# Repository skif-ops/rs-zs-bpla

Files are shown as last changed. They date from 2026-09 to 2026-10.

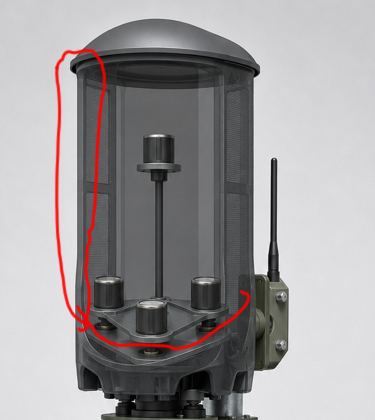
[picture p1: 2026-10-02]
releases/evt-pre-20/2026-10-02-rev-d5/Сборка_и_корпуса/03_Корпуса_для_3D_печати_ПРЕДВАРИТЕЛЬНО/Эталон_микрофонного_блока_Рисунок11.png

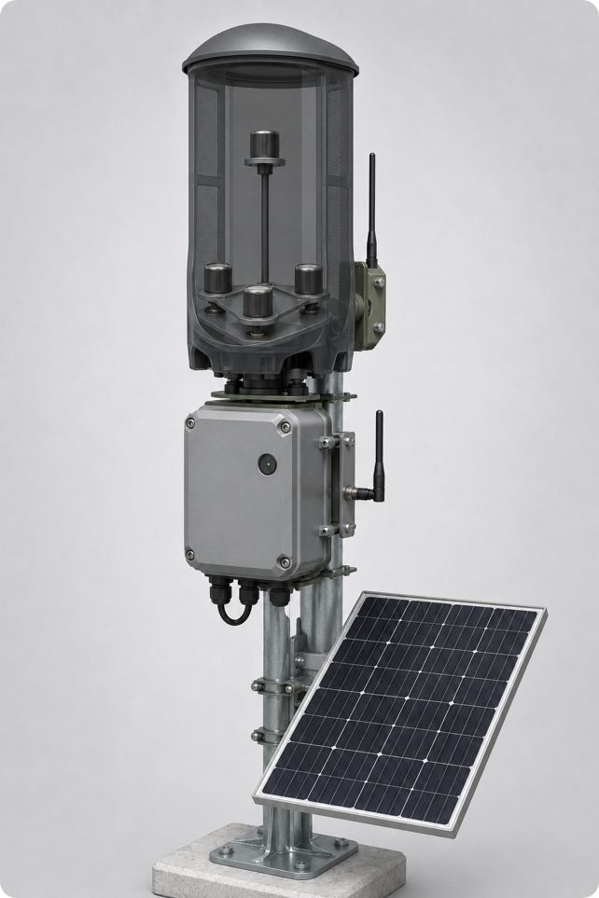
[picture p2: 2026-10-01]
releases/evt-pre-20/2026-10-02-rev-d5/Сборка_и_корпуса/03_Корпуса_для_3D_печати_ПРЕДВАРИТЕЛЬНО/Эталон_утвержденного_внешнего_вида.png

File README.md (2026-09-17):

# Дионея / РС ЗС-БПЛА

Репозиторий распределённой акустической системы обнаружения БПЛА. Серверное ПО
называется «Мухоед».

## Текущий интеграционный baseline

Версия: `DIONEA-INTEGRATION-v0.14`, дата среза 17.09.2026.

- рабочая архитектура: гибридная станция и сервер;
- акустическая геометрия: четыре одинаковых микрофона, схема 3+1, база 120 мм,
  верхний микрофон +150 мм;
- протокол: редакция 1.4 с совместимой wire schema 3 и расширением телеметрии питания;
- сервер «Мухоед»: развёртывание на Windows 11 или Ubuntu 24.04;
- EVT-MB v1.3: одна станция на WeAct STM32U585CIU6 и паяной плате 70 × 90 мм;
- EVT-PRE-20 Rev.A: 20 станций на собственных PCB с `STM32U585VIT6Q` и
  аккумулятором-кандидатом RB40 40 А·ч;
- LoRa пилота: только RU868; UWB оставлен для перспективного развития;
- PCB-PWR: 12-контактный межплатный интерфейс и полноценный INA226 по I²C;
- RF-вывод: внешняя SMA bulkhead и внутренний U.FL–SMA пигтейл Taoglas `CAB.0243`;
- корпус пилотной партии: вакуумное литьё как основной вариант, 3D-печать как резерв;
- аппаратные результаты остаются `OPEN / NOT RUN` до сборки и сохранения первичных измерений.

## Текущая готовность

| Область | Подтверждённый статус |
|---|---|
| EVT-MB v1.3 | Документы, host/структурные проверки и программная часть подготовлены; аппаратный стенд не испытан |
| EVT-PRE-20 | Контрольный source commit `7ed5b021b1e7`; конфигурация и воспроизводимые проверки актуальны |
| PCB-MAIN | Десятистраничная hierarchy принята только на уровне `ACCEPT_HIERARCHY_ONLY`; routing, Review B и выпуск в изготовление открыты |
| PCB-PWR | Активный F1 `0451008.MRL`; value-only ECO и commit-bound ERC/PDF evidence прошли, независимый post-ECO hierarchy review открыт; qualification 1/20; `DIM-003` — 0/18, stackup/copper — 0/24 и 0/2 фабрик |
| PCB-MIC | Copper-return subgate принят; общий Review B, CAM/DFM и manufacturing release открыты |
| «Мухоед» | Последний диагностический replay: 3/3 обнаружения и 15/15 положительных окон; operational type — UNKNOWN |
| Производственный BOM | 295 engineering-строк и 124 procurement-строки; QG-1 `PASS`, QG-2 `BLOCKED` |

## Ветки

| Ветка | Назначение |
|---|---|
| `main` | Проверенный стабильный интеграционный срез |
| `develop` | Интеграционная база, продвигаемая в `main` после CI без изменения дерева |
| `evt` | Материалы полноценного EVT без макетной специфики |
| `evt-mb` | Макетный EVT на паяной станции STM32U585CIU6 |
| `evt-pre-20` | Предсерийный EVT 20 станций на собственных PCB |

`evt-mb` и `evt-pre-20` остаются изолированными поставочными линиями. Их release/evidence
нельзя переносить друг в друга. В `main` и `develop` они представлены раздельными
каталогами и единым статусным реестром.

Подробные правила: [BRANCHING.md](BRANCHING.md). Текущий состав выпусков:
[releases/RELEASE_INDEX.md](releases/RELEASE_INDEX.md).

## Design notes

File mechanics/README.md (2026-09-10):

# EVT-PRE-20 - механический трек

Статус: `ARCHITECTURE DRAFT / CAD NOT RELEASED`

Механика разделена на общую акустическую геометрию и три независимых технологических комплекта:

1. `3d_print` - корпус и оснастка для печати на FlashForge Adventurer 5M Pro.
2. `vacuum_casting` - малосерийное литьё полиуретана в силиконовые формы.
3. `injection_molding` - отдельная конструкция под ТПА и промышленную пресс-форму.

Распределение пилотной партии зафиксировано: основной расчёт и изготовление 20 корпусов выполняются по технологии `vacuum_casting`. Если поставщик не сможет выполнить вакуумное литьё в требуемый срок или с требуемым качеством, после утверждения изменения вся партия переводится на `3d_print`. Для `injection_molding` готовится полный независимый комплект исходных данных и DFM, но пресс-форма и физические пилотные корпуса не заказываются без отдельного решения.

Все три технологических комплекта остаются обязательными поставочными результатами и не объединяются в одну CAD-модель. Для каждого выпускаются собственные part number, CAD, чертежи, BOM, материал и технологические допуски.

STL/STEP прежнего EVT-MB не являются корпусом предсерии: они рассчитаны на старую электронику и батарею 12 Ah. Разрешено повторно использовать только подтверждённую геометрию акустической головы 120 мм / +150 мм.

## Общая компоновка

- верхний акустический/электронный модуль: четыре mic leaf, PCB-MAIN, антенны, service cover;
- capture-allocation PCB-MAIN: 110 x 75 x 1,6 мм, четыре NPTH и 110 x 75 x 12 мм unmated PCBA envelope по `hardware/PCB_MAIN_MECHANICAL_PLACEMENT_AUTHORITY_REV_A.csv`; native STEP и полная сборочная проверка ещё не выполнены;
- отдельный нижний силовой модуль: батарея 40-60 Ah, BMS, MPPT и PCB-PWR;
- панель 60-80 W устанавливается отдельным кронштейном;
- кабель между модулями съёмный, поляризованный, защищённый предохранителем;
- электроника и батарея не делят негерметичный объём;
- наружные материалы UV-stable, негигроскопичные и не ухудшают RF без проверки.

## Общие требования

- IP65 minimum, IP67 target после испытаний;
- раздельные cellular, GNSS и LoRa антенны с контролем расстояния и кабельных потерь;
- акустические мембраны выбираются только после измерения АЧХ/фазы четырёх каналов;
- drainage и pressure-equalization vent не направляются на PCB/микрофон;
- все сервисные операции возможны без повреждения уплотнения и акустической базы;
- serial, HW revision, LoRa region и QR читаются после монтажа;
- long side изделия не более 500 мм, окончательная компоновка после component freeze.

## Release gate

Ни один корпус не выпускается в производство до заполнения `common/OPEN_DIMENSIONS.csv`, проверки полной сборки STEP, tolerance stack, thermal/RF review, пробной сборки, падения/вибрации и IP test. Каждый технологический вариант получает собственный part number, drawing, BOM и отчёт DFM.

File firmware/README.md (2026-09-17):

# ЗС-БПЛА firmware, EVT-PRE-20

Текущий каталог содержит переносимое C11-ядро: типы событий, compact CBOR, DSP, архивирование, state machines BG95/LoRa, GNSS parsing и host-тесты.

Целевой контроллер предсерии: `STM32U585VIT6Q`, LQFP100. Упоминания STM32U585ZI и платы WeAct относятся к предыдущим этапам и не являются target EVT-PRE-20.

## Что уже проверяется

```sh
cmake -S firmware -B firmware/build -DCMAKE_BUILD_TYPE=Release
cmake --build firmware/build --parallel
ctest --test-dir firmware/build --output-on-failure
```

Host PASS не означает готовую прошивку изделия.

## Что отсутствует до target build

- открытие, проверка и регенерация подготовленного STM32CubeMX `.ioc` версией 6.12.0;
- production linker с secure boot/A/B и HAL/LL bindings;
- драйвер PDM/MDF для четырёх T5838 на фактической плате;
- аппаратное и end-to-end подтверждение BG95 TLS/MQTT, защищённый downstream и provisioning;
- два валидированных региональных LoRa-профиля;
- secure boot, A/B OTA, rollback и подписанный release;
- измерение памяти, CPU, тока и времени на target.

До закрытия этих пунктов статус firmware: `TARGET_PORT_REQUIRED / OPEN / NOT RUN`. BIN/HEX из host-сборки запрещено маркировать как прошивку станции.

Host-контракт BG95 теперь покрывает автоматическое чтение SIM/оператора,
выбор APN через ответ сети или разрешённый PLMN-каталог, обязательное чтение
APN/IP/шлюза/DNS активного PDP и последовательность TLS/MQTT с fail-closed
обработкой ошибок. Полные IMSI/ICCID удерживаются только в оперативном состоянии
и включаются в отдельный heartbeat, разрешённый только через взаимный TLS;
общий server API маскирует их. Границы и отложенные до сборки станций
аппаратные доказательства зафиксированы в `BG95_MQTT_TLS_CONTRACT_REV_A.md`;
это не снимает общий `TARGET_PORT_REQUIRED` и не является сетевым EVT PASS.

Portable dual-SIM controller теперь отделяет проверяемую host-политику от
будущего target GPIO binding. Он принимает слот только после 20 ms DET debounce,
ограничивает профиль тремя попытками и 900-second hold, требует authenticated
manual assertion и audit intent/commit. При активном переключении новый слот не
может быть выбран до остановки трафика, сохранения очереди, штатного выключения
BG95, подтверждения mux High-Z и отключения modem rail. После включения
обязательны стабильный `PWR_GOOD` не менее 30 ms, 700 ms PWRKEY, полное совпадение
provisioned ICCID и attach/DNS/TLS до resume прежних event IDs. Любая ошибка,
brownout или debounced removal переводит controller в safe-off request. Это
host QG-1/QG-2, а не доказательство GPIO, реальных SIM, 100 циклов, операторов
или 24-часовой работы станции.

Safe-off request теперь сам является явной неразрывной последовательностью:
target сначала запрашивает graceful shutdown, а при его недоступности и
`CELL_STATUS=HIGH` выдаёт fallback PWRKEY 1000 ms
(внутри разрешённого аппаратного окна 650–1500 ms), подтвердить status LOW,
отключить mux, подтвердить High-Z и только затем снять modem rail. Ошибка любого
recovery action не переводит controller дальше и не допускает преждевременный
выбор слота.

Узкий portable bridge теперь связывает modem-dependent actions с BG95:
`AT+QPOWD` не считается завершённым без внешнего `CELL_STATUS=LOW`, после чего
volatile IMSI/ICCID очищаются; повторный power-on разрешён только из `OFF`.
Обратный путь требует штатного 700 ms PWRKEY, `CELL_STATUS=HIGH`, полного ICCID
из runtime автоматического network discovery и действительного online MQTT/TLS
с APN/IP/gateway/DNS read-back. Busy UART не позволяет перескочить shutdown.
Источник физического CELL_STATUS и прочие GPIO по-прежнему относятся к target.

Для EVT-PRE-20 добавлен host-compiled target GPIO contract: generated pin IDs
однозначно связывают PWRKEY/STATUS/mux/DET/PWR_GOOD/EN_MODEM с PD11, PD13, PE0,
PE2, PE3, PE5, PD0 и PD4. Адаптер проверяет полярности и запрещает rail-off до
`CELL_STATUS=LOW` и отключённого mux, а mux/PWRKEY — до непрерывных 30 ms
`PWR_GOOD`. При этом PD0 означает системный 3.3-V PG, не измерение 3V8_MODEM.
`U13_EN_N` не заведён на MCU, поэтому host различает logical command read-back
и physical fixture read-back; STM32 HAL, оснастка и измерение 3V8 остаются
target/EVT blockers.

BG95 link gate также теперь сверяет реально выбранный longest-prefix public-APN
catalog index с `pending_profile` dual-SIM controller. Поэтому даже online
MQTT/TLS с полным ICCID и валидным APN/IP/gateway/DNS не завершает switch через
другой индекс профиля. Содержимое production-каталога и durable audit backend
остаются provisioning/target blockers.

Portable store-and-forward теперь дополнен серверным application receipt:
сервер после durable processing публикует canonical CBOR с SHA-256 точного
detection payload, а fixed-memory firmware parser проверяет topic, QoS/retain и
полную identity события до маркировки outbox slot доставленным. Portable uplink
adapter сохраняет retry marker до выдачи exact `up` topic/payload и не считает
PUBACK разрешением на удаление. BG95 uplink binding использует fixed-length
`QMTPUB`: после `>` пишет ровно заявленное число binary CBOR bytes и оставляет
event pending даже после `+QMTPUB` success. Базовая BG95 state machine до
`QMTOPEN` включает direct `QMTRECV` с обязательной длиной; receipt binding после
connect проверяет этот флаг, подписывается на exact receipt topic с QoS 1 и
разбирает полный URC по byte count, сохраняя NUL/quote/CRLF/`0x1a`. Сам URC не
содержит retain-флаг, поэтому путь разрешается только явным внешним контрактом
station credential + server-only ACL + запрет retained receipt. Host QG не
заменяет target USART/DMA/ISR wiring, проверку broker policy/версии BG95 и аппаратный
recovery test.

Portable BG95 command binding использует тот же общий length-delimited parser:
после exact QoS-1 `down` subscription он передаёт только полный binary payload в
signature/journal/executor channel. Fixed-length `ack` `QMTPUB` начинается лишь
после durable `COMPLETED`; при reconnect повторная server command восстанавливает
ACK из journal без повторного side effect. Partial UART, timeout и mismatched
URC инвалидируют modem transport. Общая portable MQTT session принимает
произвольно фрагментированный raw UART, собирает line/prompt/length-delimited
URC в лимите 2304 bytes, сериализует command/receipt subscriptions, event
publish и command ACK единым TX owner. Один command frame буферизуется во время
занятого TX, следующие учитываются как требующие server retry; disconnect
очищает RAM queue и запускает ordered resubscribe. Retain в `QMTRECV` не виден и покрывается только явно подтверждённым
server-only/non-retained ACL contract. Target crypto, exact slot counts/OCTOSPI/endurance, USART/DMA/ISR,
broker policy и hardware evidence остаются открыты.

Command journal теперь имеет отдельный portable NOR adapter: каждый 88-byte
accepted/completed record занимает собственный physical erase block, callbacks
не могут выйти за логический slot, а torn commit повторно используется без
стирания соседнего record. Host QG проверяет restart roundtrip, commit-write
failure, alignment/range и erase isolation. Общий layout/bind ниже также
доказывает непересечение journal с archive и outbox. Production slot count,
OCTOSPI binding и endurance всё ещё не определены.

Portable NOR adapter выделяет каждому outbox slot отдельный erase block и
проверяет alignment/range partition, поэтому reclaim не стирает соседнее pending
event. Перед выдачей любого storage interface общий bind fail-closed проверяет
точный W25Q512JV JEDEC ID `EF 40 20`, SFDP/BFPT ёмкость 64 MiB, 4-byte geometry
и Status Register-2 QE; сброшенный QE восстанавливается с read-back. Portable
layout planner вычисляет непересекающиеся разделы: audio archive
занимает выровненный префикс NOR, за ним расположен erase-isolated command
journal, а outbox занимает хвост. Для контрольной геометрии 64 MiB / 4 KiB / 16
command slots / 256 event slots host QG проверяет 62.9375 MiB archive + 64 KiB
journal + 1 MiB outbox. Единый bind API создаёт все три adapter-а из одного
layout и ограничивает видимую archive storage точно началом journal, поэтому
независимая ошибочная инициализация диапазонов fail-closed. Точные числа слотов,
OCTOSPI HAL и endurance ещё должны быть утверждены в target memory map и
измерены на плате; host probe не заменяет проверку реального sample.

Первый target-инкремент уже фиксирует точный исходный контракт
`STM32U585VIT6Q/LQFP100`: 67 назначений из Rev.A pin map и AAD addendum,
запрет внешнего HSE, 32.768 kHz reference и пять ещё не измеренных runtime
profiles. Контракт генерируется воспроизводимо и проходит два независимых
контроля.

Второй target-инкремент закрепляет STM32CubeU5 v1.9.0 и его CMSIS-U5 commit,
добавляет официальный GCC startup/system и инженерный linker для 2 MiB flash,
768 KiB SRAM1-3 и 16 KiB SRAM4. Этот linker предназначен только для первичного
запуска без TrustZone; он не заменяет production-разметку secure boot/A/B и не
снимает общий `TARGET_PORT_REQUIRED`.

Третий target-инкремент формирует воспроизводимый pinout `.ioc` для
STM32CubeMX 6.12.0 / DB.6.0.120. В нём сохранены 67 назначений, включая
отдельные fail-closed `LORA_TXEN`/`LORA_RXEN`, и устранён
конфликт EXTI8: `LORA_DIO1` перенесён на `PC2/EXTI2`, а `MIC_WAKE` оставлен на
`PA8/EXTI8`. До открытия и регенерации в зафиксированной версии CubeMX файл не
считается подтверждённым target build.

Portable слой хранения installation position реализует атомарное чередование
двух слотов, CRC32, commit-marker, read-back, monotonic version и обязательные
physical-service/authenticated-role gates. Host QG не закрывает привязку этих
слотов к страницам STM32 Flash, ресурс перезаписи и power-loss fault injection
на фактической плате.

Portable слой commissioning принимает изменение installation position только
из локального BLE-origin после BLE Secure Connections, проверки peer identity
и физического сервисного окна не более 10 минут. Обычная installer-роль может
использовать только locked policy defaults; нестандартная trust policy требует
engineer-роли. Станция сама вычисляет канонический SHA-256, требует audit intent
до записи и audit committed после read-back. Это ещё не nRF52840/GATT binding:
UUID, pairing transport, сервисный таймер и durable audit backend проверяются на
целевой связке STM32+nRF и остаются release blocker.

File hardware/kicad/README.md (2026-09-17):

# ZS-BPLA EVT-PRE-20 KiCad package

Status: `NATIVE SOURCE CONTROLLED / NOT FOR MANUFACTURE`
Configuration: `EVT-PRE-20 Rev.A`
Authoritative branch: `evt-pre-20`

This directory is the authoritative electrical-CAD source package for the EVT-PRE-20 custom-PCB build. The three native projects and their required hierarchical child sheets are present. It remains blocked from manufacturing until each provisional board is completed and the required ERC/DRC, CAM, DFM and independent reviews are complete.

## Frozen baseline used for capture

- MCU: `STM32U585VIT6Q`, LQFP100 14x14 mm. The earlier `STM32U585CIU6`/48-pin and `STM32U585ZIT6Q` references are superseded for EVT-PRE-20.
- Microphones: 4 x TDK/InvenSense `T5838`, identical MPN; same lot preferred.
- Acoustic geometry: 3+1, equilateral base 120 mm, upper microphone +150 mm over center.
- Cellular: Quectel `BG95-M3` candidate, two physical nano-SIM slots through external 2:1 SIM mux, Dual-SIM Single-Standby only.
- GNSS/PPS: independent u-blox `MAX-M10S` class receiver.
- LoRa: Ebyte `E22-900M22S` / SX1262 class, RU868 pilot profile on every station in the selected 4, 10 or 20-unit EVT lot.
- BLE commissioning/diagnostics/OTA coprocessor: Raytac `MDBT50Q-P1MV2` based on Nordic `nRF52840`, integrated PCB antenna. `ESP32-C3-MINI-1-N4` is superseded and forbidden in active Rev.A BOM/capture.
- BLE requirements: BLE 2M/1M/Coded Long Range, authenticated commissioning, signed OTA, local diagnostics; Wi-Fi is not required.
- Local storage: W25Q512-class 64 MB NOR plus industrial microSD.
- Power source: 12.8 V LiFePO4 40-60 Ah, external 10 A LiFePO4 MPPT, 60-80 W solar panel.
- MPPT function is external. Do not reintroduce the older BQ24650/CN3791 charger topology into EVT-PRE-20 PCB-MAIN or PCB-PWR.

## PCB set

1. `PCB-MAIN`: MCU, BG95, dual SIM, MAX-M10S, LoRa module, nRF52840 BLE module, NOR, microSD, sensors, USB service, SWD and test points.
2. `PCB-MIC`: one T5838 microphone leaf; four identical boards per station.
3. `PCB-PWR`: protected battery interface and DC/DC rails for 3.8 V modem, 3.3 V digital/AON and 1.8 V microphone domains. External MPPT remains a separate assembly.

PCB-PWR `C1-C19`, `R1-R15`, `NT1-NT3` and `TP1-TP10` are bound from
`hardware/PCB_PWR_PASSIVE_AUTHORITY_REV_A.csv`. This is a capture/placement input,
not a manufacturing release; its electrical, package, fixture and environmental
blockers remain explicit in the authority.

PCB-PWR now uses a human-readable five-page native hierarchy: one system overview
plus four functional child sheets for input protection/current monitoring, 3V8,
3V3 and 1V8/harness interfaces. The controlled materializer gives every connected
pin an explicit wire stub and the independent audit proves exact pad/net
equivalence to the native PCB. Post-ECO KiCad 9 ERC/PDF evidence passes and is
commit/SHA-256 bound; independent human acceptance of the active drawing remains
open. The earlier acceptance for the superseded F1 value does not release it.

PCB-PWR currently contains a native, unrouted 60-footprint electrical placement
canvas. Its `90 x 60 mm`, four-layer and `1.6 mm` assumptions are provisional;
mounting holes, routing and copper zones are deliberately absent while `DIM-003`
remains open. `hardware/PCB_PWR_CAPTURE_STATUS_REV_A.json` is the machine-readable
release interlock for this state.

The bounded `DIM-003` request is now controlled by
`hardware/reviews/PCB_PWR_DIM_003_REQUEST_REV_A.json`; its 18-row response
register remains `0/18` accepted. It requests outline, mounting, J1/J2, DFT,
assembled-height, enclosure/thermal, harness-datum and frozen-STEP evidence but
does not release any of those values.

The bounded fitted-body clearance repack passes a strict independent subgate:
all 42 simultaneously fitted footprints have controlled courtyards, the required
minimum gap is `0.20 mm`, the observed minimum is `0.22 mm`, and conflicts are
zero. This result excludes DNP/PCB-feature service checks and does not approve
the provisional J2 edge overhang, connector mating/bend volumes, mounting, DFT
fixture access, assembled STEP, routing or Review B.

`hardware/PCB_PWR_ROUTING_AUTHORITY_REV_A.csv` classifies all 31 native nets as a
pre-route input, including high-current paths, three controlled net-tie returns,
switch/bootstrap loops, Kelvin sense, feedback and I2C. Its PASS does not permit
routing: numeric width, via-array and plane geometry remain open until `DIM-003`,
final current/fault envelopes, stackup/copper weights and thermal review close.

## Logical sheet plan

1. `01_POWER` - protected input and regulated rails; no integrated solar MPPT.
2. `02_MCU` - STM32U585VIT6Q, clocks, reset, SWD, decoupling, boot straps.
3. `03_AUDIO` - four PDM channels, common clock fanout/interface, microphone connectors.
4. `04_GNSS` - MAX-M10S, TIMEPULSE/PPS, RF connector/bias, backup supply.
5. `05_CELLULAR` - BG95-M3, 3.8 V transient decoupling, 1.8 V logic translation, dual nano-SIM mux and ESD.
6. `06_LORA` - E22-900M22S/SX1262 interface, RF connector/matching/ESD.
7. `07_BLE` - Raytac MDBT50Q-P1MV2 / nRF52840 service, commissioning and OTA coprocessor with SWD/UART recovery access and antenna keepout.
8. `08_STORAGE_SENSORS` - W25Q512, industrial microSD, LIS2DW12, temperature and current/voltage monitoring.
9. `09_CONNECTORS_TEST` - PCB-PWR, MIC1..MIC4, USB-C service, SWD, production test fixture and revision straps.

## Required CAD gates before Gerber release

- Pre-schematic PCB-MAIN authorities `MAIN-AUTH-001…011` are closed; the 110 x 75 mm outline, connector/module anchors, RF/keepout regions and 31 production pogo-pad coordinates are frozen by `hardware/PCB_MAIN_MECHANICAL_PLACEMENT_AUTHORITY_REV_A.csv`.
- Treat that frozen PCB-MAIN placement as a capture baseline, not a released
  placement: the accepted limited mechanical ECO clears the six conflicts that
  were inside MAIN-AUTH-011. The controlled 225-reference functional repack and
  explicit generic-passive courtyards now pass the independent strict 2D audit:
  227/227 fitted assembly footprints have courtyards and all component,
  mounting-exclusion and U.FL tool-zone conflict sets are empty. Routing,
  KiCad DRC, 3D/service review and Review B remain required.
- Use `hardware/PCB_MAIN_ROUTING_AUTHORITY_REV_A.csv` as the controlled pre-route
  input. It explicitly classifies all 186 native nets and preserves separate
  `GND_MODEM`, `GND_DIGITAL` and `GND_MIC` references. Its PASS is constraint
  coverage only: final stackup-dependent RF/USB geometry, routed copper, pours,
  DRC and manufacturing evidence remain open.
- Use `hardware/reviews/PCB_MAIN_STACKUP_IMPEDANCE_REQUEST_REV_A.json` and its
  blank response register only to obtain comparable construction data from
  `FAB-A` and `FAB-B`. The current `0/2` accepted response state does not select
  a stackup, authorize numeric 50-ohm/90-ohm rules or permit routing.
- Use `hardware/reviews/PCB_MAIN_ASSEMBLER_DFM_STENCIL_REQUEST_REV_A.json` and
  its blank 14-row register only for the bounded `U2/U25/U26/U9` process review.
  The current `0/14` accepted state does not select an assembler or process,
  create U9 paste apertures, close USB SI/whole-board DFM or permit manufacture.
- Use `hardware/PCB_PWR_ROUTING_AUTHORITY_REV_A.csv` as the 31-net PCB-PWR
  pre-route input. Freeze `DIM-003`, current/fault envelopes, stackup/copper
  weights and numeric thermal/current-density geometry before routing any copper.
- Use `hardware/reviews/PCB_PWR_STACKUP_COPPER_REQUEST_REV_A.json` and its blank
  24-row register only to collect comparable stackup/copper inputs from two
  fabricators. The current `0/24` and `0/2` state selects no construction and
  authorizes no numeric power geometry, routing or fabrication.
- Preserve the strict PCB-PWR fitted-body clearance PASS and its six-reference
  coordinate delta; repeat the audit after any placement or footprint change.
- Freeze CubeMX pin/peripheral assignment for STM32U585VIT6Q; no unresolved AF conflicts.
- Replace provisional MAIN/PWR placement candidates with mechanically frozen,
  reviewed and routed boards; keep all native `.kicad_sch/.kicad_pcb/.kicad_pro`
  sources under CI control.
- Datasheet/reference-design review for STM32U585, T5838, BG95, MAX-M10S, E22/SX1262, nRF52840/Raytac module and all power ICs.
- ERC: zero unexplained errors.
- DRC: zero blocker/critical violations.
- Review modem burst current, brownout and decoupling at 3.8 V.
- Review PDM 1.8 V level compatibility, clock fanout and channel-to-channel skew.
- Review dual-SIM powered-off isolation, signal integrity and low-capacitance ESD.
- RF review for cellular/GNSS/LoRa 50-ohm paths, BLE 2.4 GHz antenna keepout, grounding and coexistence.
- Validate BLE range/RSSI/OTA throughput in the final vacuum-cast housing and the full-lot 3D fallback housing.
- USB differential pair and ESD review.
- Power-current/thermal review for PCB-PWR including fault cases.
- DFT review: SWD, reset, rails, production UART and fixture-accessible test points.
- Generate and inspect Gerber, Excellon, IPC-356, pick-and-place, BOM/AVL, assembly drawings, fabrication notes and STEP.
- Independent Review A: schematic/net/pin/BOM check against source requirements.
- Independent Review B: PCB/CAM/assembly/DFM check against released source.

## Manufacturing prohibition

Do not manufacture or assemble EVT-PRE-20 PCB from the CSV sheets, component lists, current placeholder `.kicad_pro`, or any Gerber generated before both independent reviews pass. The release flag may change to `FOR_MANUFACTURE` only when the production gate and SHA-256 manifest are complete.

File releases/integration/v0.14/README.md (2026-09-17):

# DIONEA-INTEGRATION-v0.14

Дата: 17.09.2026.

Статус: `OPEN / INTEGRATION BASELINE / NOT FOR MANUFACTURE`.

Версия синхронизирует общий интеграционный baseline `develop` и `main` с
проверенным срезом `evt-pre-20`. Поставочные области `evt-mb` и `evt-pre-20`
не объединялись и не копировались друг в друга.

## Исходные контрольные точки

| Область | Ветка | SHA |
|---|---|---|
| Предыдущий интеграционный baseline v0.13 | `main` / `develop` | `bb7ff98d68075b3a606cfa3cfa1a5fde14d43e29` |
| Макетный EVT-MB v1.3, без изменений | `evt-mb` | `7d0f7f182e342cd3a3c6ba6f28bc6f138c71c4e1` |
| Предсерийный EVT-PRE-20 Rev.A | `evt-pre-20` | `7ed5b021b1e7eddfda616b54fbc79e1bf0221702` |

## Зафиксированная конфигурация

- партия: 20 станций, аккумулятор-кандидат RB40 40 А·ч;
- солнечная панель `SLP080S-12M`, MPPT `SCC075010060R`, датчик `SBS050150200`;
- антенны Taoglas `G30.B.108111`, `AA.166.A.301111`, `TI.89.B.2111W`;
- внешний разъём SMA bulkhead и внутренний U.FL–SMA пигтейл Taoglas `CAB.0243`;
- на данном этапе зафиксирована одна модель каждого системного компонента по
  балансу цены и качества; решение о продолжении или замене принимается по EVT.

## Контролируемый статус

- `PCB-MAIN`: commit `9aceca9531f0b9c18679bee1a8050ae7cd94308a` и hierarchy PDF
  SHA-256 `7e6ef20a989ec66c55b3e1a32de0a914b9e37a6e70cc5835d36f3260b65ff8d9`
  приняты решением `ACCEPT_HIERARCHY_ONLY`; routing, Review B, CAM/DFM и
  manufacture этим решением не разрешены;
- `PCB-PWR`: активный F1 — Littelfuse `0451008.MRL`; bounded value-only ECO
  применён без изменения footprint, placement, topology или nets. KiCad 9.0.9
  ERC имеет 0 нарушений на пяти листах, commit-bound PDF evidence прошло;
  независимый post-ECO hierarchy review остаётся открытым. Qualification — 1/20;
- `PCB-MIC`: copper-return subgate принят; общий Review B, CAM/DFM и
  manufacturing release остаются открыты;
- BOM: 295 engineering-строк, 124 procurement-строки, QG-1 `PASS`, QG-2 `BLOCKED`;
- supplier/physical evidence по системным компонентам, жгутам и корпусу не закрыты;
- аппаратный EVT: `NOT RUN`;
- purchase release и manufacturing release: `BLOCKED`.

## Контроль продвижения

1. Выполнить воспроизводимые BOM, firmware, server и native PCB проверки.
2. Зафиксировать интеграционный commit в `develop` и дождаться полного CI.
3. Продвинуть в `main` ровно тот же SHA без изменения дерева.
4. Не повышать post-ECO hierarchy acceptance до routing/Review B/manufacture без
   отдельного attributable review и первичных evidence.

Любое последующее изменение дерева после проверки создаёт новую интеграционную версию.

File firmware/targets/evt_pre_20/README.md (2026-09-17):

# STM32U585 target, EVT-PRE-20 Rev.A

This directory binds the firmware target to the exact `STM32U585VIT6Q` in
`LQFP100_14x14`. The generated C headers are derived from the locked Rev.A pin
map, the AAD configuration addendum and the locked no-HSE clock policy.

Regenerate and run both quality gates from the repository root:

```sh
python tools/generate_evt_pre_20_target_contract.py
python tools/validate_evt_pre_20_target_contract.py
python tools/audit_evt_pre_20_target_technical.py
python tools/validate_evt_pre_20_cubemx_ioc.py
python tools/audit_evt_pre_20_cubemx_ioc_technical.py
python tools/import_evt_pre_20_stm32_vendor.py --check
python tools/validate_evt_pre_20_stm32_scaffold.py
python tools/audit_evt_pre_20_stm32_scaffold_technical.py
python tools/validate_installation_store_contract.py
python tools/validate_installation_commissioning_contract.py
python tools/audit_installation_commissioning_technical.py
python tools/validate_event_outbox_contract.py
python tools/validate_event_receipt_contract.py
python tools/audit_event_receipt_technical.py
python tools/generate_event_receipt_vector.py --check
python tools/validate_dual_sim_failover_contract.py
python tools/audit_dual_sim_failover_technical.py
```

QG-1 checks completeness, ordering and SHA-256 traceability. QG-2 separately
checks package-pin uniqueness, critical peripheral mappings, voltage-domain
bindings and the clock-policy invariants. The second gate pair checks the pinned
STM32CubeU5/CMSIS provenance, the exact 142-entry STM32U585 vector table and the
engineering memory layout independently.

The generated `dioneya_evt_pre_20_rev_a.ioc` is a deterministic pinout import
candidate for STM32CubeMX 6.12.0 / DB.6.0.120. It contains all 67 locked
assignments, the DEC-022 EXTI split and the DEC-023 LoRa RF-switch controls:
LoRa DIO1 is on PC2/EXTI2, microphone wake is on PA8/EXTI8, TXEN is on PB15
and RXEN is on PD8. Both RF-switch enables initialize LOW. QG-1 verifies full source representation and provenance;
QG-2 independently rejects duplicate EXTI sources, HSE activation and critical
peripheral drift.

The same generated pinout now explicitly initializes the complete cellular
cold-state control set LOW: `CELL_PWRKEY_CMD`, `CELL_RESET_N_CMD`, `CELL_DTR`,
`EN_MODEM`, `SIM_MUX_SEL` (SIM1 default while isolated) and `SIM_MUX_EN`
(U13 High-Z). Both IOC gates verify these values independently; physical reset,
brownout and rail behavior remain target measurements.

`evt_pre_20_dual_sim_gpio` uses generated named pin identifiers instead of
string lookup and host-checks the exact Rev.A levels and interlocks. It will not
start the 1000 ms fallback PWRKEY while graceful shutdown is still available,
will not remove EN_MODEM before CELL_STATUS LOW plus mux-disable verification,
and requires continuous PWR_GOOD for 30 ms before mux/PWRKEY. The adapter keeps
logical SIM_MUX_EN read-back separate from optional fixture sampling of the
otherwise MCU-inaccessible U13_EN_N. STM32 HAL/LL wiring, physical U13 and
3V8_MODEM measurements, SIM cycling and operator EVT remain blocked.

The BG95 bridge additionally compares the automatic-network catalog index
selected from the full IMSI against the dual-SIM controller's pending profile.
An otherwise valid online link through a different approved entry fails closed;
production catalog values and durable audit persistence are still open.

The GCC startup and CMSIS system template are byte-for-byte imports from the
CMSIS commit pinned by STM32CubeU5 v1.9.0. The linker covers the full 2 MiB flash,
the contiguous 768 KiB SRAM1-3 and the separate 16 KiB SRAM4 retained section,
but is restricted to TrustZone-disabled engineering bring-up. SRAM4 placement
does not claim low-power retention until PWR configuration is measured.

The target remains non-releasable. The generated `.ioc` must still be opened,
reviewed and regenerated with STM32CubeMX 6.12.0. Clock-tree, internal MCU power
supply mode and peripheral runtime parameters are deliberately not released by
the pinout generator. HAL/LL integration, measured clocks, secure boot, A/B OTA,
production target build and hardware evidence remain blockers.

The portable installation-position store now provides a two-slot atomic record,
CRC, last-write commit marker, monotonic recommission version and read-back. Its
QG-1/QG-2 host result does not define STM32 Flash page addresses or close target
power-loss/endurance testing; that binding remains a target-port blocker.

The portable commissioning boundary now rejects MQTT/HTTPS coordinate writes,
requires an authenticated local BLE peer and a physical 10-minute service
window, computes the canonical record SHA-256 on the station, and brackets each
write with audit intent/commit callbacks. The nRF52840 GATT implementation,
durable audit backend and target service-window timer remain open target work.

The portable downstream-command boundary now has a canonical fixed-memory CBOR
codec, a bounded public-key rotation adapter, and a power-loss-safe
accepted/completed journal that cannot encode an ACK before completion is
durable. The journal now has a portable erase-isolated NOR adapter with one
physical erase block per record and host-tested torn-commit restart recovery;
the shared layout/binding also proves it is disjoint from archive and outbox.
Target slot count, OCTOSPI binding and endurance remain open.
A portable application channel enforces verify → accept → idempotent
execute → complete → ACK and safely replays accepted/completed duplicates. Host
QG includes a real server-generated Ed25519 vector. A portable binary MQTT
adapter now enforces the exact tenant/station `down` topic, QoS 1 and non-retained
delivery before command parsing, then exposes the exact `ack` topic and CBOR
payload length after durable completion. The target still needs reviewed Ed25519
library binding, provisioned public keys, production journal slot-count/OCTOSPI/endurance evidence
and hardware integration. Portable BG95 AT binding now confirms pre-connect
length mode, subscribes to exact `down` at QoS 1, parses binary `QMTRECV` by
declared length and publishes the durable ACK with fixed-length `QMTPUB`. A
server retry after UART failure returns the journaled ACK without re-execution.
A portable 2304-byte raw-UART session now serializes both subscriptions, event
publish and command ACK with one TX owner, preserves length-delimited binary
URCs across arbitrary input chunks, queues one command behind an active publish
and records further frames as server-retry required. Target USART1 DMA/ISR/cache
integration, retain-policy verification, reviewed crypto/Flash binding and
assembled-station evidence remain open.

The portable event outbox now atomically commits complete schema-4 detection
CBOR with metadata CRC32 and payload SHA-256, orders pending events by priority
then FIFO, persists up to 128 transmission attempts in a one-way bitmap, and
never reclaims a pending event. Only a verified server application ACK may mark
delivery; a torn marker intentionally causes safe at-least-once redelivery. Host
fault-injection is QG-1/QG-2 evidence only. The server now persists the exact
detection-payload SHA-256 and processing state before publishing a canonical
station-bound receipt; a fixed-memory firmware parser verifies the receipt and
marks only the matching pending item delivered. A portable MQTT uplink adapter
persists each attempt before exposing the exact outbox payload, publishes only
to the canonical station `up` topic, ignores PUBACK for reclamation and can apply
a queued receipt after restart by durable event lookup. Target NOR/Flash
binding now has a portable adapter that dedicates one physical erase block to
each outbox slot, preventing reclaim from erasing a neighbour. The shared bind
now first validates exact W25Q512JV JEDEC `EF 40 20`, SFDP/BFPT 64 MiB density,
4-byte geometry and Status Register-2 QE, restoring QE with read-back if needed;
all returned interfaces remain zero on failure. A portable layout
planner gives the audio archive the aligned NOR prefix, command journal the next
erase-isolated partition, and event outbox the tail, proving non-overlap for both
accepted caller-supplied slot counts. The host reference case verifies 62.9375
MiB archive + 64 KiB/16-slot journal + 1 MiB/256-slot outbox on 64 MiB NOR. A
single fail-closed bind API creates all three adapters from that layout and caps
the archive-visible storage at the journal boundary. Production slot counts,
target memory-map/OCTOSPI binding and wear/endurance remain release blockers.
Real sample identity/QE and power-loss behavior remain hardware gates.
The portable dual-SIM controller now enforces the audited, queue-preserving
single-standby sequence: 20 ms DET debounce, three attempts per profile,
900-second hold, authenticated manual changes, graceful modem-off and mux
/High-Z confirmation before slot select, 30 ms stable power-good, exact full
provisioned ICCID and attach/DNS/TLS before resume. The target still needs the
STM32 GPIO/modem-power/audit/profile binding and assembled-station fault and
100-cycle evidence; operator and 24-hour EVT remain deferred until assembly.
The portable BG95 bridge closes the host-only modem handshake inside that
sequence: it sends `AT+QPOWD`, requires caller-confirmed `CELL_STATUS=LOW`,
clears volatile SIM identity, admits PWRKEY only from `OFF`, and gates ICCID/link
actions on full identity plus valid online APN/IP/gateway/DNS state. Actual
PD13 sampling and the remaining STM32 GPIO/rail implementation stay blocked.
The portable BG95 uplink now emits fixed-length `QMTPUB`, waits for the data
prompt and writes exact binary CBOR bytes; partial UART writes, wrong result URCs,
offline transitions and timeout retain the pending event. Broker success still
does not reclaim it. Portable BG95 transport до `QMTOPEN` настраивает direct
receive с обязательным payload length; receipt binding после connect требует
успех этого шага, выполняет exact QoS-1 subscription и передаёт
length-delimited binary `+QMTRECV` в application-receipt validator. В URC нет
retain-флага, поэтому init требует явный server-only/non-retained broker ACL
contract; это не является target-доказательством. Portable session уже
маршрутизирует fragmented line/prompt/binary input и сериализует MQTT TX, но
target USART1 DMA/ISR/cache wiring, реальная
форма URC выбранной версии modem firmware, broker-policy verification и
assembled-station recovery остаются release blockers.

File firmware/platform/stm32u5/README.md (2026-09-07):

# STM32U5 target integration contract — EVT-MB 1.2

- MCU board: WeAct STM32U585CIU6, HSE 25 MHz, LSE 32.768 kHz.
- Audio: one lot of identical ICS-43434 HP or SPH0645LM4H-B I2S modules in two stereo pairs; mixing is forbidden.
- SAI1_A master RX and SAI1_B synchronous slave RX, DMA circular, 32 kHz,
  32-bit slots with 24-bit signed payload.
- GNSS: USART2 + 1PPS on PB3/TIM2_CH2.
- BG95: USART1, AT+IFC=0, dedicated 5 V pulse-capable rail.
- SX1262 and microSD: shared SPI1, independent CS.
- UART BLE service module; I2C2 power and temperature sensors.

The host CMake target verifies portable protocol/DSP scaffolding only. The target
project must be generated in STM32CubeIDE and then checked on hardware.

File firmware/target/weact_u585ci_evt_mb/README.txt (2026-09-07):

Дионея EVT-MB - аппаратная цель WeAct STM32U585CIU6

Захват звука: SAI1, 4 канала I2S от четырех одинаковых модулей
ICS-43434 high-performance или SPH0645LM4H-B; выбирается одна партия
одного типа и ревизии на все станции. PA8 - BCLK, PA9 - WS,
PA10 - SD_A, PB5 - SD_B.
SAI1_B синхронизируется с SAI1_A, оба блока работают через DMA.
Частота дискретизации: 32 кГц. Слот: 32 бита. Полезные данные: 24 бита.

GNSS: USART2 PA2/PA3, PPS на PB3 TIM2_CH2. BG95: USART1 PB6/PB7,
управление потоком отключено командой AT+IFC=0. BLE: USART3 PB10/PB11.
LoRa SX1262 и microSD используют SPI1 PA5/PA6/PA7 с отдельными CS.

Аппаратный target считается подтвержденным только после успешной сборки
STM32CubeIDE, четырехканальной записи WAV, захвата PPS и 8-часового прогона.

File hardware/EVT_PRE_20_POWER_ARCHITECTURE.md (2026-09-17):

# EVT-PRE-20 - архитектура питания Rev.A

Статус: `DRAFT / ONE EVT CANDIDATE PER FUNCTION SELECTED / NOT RUN / NOT A PRODUCTION RELEASE`

## 1. Зафиксированные входные данные

- выбранная для EVT-20 ёмкость: LiFePO4, 12.8 V, **40 Ah**; вариант 60 Ah
  оставлен только для решения после EVT;
- солнечная панель: выбранный EVT-кандидат 80 W в пределах класса 60-80 W;
- целевая автономность без солнца: 30 суток;
- внешний MPPT: не менее 10 A, профиль LiFePO4, дистанционный температурный датчик или запрет заряда при низкой температуре;
- собственная PCB-PWR: защита, измерение и DC/DC, без силового MPPT;
- T5838 Acoustic Activity Detect используется как основной низкопотребляющий акустический wake-path, поэтому `1V8_MIC` остаётся включённой в режиме AAD monitoring.

## 2. Проверка энергетического предела

| Батарея | Номинальная энергия | При 80% используемой энергии | Допустимая средняя мощность на 30 суток |
|---|---:|---:|---:|
| 12.8 V x 40 Ah | 512 Wh | 410 Wh | 0.57 W |
| 12.8 V x 60 Ah | 768 Wh | 614 Wh | 0.85 W |

Для выбранной конфигурации 20 x 40 Ah расчётный предел составляет только 0.57 W
средней мощности при 80% используемой энергии. 30 суток без солнца подтверждаются
только после измерения фактических режимов S0-S4. Расчёт по одной ёмкости батареи
недостаточен; переход на 60 Ah допускается только отдельным решением по результатам EVT.

## 2.1. Один точный набор EVT-кандидатов

| Функция | Производитель / точный MPN | Контролируемая характеристика | До выпуска остаётся |
|---|---|---|---|
| батарея | RELiON `RB40` | 12.8 V, 40 Ah, 512 Wh, M8, IP66 | cold-soak и системная работа при заданных `-40..+70 C`, транспортные документы, capacity/DCIR/BMS sample |
| панель | SLD Tech / Solarland `SLP080S-12M` | 80 W, Vmp 18.46 V, Voc 22.52 V, Isc 4.56 A | IV, cold-Voc, изоляция, кронштейн, кабель и транспортный sample |
| MPPT | Victron SmartSolar 75/10 `SCC075010060R` | 10 A, 75 V PV, 145 W при 12 V | конфигурация профиля RB40, reverse current, quiescent current, enclosure и cold-soak |
| температура батареи | Victron Smart Battery Sense `SBS050150200` | фактические температура и напряжение батареи по VE.Smart; провода 0,45 м, wireless range до 10 м, M10 eyelets, `-10..60 C` | retention stack на M8 терминалах RB40, pairing/network retention, компоновка на батарее и доказательство cut-off |

Это **выбранные EVT-кандидаты**, а не серийная AVL. На выбранной партии нельзя
смешивать альтернативные MPN. Серийная модель и возможная ёмкость 60 Ah принимаются
только после результатов EVT и управляемого изменения.

`RB40` допускает разряд только `-20..60 C`, а SmartSolar 75/10 имеет диапазон
`-30..60 C`; сами по себе они не закрывают заданный ambient `-40..+70 C`.
Следовательно, до QG-2 обязательны измеренная внутренняя температура, тепловое решение
корпуса либо формально принятые эксплуатационные ограничения. Заряд ниже `0 C`
запрещён проектом независимо от допуска ограниченного тока в паспорте RB40.

## 3. Шины PCB-PWR

| Шина | Нагрузка | Rev.A |
|---|---|---|
| `VBAT_PROTECTED` | вход DC/DC | 10-15 V рабочий диапазон; `LM74700QDBVRQ1` + внешний 60 V MOSFET `CSD18540Q5B`; TVS и fuse окончательно после fault/surge profile |
| `3V8_MODEM` | BG95 | `LMR604403SRAKR`, 4 A; dedicated rail; LTE/2G burst load-step обязателен |
| `3V3_DIGITAL` | STM32, GNSS, LoRa, nRF52840, SD | `LMR604403SRAKR`, 4 A; low-Iq; MAX-M10S VCC/V_IO common 3.3 V feed supports 100 mA startup inrush with no more than 0.2 Ohm series resistance; отдельный `3V3_AON` в Rev.A не ставится |
| `1V8_MIC` | 4 x T5838 + low-voltage wake/PDM logic | `TPS7A2018PDBVR`, 300 mA low-noise LDO; остаётся активной при AAD monitoring |

Точные `L1/L2` и current shunt уже выбраны и привязаны к контролируемым footprint.
Окончательные пассивы, TVS/fuse coordination, физическая разводка, нагрев и EMI
остаются блокерами производственного выпуска.

## 4. Режимы мощности Rev.A

### S0 - AAD monitoring / deepest field listen

- STM32U585 в согласованном Stop mode с PA8 как wake-capable `MIC_WAKE` input;
- четыре T5838 остаются на `1V8_MIC` в AAD mode;
- PDM clock выключен после входа T5838 в AAD;
- U7 `SN74AXC8T245PWR` остаётся включённым при фиксированном `OE=LOW`; `PDM_CLK` и `AAD_CFG` удерживаются в LOW, поэтому микрофонный clock и THSEL transitions отсутствуют; его гарантированный worst-case static current входит в измеряемый S0 budget;
- `MIC_WAKE1..4` объединяются на 1.8 V через `SN74LVC32APWR`, затем `SN74AXC1T45DRLR` переводит aggregate wake на PA8/3.3 V;
- BG95 `3V8_MODEM` выключена через `EN_MODEM=LOW`; U16 VCCA от BG95 `VDD_EXT` отсутствует, поэтому TI VCC isolation и Ioff отделяют постоянно доступную сторону `3V3_DIGITAL`;
- MAX-M10S uses no V_BCKP source or capacitor-only substitute; duty/continuous-time mode определяется timing requirement и измеренным holdover budget, а полная потеря питания приводит к детерминированному cold restart.

До выпуска измеряется полный ток S0 на реальной PCB, включая LDO Iq, T5838 AAD, wake logic, MCU Stop, GNSS timing strategy и leakage всех отключённых доменов.

### S1 - acoustic confirmation

AAD wake переводит STM32 в активное состояние, запускается PDM clock/MDF и короткий detector/feature pipeline. При неподтверждённом событии система возвращается в S0.

### S2 - classification/event build

Работают PDM capture, DSP/classifier, NOR/SD event buffer по необходимости.

### S3 - communications

Включается cellular или резервный LoRa/BLE service path; отдельно измеряются LTE/2G burst, attach, TLS и retransmission.

Для cellular применяется фиксированная последовательность `MAIN-AUTH-004`:

1. Q1 PWRKEY, Q2 RESET_N и Q3 SIM mux enable отключены; U13 удерживается в High-Z; `CELL_DTR=LOW`.
2. При U13 High-Z выбрать слот через `SIM_MUX_SEL`, включить `EN_MODEM`, дождаться стабильного `PWR_GOOD`, затем выдержать не менее 30 ms.
3. Установить `SIM_MUX_EN=HIGH`, проверить active-LOW `U13_EN_N`, затем подать на Q1 команду HIGH на 700 ms, что формирует активный LOW на U8 PWRKEY в допустимом окне 500-1000 ms.
4. Не использовать UART и RI до `CELL_STATUS=HIGH`.
5. Для штатного выключения остановить трафик, сохранить очередь, выполнить `AT+QPOWD`, дождаться `CELL_STATUS=LOW`, установить `SIM_MUX_EN=LOW`, проверить U13 High-Z и только затем снять `EN_MODEM`.
6. При отказе AT shutdown допускается PWRKEY pulse 650-1500 ms с тем же обязательным ожиданием `CELL_STATUS=LOW`.

Узел U8 получает два локальных ответвления от одной `3V8_MODEM` star point: `3V8_MODEM_BB` через FB1 `BLM31KN601SN1L` и `3V8_MODEM_RF` через R43 0 Ohm. Во время EGPRS burst напряжение на каждом из четырёх VBAT pads U8 не должно опускаться ниже 3.3 V. Полная топология зафиксирована в `hardware/PCB_MAIN_CELLULAR_AUTHORITY_REV_A.md`, а точные MPN, RefDes, population и физические цепи пассивов зафиксированы `MAIN-AUTH-010`. Частотная характеристика FB1 и запас по току остаются обязательной проверкой Review A.

### S4 - service/OTA/test

Максимальный одновременный сервисный режим, не используемый для расчёта типового field average без соответствующего duty cycle.

## 5. Component freeze

Авторитетная таблица: `hardware/POWER_COMPONENT_FREEZE_REV_A.csv`.

Выбранные для capture позиции:
- reverse/reverse-current controller `LM74700QDBVRQ1`;
- MOSFET `CSD18540Q5B`;
- `3V8_MODEM` и `3V3_DIGITAL`: `LMR604403SRAKR`;
- `1V8_MIC`: `TPS7A2018PDBVR`;
- current monitor: `INA226AIDGSR` with selected four-terminal shunt below;
- current shunt: Vishay Dale `WSK2512R0100FEA`, 10 mOhm, 1%, 1 W, four-terminal;
- buck inductors L1/L2: Coilcraft `XAL7030-472MEC`, 4.7 uH, Isat 10.1 A,
  Irms 6.9 A at 20 C rise;
- TVS `SMBJ18A` остаётся точным EVT-кандидатом до измеренного
  transient/fault profile. Ранее подписанная value `0451005.MRL` отклонена
  desk review для непрерывных 5 A. Активная native value и BOM/qualification
  target — `0451008.MRL` 8 A в том же Nano2 451 footprint; value-only ECO
  применён без изменения topology/placement/nets. Repeat ERC/PDF evidence прошёл;
  human review и физическая координация остаются обязательными до PCBA procurement.

## 6. Требования к MPPT/BMS до RFQ

1. Профиль 4S LiFePO4 и регулируемые charge/float параметры.
2. Входное напряжение выше холодного Voc выбранной панели с запасом не менее 20%.
3. Ток заряда не менее 10 A и настраиваемое ограничение по паспорту батареи.
4. Запрет заряда ниже 0 °C, если батарея не имеет подтверждённого heater/low-temperature cut-off.
5. Собственное потребление и ночной reverse current указаны и измерены.
6. Защита reverse polarity/current, short circuit и overtemperature.
7. Клеммы, провод и предохранитель рассчитаны на максимальный ток с derating.
8. Протокол телеметрии желателен, но для EVT не обязателен при независимом мониторинге PCB-PWR.

Для выбранной пары `SCC075010060R` + `SBS050150200` low-temperature cut-off
действует только при включённой VE.Smart network и поступлении фактической температуры
батареи. EVT-конфигурация: cut-off `0 C`; возобновление заряда должно быть измерено
выше порога с гистерезисом контроллера. Экспорт конфигурации и результат холодного
испытания являются release evidence. Точные absorption/float параметры не считаются
выпущенными до сопоставления с актуальной инструкцией RELiON.

## 7. Обязательные испытания

- холодный и горячий старт, восстановление после BMS cut-off;
- panel present/absent и LTE/2G transmit burst;
- reverse polarity, controlled-short, fuse coordination;
- температура DC/DC, MOSFET, разъёмов и проводов;
- токи S0-S4 на всех изделиях согласно EVT matrix;
- отдельное измерение S0 с четырьмя T5838 AAD + WAKE OR/translator;
- AAD false-wake / missed-wake / wake-latency при ветре, дороге, насекомых и целевых акустических записях;
- 72-часовой bench run и расчёт 30 суток по измеренному duty cycle;
- low-temperature charge inhibit.

Производственный release PCB-PWR запрещён до schematic/ERC, расчёта passives/thermal/fault, DRC/CAM и двух review gates.

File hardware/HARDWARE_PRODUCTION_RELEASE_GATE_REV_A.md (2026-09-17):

# EVT-PRE-20 hardware production release gate — Rev.A

Status: `ACTIVE / BLOCKING`

This gate is the release authority for the physical station hardware and its
procurement BOM. It intentionally excludes application firmware, server and
Android deliverables. Software becomes part of this gate only when an explicit
pinout, power sequence, hardware interface or production-test dependency requires
it.

## Two release decisions

`hardware design release` proves that the three PCBAs, system components,
mechanics and harness are technically complete and independently reviewed.
It requires production BOM QG-2, completed routing, DRC, CAM, DFM, Review B and
closed mechanical dimensions.

`purchase release` additionally requires exactly one selected lot quantity from
4, 10 or 20 stations and traceable supplier quotations. Comparable RFQs may be
collected for all three quantities before that selection; mixing their quantity
columns is prohibited.

The selected lot is `EVT-20` for 20 stations. This closes only the lot-selection
condition. It does not release purchasing while hardware design or supplier
evidence remains blocked.

The production interlock is implemented by:

```bash
python tools/audit_evt_pre_20_hardware_release.py --strict
```

Default mode records the same blockers without failing engineering CI. A PASS
must not be inferred from source completeness, BOM QG-1, unrouted placement
candidates or successful software tests.

PCB-MAIN has passed its bounded 2D placement-clearance subgate: the controlled
225-reference repack gives all 227 fitted assembly footprints an explicit
courtyard and the strict audit reports zero component, mounting-exclusion and
U.FL tool-zone conflicts. This is engineering progress only; the unrouted board
has no copper zones and still requires routed-board DRC, 3D/service evidence,
CAM, DFM and independent Review B.

PCB-MAIN also has an accepted human-readable hierarchy-only subgate. Source
commit `9aceca9531f0b9c18679bee1a8050ae7cd94308a` has commit-bound KiCad 9.0.9
ERC with zero violations, an ordered ten-page A2 PDF and exact electrical
equivalence to all 247 physical symbols and 1,077 physical pad occurrences.
Reviewer `Скиф` recorded `ACCEPT_HIERARCHY_ONLY` on `2026-09-16`. This does not
authorize routing, fabrication, assembly, Review B or manufacturing release.

PCB-MAIN also has explicit pre-route constraint coverage for all 186 native
nets. The independent audit enforces disjoint route classes, ground-domain
references, four USB differential-pair segments, seven 50-ohm RF nets and the
controlled modem-feed minimum widths. Numeric RF/USB geometry remains blocked
until the fabricator stackup is accepted, and the constraint PASS does not close
routing, copper, DRC, CAM, DFM or Review B.

PCB-PWR has explicit pre-route constraint coverage for all 31 native nets. The
independent audit binds the 5 A system basis, both 4 A buck channels, the 3.3 A
BG95 BB+RF peak basis, three separate harness returns/net ties, two switch nodes,
two bootstrap loops, two Kelvin lines, feedback and 100 kHz I2C. Numeric widths,
via arrays and plane geometry remain blocked on `DIM-003`, final current/fault
envelopes, selected stackup/copper weights and thermal/current-density review.
The board remains unrouted with zero copper zones; DRC, CAM, DFM and Review B are
open.

PCB-PWR is no longer a one-page label-only capture. Its native project now has a
system overview and four bounded functional child sheets for input protection and
current monitoring, 3V8 modem power, 3V3 digital power, and 1V8/harness interfaces.
The independent hierarchy audit finds 63 symbols, 185 explicit wire segments,
9 cross-sheet nets, 26 hierarchical labels, no cross-net wire collision and exact
pad/net equivalence to all 60 PCB footprints. This retains the signed pin/net
authority only. The KiCad 9 ERC/PDF evidence and independent hierarchy decision
accepted on `2026-09-16` for source commit
`2a973f6856aa115aa59323d619be985578780682` are historical evidence for the
superseded F1 value. For the active post-ECO source, KiCad 9.0.9 ERC reports zero
violations on all five sheets and the new five-page A3 PDF passes visual preflight;
the source, ERC, PDF and artifact hashes are bound to commit
`091a2eb223161cb4396fc6838921eeb79150c38d`. A new independent hierarchy decision
is still open. Routing and manufacturing release remain blocked by the separate
gates below.

The PCB-PWR input-protection desk review rejects the signed native F1 value
`0451005.MRL` for the 5 A continuous-current basis: Littelfuse's standard 25%
continuous derating reduces it to 3.75 A before temperature rerating. The
controlled BOM and qualification packet select exact candidate
`0451008.MRL` 8 A in the same Nano2 451 land pattern and retain
`SMBJ18A`. The bounded value-only ECO is applied to the active native schematic,
PCB and generators with footprint, placement, topology, nets and pad mapping
retained. This does not extend the prior hierarchy acceptance. The fresh KiCad 9
ERC and five-page PDF evidence pass, while independent human hierarchy review
remains mandatory. The input-protection matrix has `1/20` accepted rows
(`PWR-IPQ-003`); PCBA procurement and manufacturing release remain prohibited.

PCB-PWR has also passed its bounded fitted-body 2D placement-clearance subgate.
All 42 simultaneously fitted footprints have controlled courtyards, the required
minimum is 0.20 mm, the observed minimum is 0.22 mm and conflicts are zero. This
does not close `DIM-003`, mounting or connector/tool service volumes, DNP and DFT
fixture access, assembled STEP, routing, DRC, CAM, DFM or Review B.

The PCB-PWR `DIM-003` mechanical-freeze request is now internally complete and
machine-audited, but its response register has `0/18` accepted rows. The packet
requires final outline and mounting authority, J1/J2 mating and cable volumes,
DFT fixture/probe access, assembled height, enclosure/thermal keep-outs, harness
length datums and a hash-bound frozen STEP. It is an input request only; no
provisional dimension, routing or harness cut length is released.

The PCB-PWR stackup/copper request is internally complete and machine-audited,
but it has `0/24` accepted rows across `0/2` independent fabricator slots and no
selected construction. It requests the actual four-layer cross-section,
material, finished thickness, base/finished copper, hole-wall plating, via and
heavy-copper process limits, mask/finish, panel controls, net test and DFM
traceability. This establishes a controlled external input path only; it does
not authorize numeric current geometry, routing or fabrication.

The PCB-MAIN stackup/impedance request packet is internally ready, but it has
0/2 fabricator responses accepted and no selected construction. Its 22-row
register is a quotation/capability input only; it is not Gerber, a purchase
order, routing authority or fabrication release.

The bounded PCB-MAIN assembler request for `U2`, `U25`, `U26` and `U9` is also
internally ready, but it has 0/14 assembler DFM/stencil responses accepted and
no selected assembler legal entity, manufacturing site or controlled process.
The blank response register does not approve U9 paste, any land/mask/stencil
rule, PnP polarity, first-article assembly, Review B or manufacturing release.

The harness supplier capability packet is internally complete, but it has
`0/16` accepted responses and no selected legal entity, manufacturing site,
supplier assembly MPN, assembly-level temperature rating or accepted wire/crimp
process. It is a capability and quotation input only. Final cut lengths remain
blocked by `DIM-001`, `DIM-003` and `DIM-012`; the packet is not a build release.

## Current blocker classes

- sample-qualified and released BAT1, PV1, MPPT1, MPPT-TEMP, ANT-CELL,
  ANT-GNSS, ANT-LORA, RF-PIGTAIL, HARNESS and HSG-VC system identities; the
  exact EVT candidate MPNs do not by themselves satisfy this release gate;
- PCB-MAIN and PCB-PWR routing, DRC and CAM; PCB-PWR `DIM-003`, final stackup,
  numeric current-density/thermal geometry and physical power evidence; PCB-MIC independent Review B,
  CAM comparison, panelization and acoustic-stack review; all three boards'
  DFM and manufacturing release;
- PCB-PWR independent human hierarchy acceptance of the commit-bound ERC/PDF
  evidence after the applied F1 value-only ECO from rejected historical
  `0451005.MRL` to active target `0451008.MRL`, plus the remaining 19
  input-protection qualification rows including +70 C 5 A thermal,
  prospective-current, battery-side primary-fuse and SMBJ18A coordination;
- selected-assembler acceptance of the PCB-MAIN U2/U25/U26 project IPC
  candidates, U9 process-dependent stencil adaptation, PnP polarity,
  first-article controls and closure of blocker/critical DFM findings;
- acceptance of all 18 PCB-PWR `DIM-003` rows in
  `PCB_PWR_DIM_003_RESPONSE_REV_A.csv`, plus the remaining enclosure, antenna,
  harness, installation and environmental mechanical inputs;
- acceptance of both PCB-PWR stackup/copper fabricator sets in the 24-row
  `PCB_PWR_STACKUP_COPPER_RESPONSE_REV_A.csv`, selection of one construction,
  and separate current-density/DC-drop/fault/+70 °C thermal approval;
- acceptance of all 16 attributable harness supplier responses in
  `HARNESS_SUPPLIER_CAPABILITY_RESPONSE_REV_A.csv`, followed by final lengths,
  external endpoints, FAI and physical electrical/SI/thermal validation;
- supplier/fabricator/assembler quotation evidence for the selected 20-station
  purchase scenario.

Physical EVT and operator/SIM evidence remain later acceptance evidence after
stations are assembled; they are not replaced by this pre-production audit.

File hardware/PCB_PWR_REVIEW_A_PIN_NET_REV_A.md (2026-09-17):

# Дионея EVT-PRE-20 Rev.A - PCB-PWR Review A pin/net authority

Status: `REVIEW A PIN/NET PASS / NATIVE SCHEMATIC CAPTURE AUTHORIZED / NOT FOR MANUFACTURE`
Date: 2026-09-09
Board: `PCB-PWR`
Configuration: `EVT-PRE-20 Rev.A`

## 1. Scope

This Review A covers only component pin authority, named-net authority, inter-board pin contract, startup dependencies and controlled ground-return joins required before native KiCad schematic capture.

It does not approve the controlled passive candidates for manufacture or close their
derating, transient, thermal, assembly and load-step evidence. TVS/fuse coordination,
PCB layout, DFM, EMC/EMI, environmental qualification and manufacturing release also
remain Review B / EVT / release items.

## 2. Authoritative inputs reviewed

- `hardware/PCB_PWR_PIN_AUTHORITY_REV_A.csv`
- `hardware/PCB_PWR_CAPTURE_NETS_REV_A.csv`
- `hardware/HARNESS_LOGICAL_PINOUT_REV_A.csv`
- `hardware/PWR_MAIN_12PIN_I2C_FREEZE_REV_A.md`
- `hardware/CONNECTOR_FREEZE_REV_A.csv`
- `hardware/POWER_COMPONENT_FREEZE_REV_A.csv`
- `hardware/PCB_PWR_PASSIVE_AUTHORITY_REV_A.csv`
- `hardware/POWER_DESIGN_BASELINE_REV_A.json`
- `hardware/kicad/sheets/01_POWER.csv`
- TI primary datasheets for LM74700-Q1, CSD18540Q5B, LMR60440, TPS7A20 and INA226.

## 3. Review findings and dispositions

### RA-PWR-001 - critical startup deadlock

Original authority connected `U4 LMR604403` pin 9 EN to `EN_AUX`. This is invalid because PCB-MAIN is powered by the `3V3_DIGITAL` rail produced by U4. MAIN cannot assert EN_AUX before its own 3.3 V supply exists.

Disposition: `CLOSED`.

Rev.A authority is now:

- U4 VIN -> `VBAT_SYS`;
- U4 EN -> `VBAT_SYS` directly;
- `3V3_DIGITAL` is the always-on MAIN/AON bootstrap rail;
- `EN_AUX` must never gate U4;
- `EN_AUX` now controls U5 TPS7A2018 pin 3 EN and therefore gates only `1V8_MIC`;
- firmware keeps EN_AUX asserted whenever T5838 AAD monitoring must remain armed.

This preserves the existing 12-pin connector contract without adding another control signal.

### RA-PWR-002 - ambiguous ground-return join

Original authority allowed `GND_MODEM`, `GND_DIGITAL` and `GND_MIC` to join `GND_PWR` as `NET_TIE_OR_PLANE`, which is ambiguous for schematic capture and DRC.

Disposition: `CLOSED`.

Rev.A authority now requires explicit two-pin net-tie components:

- `GND_MODEM -> NT_GND_MODEM -> GND_PWR`;
- `GND_DIGITAL -> NT_GND_DIGITAL -> GND_PWR`;
- `GND_MIC -> NT_GND_MIC -> GND_PWR`.

The three harness returns remain distinct until their controlled low-impedance join region on PCB-PWR.

## 4. Locked power path

The approved schematic capture sequence is:

`J_PWR_IN -> F1/TVS candidate stage -> LM74700-Q1 + CSD18540Q5B -> RSH1 10 mOhm Kelvin -> VBAT_SYS -> U3 3V8 + U4 3V3 -> U5 1V8`

INA226 is connected across the Kelvin sense pair and measures the load-side protected battery bus. Both switching-regulator inputs are downstream of RSH1, so the monitor measures total station battery current rather than a single rail.

## 5. Locked key pin/net mappings

### LM74700-Q1 U1

- pin 1 VCAP -> `LM74700_VCAP`;
- pin 2 GND -> `GND_PWR`;
- pin 3 EN -> `VBAT_FUSED`;
- pin 4 CATHODE -> `VBAT_PROTECTED`;
- pin 5 GATE -> `REV_GATE`;
- pin 6 ANODE -> `VBAT_FUSED`.

EN is tied to ANODE/input for always-on reverse protection.

### CSD18540Q5B Q1

- pins 1,2,3 SOURCE -> `VBAT_FUSED`;
- pin 4 GATE -> `REV_GATE`;
- pins 5,6,7,8 DRAIN -> `VBAT_PROTECTED`.

### LMR604403 U3 - 3V8_MODEM

- pin 1 VIN -> `VBAT_SYS`;
- pin 2 PGND -> `GND_PWR`;
- pin 3 SW -> `SW_3V8`;
- pin 4 BOOT -> `BOOT_3V8`;
- pin 5 PG -> `PG_3V8` diagnostic only;
- pin 6 FB -> `FB_3V8`, 100 kOhm / 35.7 kOhm divider;
- pin 7 MODE/SYNC -> `MODE_3V8`, PFM default;
- pin 8 RT -> `RT_3V8`, 86.6 kOhm, 400 kHz baseline;
- pin 9 EN -> `EN_MODEM`, 100 kOhm pull-down, default OFF.

### LMR604403 U4 - 3V3_DIGITAL

- pin 1 VIN -> `VBAT_SYS`;
- pin 2 PGND -> `GND_PWR`;
- pin 3 SW -> `SW_3V3`;
- pin 4 BOOT -> `BOOT_3V3`;
- pin 5 PG -> `PWR_GOOD`;
- pin 6 FB -> `3V3_DIGITAL`, fixed 3.3 V mode;
- pin 7 MODE/SYNC -> `MODE_3V3`, PFM default;
- pin 8 RT -> `RT_3V3`, 86.6 kOhm, 400 kHz baseline;
- pin 9 EN -> `VBAT_SYS`, always-on startup policy.

`PWR_GOOD` intentionally reflects the critical 3V3 MAIN/AON rail only. It is not ANDed with `PG_3V8` because the modem rail may be intentionally disabled.

### TPS7A2018 U5 - 1V8_MIC

- pin 1 IN -> `3V3_DIGITAL`;
- pin 2 GND -> `GND_PWR`;
- pin 3 EN -> `EN_AUX`;
- pin 4 NC -> no connection;
- pin 5 OUT -> `1V8_MIC`.

### INA226 U2

- pin 1 A1 -> `GND_PWR`;
- pin 2 A0 -> `GND_PWR`;
- pin 3 ALERT -> `FAULT`;
- pin 4 SDA -> `I2C2_SDA`;
- pin 5 SCL -> `I2C2_SCL`;
- pin 6 VS -> `3V3_DIGITAL`;
- pin 7 GND -> `GND_PWR`;
- pin 8 VBUS -> `VBAT_SYS`;
- pin 9 IN- -> `SHUNT_LOAD_SENSE`;
- pin 10 IN+ -> `SHUNT_SOURCE_SENSE`.

A1=A0=GND fixes the Rev.A 7-bit address at `0x40`. PCB-PWR I2C pull-up footprints are DNP by default; the authoritative pull-ups are on PCB-MAIN. ALERT may assert FAULT but does not replace I2C telemetry.

## 6. Frozen MAIN/PWR connector contract

The Review A authority accepts only the 12-pin contract:

1. `3V8_MODEM`
2. `GND_MODEM`
3. `3V3_DIGITAL`
4. `GND_DIGITAL`
5. `1V8_MIC`
6. `GND_MIC`
7. `PWR_GOOD`
8. `FAULT`
9. `EN_MODEM`
10. `EN_AUX`
11. `I2C2_SCL`
12. `I2C2_SDA`

Any 10-pin MAIN/PWR interface is stale and must fail the capture audit.

## 7. Review A verdict

`PASS - PIN/NET AUTHORITY`

PCB-PWR is authorized to proceed to native KiCad schematic capture using only the reviewed authorities above.

The native schematic must fail Review A regression if it:

- gates U4 3V3 with EN_AUX;
- hard-ties U5 EN to 3V3 instead of EN_AUX;
- omits INA226 I2C pins 11/12;
- removes true Kelvin shunt sense nets;
- joins dedicated harness ground nets without explicit net-ties;
- changes the 12-pin MAIN/PWR order;
- treats FAULT as a replacement for INA226 I2C telemetry.

## 8. Human-readable hierarchy conversion

The native representation has been converted from the original one-page direct-label
capture into one system overview and four functional child sheets. The controlled
conversion contains 63 symbols, 185 explicit wire segments, 9 cross-sheet nets and
26 hierarchical labels. An independent audit compares every schematic pin with every
pad/net on all 60 physical PCB positions and records semantic SHA-256
`fb31a1880037c2d15873ef7a003b74967e0427ed767bc16de256a790b5320b5a`.

This exact equivalence retains the `PASS - PIN/NET AUTHORITY` decision above. Native
KiCad 9.0.9 ERC now passes with zero violations on all five sheets, and the exported
five-page A3 PDF plus JSON ERC report are commit-bound. This still does not accept the
active post-ECO drawing as complete review evidence: an independent human functional
review must be committed before routing starts.

## 9. Open items outside this Review A scope

- `U1`, `U2` and `U5` now use the exact TI DBV0006A, DGS0010A and DBV0005A
  land/mask/stencil examples; their placement, local routing and assembly validation
  remain Review-B controls;
- `Q1` copper and segmented stencil are now controlled by
  `DioneyaPWR:CSD18540Q5B_DNK` from TI SLPS488B sections 7.2/7.3; solder-mask
  expansion, drain thermal spreading/vias, placement, SOA and assembly validation
  remain Review-B controls;
- `U3/U4` copper, solder-mask opening and stencil are now controlled by
  `DioneyaPWR:LMR60440_RAK0009A` from TI SNAS877 package drawing
  4229353/J; optional thermal vias, power-loop placement, EMI/thermal evidence
  and assembly validation remain Review-B controls;
- `RSH1` is frozen as `WSK2512R0100FEA` with the manufacturer land pattern;
  Kelvin routing, current-density, thermal and reference-calibration evidence remain open;
- `J1` is frozen as vertical gold-contact `Molex 43045-0213` with both possible
  polarization-peg holes; orientation, service clearance and pull/thermal tests remain open;
- `J2` electrical footprint is shared with the manufacturer-controlled
  PCB-MAIN `Molex 43045-1202` pattern; its PCB-PWR placement, orientation and
  service clearance remain open with `DIM-003`;
- final TVS and fuse values and coordination;
- `L1/L2` are frozen as `XAL7030-472MEC` with the manufacturer land pattern;
  hot-loop placement, temperature rise, load-step and EMI evidence remain open;
- all `C1-C19`, `R1-R15`, `NT1-NT3` and `TP1-TP10` now have exact candidate identity,
  population, footprint and pin/net bindings in
  `PCB_PWR_PASSIVE_AUTHORITY_REV_A.csv`; capacitor DC-bias/cold-ESR/transient evidence,
  C13 manufacturer land-pattern comparison, assembly review and DFT accessibility
  remain open;
- selected battery/BMS voltage limits;
- MPPT/harness transient envelope;
- I2C final harness capacitance and pull-up validation;
- reverse MOSFET SOA and gate transient review;
- load-step, LTE-burst, cold-start, +70 C thermal and S0 standby tests;
- INA226 reference-meter calibration;
- EMC/EMI evidence;
- PCB layout, DRC, DFM and Review B.

Manufacturing status remains `NOT FOR MANUFACTURE`.

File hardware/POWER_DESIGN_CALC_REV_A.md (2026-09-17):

# Дионея EVT-PRE-20 Rev.A - расчётная база PCB-PWR

Status: `CAPTURE BASELINE - NOT FOR MANUFACTURE`
Configuration: `EVT-PRE-20 Rev.A`
Ambient requirement: `-40...+70 C`
Component temperature capability target: at least `-40...+85 C`, with junction margin verified at +70 C.

## 1. Входная шина

Источник: 4S LiFePO4, номинально 12.8 V.

EVT-кандидат аккумулятора зафиксирован как RELiON `RB40`, 12.8 V / 40 Ah /
512 Wh. Для расчёта DC/DC до завершения sample/EVT проверки сохраняется
консервативное рабочее окно 10.0...14.6 V. Паспортные и измеренные BMS
cutoff/recovery voltages RB40 должны заменить это provisional окно перед выпуском.

EVT-кандидат солнечного тракта: SLD Tech `SLP080S-12M` и Victron SmartSolar
75/10 `SCC075010060R` с датчиком Smart Battery Sense `SBS050150200` (`0.45 m`
провода, wireless range до `10 m`, M10 eyelets, рабочий диапазон `-10..60 C`).
Для M10 eyelets на M8 терминалах RB40 нужен утверждённый washer/retention stack.
Выбор точных MPN не заменяет измерение переходного процесса и конфигурационный audit.

Входной transient envelope пока НЕ заморожен. До выпуска платы требуется измерить/утвердить:

- MPPT disconnect/reconnect transient;
- подключение аккумулятора;
- длинный внешний жгут;
- reverse polarity event;
- fuse clearing energy;
- допустимый импульс TVS.

Поэтому `SMBJ18A` и PCB-fuse остаются кандидатами, а не release values.

### 1.1 Fuse desk review and bounded value ECO

Ранее подписанная native-схема содержала `0451005.MRL` 5 A. Этот кандидат отклонён
для непрерывной линии 5 A: Littelfuse требует стандартный derating 25% для
continuous operation дополнительно к температурной кривой. Поэтому 5 A nominal
даёт только `3.75 A` до температурного derating и не покрывает расчётный ток.

Для EVT-квалификации выбран точный кандидат Littelfuse `0451008.MRL` в том же
Nano2 451 land pattern:

- nominal rating `8 A`;
- nominal cold resistance `7.7 mOhm`;
- nominal melting I²t `20.23 A²s`;
- после только стандартного 25% derating остаётся `6.0 A`;
- при 5 A nominal cold loss составляет `0.1925 W`.

`7 A` не выбран: после стандартного derating он оставляет лишь `5.25 A` ещё
до обязательного +70 C temperature rerating. `8 A` также остаётся ниже
опубликованного Molex предела `8.5 A/contact` для J1 `43045-0213` и terminal
`43030-0038`, но разница `0.5 A` не считается release margin. Нужны
assembled thermal tests J1/harness/F1 при +70 C и подтверждённом 18 AWG проводе.

Это двухступенчатое изменение. BOM и qualification contract перешли на
`0451008.MRL`; bounded value-only ECO уже применён к native schematic/PCB и
генераторам без изменения footprint, placement, topology, nets или pad map.
Старые ERC/PDF/подпись относятся только к исторической value `0451005.MRL`.
Повторные KiCad 9 ERC/PDF evidence для активного ECO прошли и привязаны к commit
и SHA-256. До независимого hierarchy review и закрытия
`PCB_PWR_INPUT_PROTECTION_TEST_MATRIX_REV_A.csv` запрещены PCBA procurement и
manufacturing release. Топология и footprint не меняются.

`SMBJ18A` сохраняется как точный EVT-кандидат: 18 V standoff,
20.0...22.1 V breakdown, 29.2 V maximum clamp at 20.6 A и 600 W at
10/1000 us. Его 29.2 V tabulated clamp даёт только 6.8 V до 36 V absolute
maximum buck input, поэтому qualification требует измеренный максимум не более
`32.0 V` на protected node и немедленный reject при любом измерении
`>=36.0 V`. TVS не предназначен для длительного MPPT overvoltage.

INA226 scaling остаётся `200 uA/bit` для нормального operating envelope до
5 A. Его signed current register покрывает около `6.5534 A`; overload и
fault-energy испытания выше этого тока обязаны использовать внешний
калиброванный current probe и осциллограф. INA226 не является прибором
fuse-clearing qualification.

## 2. Reverse polarity / reverse current

Baseline:

- U: Texas Instruments `LM74700QDBVRQ1`;
- Q: Texas Instruments `CSD18540Q5B`, 60 V N-MOSFET;
- topology: ideal diode on protected battery input ahead of both buck converters.

LM74700-Q1 работает при 3.2...65 V, предназначен для внешнего N-MOSFET и обеспечивает reverse polarity / reverse current blocking. Это соответствует 12.8 V battery architecture с большим запасом по DC input voltage.

Release blockers:

1. окончательная TVS/fuse coordination;
2. MOSFET SOA при ошибочном подключении и переходных процессах;
3. gate resistor / gate transient review;
4. reverse test на реальном аккумуляторе/лабораторном эквиваленте.

## 3. 3.8 V modem rail

Converter: `LMR604403SRAKR`, 4 A synchronous buck.

Назначение: отдельная шина `V_CELL_3V8` для BG95-M3.

BG95-M3 nominal VBAT: 3.8 V, допустимый диапазон 3.3...4.3 V. В совместимом design guide Quectel указаны peak currents до 0.6 A по VBAT_BB и до 2.7 A по VBAT_RF; поэтому rail проектируется как 4 A rail с локальным low-ESR bulk storage около модема.

### 3.1 Switching frequency baseline

Для первого capture принимается `400 kHz`.

Причины:

- выше efficiency margin, чем у 1...2 MHz;
- меньшие switching losses важны для автономности;
- размеры L/C допустимы для EVT-PRE-20;
- окончательное решение проверяется EMI и load-step тестами.

TI reference values для 3.8 V / 4 A / 400 kHz:

- L = `4.7 uH`;
- effective COUT target = `54 uF`;
- CIN = `4.7 uF` minimum reference value;
- CBOOT = `100 nF`, >=10 V;
- RT = `86.6 kOhm`.

Release inductor requirement:

- shielded;
- 4.7 uH;
- Isat >= 6 A target;
- Irms >= 4.5 A target;
- low DCR;
- -40...+125 C preferred.

Selected for both rails: Coilcraft `XAL7030-472MEC`, 4.7 uH +/-20%,
AEC-Q200, DCR 26.1 mOhm typical / 30.0 mOhm maximum, Isat 10.1 A and
Irms 6.9 A for 20 C rise. The controlled footprint follows Coilcraft document
863-2: two `1.58 x 6.50 mm` lands separated by a `2.94 mm` inner gap. Pad 1 is
the marked start/short lead and must face the SW/high-dV/dt node.

At the provisional maximum input of 14.6 V and 400 kHz:

- 3.8 V rail ripple is about 1.50 A p-p, so the 4 A full-load peak is about
  4.75 A and calculated RMS is about 4.02 A;
- 3.3 V rail ripple is about 1.36 A p-p, so the 4 A full-load peak is about
  4.68 A and calculated RMS is about 4.02 A;
- maximum winding loss from the 30.0 mOhm DCR limit is 0.48 W at 4 A.

The exact MPN and land pattern are therefore frozen. In-application +70 C
temperature rise, load-step behaviour and EMI remain release gates.

### 3.2 Feedback divider for 3.8 V

LMR60440 typical VFB = 1.0 V. TI recommends 100 kOhm as a typical top feedback resistor.

Using:

`VOUT = VFB * (1 + RFBT/RFBB)`

for:

- RFBT = 100.0 kOhm, 0.1%;
- VOUT = 3.8 V;

we obtain:

`RFBB = 100k / (3.8 - 1.0) = 35.714 kOhm`.

Capture value: `35.7 kOhm, 0.1%, low-TCR`.

Nominal calculated VOUT with 100k / 35.7k is approximately 3.801 V before IC/reference tolerance.

### 3.3 Modem local bulk

Quectel requires approximately 100 uF low-ESR bypass near VBAT and reserves separate RF/baseband decoupling networks. Rev.A shall therefore reserve:

- converter effective COUT >=54 uF after DC-bias derating;
- local low-ESR 100 uF class bulk at BG95 VBAT_BB path;
- local low-ESR 100 uF class bulk at BG95 VBAT_RF path;
- Quectel-recommended HF MLCC arrays adjacent to the appropriate modem pins;
- star split from the common 3.8 V source into VBAT_BB and VBAT_RF.

Exact PCB-PWR capacitor candidates are controlled in
`PCB_PWR_PASSIVE_AUTHORITY_REV_A.csv` so schematic capture and the engineering BOM use
one identity. They are not released for manufacture until cold-temperature ESR,
DC-bias derating, transient/load-step and layout review are closed.

## 4. 3.3 V digital rail

Converter: second `LMR604403SRAKR`.

For Rev.A the 3.3 V rail uses the fixed-3.3 configuration of the selected device variant, provided the final captured part-number option is verified against TI ordering data before BOM release.

Initial switching baseline: `400 kHz`.

Initial TI reference values at 3.3 V / 4 A / 400 kHz:

- L = `4.7 uH`;
- effective COUT target = `54 uF`;
- CIN = `4.7 uF` minimum reference value;
- CBOOT = `100 nF`, >=10 V;
- RT = `86.6 kOhm`.

This rail supplies STM32, GNSS, LoRa, nRF52840 module and digital/peripheral loads subject to explicit load gating.

A separate 3V3_AON regulator is not added in Rev.A unless measured S0 current proves the merged rail cannot meet autonomy requirements.

## 5. 1.8 V microphone rail

LDO: `TPS7A2018PDBVR`.

Input: 3.3 V.
Output: fixed 1.8 V.
Rating: 300 mA.

Initial capture:

- CIN = 2.2 uF X7R, voltage rating >=6.3 V;
- COUT = 2.2 uF X7R, voltage rating >=6.3 V;
- both values must remain >=1 uF effective at bias and temperature;
- local 100 nF remains on each MIC leaf at T5838 VDD.

TPS7A20 has low-noise/high-PSRR characteristics and low Iq, suitable for the microphone/AAD rail. Final noise acceptance is by PDM/AAD measurement, not only by datasheet calculation.

## 6. Input current monitor

Monitor: `INA226AIDGSR`.

Capture shunt selection:

- RSHUNT = `10 mOhm`;
- 4-terminal/Kelvin construction required;
- >=1 W rating target;
- <=1% tolerance, 0.5% or 0.1% preferred;
- low TCR, <=50 ppm/C target.

Selected: Vishay Dale `WSK2512R0100FEA`, true four-terminal construction,
10 mOhm +/-1%, 1 W at 70 C and +/-35 ppm/C TCR. Its controlled footprint uses
the current Vishay document 30108 land-pattern values for the 0.005...0.2 Ohm
range: `a=2.29`, `b=3.30`, `c=0.76`, `d=0.51`, `e=1.70`, `l=3.68 mm`.
Pads 1/2 are source/load current lands; pads 3/4 are the corresponding
source/load Kelvin sense lands.

Reasoning:

At 5 A input current:

- VSHUNT = 50 mV;
- P = 0.25 W;

which remains inside INA226 shunt measurement range while providing useful resolution.
The 1 W rating is exactly four times the 0.25 W nominal dissipation at 5 A.
Final Kelvin routing, thermal evidence and reference-meter calibration remain blocking.

Firmware scaling baseline for max expected 5 A:

- minimum Current_LSB = 5 / 32768 = 152.6 uA;
- choose Current_LSB = `200 uA/bit`;
- CAL = 0.00512 / (0.0002 * 0.010) = `2560`;
- Power_LSB = 25 * Current_LSB = `5 mW/bit`.

These values remain the normal-operation telemetry baseline. They must be updated
if the released operating-current envelope, rather than only the protective fuse
rating, exceeds 5 A. Overload/fault qualification uses external instrumentation.

## 7. Required bench validation before release

### PWR-01 - 3.8 V load step

Test 0.05 A -> 2.0 A -> 3.3 A and representative pulsed BG95 profiles. Verify:

- no drop below BG95 minimum rail limit;
- converter does not enter unintended current limit;
- recovery without oscillation;
- local VBAT ripple/undershoot;
- hot/cold bulk capacitor behaviour.

### PWR-02 - 3.3 V load step

Exercise sleep/active transitions of MCU, LoRa, GNSS, BLE and storage.

### PWR-03 - thermal

At +70 C ambient run worst realistic concurrent load. Record regulator, inductor, MOSFET and PCB copper temperatures.

### PWR-04 - cold start

At -40 C verify startup, capacitor ESR effects, rail sequencing and modem attach bursts.

### PWR-05 - reverse polarity / input transient

Execute only with current-limited protected fixture. Verify LM74700-Q1, MOSFET, TVS and fuse coordination.

### PWR-06 - standby

Measure complete S0 current including both buck converters, TPS7A20, monitors and leakage paths. If merged 3V3 architecture misses the autonomy budget, raise an ECO rather than hiding the measured current.

## 8. Freeze state

Can proceed into native schematic capture now:

- LM74700-Q1 controller;
- CSD18540Q5B concept;
- LMR60440 x2;
- 3.8 V feedback 100k / 35.7k;
- 400 kHz baseline, RT 86.6k;
- Coilcraft XAL7030-472MEC 4.7 uH inductors with controlled land pattern;
- TPS7A2018;
- INA226 with Vishay WSK2512R0100FEA 10 mOhm four-terminal shunt and controlled land pattern.

Still open before `FOR_MANUFACTURE`:

- in-application inductor thermal/load-step/EMI evidence;
- release of the controlled MLCC/bulk capacitor candidates after DC-bias,
  cold-ESR, transient, load-step and package/assembly review;
- TVS;
- PCB fuse;
- shunt Kelvin layout, temperature rise and reference-meter calibration;
- measured RB40 BMS cutoff/recovery voltage limits and cold-system behavior;
- measured `SCC075010060R` disconnect/reconnect transient envelope and exported
  charge profile;
- proof that `SBS050150200` remains in the VE.Smart network and disables charge
  below the project `0 C` threshold;
- thermal and load-step test evidence;
- EMC/EMI evidence.

No item in this document overrides the two independent Review A / Review B release gates.

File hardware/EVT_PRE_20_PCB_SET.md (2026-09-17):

# EVT-PRE-20 - состав PCB и правила выпуска

Статус: `CONTROLLED DESIGN BASIS / MANUFACTURING RELEASE HOLD`

Единый authority числа медных слоёв: `hardware/PCB_LAYER_COUNT_AUTHORITY_REV_A.csv`.
Число слоёв зафиксировано для Rev.A; конкретные конструкции фабрик, толщины меди
и численные impedance-геометрии остаются открытыми до соответствующих DFM-гейтов.

## PCB-MAIN

- Количество на изделие: 1.
- Технология Rev.A: 6 медных слоёв, FR-4, 1.6 мм; окончательные материал,
  медь, покрытие и controlled-impedance конструкция принимаются по двум ответам фабрик.
- Целевая зона: ориентировочно до 100 x 80 мм, окончательно после компоновки корпуса.
- Разделение зон: RF cellular, RF GNSS, RF LoRa, quiet digital/audio, modem power, service/debug.
- Антенны внешние, отдельные разъёмы cellular/GNSS/LoRa. Межпортовая развязка проверяется на макете корпуса.
- Обязательные интерфейсы: SWD, USB-C service, два nano-SIM через 2:1 mux, microSD, battery/power, 4 x MIC, cellular antenna, GNSS antenna, LoRa antenna, tamper/service.
- Dual SIM работает только в режиме Single Standby. Оба слота и мультиплексор входят в STEP, schematic, BOM, DFT и EOL coverage.

## PCB-MIC x4

- Количество на изделие: 4 одинаковые платы.
- Технология Rev.A: 2 слоя, FR-4, 1.0 мм, ENIG.
- Габарит Rev.A: 24.0 x 22.0 мм.
- Один T5838 на плату, нижний акустический порт, локальная развязка питания.
- Акустический PCB-порт: NPTH 0.8 мм в X=12.0 мм, Y=16.65 мм.
- Монтаж: H1/H2, два NPTH 2.2 мм под M2, X=4.0 и 20.0 мм, Y=16.65 мм.
- Разъём Rev.A: Molex Pico-Lock 5040500691, 6 контактов: 1.8 V, GND, PDM_CLK, PDM_DATA, MIC_WAKE, AAD_CFG/THSEL.
- Не допускаются разные MPN микрофонов внутри одной станции.
- Платы и жгуты маркируются MIC1...MIC4, но PCB остаётся единой ревизии.
- Оснастка фиксирует треугольник 120 мм и MIC4 +150 мм над центром.
- Авторитетный mechanical freeze: `hardware/kicad/REV_A_CAPTURE_ADDENDUM_003_PCB_MIC_MECH.md`.

## PCB-PWR

- Количество на изделие: 1.
- Технология Rev.A: 4 медных слоя. Цель для запроса фабрике — внешние слои 2 oz,
  внутренние 1 oz; медь, диэлектрики и толщина не заморожены до DIM-003,
  токового/теплового расчёта и DFM.
- Вход только от защищённой батарейной шины после внешнего MPPT/BMS.
- Функции: предохранитель, reverse protection, TVS, current/voltage monitor, load disconnect, 3.8 V modem rail, 3.3 V digital rail, 1.8 V microphone rail.
- Силовые разъёмы должны исключать переполюсовку и иметь запас по току/температуре.

## Закупочное количество

| Объект | На изделие | 20 изделий | Запас | К заказу |
|---|---:|---:|---:|---:|
| PCB-MAIN bare | 1 | 20 | 5 | 25 |
| PCB-MAIN assembled | 1 | 20 | 2 | 22 |
| PCB-MIC bare | 4 | 80 | 20 | 100 |
| PCB-MIC assembled | 4 | 80 | 8 | 88 |
| PCB-PWR bare | 1 | 20 | 5 | 25 |
| PCB-PWR assembled | 1 | 20 | 2 | 22 |

Запасные голые платы не заменяют запас компонентов. Критические IC закупаются с отдельным запасом и из одной подтверждаемой партии, где это влияет на согласование каналов.

## Производственный release gate

Каждая плата должна иметь исходники KiCad, PDF схемы, Gerber, drill, IPC-356, pick-and-place, BOM/AVL, assembly drawing TOP/BOTTOM, fabrication notes, 3D STEP, ERC/DRC отчёты и письменный DFM review фабрики. Gerber сверяется отдельным CAM viewer со схемой и исходной PCB.

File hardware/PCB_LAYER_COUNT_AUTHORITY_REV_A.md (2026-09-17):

# Дионея EVT-PRE-20 Rev.A — authority числа медных слоёв

Статус: `CONTROLLED LAYER COUNT / FINAL STACKUPS OPEN / NOT FOR MANUFACTURE`

Дата: 2026-09-15

## Решение Rev.A

| Плата | Число слоёв | Толщина платы | Состояние |
|---|---:|---:|---|
| PCB-MAIN | 6 | 1,6 мм | число слоёв и толщина зафиксированы; конструкция фабрики открыта |
| PCB-PWR | 4 | 1,6 мм provisional | число слоёв зафиксировано; габарит, толщина, медь и конструкция открыты до DIM-003/DFM |
| PCB-MIC | 2 | 1,0 мм | число слоёв и толщина зафиксированы; DFM/Review B открыты |

Машинным источником является `hardware/PCB_LAYER_COUNT_AUTHORITY_REV_A.csv`.
Он заменяет прежние конфликтующие упоминания четырёх слоёв для PCB-MAIN и двух
слоёв для PCB-PWR.

## Граница решения

Число слоёв не означает утверждённый stackup и не разрешает трассировку или
производство. Для PCB-MAIN фабрика должна вернуть полный шестислойный разрез и
численные геометрии 50 Ом/90 Ом согласно контролируемому запросу. Для PCB-PWR
целевыми значениями являются 2 oz на внешних и 1 oz на внутренних слоях, но эти
значения не заморожены до расчёта токовой плотности, тепла и ответа фабрики.
Контролируемый запрос двум фабрикам находится в
`hardware/reviews/PCB_PWR_STACKUP_COPPER_REQUEST_REV_A.md`; его состояние
`0/24` строк и `0/2` комплектов ответов не выбирает конструкцию.

Четырёхслойная PCB-PWR выбрана для непрерывных возвратных плоскостей и отвода
тепла от двух LMR60440. Это соответствует рекомендации TI использовать несколько
медных слоёв и тепловые переходы к внутренним земляным слоям; окончательная
реализация проверяется расчётом и DFM выбранной фабрики:
`https://www.ti.com/lit/ds/symlink/lmr60440-q1.pdf`.

## Межблокировки выпуска

- PCB-MAIN: два ответа фабрик, выбранная конструкция, медь, материал, покрытие,
  impedance geometry, routing, DRC, STEP, CAM/DFM и Review B.
- PCB-PWR: DIM-003, силовая/Kelvin/thermal routing, расчёты тока и температуры,
  выбранная конструкция и медь, DRC, STEP, CAM/DFM и Review B.
- PCB-MIC: внешний DFM, panelization/depanel, assembly process и Review B.

Ни одна строка этого authority не является разрешением на Gerber или заказ плат.

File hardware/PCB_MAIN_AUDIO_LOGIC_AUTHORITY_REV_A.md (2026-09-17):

# PCB-MAIN audio and AAD logic authority - EVT-PRE-20 Rev.A

Status: `AUDIO_LOGIC_AUTHORITY_PASS / PCB REVIEW A NOT STARTED / NOT FOR MANUFACTURE`

This record closes only `MAIN-AUTH-003`. It freezes the exact U7, U17, and U18 physical-pin maps, voltage domains, directions, AAD OR topology, safe states, unused channels, and mandatory local networks. It does not release native PCB-MAIN capture, PCB Review A, PCB Review B, or the production BOM.

Machine authority: `hardware/PCB_MAIN_AUDIO_LOGIC_PIN_AUTHORITY_REV_A.csv`.

Authority CSV SHA-256: `ff84acbcc8ecc104cbc6691d5a2eaed652adfab082c510518bd0ab487da68267`.

## Primary evidence

- TI `SN74AXC8T245` datasheet SCES875C, Revision C, January 2024: `https://www.ti.com/lit/ds/symlink/sn74axc8t245.pdf`. Retrieved document SHA-256: `6cf4003c438c0546fb86f0932613896197dd19a75bdb307f385eb6e75535126e`.
- TI `SN74LVC32A` datasheet SCAS286U, Revision U, July 2024: `https://www.ti.com/lit/ds/symlink/sn74lvc32a.pdf`. Retrieved document SHA-256: `807f6fff7977736035c2a3144d530be7ad737a163b2f0fd11002a45953b47230`.
- TI `SN74AXC1T45` datasheet SCES882E, Revision E, December 2023: `https://www.ti.com/lit/ds/symlink/sn74axc1t45.pdf`. Retrieved document SHA-256: `41e03bd8f0740ae8bbdf92309e7c82bac1359a768556cbe68de41b0273e49f12`.
- TDK `T5838` datasheet DS-000383, Revision 1.2, release date 4 September 2025, obtained from the official TDK documentation API and CDN. Retrieved document SHA-256: `5befb710bfe7a415cdc1aba41ebc18b484d7f9fc320ce15a7481507531cf58a4`.
- Project MCU functional sources: `hardware/EVT_PRE_20_PIN_MAP_REV_A.csv`, `hardware/AAD_CFG_PIN_ADDENDUM_REV_A.csv`, and `hardware/PCB_MAIN_MCU_PIN_AUTHORITY_REV_A.csv`.
- Project harness source: `hardware/HARNESS_LOGICAL_PINOUT_REV_A.csv`.

## U7 SN74AXC8T245PWR contract

The project-local `TI_PW0024A_TSSOP24` footprint follows TI 4220208/A: 24
1.50 x 0.45 mm R0.05 lands at 0.65 mm pitch with 5.80 mm between row
centers, equal-size stencil apertures, and 0.05 mm NSMD expansion. This
replaces the incorrect 0.50 mm-pitch KiCad pattern previously assigned to U7.

The exact PW package has 24 pins and two independent direction groups. This is not a single-direction eight-channel translator. With `VCCA=1V8_MIC`, `VCCB=3V3_DIGITAL`, `DIR1=HIGH`, and `DIR2=LOW`, channels 1 through 4 translate from A to B while channels 5 through 8 translate from B to A at the same time.

| U7 group | Direction | 1.8 V port A | 3.3 V port B |
|---|---|---|---|
| 1 | A to B | A1..A4 = `PDM_DATA1_1V8`..`PDM_DATA4_1V8` | B1..B4 = `PDM_DATA1`..`PDM_DATA4` |
| 2 used | B to A | A5 = `PDM_CLK_1V8`; A6 = `AAD_CFG_1V8` | B5 = `PDM_CLK`; B6 = `AAD_CFG` |
| 2 unused | B to A | A7 and A8 externally NC | B7 and B8 tied directly to GND |

- U7 pin 2 `DIR1` is tied directly to `1V8_MIC`.
- U7 pin 11 `DIR2` is tied directly to GND.
- U7 pin 22 active-low `OE` is tied directly to GND, so `OE=LOW`. Rev.A therefore keeps U7 enabled whenever both rails are valid.
- This fixed-control choice consumes no additional STM32 GPIO and keeps all control inputs at valid VCCA-referenced levels during reset.
- TI specifies VCC isolation when either rail is below 100 mV, Ioff partial-power protection, and no required supply order. These features prevent a powered domain from back-feeding a fully unpowered domain.
- TI specifies 288 kOhm typical internal weak pull-downs on every U7 data I/O. They hold source-side inputs low during MCU or microphone tri-state conditions. No external pull-up or pull-down is allowed on any `PDM_DATAn_1V8` net because TDK explicitly prohibits it for the tri-stated PDM data waveform.
- `PDM_CLK` and `AAD_CFG` are held low outside active clocking or one-wire writes. Therefore U7 produces no microphone clock and no THSEL transition in S0, even though the translator itself remains enabled.
- U7 maximum combined static supply current is 55 uA at 125 C with valid static inputs. This current is an explicit S0 budget item and must be measured on the assembled system.
- Place 100 nF at VCCA pin 1 and 100 nF at each VCCB pin 23 and pin 24. Exact capacitor RefDes and MPN are assigned by `MAIN-AUTH-010`.
- `PDM_CLK_1V8` source termination and final `AAD_CFG_1V8` fanout damping, if required by measurement, are assigned by `MAIN-AUTH-010`. The four final harnesses remain subject to rise-time, overshoot, skew, and THSEL-write verification.

The harness-facing 1.8 V nets carry `_1V8` in native KiCad so they cannot be accidentally shorted across U7 to the same logical names on the 3.3 V MCU side. The logical MIC harness contract remains `PDM_CLK`, `PDM_DATAn`, and `AAD_CFG`; the CSV records the physical-domain mapping at U7.

## U17 SN74LVC32APWR contract

The project-local `TI_PW0014A_TSSOP14` footprint follows TI 4220202/B: 14
1.50 x 0.45 mm R0.05 lands at 0.65 mm pitch with 5.80 mm between row
centers, equal-size stencil apertures, and 0.05 mm NSMD expansion.

U17 operates from `1V8_MIC`. Its three used gates implement this exact active-high function:

`MIC_WAKE_OR_1V8 = (MIC_WAKE1 OR MIC_WAKE2) OR (MIC_WAKE3 OR MIC_WAKE4)`

- Gate 1 uses pins 1, 2, and 3 for `MIC_WAKE1`, `MIC_WAKE2`, and `MIC_WAKE12_OR_1V8`.
- Gate 2 uses pins 4, 5, and 6 for `MIC_WAKE3`, `MIC_WAKE4`, and `MIC_WAKE34_OR_1V8`.
- Gate 3 uses pins 9, 10, and 8 for the two first-stage outputs and `MIC_WAKE_OR_1V8`.
- Unused gate inputs pin 12 and pin 13 are tied directly to GND. Unused output pin 11 is externally NC.
- Each `MIC_WAKEn` input has a required 100 kOhm pull-down to GND, so an absent or open MIC harness is inactive rather than floating. Each input also has a Review A test point before aggregation. Passive RefDes and exact resistor MPNs are assigned by `MAIN-AUTH-010`.
- T5838 WAKE is a push-pull active-high output. TDK guarantees `VOH >= 0.7 x VDD` at 0.5 mA, while U17 requires `VIH >= 0.65 x VCC` from 1.65 V to 1.95 V. Because both use the same `1V8_MIC` rail, the guaranteed ratio has 0.05 x rail margin. A 100 kOhm pull-down draws only 18 uA at 1.8 V, far below the 0.5 mA TDK test load.
- U17 drives only the U18 A input and its internal 288 kOhm pull-down. At the TI 100 uA output test point, U17 guarantees `VOH >= VCC - 0.3 V` and `VOL <= 0.3 V` through 125 C, both valid for the U18 VCCA-referenced input thresholds.
- Place one 100 nF bypass capacitor at U17 pin 14 to GND pin 7. Exact capacitor RefDes and MPN are assigned by `MAIN-AUTH-010`.

## U18 SN74AXC1T45DRLR contract

The project-local `TI_DRL0006A_SOT6` footprint follows TI 4223266/F: six
0.67 x 0.30 mm R0.05 lands at 0.50 mm pitch with 1.48 mm between row
centers, equal-size stencil apertures, and 0.05 mm preferred NSMD expansion.
The exact official package drawing is
`https://www.ti.com/lit/pdf/MPDS159I`, SHA-256
`588597e633a3f02cd4546fd98f6872ef98a6578e1285db325eda3bbb16a516ee`.

- U18 DRL package pin 1 `VCCA` uses `1V8_MIC`; pin 6 `VCCB` uses `3V3_DIGITAL`; pin 2 is GND.
- Pin 5 `DIR` is tied directly to `1V8_MIC`, fixing A-to-B translation.
- Pin 3 A receives `MIC_WAKE_OR_1V8` from U17 pin 8. Pin 4 B drives STM32 `MIC_WAKE` at PA8, LQFP100 pin 67.
- `MIC_WAKE` has a required 100 kOhm pull-down to GND on the MCU side. PA8 therefore remains inactive if U18 is high impedance during a partial-power condition.
- TI specifies Ioff, VCC isolation below 100 mV on either rail, glitch suppression, and unrestricted supply order. U18 maximum combined static supply current is 16 uA at 125 C.
- Place one 100 nF bypass capacitor at each U18 supply pin. Exact capacitor RefDes and MPN are assigned by `MAIN-AUTH-010`.

## Deterministic states

| Condition | Required state |
|---|---|
| Reset or MCU GPIO high impedance with both rails valid | U7 data-input weak pull-downs keep `PDM_CLK_1V8` and `AAD_CFG_1V8` low; U17 external pulls keep all open harness inputs low |
| AAD A or AAD D2 S0 monitoring | `1V8_MIC` remains on; `PDM_CLK=LOW`; `AAD_CFG=LOW`; U17 and U18 remain active; PA8 is low until any T5838 asserts WAKE |
| Any one MIC connector absent | Its 100 kOhm input pull-down represents inactive LOW; the remaining three WAKE channels still aggregate normally |
| `1V8_MIC` fully off or `3V3_DIGITAL` fully off | AXC VCC isolation and Ioff prevent active drive into the unpowered domain; PA8 external pull-down keeps `MIC_WAKE` low when applicable |
| Normal PDM capture | U7 channels 1 through 4 translate four independent data lines to the MCU while channel 5 translates the common clock to all leaves |
| AAD one-wire configuration | U7 channel 6 broadcasts PA15 `AAD_CFG` to all four T5838 THSEL pins; PDM clock follows the TDK sequence required by the selected AAD mode |

## Review A measurements still required

Closing `MAIN-AUTH-003` freezes capture inputs but does not replace hardware verification. Review A and EVT must still include:

- oscilloscope validation of all four PDM data channels at the U7 A and B ports, including T5838 tri-state intervals;
- final-harness PDM clock rise/fall time, overshoot, ringing, duty cycle, inter-channel skew, and source-termination decision;
- `AAD_CFG_1V8` one-wire amplitude, rise time, fanout, register-write success, cold boot, brownout, and microphone-rail-cycle recovery;
- individual `MIC_WAKE1..4`, both U17 first-stage nodes, U17 aggregate output, U18 output, and PA8 Stop-mode wake latency;
- open-harness and short-to-ground fault behavior for every microphone connector;
- false-wake and missed-wake tests over the project acoustic and temperature matrix;
- measured U7/U17/U18 current and complete system S0 current at the defined environmental points.

Exact passive identities remain controlled by `MAIN-AUTH-010`. Native capture, ERC, BOM-from-schematic comparison, and independent PCB Review A remain mandatory.

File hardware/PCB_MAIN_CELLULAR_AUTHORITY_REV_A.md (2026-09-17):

# PCB-MAIN cellular modem authority - EVT-PRE-20 Rev.A

Status: `CELLULAR_AUTHORITY_PASS / PCB REVIEW A NOT STARTED / NOT FOR MANUFACTURE`

This record closes only `MAIN-AUTH-004`. It freezes the exact U8 BG95-M3 and U16 translator pads, the two open-collector control stages, deterministic reset states, modem power sequencing, and the required local burst network. The dual-SIM network is controlled separately by `PCB_MAIN_DUAL_SIM_PIN_AUTHORITY_REV_A.csv` under `MAIN-AUTH-005`. The cellular RF and recovery fixture endpoints are controlled by `PCB_MAIN_CONNECTOR_FIXTURE_PIN_AUTHORITY_REV_A.csv` under `MAIN-AUTH-009`. This record by itself did not close the exact passive set in `MAIN-AUTH-010` or layout authority in `MAIN-AUTH-011`; both are now separately frozen. Native capture, PCB Review A, PCB Review B, and the production BOM remain blocked.

Machine authority: `hardware/PCB_MAIN_CELLULAR_PIN_AUTHORITY_REV_A.csv`.

Authority CSV SHA-256: `3431c903eb9a1138e9976a0d95479c4269e2c0d25d72c98bbe5dc6e7785c6579`.

## Primary evidence

- Quectel `BG95 Series Hardware Design`, version 1.6, 14 August 2023. The retrieved original Quectel document has SHA-256 `6ff03aa31577971d02dc15eac11adee4d52b80077ae3fa3503978c1b12496e81`. Public document copy: `https://raw.githubusercontent.com/jamesmarrs/farseer/fd4425f955fb3ebf50f330afe9228b8911a85a86/datasheets/quectel_bg95_series_hardware_design_v1-6.pdf`. Canonical product page: `https://www.quectel.com/product/lpwa-bg95-cat-m1-cat-nb2-egprs-series/`.
- TI `SN74AXC8T245` datasheet SCES875C, Revision C, January 2024: `https://www.ti.com/lit/ds/symlink/sn74axc8t245.pdf`. Retrieved document SHA-256: `6cf4003c438c0546fb86f0932613896197dd19a75bdb307f385eb6e75535126e`.
- Nexperia `MMBT3904` product data sheet, version 5, 8 April 2026: `https://assets.nexperia.com/documents/data-sheet/MMBT3904.pdf`. Retrieved document SHA-256: `ade27b408c77a94ea4448c8473a9e80096dd60da3e1914e004c52344e9cd8d00`.
- Project sources: `hardware/EVT_PRE_20_PIN_MAP_REV_A.csv`, `hardware/PCB_MAIN_MCU_PIN_AUTHORITY_REV_A.csv`, `hardware/POWER_DESIGN_BASELINE_REV_A.json`, `hardware/POWER_DESIGN_CALC_REV_A.md`, and `hardware/PWR_MAIN_12PIN_I2C_FREEZE_REV_A.md`.

## U8 BG95-M3 pad contract

The selected module is the 102-pad `BG95-M3` in the 23.6 x 19.9 mm LGA form. Every physical pad is accounted for in the machine authority. The accounting includes 28 ground pads, four VBAT pads, one VDD_EXT output, seven locally closed functional signals, the resolved six-pad dual-SIM interface controlled by `MAIN-AUTH-005`, seven RF/recovery pads controlled by the closed `MAIN-AUTH-009`, and all unused, unsupported, and reserved pads.

The following locally closed signals are exact:

| U8 pad | BG95 signal | Rev.A net | Destination |
|---:|---|---|---|
| 15 | `PWRKEY` | `U8_PWRKEY_N` | Q1 open collector |
| 17 | `RESET_N` | `U8_RESET_N` | Q2 open collector |
| 20 | `STATUS` | `U8_STATUS_1V8` | U16 A2 |
| 29 | `VDD_EXT` | `U8_VDD_EXT_1V8` | U16 VCCA and local 1.8 V pull-ups |
| 30 | `MAIN_DTR` | `U8_MAIN_DTR_1V8` | U16 A6 |
| 34 | `MAIN_RXD` | `U8_MAIN_RXD_1V8` | U16 A5 |
| 35 | `MAIN_TXD` | `U8_MAIN_TXD_1V8` | U16 A1 |
| 39 | `MAIN_RI` | `U8_MAIN_RI_1V8` | U16 A3 |

- Pads 32 and 33 are both `VBAT_BB` and connect to `3V8_MODEM_BB`.
- Pads 52 and 53 are both `VBAT_RF` and connect to `3V8_MODEM_RF`.
- The BG95-M3 input range is 3.3 to 4.3 V with 3.8 V nominal. The rail must never fall below 3.3 V at any U8 VBAT pad.
- All 28 module GND pads connect to the low-impedance `GND_MODEM` plane with ground vias placed according to the Quectel land pattern.
- Pad 60 `ANT_MAIN` is fixed as the `CELL_RF` source and terminates only at J8 through the no-stub 50 Ohm matching/protection path controlled by `MAIN-AUTH-009`; exact parts are frozen by `MAIN-AUTH-010`, and the U8/J8 placement zone is frozen by `MAIN-AUTH-011`. Stackup-derived 50 Ohm geometry and RF acceptance remain Review-B/EVT work.
- Pad 42 `USIM_DET` is NC because independent J6/J7 card-detect switches terminate at the MCU. Pads 43 through 46 terminate at U13, and pad 47 connects directly to `GND_MODEM`; the exact dual-SIM endpoints are controlled by `PCB_MAIN_DUAL_SIM_PIN_AUTHORITY_REV_A.csv`.
- Pads 8 through 10 terminate only at `TP_CELL_USB`; pads 22, 23 and 75 terminate only at `TP_CELL_DBG`. Their exact fixture contacts and domain-isolation rules are controlled by the closed `MAIN-AUTH-009`.
- All reserved pads remain NC. Unsupported `ANT_WIFI` pad 56 and `GNSS_LNA_EN` pad 51 remain NC for BG95-M3. Unused BOOT_CONFIG pads have no pull-up.

## Burst-current supply network

The external source is the single `3V8_MODEM` rail from PCB-PWR. It splits at a star point close to U8:

| Branch | Required local network | Copper rule |
|---|---|---|
| `3V8_MODEM_BB` | 100 uF low-ESR bulk plus 220 nF, 47 nF, 150 pF, 100 pF, 68 pF, 33 pF, and 10 pF; ferrite bead immediately before U8 | at least 0.6 mm equivalent width and wider for longer routes |
| `3V8_MODEM_RF` | 100 uF low-ESR bulk plus 100 nF, 33 pF, and 10 pF; 0 Ohm link immediately before U8 | at least 2.7 mm equivalent width and no neck-down |

- FB1 is frozen by `MAIN-AUTH-010` as Murata `BLM31KN601SN1L`; Review A must verify the required current margin, low DC resistance and at least 800 Ohm impedance in the 700 to 960 MHz range.
- The two low-leakage TVS positions recommended by Quectel and all exact capacitor, ferrite, and 0 Ohm MPNs are frozen by `MAIN-AUTH-010`.
- The 4 A PCB-PWR source remains mandatory because BG95-M3 supports EGPRS and Quectel requires a supply capability above 2.7 A when LTE Cat M1, Cat NB2, and EGPRS are enabled.
- Review A must probe the rail at all four U8 VBAT pads. Load-step and representative 2G burst tests must prove `VBAT_BB >= 3.3 V` and `VBAT_RF >= 3.3 V` at the module.
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

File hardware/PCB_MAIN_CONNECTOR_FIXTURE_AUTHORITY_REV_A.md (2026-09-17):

# PCB-MAIN connector and fixture authority - EVT-PRE-20 Rev.A

Status: `CONNECTOR_FIXTURE_AUTHORITY_PASS / PCB REVIEW A NOT STARTED / NOT FOR MANUFACTURE`

This record closes only `MAIN-AUTH-009`. It freezes the exact electrical contacts and endpoint separation for the industrial microSD card and socket, STM32 USB-C service port, all three U.FL receptacles, enclosure tamper loop, STM32 SWD, production EOL access, and BG95 USB/debug recovery. It does not release exact support-component RefDes or MPNs, connector placement or orientation, native capture, Review A, Review B, physical test results, or the production BOM.

Machine authority: `hardware/PCB_MAIN_CONNECTOR_FIXTURE_PIN_AUTHORITY_REV_A.csv`.

Authority CSV SHA-256: `b94cd4723efeffbdea7f1c6ba82f977da9c83c556967316630461af6048eaf12`.
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

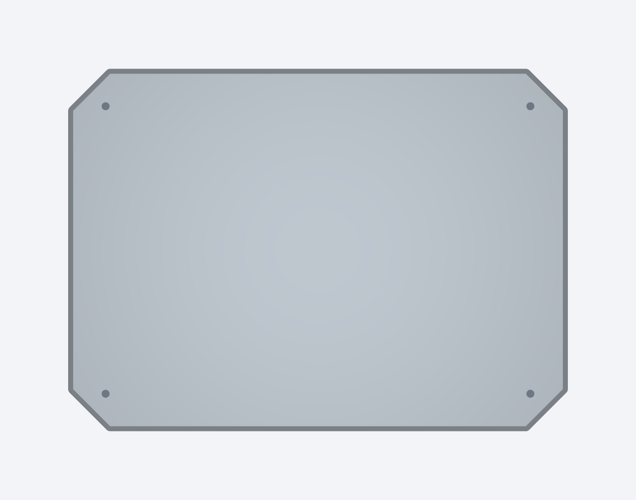
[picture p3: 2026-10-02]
releases/evt-pre-20/2026-10-02-rev-d5/Сборка_и_корпуса/03_Корпуса_для_3D_печати_ПРЕДВАРИТЕЛЬНО/Верхний_электронный_модуль/DIO-3DP-UP-001B_вид_крышки.png

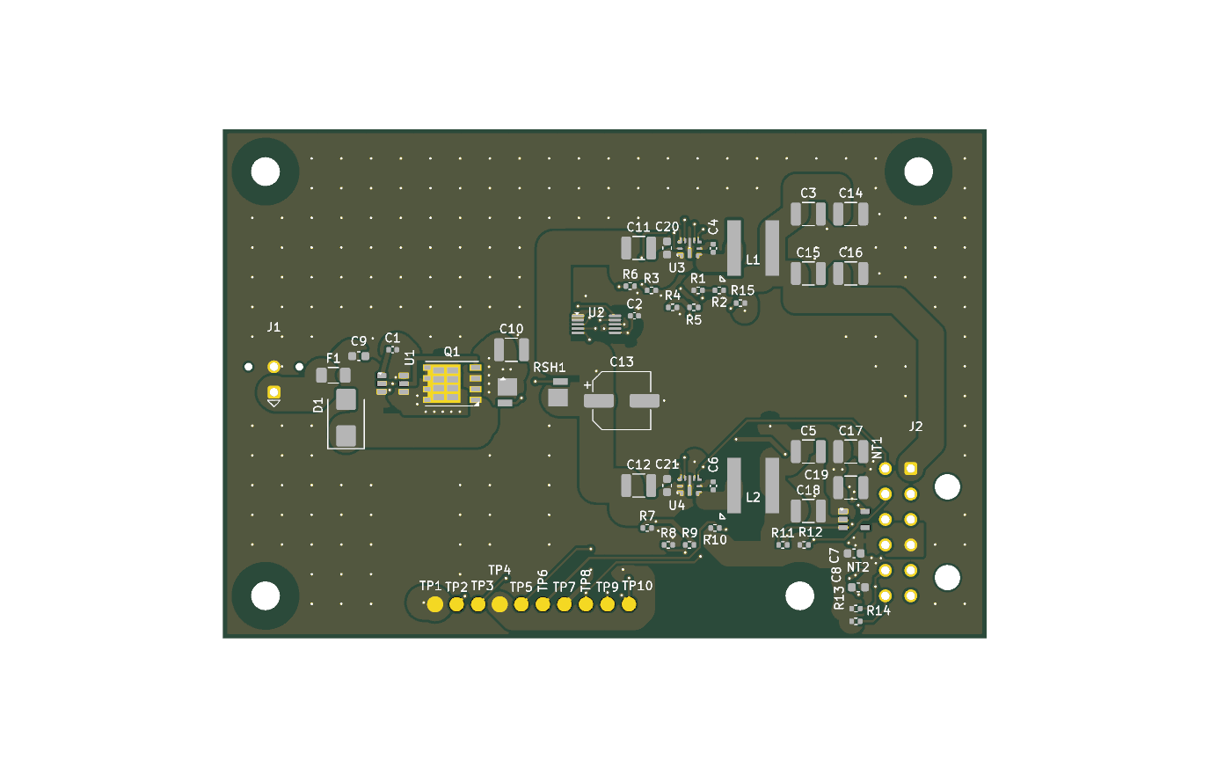
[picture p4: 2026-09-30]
releases/evt-pre-20/2026-10-02-rev-d5/Заказ_плат_и_монтаж/01_PCB_PWR_заводская_проверка_и_заказ/PCB-PWR_top.png

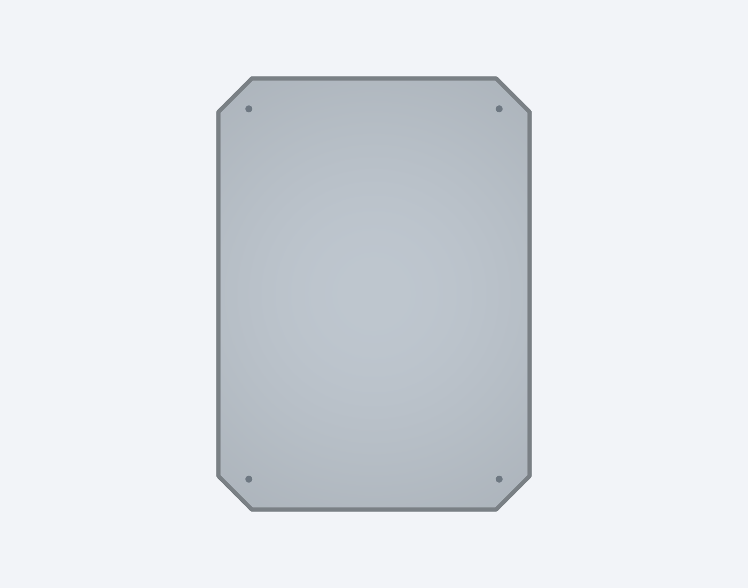
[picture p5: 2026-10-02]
releases/evt-pre-20/2026-10-02-rev-d5/Основной_пакет/03_Корпуса_для_3D_печати_ПРЕДВАРИТЕЛЬНО/Верхний_электронный_модуль/DIO-3DP-UP-001B_вид_крышки_вертикально.png

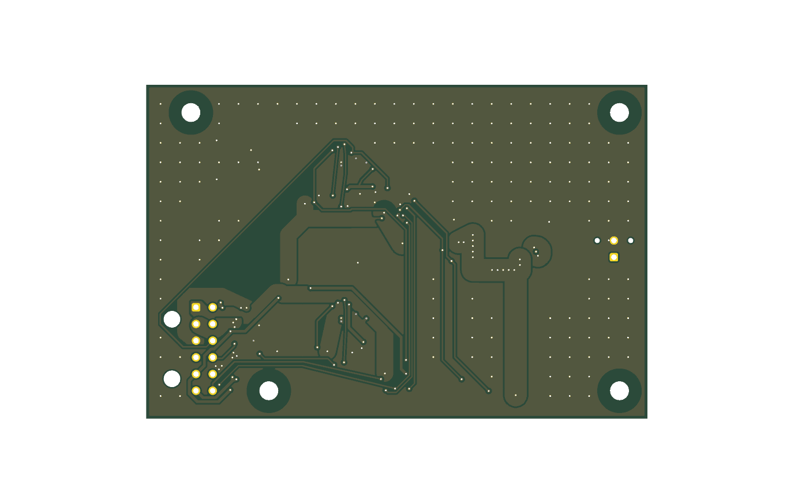
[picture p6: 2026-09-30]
releases/evt-pre-20/2026-10-02-rev-d5/Заказ_плат_и_монтаж/01_PCB_PWR_заводская_проверка_и_заказ/PCB-PWR_bottom.png

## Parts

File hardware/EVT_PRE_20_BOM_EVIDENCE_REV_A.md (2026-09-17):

# EVT-PRE-20 Rev.A BOM component evidence

Status: `CONTROLLED INPUT / NOT A PRODUCTION RELEASE`

This register records the source used to normalize exact orderable identity, package,
and temperature data in the Rev.A BOM. Electrical suitability, layout, sourcing, and
sample validation remain governed by the line blockers and QG-2.

| BOM item | Exact identity | Controlled fact | Primary evidence |
|---|---|---|---|
| U2 | `W25Q512JVFIQ` | SOIC-16, industrial `-40..85 C` suffix | [Winbond W25Q512JV product guide](https://www.winbond.com/hq/new-online-purchasing-guide/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) and W25Q512JV datasheet |
| U3 | `LIS2DW12TR` | LGA-12 2 x 2 mm, `-40..85 C` | [ST LIS2DW12 product page](https://www.st.com/en/mems-and-sensors/lis2dw12.html) and DS11811 |
| U4 | `STTS22HTR` | UDFN-6L 2 x 2 mm, `-40..125 C`; supersedes the erroneous WLCSP-4 description | [ST STTS22H product page](https://www.st.com/en/mems-and-sensors/stts22h.html) and [DS12606](https://www.st.com/resource/en/datasheet/stts22h.pdf) |
| U8 | `BG95-M3` | LGA-102 23.6 x 19.9 mm; `-35..75 C` operating and `-40..85 C` extended; all 102 pads controlled | [Quectel BG95 product page](https://www.quectel.com/product/lpwa-bg95-cat-m1-cat-nb2-egprs-series/) and BG95 Series Hardware Design v1.6; extended-range operation remains a project qualification item |
| U9 | `MAX-M10S-00B` | LCC-18 9.7 x 10.1 mm, `-40..85 C`; R08 type `MAX-M10S-00B-01` mass production | [u-blox MAX-M10S R08 data sheet](https://content.u-blox.com/sites/default/files/MAX-M10S_DataSheet_UBX-20035208.pdf), [R05 integration manual](https://content.u-blox.com/sites/default/files/MAX-M10S_IntegrationManual_UBX-20053088.pdf) and `PCB_MAIN_GNSS_PIN_AUTHORITY_REV_A.csv` |
| U16 | `SN74AXC8T245PWR` | TSSOP-24 PW; two independent direction groups; VCC isolation and Ioff | [TI SCES875C RevC](https://www.ti.com/lit/ds/symlink/sn74axc8t245.pdf) and `PCB_MAIN_CELLULAR_PIN_AUTHORITY_REV_A.csv` |
| Q1/Q2 | `MMBT3904,215` | SOT23 NPN open-collector PWRKEY and RESET_N drivers; `-65..150 C` ambient range | [Nexperia MMBT3904 product data sheet](https://assets.nexperia.com/documents/data-sheet/MMBT3904.pdf) and `PCB_MAIN_CELLULAR_PIN_AUTHORITY_REV_A.csv` |
| U13 | `TS3A27518EPWR` | TSSOP-24 PW; six bidirectional 1:2 channels; `-40..85 C`; active-HIGH High-Z EN | [TI SCDS260F RevF](https://www.ti.com/lit/ds/symlink/ts3a27518e.pdf) and `PCB_MAIN_DUAL_SIM_PIN_AUTHORITY_REV_A.csv` |
| U14/U15 | `ESDALC6V1-5P6` | SOT666; five protected lines each; `-40..125 C`; 15 pF maximum | [ST ESDALC6V1-5P6](https://www.st.com/resource/en/datasheet/esdalc6v1-5p6.pdf) and `PCB_MAIN_DUAL_SIM_PIN_AUTHORITY_REV_A.csv` |
| Q3 | `MMBT3904,215` | SOT23 NPN boot-safe active-HIGH SIM mux enable inverter | [Nexperia MMBT3904 product data sheet](https://assets.nexperia.com/documents/data-sheet/MMBT3904.pdf) and `PCB_MAIN_DUAL_SIM_PIN_AUTHORITY_REV_A.csv` |
| J6/J7 | `2336582-1` | TE 4FF push-push, seven loaded positions plus grounded shell, `-40..85 C`; procurement risk retained | [TE product page](https://www.te.com/en/product-2336582-1.html), controlled drawing C-2336582 A2 and `PCB_MAIN_DUAL_SIM_PIN_AUTHORITY_REV_A.csv` |
| U10 | `E22-900M22S` | SMD 20 x 14 mm, 22 pads at 1.27 mm, `-40..85 C`; current manual v1.2 lists 850 to 930 MHz, 22 dBm, 1.8 to 3.7 V and IPEX-1/castellated antenna options | [Ebyte E22-M v1.2 manual](https://www.ebyte.com/Uploadfiles/Files/2026-2-7/2026271136241143.pdf), [exact product page](https://www.ebyte.com/product/435.html) and `PCB_MAIN_LORA_PIN_AUTHORITY_REV_A.csv` |
| X1 | `SiT1552AI-JE-DCC-32.768D` | CSP-4 1.5 x 0.8 mm, `-40..85 C` | [SiTime exact-orderable product page](https://www.sitime.com/parts/sit1552ai-je-dcc-32768) and [SiT1552 datasheet](https://www.sitime.com/datasheet/SiT1552) |
| PWR-TVS-01 | `SMBJ18A` | SMB/DO-214AA, `-65..150 C` junction operating range | [Littelfuse SMBJ18A product page](https://www.littelfuse.com/products/overvoltage-protection/tvs-diodes/surface-mount/smbj/smbj18a) and [SMBJ series datasheet](https://www.littelfuse.com/assetdocs/tvs-diodes-smbj-series-datasheet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) |
| PWR-FUSE-01 | `0451008.MRL` | Selected EVT qualification candidate: Nano2 451 8 A, `-55..125 C`, 7.7 mOhm nominal cold resistance and 20.23 A²s nominal melting I²t. The datasheet requires standard 25% continuous derating plus its temperature curve. Historical native value `0451005.MRL` is rejected for 5 A continuous service; the bounded value-only ECO and commit-bound ERC/PDF evidence pass with topology retained, while human review and physical qualification remain open. | [Littelfuse 0451008 product page](https://www.littelfuse.com/products/fuses-overcurrent-protection/fuses/surface-mount-fuses/nano-2-fuses/451/0451008), [451/453 series datasheet](https://www.littelfuse.com/assetdocs/fuse-451-and-453-datasheet?assetguid=533cd5cc-956c-4243-867f-6ab5a62f6ba1), [Molex 43045-0213](https://www.molex.com/en-us/products/part-detail/430450213) and [Molex 43030-0038](https://www.molex.com/en-us/products/part-detail/430300038) |
| PWR-COUT-3V8/3V3 | `CGA6P3X7R1E226M250AB` | four physical 22 uF, 25 V, X7R, 1210 MLCCs per rail; refs `C3/C14-C16` and `C5/C17-C19` | [TDK exact product page](https://product.tdk.com/en/search/capacitor/ceramic/mlcc/info?part_no=CGA6P3X7R1E226M250AB) |
| PWR-C-CIN-HF | `CGA3E2X7R1H104K080AA` | `C9`, 100 nF, 50 V, X7R, 0603, `-55..125 C`; protected-input high-frequency bypass candidate | [TDK exact product page](https://product.tdk.com/en/search/capacitor/ceramic/mlcc/info?part_no=CGA3E2X7R1H104K080AA) |
| PWR-C-INPUT | `CGA6P3X7R1H475K250AB` | `C10-C12`, 4.7 uF, 50 V, X7R, 1210, `-55..125 C`; transient and DC-bias evidence remains blocking | [TDK exact product page](https://product.tdk.com/en/search/capacitor/ceramic/mlcc/info?part_no=CGA6P3X7R1H475K250AB) |
| PWR-C-BULK | `EEH-ZK1V101XP` | `C13`, 100 uF, 35 V hybrid, 6.3 x 7.7 mm, `-55..125 C`, 35 mOhm maximum ESR and 1.7 Arms at 100 kHz; manufacturer land-pattern comparison remains blocking | [Panasonic exact product page](https://na.industrial.panasonic.com/products/capacitors/aluminum-electrolytic-capacitors/series/89/model/185) |
| MK1 | `MMICT5838-00-012` | LGA-CAV-5 3.5 x 2.65 x 0.98 mm, `-40..85 C`; exact order code already present in native PCB-MIC | [TDK T5838 product page](https://www.invensense.tdk.com/en-us/products/microphone/t5838) and DS-000383 v1.2 |
| BAT1 | RELiON `RB40` | selected EVT candidate: 12.8 V, 40 Ah, 512 Wh, 197 x 166 x 173 mm, M8, IP66; discharge `-20..60 C`, charge `-20..45 C`; does not by itself close station `-40..+70 C` | [RELiON RB40 product page](https://www.relionbattery.com/products/lithium/rb40); capacity/DCIR/BMS/cold-soak/transport evidence remains blocking |
| PV1 | SLD Tech / Solarland `SLP080S-12M` | selected EVT candidate: 80 W, Vmp 18.46 V, Imp 4.33 A, Voc 22.52 V, Isc 4.56 A, 1475 x 342 x 40 mm, `-40..85 C` | [SLD Tech exact product page](https://sldtechinc.com/80w-12v-monocrystalline-solar-panel-s/); IV, cold-Voc, insulation and mechanical sample remain blocking |
| MPPT1 | Victron Energy `SCC075010060R` | selected SmartSolar MPPT 75/10 EVT candidate: 12/24 V, 10 A, 75 V maximum PV, 145 W nominal PV at 12 V, `-30..60 C`; IP43 electronics / IP22 terminal area | [Victron SmartSolar 75/10 technical specifications](https://www.victronenergy.com/media/pg/Manual_SmartSolar_MPPT_75-10_up_to_100-20/en/technical-specifications.html); configuration, cold enclosure, quiescent/reverse-current and transient samples remain blocking |
| MPPT-TEMP | Victron Energy `SBS050150200` | selected long-range Smart Battery Sense candidate; `10 m` is wireless range, while the leads are `0.45 m`; M10 eyelets require an approved retention stack on the RB40 M8 terminals; operating range `-10..60 C`; supplies actual battery voltage/temperature over VE.Smart; low-temperature cut-off is active only while the controller receives that temperature | [Victron temperature sensor matrix](https://www.victronenergy.com/live/temperature_sensors), [Smart Battery Sense technical specification](https://www.victronenergy.com/media/pg/Smart_Battery_Sense/en/technical-specifications.html), [product page](https://www.victronenergy.com/meters-and-sensors/smart-battery-sense) and [SmartSolar cut-off behavior](https://www.victronenergy.com/media/pg/Manual_SmartSolar_MPPT_75-10_up_to_100-20/en/configuration-and-settings.html); terminal-stack fit, pairing retention, cold-system behavior and `0 C` cut-off sample remain blocking |
| ANT-CELL | Taoglas `G30.B.108111` | selected EVT candidate: external IP67 permanent-mount cellular antenna, SMA(M), 1 m integral cable, manufacturer headline bands 698-960 and 1710-2700 MHz, `-40..85 C` | [Taoglas exact product page](https://www.taoglas.com/product/olympian-g30-2g3g4g-lte-antenna/); ordered cable construction, installed S11/VSWR/loss and BG95-M3 coexistence sample remain blocking |
| ANT-GNSS | Taoglas `AA.166.A.301111` | selected EVT candidate: active L1 multi-GNSS, 1559-1610 MHz, 3-5 V, IP67, 3 m RG-174, SMA(M), `-40..85 C`; project supervisor limit is 50 mA | [Taoglas exact product page](https://www.taoglas.com/product/aa-166-a-301111-ulysses-miniature-magnetic-mount-beidougpsglonassgalileo-antenna-with-3000mm-rg-174-smam/) and [datasheet](https://www.taoglas.com/datasheets/AA.166.301111.pdf); current at 3.3 V, receiver sensitivity, PPS and coexistence sample remain blocking |
| ANT-LORA | Taoglas `TI.89.B.2111W` | selected EVT candidate: IP67 SMA(M) terminal antenna, 860-930 MHz with specified 862-874 MHz 868-band measurement, 180 x 13 mm, `-40..85 C` | [Taoglas exact datasheet](https://www.taoglas.com/datasheets/TI.89.B.2111W.pdf); installed S11/VSWR, conducted sensitivity/power and RU868 radiated evidence remain blocking |
| RF-PIGTAIL | Taoglas `CAB.0243` | selected common candidate for J8/J9/J10: 150 mm 1.13 mm micro-coax, right-angle I-PEX MHF I (U.FL-compatible) end to normal-polarity waterproof SMA(F) bulkhead; published operating range `-60..200 C` and minimum bend radius 6.8 mm | [Taoglas exact product page](https://www.taoglas.com/product/cab-0243-i-pex-mhf-i-u-fl-to-150mm-1-13-cable-to-smafbk-st-waterproof/) and [SPE-24-8-147-A](https://www.taoglas.com/datasheets/CAB.0243.pdf); mating/retention with `U.FL-R-SMT-1(60)`, actual 150 mm route, lot temperature confirmation, numeric seal/IP evidence and installed VNA sample remain blocking |
| J-RF-CELL/GNSS/LORA | `U.FL-R-SMT-1(60)` | board receptacle `-40..90 C`; common cable candidate is separate BOM line `RF-PIGTAIL` and remains physically unqualified | [Hirose exact product page](https://www.hirose.com/en/product/p/CL0331-0472-2-60) and [U.FL series catalog](https://www.hirose.com/en/product/document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) |

For every candidate or pending line, current manufacturer documentation shall be
captured into the release data pack at the revision used by the design review. Links
above are evidence pointers, not permission to substitute a family member or suffix.

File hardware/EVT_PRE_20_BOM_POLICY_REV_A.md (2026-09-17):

# EVT-PRE-20 Rev.A production BOM policy

Status: `ACTIVE / PRODUCTION BOM BLOCKED`

`hardware/EVT_PRE_20_BOM_REV_A.csv` is the generated controlled engineering BOM.
`hardware/EVT_PRE_20_BOM_PROCUREMENT_REV_A.csv` is its MPN-level procurement roll-up.
Both contain explicit lot calculations for 4, 10 and 20 stations. They may be used for
sourcing work and design review, but they are not a factory release while QG-2 reports
`BLOCKED`.

`manufacturing/EVT_LOT_SELECTION_REV_A.csv` is the scenario-selection authority.
`EVT-20` is selected for the current customer. The 4- and 10-station columns remain
controlled comparison scenarios only; quantities and spare columns from different
scenarios must never be mixed. Selection alone does not authorize purchasing while
QG-2 or supplier release evidence remains open.

## Required line data

Every fitted electrical, harness and system line must contain:

- one unambiguous assembly and reference designation;
- manufacturer and exact orderable MPN;
- value where applicable, exact package or mechanical form;
- population state, quantity per station, lot quantities, spares and procurement totals
  for 4, 10 and 20 stations;
- operating temperature capability compatible with the Rev.A environment rule;
- selection status, source evidence and incoming-control method.

An exact hardware MPN may be `CONTROLLED_PENDING_VERIFICATION` when the remaining
evidence can only be collected on assembled stations. For `U8`, `BG95-M3` is the
controlled hardware identity; marking and firmware identity are incoming checks,
while operator/SIM attach and representative burst results remain post-assembly EVT.
Those later tests may not be marked PASS in the BOM and do not revert the exact MPN
to an unresolved engineering selection.

PCBA service and bare-PCB lines use the released fabrication/assembly specification and
approved supplier instead of an electronic-component MPN. Conditional housing options
must have zero quantity unless that variant is formally selected.

## Quantity authority

- one station has one PCB-MAIN, one PCB-PWR and four identical PCB-MIC assemblies;
- four MIC cables require eight `5040510601` housings and 48 `5040520098` terminals;
- the four MIC leaves and PCB-MAIN require eight `5040500691` board headers total;
- one MAIN-PWR cable requires two `43025-1200` housings and 24 terminals: 12 power
  terminals `43030-0038` and 12 control/I2C terminals `43030-0001`;
- `Qty_N = Qty_per_station x N` and `Procure_qty_N = Qty_N + Spares_N` for
  `N = 4, 10, 20` on every engineering and procurement row.
- `SCALE_CEIL_FROM_20_BASELINE` scales the controlled 20-station spare allowance with
  upward rounding. `FIXED_LOT_MIN` keeps the same handling minimum for every supported
  lot. `NONE` requires zero spares.
- DNP lines and non-procured PCB features carry zero spares. PCB-PWR inductors carry a
  fixed minimum of 10 lot spares. Fitted small PCB-PWR passives and the two PCB-MIC
  0402 lines carry a fixed minimum of 40 lot spares. MIC crimp terminals carry one
  complete station spare set, 48 terminals, for every supported lot.

Exact identity, package, and rating evidence normalized during BOM work is recorded in
`hardware/EVT_PRE_20_BOM_EVIDENCE_REV_A.md`.

PCB-PWR passive, net-tie and DFT physical references are sourced only from
`hardware/PCB_PWR_PASSIVE_AUTHORITY_REV_A.csv`. The generator groups its 17 procured
or fabricated BOM item IDs from that per-reference authority; DFT points have no BOM
item ID and must not leak into procurement quantities.

## Double control

QG-1 (`tools/validate_evt_pre_20_bom_qg1.py`) checks schema, 4/10/20 arithmetic,
spare-policy application, engineering-to-procurement reconciliation, native PCB-PWR
major RefDes mapping, connector MPNs and quantity invariants. Every controlled RFQ
also names its source BOM item or items; QG-1 independently sums their
`Procure_qty_4/10/20` values and requires an exact match to the RFQ quantities.
Dedicated RFQs are mandatory for the eight purchase-release system/mechanical items
`BAT1`, `PV1`, `MPPT1`, `ANT-CELL`, `ANT-GNSS`, `ANT-LORA`, `HARNESS` and `HSG-VC`.
The three PCBA service lines `ASM-MAIN`, `ASM-MIC` and `ASM-PWR` and the three bare-PCB
fabrication lines `PCB-MAIN`, `PCB-MIC` and `PCB-PWR` also require six separate RFQs.
The PCBA and bare-PCB quantities must not be merged because their spare policies and
procurement quantities differ. A PCB-PWR fabrication RFQ may collect a clearly marked
provisional budgetary response, but it is not build authorization while `DIM-003`, the
final stackup/copper weight, routing, CAM and Review B remain open.

QG-2 (`tools/audit_evt_pre_20_bom_qg2.py`) independently compares freeze tables,
checks exact fitted-line fields, independently reconstructs the 17 PCB-PWR passive
groups from the 47-row authority, repeats the 4/10/20 lot and roll-up reconciliation,
verifies schematic RefDes coverage and refuses a production release while native
schematic or system SKU evidence is incomplete.

`tools/audit_evt_pre_20_bom_workbook.py` reads the XLSX package independently with
the Python standard library. It compares every displayed value in the Engineering
BOM, Procurement and RFQ worksheets with their CSV authorities and verifies the
native Excel-table ranges, summary lot quantities and gate statuses.

The actual factory gate is:

```bash
python tools/generate_evt_pre_20_bom_rev_a.py --check
python tools/validate_evt_pre_20_bom_qg1.py
python tools/audit_evt_pre_20_bom_workbook.py
python tools/audit_evt_pre_20_bom_qg2.py --strict
python tools/audit_evt_pre_20_hardware_release.py --strict
```

No spreadsheet cleanup, RFQ response or supplier substitution may bypass the strict
gate or the independent PCB Review A and Review B requirements.

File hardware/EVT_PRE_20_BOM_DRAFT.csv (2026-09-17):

Item_ID | Assembly | RefDes | Category | Description | Manufacturer | MPN | Package | Qty_per_station | Qty_20 | Spares | Procure_qty | Variant | Status | China_source_policy | Incoming_control | Notes
ASM-MAIN | PCB-MAIN | - | PCBA | Assembled main controller PCB | Contract manufacturer | TBD | 6-layer PCBA | 1 | 20 | 2 | 22 | COMMON | RFQ_REQUIRED | Direct CM quotation | AOI plus X-ray where hidden joints plus functional test | Not released before native schematic layout DFM and Review A/B gates
PCB-MAIN | PCB-MAIN | - | Bare PCB | Main controller bare PCB | Qualified PCB fab | TBD | 6-layer FR-4 110x75x1.6 mm | 1 | 20 | 5 | 25 | COMMON | RFQ_REQUIRED | Two independent fab quotations | Coupon dimensions finish stackup impedance and netlist test | Outline and holes frozen by MAIN-AUTH-011; final stackup and controlled-impedance geometry pending fab review
U1 | PCB-MAIN | U1 | MCU | Ultra-low-power secure MCU | STMicroelectronics | STM32U585VIT6Q | LQFP100 14x14 mm | 1 | 20 | 5 | 25 | COMMON | SELECTED_PENDING_SAMPLE | Authorized distributor or traceable tier-1 China channel | Label lot date code package X-ray sample ID readout | Active official product
U2 | PCB-MAIN | U2 | Memory | 512 Mbit 64 MB QSPI NOR | Winbond | W25Q512JVFIQ | SOIC-16 300 mil | 1 | 20 | 5 | 25 | COMMON | SELECTED_PENDING_SAMPLE | Authorized or traceable LCSC-class channel | Marking electrical ID read/write/erase soak | Alternate MT25QL512 only after firmware and footprint review
U3 | PCB-MAIN | U3 | Motion | Low-power accelerometer | STMicroelectronics | LIS2DW12TR | LGA-12 | 1 | 20 | 5 | 25 | COMMON | SELECTED_PENDING_SAMPLE | Authorized distributor | Marking orientation WHO_AM_I and self-test | Exact mounting orientation in assembly drawing
U4 | PCB-MAIN | U4 | Temperature | Digital temperature sensor | STMicroelectronics | STTS22HTR | UDFN-6L 2x2 mm | 1 | 20 | 5 | 25 | COMMON | SELECTED_PENDING_ASSEMBLY_REVIEW | Authorized distributor | X-ray sample ID and temperature compare | Exposed-pad assembly and thermal response to be reviewed
U7 | PCB-MAIN | U7 | Level translator | Directional 1.8V to 3.3V translator | TBD | TBD | TBD | 1 | 20 | 5 | 25 | COMMON | OPEN_SCHEMATIC | Do not substitute auto-direction device without review | Logic levels direction leakage sleep test | Old TXB0104 not automatically approved
U8 | PCB-MAIN | U8 | Cellular | LPWA modem Cat M1 NB2 EGPRS | Quectel | BG95-M3 | LGA 23.6x19.9 mm | 1 | 20 | 5 | 25 | COMMON | SELECTED_PENDING_OPERATOR_AND_REGION | Quectel authorized channel or CM with traceability | IMEI label firmware RF conducted attach TLS | Exact regional variant must cover pilot operator bands
J-SIM1 | PCB-MAIN | J6 | SIM | Nano-SIM push-push connector slot 1 | TBD | TBD | SMD | 1 | 20 | 5 | 25 | COMMON | OPEN_MECHANICAL | Approved connector vendor | Mating cycles card detect coplanarity and ESD | Under service cover with independent SIM1_DET
J-SIM2 | PCB-MAIN | J7 | SIM | Nano-SIM push-push connector slot 2 | TBD | TBD | SMD | 1 | 20 | 5 | 25 | COMMON | OPEN_MECHANICAL | Approved connector vendor | Mating cycles card detect coplanarity and ESD | Under service cover with independent SIM2_DET
U13 | PCB-MAIN | U13 | SIM switch | 6-channel bidirectional 2 to 1 multiplexer | Texas Instruments | TS3A27518EPWR | TSSOP-24 | 1 | 20 | 5 | 25 | COMMON | CANDIDATE_PENDING_SCHEMATIC_SI_SAMPLE | Authorized distributor or traceable tier-1 channel | Marking supply leakage Ron capacitance and 100 switch cycles | Switch VDD RST CLK DATA; final MPN after BG95 signal integrity test
U14-U15 | PCB-MAIN | U14;U15 | ESD | Low-capacitance TVS array for each SIM connector | TBD | TBD | TBD | 2 | 40 | 10 | 50 | COMMON | OPEN_SCHEMATIC | Authorized distributor | Capacitance leakage ESD rating marking | Place at SIM connectors; exact topology after review
U9 | PCB-MAIN | U9 | GNSS | Independent GNSS with TIMEPULSE | u-blox | MAX-M10S-00B | LGA 9.7x10.1 mm | 1 | 20 | 5 | 25 | COMMON | SELECTED_PENDING_SAMPLE | Authorized distributor or traceable module channel | Marking firmware satellite fix PPS test | Required for concurrent timing while cellular active
U10 | PCB-MAIN | U10 | LoRa | 850-930 MHz 22 dBm SX1262 SPI module | Ebyte | E22-900M22S | SMD_20x14_22P_1.27mm | 1 | 20 | 6 | 26 | RU868_PILOT | SELECTED_PENDING_CASTELLATED_OPTION_RF_REGULATORY | Ebyte official store or authorized distributor | Marking antenna-interface option firmware conducted power sensitivity sleep current | Every selected-lot station uses RU868; procure castellated-ANT option with no module IPEX fitted; exact pad and safe-state map in PCB_MAIN_LORA_PIN_AUTHORITY_REV_A.csv
U11 | PCB-MAIN | U11 | BLE | BLE commissioning diagnostics and signed OTA coprocessor | Raytac | MDBT50Q-P1MV2 | nRF52840 SMD module with integrated PCB antenna 10.5x15.5 mm | 1 | 20 | 5 | 25 | COMMON | SELECTED_PENDING_SAMPLE_RF | Raytac authorized channel or traceable distributor | Module label firmware BLE 2M coded PHY pairing OTA current RF range and temperature test | ESP32-C3 superseded; integrated antenna requires PCB edge keepout and validation inside final housing; u.FL family variant only by RF fallback decision
U12 | PCB-MAIN | U12 | Storage | Industrial microSD 32 GB | Kingston | SDCIT2/32GB | microSD card | 1 | 20 | 5 | 25 | COMMON | SELECTED_PENDING_SAMPLE_ENDURANCE | Kingston authorized channel | CID capacity full write/read temperature and power-loss sample | pSLC-mode industrial card; exact contacts in PCB_MAIN_CONNECTOR_FIXTURE_PIN_AUTHORITY_REV_A.csv; consumer substitution requires authority review
J-SD1 | PCB-MAIN | J12 | Connector | microSD push-push connector with detect | GCT | MEM2052-00-195-00-A | microSD SMT 1.95 mm | 1 | 20 | 5 | 25 | COMMON | MECHANICAL_AUTHORITY_FROZEN_PENDING_PHYSICAL_TEST | Authorized GCT distributor | Mating detect coplanarity and cycle sample | Exact contacts and south insertion are frozen; retention and service-cover seal remain physical checks
J-TAMPER | PCB-MAIN | J13 | Connector | Two-position normally-closed tamper loop | Molex | 504050-0291 | Pico-Lock 1.50 mm right-angle SMT | 1 | 20 | 5 | 25 | COMMON | MECHANICAL_AUTHORITY_FROZEN_PENDING_PHYSICAL_TEST | Authorized Molex distributor | Mating pull continuity cable-break and cover-open fault coverage | Exact contacts and east-edge placement are frozen by the electrical and mechanical authorities
J-PWR-MAIN | PCB-MAIN | J_PWR | Connector | 12-position MAIN-PWR board header | Molex | 43045-1202 | Micro-Fit 3.0 right-angle THT | 1 | 20 | 5 | 25 | COMMON | MECHANICAL_AUTHORITY_FROZEN_PENDING_HARNESS_SI | Authorized Molex distributor | Marking dimensions latch mate continuity | Electrical pinout and west-edge placement are frozen; harness SI and physical pull remain open
J-RF-CELL | PCB-MAIN | J8 | RF connector | Cellular RF connector | Hirose | U.FL-R-SMT-1(60) | U.FL SMT receptacle | 1 | 20 | 8 | 28 | COMMON | LAYOUT_ZONE_FROZEN_PENDING_RF_VALIDATION | Authorized Hirose distributor | Visual mate gauge continuity VNA and VSWR | Exact J8 endpoint and cellular zone are frozen; stackup geometry and mating cable remain validation items
J-RF-GNSS | PCB-MAIN | J9 | RF connector | GNSS RF connector | Hirose | U.FL-R-SMT-1(60) | U.FL SMT receptacle | 1 | 20 | 8 | 28 | COMMON | LAYOUT_ZONE_FROZEN_PENDING_RF_VALIDATION | Authorized Hirose distributor | Visual mate gauge continuity receiver sensitivity and active-antenna current | Exact J9 endpoint and GNSS upper-view zone are frozen; active antenna and coax remain validation items
J-RF-LORA | PCB-MAIN | J10 | RF connector | LoRa RF connector | Hirose | U.FL-R-SMT-1(60) | U.FL SMT receptacle | 1 | 20 | 8 | 28 | RU868_PILOT | LAYOUT_ZONE_FROZEN_PENDING_RF_VALIDATION | Authorized Hirose distributor | Visual mate gauge continuity conducted power sensitivity and VSWR | Exact J10 endpoint and RU868 zone are frozen; no-stub conducted-test port and RF validation remain mandatory
X1 | PCB-MAIN | X1 | Clock | 32.768 kHz low drift oscillator | SiTime | SiT1552AI-JE-DCC-32.768D | QFN | 1 | 20 | 5 | 25 | COMMON | CANDIDATE | Authorized distributor | Frequency and current sample test | Exact suffix must be frozen
PWR-REV-CTL | PCB-PWR | U_REV | Protection | Reverse polarity and reverse current controller | Texas Instruments | LM74700QDBVRQ1 | SOT-23-6 | 1 | 20 | 5 | 25 | COMMON | SELECTED_PENDING_SCHEMATIC_SAMPLE | Authorized distributor | Marking reverse test and gate waveform | Final surge and fuse coordination still required
PWR-REV-FET | PCB-PWR | Q_REV | Protection | 60 V low-Rds(on) N-MOSFET | Texas Instruments | CSD18540Q5B | VSON-CLIP 5x6 mm | 1 | 20 | 5 | 25 | COMMON | SELECTED_TECHNICALLY_PROCUREMENT_CHECK | Authorized distributor | Marking Rds thermal and reverse fault test | SOA and gate transient review required
U-PWR1 | PCB-PWR | U1 | Power | 3.8 V modem synchronous buck | Texas Instruments | LMR604403SRAKR | RAK-9 | 1 | 20 | 5 | 25 | COMMON | SELECTED_PENDING_DESIGN_CALC_SAMPLE | Authorized distributor | Load step ripple efficiency thermal and EMI | 4 A rail; XAL7030-472MEC frozen; remaining capacitor and feedback verification pending
U-PWR2 | PCB-PWR | U2 | Power | 3.3 V digital synchronous buck | Texas Instruments | LMR604403SRAKR | RAK-9 | 1 | 20 | 5 | 25 | COMMON | SELECTED_PENDING_DESIGN_CALC_SAMPLE | Authorized distributor | Load step ripple efficiency sleep current thermal and EMI | 4 A rail; XAL7030-472MEC frozen; remaining capacitor verification pending
U-PWR3 | PCB-PWR | U3 | Power | 1.8 V low-noise microphone LDO | Texas Instruments | TPS7A2018PDBVR | SOT-23-5 | 1 | 20 | 5 | 25 | COMMON | SELECTED_PENDING_NOISE_SAMPLE | Authorized distributor | Noise PSRR dropout thermal and AAD sleep current | Remains powered during T5838 AAD monitoring
U-MON-01 | PCB-PWR | U4 | Monitor | Total battery current voltage and power monitor | Texas Instruments | INA226AIDGSR | VSSOP-10 | 1 | 20 | 5 | 25 | COMMON | SELECTED_REV_A_12PIN_I2C | Authorized distributor | Marking I2C ID calibration and reference-meter compare | Address 0x40 on I2C2 pins 11/12 of MAIN-PWR; ALERT may feed FAULT but does not replace I2C
R-SHUNT-01 | PCB-PWR | R_SHUNT | Shunt | 10 mOhm 4-terminal Kelvin current shunt | Vishay Dale | WSK2512R0100FEA | WSK2512 4-terminal | 1 | 20 | 10 | 30 | COMMON | SELECTED_PENDING_KELVIN_LAYOUT_SAMPLE | Authorized current-sense resistor vendor | Resistance TCR marking and four-wire reference measurement | 10 mOhm 1% 1 W +/-35 ppm/C; exact footprint controlled; Kelvin layout and calibration remain blocking
J-PWR-PWR | PCB-PWR | J_MAIN_PWR | Connector | 12-position MAIN-PWR board header | Molex | 43045-1202 | Micro-Fit 3.0 right-angle THT | 1 | 20 | 5 | 25 | COMMON | SELECTED_ELECTRICAL_PENDING_MECHANICS | Authorized Molex distributor | Marking dimensions latch mate continuity | Electrical pinout frozen; pins 11/12 carry I2C2 to INA226
PWR-TVS-01 | PCB-PWR | D_TVS | Protection | Protected-bus transient clamp candidate | Littelfuse | SMBJ18A | SMB | 1 | 20 | 5 | 25 | COMMON | CANDIDATE_PENDING_SURGE_PROFILE | Authorized distributor | Marking clamp pulse and thermal sample | Do not release value until measured transient envelope and fuse coordination
PWR-FUSE-01 | PCB-PWR | F1 | Protection | PCB input fuse candidate | Littelfuse | 0451008.MRL | Nano2 451 | 1 | 20 | 10 | 30 | COMMON | CANDIDATE_SELECTED_FOR_EVT_QUALIFICATION_NATIVE_VALUE_ECO_APPLIED_REPEAT_EVIDENCE_PENDING | Authorized distributor | Marking continuity and controlled fault clearing | 8 A candidate; native value-only ECO applied; repeat ERC PDF human hierarchy review and physical fuse TVS connector harness and battery-side primary-fuse coordination remain blocking
ASM-PWR | PCB-PWR | - | PCBA | Assembled protected power interface PCB | Contract manufacturer | TBD | 4-layer PCBA; outer 2 oz target; inner 1 oz target; final stackup pending DFM | 1 | 20 | 2 | 22 | COMMON | RFQ_REQUIRED | Direct CM quotation | AOI functional high-current thermal | No MPPT function on this board; layer count frozen but copper weights and construction remain open
PCB-PWR | PCB-PWR | - | Bare PCB | Power interface bare PCB | Qualified PCB fab | TBD | 4-layer FR-4; outer 2 oz target; inner 1 oz target; final stackup pending DFM | 1 | 20 | 5 | 25 | COMMON | RFQ_REQUIRED | Two independent fab quotations | Copper thickness netlist high-current and Kelvin review | Layer count frozen; final copper weights by current and thermal calculation plus fabricator DFM
ASM-MIC | PCB-MIC | - | PCBA | Assembled identical microphone leaf PCB | Contract manufacturer | TBD | 2-layer PCBA | 4 | 80 | 8 | 88 | COMMON | RFQ_REQUIRED | Direct CM quotation | AOI acoustic port inspection channel functional test | Same PCB revision all positions
PCB-MIC | PCB-MIC | - | Bare PCB | Microphone leaf bare PCB | Qualified PCB fab | TBD | 2-layer FR-4 | 4 | 80 | 20 | 100 | COMMON | RFQ_REQUIRED | Two independent fab quotations | Outline hole position finish netlist | Panelization to be approved
MK1 | PCB-MIC | MK1 | Microphone | Digital bottom-port PDM MEMS microphone | TDK InvenSense | MMICT5838-00-012 | LGA-CAV-5 3.5x2.65x0.98 mm | 4 | 80 | 16 | 96 | COMMON | SELECTED_PENDING_SAMPLE | TDK authorized channel and same lot requested | Marking lot acoustic sensitivity noise phase and port inspection | Exact orderable T5838 MPN; do not mix alternate MPN within station
C-MIC | PCB-MIC | C1;C2 | Passive | Local microphone decoupling capacitors | TBD | TBD | 0402 X7R | 8 | 160 | 40 | 200 | COMMON | OPEN_SCHEMATIC | Traceable passive vendor | Value package reel label capacitance sample | Final values per T5838 reference design
J-MIC | PCB-MIC | J1 | Connector | 6-position positive-lock microphone harness connector | Molex | 5040500691 | Pico-Lock 1.50 mm right-angle SMT | 4 | 80 | 12 | 92 | COMMON | SELECTED_PENDING_SI_MECHANICS_AAD | Authorized Molex distributor | Mating pull test contact resistance continuity and temperature | Pinout 1V8 GND CLK DATA WAKE AAD_CFG; 4/5-pin connectors superseded
BAT1 | SYSTEM | BT1 | Battery | 12.8 V 40 Ah LiFePO4 battery with BMS | RELiON | RB40 | 197x166x173 mm IP66 M8 pack | 1 | 20 | 1 | 21 | COMMON | SELECTED_EVT_CANDIDATE_PENDING_COLD_SYSTEM_SAMPLE | RELiON or authorized distributor with exact RB40 traceability and transport documents | Label serial lot polarity voltage dimensions mass capacity DCIR BMS thresholds and documents | EVT-20 baseline is 40 Ah and 512 Wh; 60 Ah is post-EVT only; discharge -20..60 C and charge -20..45 C do not close station -40..+70 C; charging remains inhibited below 0 C through MPPT-TEMP; cold enclosure and system qualification block release
PV1 | SYSTEM | PV1 | Solar panel | 80 W 12 V monocrystalline outdoor solar panel | SLD Tech / Solarland | SLP080S-12M | 1475x342x40 mm framed 36-cell panel | 1 | 20 | 1 | 21 | COMMON | SELECTED_EVT_CANDIDATE_PENDING_IV_MECHANICAL_SAMPLE | SLD Tech or authorized distributor with exact model traceability | Label dimensions Voc Isc Vmp Imp Pmax insulation wet leakage and visual inspection | 80 W baseline; Vmp 18.46 V Imp 4.33 A Voc 22.52 V Isc 4.56 A and -40..85 C; verify cold Voc bracket cable connector and transport sample before release
MPPT1 | SYSTEM | U-MPPT | Controller | External SmartSolar 10 A LiFePO4 MPPT controller | Victron Energy | SCC075010060R | 100x113x40 mm IP43 electronics IP22 terminals | 1 | 20 | 1 | 21 | COMMON | SELECTED_EVT_CANDIDATE_PENDING_CONFIG_COLD_SAMPLE | Victron authorized distributor with exact article traceability | Article label firmware configuration export charge profile reverse current quiescent thermal and cutoff test | SmartSolar MPPT 75/10; 12/24 V 10 A 75 V and 145 W nominal PV at 12 V; pair with MPPT-TEMP in one VE.Smart network and set low-temperature cutoff to 0 C; -30..60 C controller range and exposed terminals require enclosure and cold-system qualification
MPPT-TEMP | SYSTEM | TS-BAT1 | Sensor | Wireless battery voltage and temperature sensor for MPPT | Victron Energy | SBS050150200 | Smart Battery Sense long range up to 10 m radio with 0.45 m leads and M10 eyelets | 1 | 20 | 1 | 21 | COMMON | SELECTED_EVT_CANDIDATE_PENDING_NETWORK_COLD_SAMPLE | Victron authorized distributor with exact article traceability | Article label 0.45 m lead M10 eyelets voltage temperature accuracy VE.Smart pairing cutoff and reconnect test | Required for SmartSolar low-temperature inhibit; attach to RB40 body and M8 terminals through an approved retention stack; official operating range is -10..60 C and 10 m denotes wireless range not lead length; prove eyelet retention actual battery temperature reception cutoff at 0 C resume above 0.5 C network retention and cold-system behavior before release
ANT-CELL | SYSTEM | AE1 | Antenna | Outdoor wideband cellular antenna with SMA male cable | Taoglas | G30.B.108111 | IP67 screw-mount dome with 1 m cable and SMA(M) | 1 | 20 | 2 | 22 | COMMON | SELECTED_EVT_CANDIDATE_PENDING_INSTALLED_VSWR_COEX_SAMPLE | Taoglas or authorized distributor with exact MPN traceability | Label connector cable construction length S11 gain efficiency IP and temperature plus sample VNA | 698-960 and 1710-2700 MHz manufacturer headline coverage for BG95-M3; SMA(M) mates outside the housing to RF-PIGTAIL bulkhead; verify ordered cable construction installed VSWR loss coexistence and mounting seal
ANT-GNSS | SYSTEM | AE2 | Antenna | Outdoor active multi-GNSS L1 antenna with SMA male cable | Taoglas | AA.166.A.301111 | IP67 magnetic 37.8x40.4x10 mm with 3 m RG174 SMA(M) | 1 | 20 | 2 | 22 | COMMON | SELECTED_EVT_CANDIDATE_PENDING_BIAS_SENSITIVITY_COEX_SAMPLE | Taoglas or authorized distributor with exact MPN traceability | Label connector cable length bias current gain noise figure S11 IP and temperature plus receiver sample | 1559-1610 MHz and 3-5 V active antenna; SMA(M) mates outside the housing to RF-PIGTAIL bulkhead; verify current at 3.3 V is at most 50 mA plus mounting sensitivity PPS and LTE/RU868 coexistence
ANT-LORA | SYSTEM | AE3 | Antenna | Outdoor RU868 terminal antenna with SMA male | Taoglas | TI.89.B.2111W | IP67 terminal antenna 180x13 mm SMA(M) | 1 | 20 | 2 | 22 | RU868_PILOT | SELECTED_EVT_CANDIDATE_PENDING_INSTALLED_VSWR_CONDUCTED_RADIATED_SAMPLE | Taoglas or authorized distributor with exact MPN traceability | Label connector dimensions S11 gain IP temperature and sample VNA | 860-930 MHz with 862-874 MHz measured 868 MHz range; SMA(M) mounts on RF-PIGTAIL bulkhead; verify installed VSWR conducted power sensitivity coexistence and RU868 radiated compliance
RF-PIGTAIL | SYSTEM | J8/J9/J10 cable | RF cable | Internal 150 mm U.FL-compatible right-angle to SMA female bulkhead pigtail | Taoglas | CAB.0243 | 1.13 mm micro-coax 150 mm MHF I/U.FL-compatible R/A to waterproof SMA(F) bulkhead | 3 | 60 | 6 | 66 | COMMON | SELECTED_EVT_CANDIDATE_PENDING_MATE_ROUTE_SEAL_VSWR_SAMPLE | Taoglas or authorized distributor with exact MPN traceability | 100 percent identity continuity polarity length and connector inspection plus sample mate retention VNA bend seal and temperature test | One identical pigtail on J8 J9 and J10; Taoglas SPE-24-8-147-A states I-PEX MHF I (U.FL compatible) to normal-polarity SMA(F) bulkhead with 150 mm 1.13 mm coax minimum bend radius 6.8 mm and published -60..200 C operating range; product page calls the bulkhead waterproof but gives no numeric IP class; verify mate and retention with U.FL-R-SMT-1(60) routing seal torque lot temperature and installed RF loss
HARNESS | SYSTEM | - | Harness | Complete labeled harness set | TBD | TBD | Assembly | 1 | 20 | 2 | 22 | COMMON | OPEN_MECHANICAL_LENGTH_FREEZE | Qualified harness factory | 100 percent continuity polarity pull sample | MAIN-PWR uses two 43025-1200 housings; 18 AWG 43030-0038 for pins 1-6 and 20-24 AWG 43030-0001 for pins 7-12; separate drawing required
HSG-VC | SYSTEM | HSG1 | Housing | Vacuum-cast polyurethane housing set | TBD | TBD | Assembly | 1 | 20 | 0 | 20 | VACUUM_CASTING_PRIMARY | RFQ_REQUIRED | Qualified vacuum casting manufacturer | FAI dimensions material cure finish inserts leak fit acoustic and RF checks | Primary process for each selected EVT lot; controlled procurement calculations are generated for 4 10 and 20 stations
HSG-3D | SYSTEM | HSG1 | Housing | 3D-printed fallback housing set | TBD | TBD | Assembly | 0 | 0 | 0 | 0 | THREE_D_PRINT_FALLBACK | SOURCE_PACKAGE_REQUIRED | Qualified print supplier or controlled FlashForge 5M Pro process | Engineering sample dimensions material finish leak fit acoustic and RF checks | Conditional selected-lot demand is activated only by ECO; 4 10 and 20 station scenarios remain zero until activation
HSG-IM | SYSTEM | HSG1 | Housing | Injection-molding source package and DFM | TBD | TBD | Source_data | 0 | 0 | 0 | 0 | INJECTION_MOLDING_FUTURE | SOURCE_PACKAGE_REQUIRED | Qualified mold manufacturer for DFM quotation | Source audit wall draft ribs bosses parting ejector shrink material and tooling concept | No tooling or physical pilot housing without separate authorization

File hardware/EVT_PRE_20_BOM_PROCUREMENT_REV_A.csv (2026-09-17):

Procurement_ID | Assemblies | Item_IDs | RefDes | Category | Manufacturer | MPN | Package | Value | Variant | Population | Qty_4 | Spares_4 | Procure_qty_4 | Qty_10 | Spares_10 | Procure_qty_10 | Qty_20 | Spares_20 | Procure_qty_20 | Spare_policy | BOM_disposition | Status | China_source_policy | Incoming_control
PR-001 | PCB-MAIN | ASM-MAIN | - | PCBA | Contract manufacturer | TBD | 6-layer PCBA |  | COMMON | N/A | 4 | 1 | 5 | 10 | 1 | 11 | 20 | 2 | 22 | SCALE_CEIL_FROM_20_BASELINE | BLOCKED_SUPPLIER_RELEASE | RFQ_REQUIRED | Direct CM quotation | AOI plus X-ray where hidden joints plus functional test
PR-002 | PCB-MIC | ASM-MIC | - | PCBA | Contract manufacturer | TBD | 2-layer PCBA |  | COMMON | N/A | 16 | 2 | 18 | 40 | 4 | 44 | 80 | 8 | 88 | SCALE_CEIL_FROM_20_BASELINE | BLOCKED_SUPPLIER_RELEASE | RFQ_REQUIRED | Direct CM quotation | AOI acoustic port inspection channel functional test
PR-003 | PCB-PWR | ASM-PWR | - | PCBA | Contract manufacturer | TBD | 4-layer PCBA; outer 2 oz target; inner 1 oz target; final stackup pending DFM |  | COMMON | N/A | 4 | 1 | 5 | 10 | 1 | 11 | 20 | 2 | 22 | SCALE_CEIL_FROM_20_BASELINE | BLOCKED_SUPPLIER_RELEASE | RFQ_REQUIRED | Direct CM quotation | AOI functional high-current thermal
PR-004 | SYSTEM | HARNESS | - | Harness | TBD | TBD | Assembly |  | COMMON | FITTED | 4 | 1 | 5 | 10 | 1 | 11 | 20 | 2 | 22 | SCALE_CEIL_FROM_20_BASELINE | BLOCKED_SELECTION | OPEN_MECHANICAL_LENGTH_FREEZE | Qualified harness factory | 100 percent continuity polarity pull sample
PR-005 | SYSTEM | HSG-3D | HSG1 | Housing | TBD | TBD | Assembly |  | THREE_D_PRINT_FALLBACK | N/A | 0 | 0 | 0 | 0 | 0 | 0 | 0 | 0 | 0 | NONE | CONDITIONAL_NOT_RELEASED | SOURCE_PACKAGE_REQUIRED | Qualified print supplier or controlled FlashForge 5M Pro process | Engineering sample dimensions material finish leak fit acoustic and RF checks
PR-006 | SYSTEM | HSG-IM | HSG1 | Housing | TBD | TBD | Source_data |  | INJECTION_MOLDING_FUTURE | N/A | 0 | 0 | 0 | 0 | 0 | 0 | 0 | 0 | 0 | NONE | CONDITIONAL_NOT_RELEASED | SOURCE_PACKAGE_REQUIRED | Qualified mold manufacturer for DFM quotation | Source audit wall draft ribs bosses parting ejector shrink material and tooling concept
PR-007 | SYSTEM | HSG-VC | HSG1 | Housing | TBD | TBD | Assembly |  | VACUUM_CASTING_PRIMARY | N/A | 4 | 0 | 4 | 10 | 0 | 10 | 20 | 0 | 20 | NONE | CONDITIONAL_NOT_RELEASED | RFQ_REQUIRED | Qualified vacuum casting manufacturer | FAI dimensions material cure finish inserts leak fit acoustic and RF checks
PR-008 | PCB-MAIN | PCB-MAIN | - | Bare PCB | Qualified PCB fab | TBD | 6-layer FR-4 110x75x1.6 mm |  | COMMON | N/A | 4 | 1 | 5 | 10 | 3 | 13 | 20 | 5 | 25 | SCALE_CEIL_FROM_20_BASELINE | BLOCKED_SUPPLIER_RELEASE | RFQ_REQUIRED | Two independent fab quotations | Coupon dimensions finish stackup impedance and netlist test
PR-009 | PCB-MIC | PCB-MIC | - | Bare PCB | Qualified PCB fab | TBD | 2-layer FR-4 |  | COMMON | N/A | 16 | 4 | 20 | 40 | 10 | 50 | 80 | 20 | 100 | SCALE_CEIL_FROM_20_BASELINE | BLOCKED_SUPPLIER_RELEASE | RFQ_REQUIRED | Two independent fab quotations | Outline hole position finish netlist
PR-010 | PCB-PWR | PCB-PWR | - | Bare PCB | Qualified PCB fab | TBD | 4-layer FR-4; outer 2 oz target; inner 1 oz target; final stackup pending DFM |  | COMMON | N/A | 4 | 1 | 5 | 10 | 3 | 13 | 20 | 5 | 25 | SCALE_CEIL_FROM_20_BASELINE | BLOCKED_SUPPLIER_RELEASE | RFQ_REQUIRED | Two independent fab quotations | Copper thickness netlist high-current and Kelvin review
PR-011 | PCB-PWR | PWR-FUSE-01 | F1 | Protection | Littelfuse | 0451008.MRL | Nano2_451_6.1x2.69mm |  | COMMON | FITTED | 4 | 2 | 6 | 10 | 5 | 15 | 20 | 10 | 30 | SCALE_CEIL_FROM_20_BASELINE | BLOCKED_ENGINEERING_SELECTION | CANDIDATE_SELECTED_FOR_EVT_QUALIFICATION_NATIVE_VALUE_ECO_APPLIED_REPEAT_EVIDENCE_PENDING | Authorized distributor | Marking continuity and controlled fault clearing
PR-012 | PCB-MAIN | J-SIM1 | J-SIM2 | J6 | J7 | SIM | TE Connectivity | 2336582-1 | Nano-SIM 4FF connector with DET |  | COMMON | FITTED | 8 | 2 | 10 | 20 | 6 | 26 | 40 | 10 | 50 | SCALE_CEIL_FROM_20_BASELINE | CONTROLLED_PENDING_VERIFICATION | TECHNICALLY_SELECTED_PROCUREMENT_RISK | Approved connector vendor | Mating cycles card detect coplanarity and ESD
PR-013 | HARNESS-PWR-MAIN | H-PWR-MAIN | H_PWR_MAIN:A/B | Housing | Molex | 43025-1200 | Micro-Fit 3.0 12-circuit housing |  | COMMON | FITTED | 8 | 1 | 9 | 20 | 2 | 22 | 40 | 4 | 44 | SCALE_CEIL_FROM_20_BASELINE | CONTROLLED_PENDING_VERIFICATION | SELECTED_PENDING_MECHANICS_I2C_TEST | Authorized or traceable tier-1 channel | Marking MPN package orientation electrical functional sample
PR-014 | HARNESS-PWR-MAIN | T-PWR-MAIN-CTL | H_PWR_MAIN control contacts | Terminal | Molex | 43030-0001 | Micro-Fit female crimp terminal 20-24 AWG class |  | COMMON | FITTED | 48 | 3 | 51 | 120 | 6 | 126 | 240 | 12 | 252 | SCALE_CEIL_FROM_20_BASELINE | CONTROLLED_PENDING_VERIFICATION | SELECTED_PENDING_I2C_PULL_TEST | Authorized or traceable tier-1 channel | Marking MPN package orientation electrical functional sample
PR-015 | HARNESS-PWR-MAIN | T-PWR-MAIN-PWR | H_PWR_MAIN power contacts | Terminal | Molex | 43030-0038 | Micro-Fit female crimp terminal 18 AWG class |  | COMMON | FITTED | 48 | 3 | 51 | 120 | 6 | 126 | 240 | 12 | 252 | SCALE_CEIL_FROM_20_BASELINE | CONTROLLED_PENDING_VERIFICATION | SELECTED_PENDING_CURRENT_PULL_TEST | Authorized or traceable tier-1 channel | Marking MPN package orientation electrical functional sample
PR-016 | PCB-PWR | J-PWR-IN | J1 | Connector | Molex | 430450213 | 2 positions |  | COMMON | FITTED | 4 | 1 | 5 | 10 | 3 | 13 | 20 | 5 | 25 | SCALE_CEIL_FROM_20_BASELINE | CONTROLLED_PENDING_VERIFICATION | SELECTED_PENDING_MECHANICS | Authorized or traceable tier-1 channel | Marking MPN package orientation electrical functional sample
PR-017 | PCB-MAIN | PCB-PWR | J-PWR-MAIN | J-PWR-PWR | J2 | J_PWR | Connector | Molex | 430451202 | 12 positions |  | COMMON | FITTED | 8 | 2 | 10 | 20 | 6 | 26 | 40 | 10 | 50 | SCALE_CEIL_FROM_20_BASELINE | CONTROLLED_PENDING_VERIFICATION | MECHANICAL_AUTHORITY_FROZEN_PENDING_HARNESS_SI | SELECTED_ELECTRICAL_PENDING_MECHANICS | Authorized Molex distributor | Marking dimensions latch mate continuity
PR-018 | PCB-MAIN | J-TAMPER | J13 | Connector | Molex | 5040500291 | Pico-Lock 1.50 mm 2-circuit right-angle SMT |  | COMMON | FITTED | 4 | 1 | 5 | 10 | 3 | 13 | 20 | 5 | 25 | SCALE_CEIL_FROM_20_BASELINE | CONTROLLED_PENDING_VERIFICATION | MECHANICAL_AUTHORITY_FROZEN_PENDING_PHYSICAL_TEST | Authorized Molex distributor | Mating pull continuity cable-break and cover-open fault coverage
PR-019 | PCB-MAIN | PCB-MIC | J-MIC | J-MIC-MAIN | J_MIC1;J_MIC2;J_MIC3;J_MIC4 | PCB-MIC:J1 x4 | Connector | Molex | 5040500691 | Pico-Lock 1.50 mm 6-circuit right-angle SMT |  | COMMON | FITTED | 32 | 6 | 38 | 80 | 12 | 92 | 160 | 24 | 184 | SCALE_CEIL_FROM_20_BASELINE | CONTROLLED_PENDING_VERIFICATION | MECHANICAL_AUTHORITY_FROZEN_PENDING_SI_AAD | Authorized Molex distributor | Authorized or traceable tier-1 channel | Marking MPN package orientation electrical functional sample | Mating pull test contact resistance continuity and temperature
PR-020 | HARNESS-MIC | H-MIC | H_MIC1:A/B;H_MIC2:A/B;H_MIC3:A/B;H_MIC4:A/B | Housing | Molex | 5040510601 | Pico-Lock 1.50 mm 6-circuit housing |  | COMMON | FITTED | 32 | 4 | 36 | 80 | 8 | 88 | 160 | 16 | 176 | SCALE_CEIL_FROM_20_BASELINE | CONTROLLED_PENDING_VERIFICATION | SELECTED_PENDING_HARNESS_LENGTH_PULL_TEST | Authorized or traceable tier-1 channel | Marking MPN package orientation electrical functional sample
PR-021 | HARNESS-MIC | T-MIC | H_MIC1..H_MIC4 contacts | Terminal | Molex | 5040520098 | Pico-Lock crimp terminal 28-24 AWG |  | COMMON | FITTED | 192 | 48 | 240 | 480 | 48 | 528 | 960 | 48 | 1008 | FIXED_LOT_MIN | CONTROLLED_PENDING_VERIFICATION | SELECTED_PENDING_CRIMP_PULL_TEST | Authorized or traceable tier-1 channel | Marking MPN package orientation electrical functional sample
PR-022 | SYSTEM | ANT-GNSS | AE2 | Antenna | Taoglas | AA.166.A.301111 | IP67 magnetic 37.8x40.4x10 mm with 3 m RG174 SMA(M) |  | COMMON | FITTED | 4 | 1 | 5 | 10 | 1 | 11 | 20 | 2 | 22 | SCALE_CEIL_FROM_20_BASELINE | CONTROLLED_PENDING_VERIFICATION | SELECTED_EVT_CANDIDATE_PENDING_BIAS_SENSITIVITY_COEX_SAMPLE | Taoglas or authorized distributor with exact MPN traceability | Label connector cable length bias current gain noise figure S11 IP and temperature plus receiver sample
PR-023 | PCB-MAIN | MAIN-010-FL1 | FL1 | SAW_Filter | Abracon | ABSES5AF-L100KM | 1109-5 | 1582.4 MHz wideband GNSS SAW | COMMON | FITTED | 4 | 0 | 4 | 10 | 0 | 10 | 20 | 0 | 20 | NONE | CONTROLLED_PENDING_VERIFICATION | SELECTED_PENDING_REVIEW_A | Authorized or traceable tier-1 channel | Marking MPN package orientation electrical functional sample
PR-024 | PCB-MAIN | U8 | U8 | Cellular | Quectel | BG95-M3 | LGA-102_23.6x19.9mm |  | COMMON | FITTED | 4 | 1 | 5 | 10 | 3 | 13 | 20 | 5 | 25 | SCALE_CEIL_FROM_20_BASELINE | CONTROLLED_PENDING_VERIFICATION | SELECTED_PENDING_INCOMING_ID_AND_POST_ASSEMBLY_EVT | Quectel authorized channel or CM with traceability | IMEI label firmware RF conducted attach TLS
PR-025 | PCB-MAIN | MAIN-010-FB1 | FB1 | Ferrite_Bead | Murata | BLM31KN601SN1L | 1206 | 600 Ohm at 100 MHz | COMMON | FITTED | 4 | 0 | 4 | 10 | 0 | 10 | 20 | 0 | 20 | NONE | CONTROLLED_PENDING_VERIFICATION | SELECTED_PENDING_REVIEW_A | Authorized or traceable tier-1 channel | Marking MPN package orientation electrical functional sample
PR-026 | SYSTEM | RF-PIGTAIL | J8/J9/J10 cable | RF cable | Taoglas | CAB.0243 | 1.13 mm micro-coax 150 mm MHF I/U.FL-compatible R/A to waterproof SMA(F) bulkhead |  | COMMON | FITTED | 12 | 2 | 14 | 30 | 3 | 33 | 60 | 6 | 66 | SCALE_CEIL_FROM_20_BASELINE | CONTROLLED_PENDING_VERIFICATION | SELECTED_EVT_CANDIDATE_PENDING_MATE_ROUTE_SEAL_VSWR_SAMPLE | Taoglas or authorized distributor with exact MPN traceability | 100 percent identity continuity polarity length and connector inspection plus sample mate retention VNA bend seal and temperature test
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

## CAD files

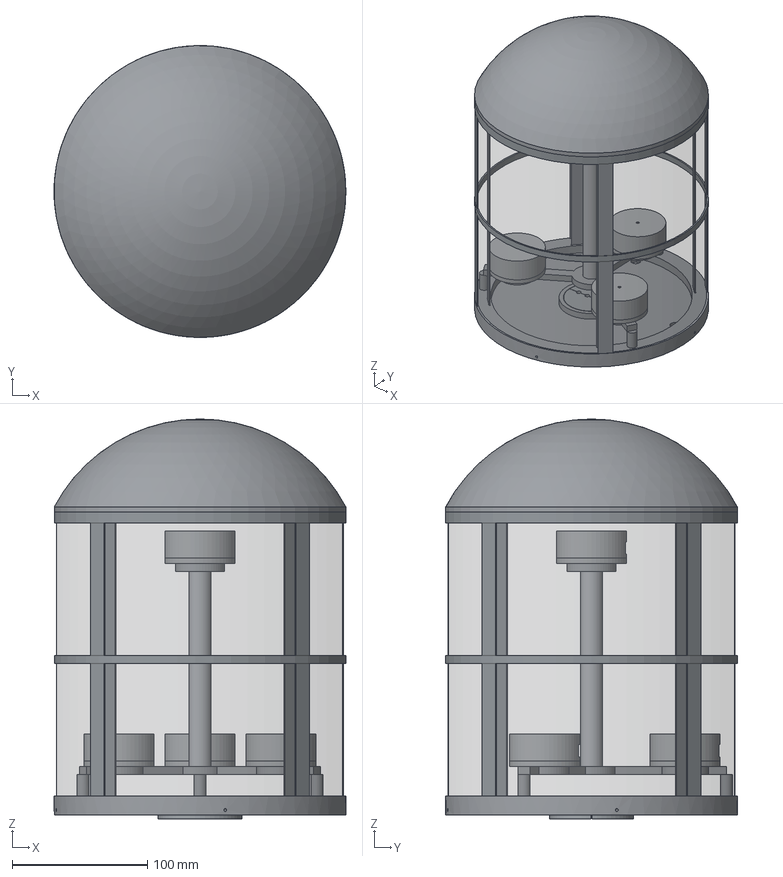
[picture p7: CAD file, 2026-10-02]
releases/evt-pre-20/2026-10-02-rev-d5/Основной_пакет/03_Корпуса_для_3D_печати_ПРЕДВАРИТЕЛЬНО/Акустическая_голова_3плюс1/DIO-3DP-AH-001C_full_fit_assembly.step
215.9 x 216.0 x 296.0 mm
SEALED_LOWER_FLOOR_AND_TRIANGLE
SPLIT_CABLE_HATCH_NORTH_SEAL_REQUIRED
SPLIT_CABLE_HATCH_SOUTH_SEAL_REQUIRED
CENTRAL_MAST
UPPER_CARRIER
ONE_PIECE_UPPER_RING_AND_EIGHT_PLATES
FOAM_ENVELOPE_ONLY
HIGHER_DOME
MIC1_BODY
MIC1_LID
MIC2_BODY
MIC2_LID
MIC3_BODY
MIC3_LID
MIC4_BODY
MIC4_LID

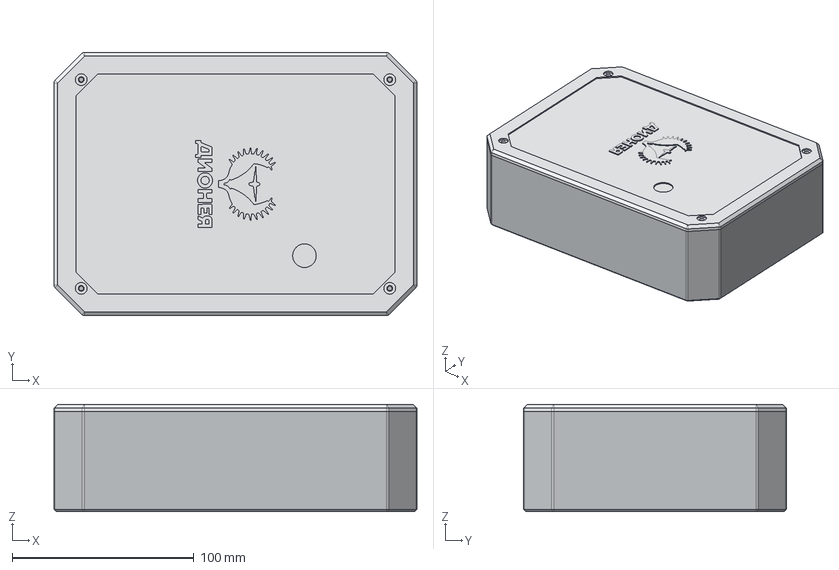
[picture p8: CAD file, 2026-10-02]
releases/evt-pre-20/2026-10-02-rev-d5/Основной_пакет/04_Литье_исходные_данные_ПРЕДВАРИТЕЛЬНО/Вакуумное_литье/Верхний_электронный_модуль/DIO-3DP-UP-001B_fit_assembly.step
200.0 x 145.0 x 59.0 mm
FACETED_HOUSING_BODY
BEVELLED_FRONT_LID
PCB_MAIN_ALLOCATION_NO_COMPONENT_HEIGHT

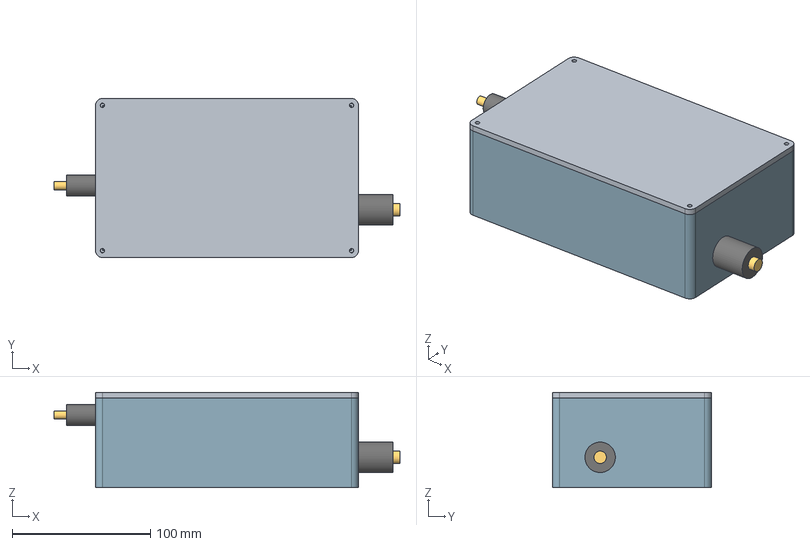
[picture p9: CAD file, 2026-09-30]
releases/evt-pre-20/2026-10-02-rev-d5/Основной_пакет/03_Корпуса_для_3D_печати_ПРЕДВАРИТЕЛЬНО/Кассета_питания_RevB/PCB_PWR_3D_PRINT_HARNESS_EXITS_REV_B_assembly.step
250.0 x 115.0 x 69.0 mm
CASE_BODY_PORTED
CASE_LID
DIM003_BOARD_WITH_HOLES
J1_PLUG_ENVELOPE_NOT_VENDOR_CAD
J2_PLUG_ENVELOPE_NOT_VENDOR_CAD
J1_CABLE_R20_PROXY
J2_CABLE_R45_PROXY
J1_GLAND_CAP_PROXY
J1_GLAND_THREAD_PROXY
J1_LOCKNUT_PROXY
J2_GLAND_CAP_PROXY
J2_GLAND_THREAD_PROXY
J2_LOCKNUT_PROXY

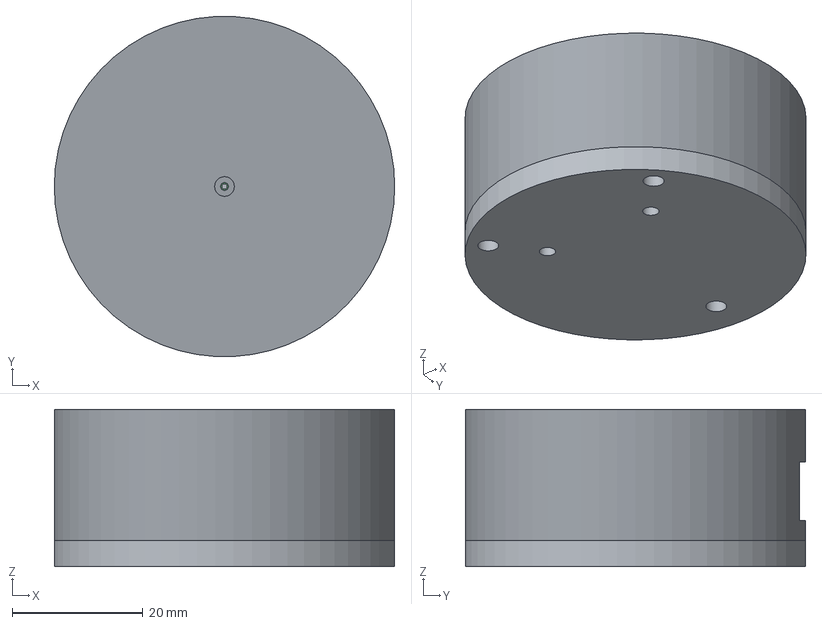
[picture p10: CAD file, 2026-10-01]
releases/evt-pre-20/2026-10-02-rev-d5/Основной_пакет/04_Литье_исходные_данные_ПРЕДВАРИТЕЛЬНО/Литье_под_давлением/Микрофонный_модуль/DIO-IM-MC-001B_fit_assembly.step
52.0 x 51.9 x 24.0 mm
CYLINDRICAL_BODY_ACOUSTIC_FACE_UP
LOWER_LID
PCB_MIC_REV_B_ALLOCATION_ONLY

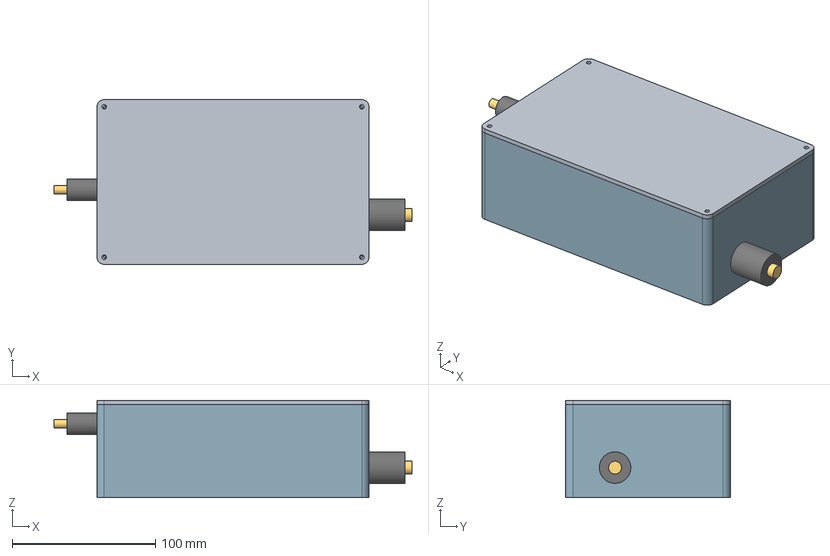
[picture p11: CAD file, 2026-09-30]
releases/evt-pre-20/2026-10-02-rev-d5/Сборка_и_корпуса/04_Литье_исходные_данные_ПРЕДВАРИТЕЛЬНО/Литье_под_давлением/Кассета_питания_RevB/PCB_PWR_INJECTION_MOLDING_HARNESS_EXITS_REV_B_assembly.step
250.0 x 115.0 x 68.0 mm
CASE_BODY_PORTED
CASE_LID
DIM003_BOARD_WITH_HOLES
J1_PLUG_ENVELOPE_NOT_VENDOR_CAD
J2_PLUG_ENVELOPE_NOT_VENDOR_CAD
J1_CABLE_R20_PROXY
J2_CABLE_R45_PROXY
J1_GLAND_CAP_PROXY
J1_GLAND_THREAD_PROXY
J1_LOCKNUT_PROXY
J2_GLAND_CAP_PROXY
J2_GLAND_THREAD_PROXY
J2_LOCKNUT_PROXY

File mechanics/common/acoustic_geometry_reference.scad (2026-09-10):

// Dioneya EVT-PRE-20 geometry reference only.
// Not a production part. Units are millimetres.

triangle_side = 120;
upper_offset = 150;
marker_diameter = 10;
marker_height = 4;
strut_diameter = 4;

circumradius = triangle_side / sqrt(3);

mic1 = [0, circumradius, 0];
mic2 = [-triangle_side / 2, -circumradius / 2, 0];
mic3 = [triangle_side / 2, -circumradius / 2, 0];
mic4 = [0, 0, upper_offset];

module marker(position, label_text) {
    translate(position) {
        cylinder(d = marker_diameter, h = marker_height, center = true, $fn = 48);
        translate([0, 0, marker_height]) linear_extrude(0.6)
            text(label_text, size = 4, halign = "center", valign = "center");
    }
}

module strut(a, b, diameter = strut_diameter) {
    hull() {
        translate(a) sphere(d = diameter, $fn = 24);
        translate(b) sphere(d = diameter, $fn = 24);
    }
}

strut(mic1, mic2);
strut(mic2, mic3);
strut(mic3, mic1);
strut([0, 0, 0], mic4);

marker(mic1, "MIC1");
marker(mic2, "MIC2");
marker(mic3, "MIC3");
marker(mic4, "MIC4");

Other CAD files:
releases/evt-pre-20/2026-10-02-rev-d5/Сборка_и_корпуса/04_Литье_исходные_данные_ПРЕДВАРИТЕЛЬНО/Вакуумное_литье/Кассета_питания_RevB/PCB_PWR_VACUUM_CASTING_HARNESS_EXITS_REV_B_assembly.step
releases/evt-pre-20/2026-10-02-rev-d5/Основной_пакет/04_Литье_исходные_данные_ПРЕДВАРИТЕЛЬНО/Вакуумное_литье/Кассета_питания_RevB/PCB_PWR_VACUUM_CASTING_HARNESS_EXITS_REV_B_assembly.step
releases/evt-pre-20/2026-10-02-rev-d5/Заказ_плат_и_монтаж/02_PCB_MIC_управляемый_заказ_и_монтаж/03_Исходники_и_контроль/PCB-MIC_board.step
releases/evt-pre-20/2026-10-02-rev-d5/Основной_пакет/03_Корпуса_для_3D_печати_ПРЕДВАРИТЕЛЬНО/Акустическая_голова_3плюс1/DIO-3DP-AH-001C_cable_hatch_north.step
releases/evt-pre-20/2026-10-02-rev-d5/Основной_пакет/03_Корпуса_для_3D_печати_ПРЕДВАРИТЕЛЬНО/Акустическая_голова_3плюс1/DIO-3DP-AH-001C_cable_hatch_north.stl
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

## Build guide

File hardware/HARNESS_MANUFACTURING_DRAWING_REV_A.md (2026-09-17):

# Дионея EVT-PRE-20 Rev.A — предварительный производственный чертёж жгутов

Статус: `CONTROLLED PRELIMINARY / LENGTHS AND EXTERNAL ENDS OPEN / NOT FOR BUILD`

Дата: 2026-09-15

## 1. Назначение и authority

Документ переводит замороженный логический pinout в проверяемую производственную
раскладку проводов. Машинный чертёж —
`hardware/HARNESS_MANUFACTURING_SCHEDULE_REV_A.csv`. Электрические имена и порядок
контактов задаёт `hardware/HARNESS_LOGICAL_PINOUT_REV_A.csv`, а разъёмы и mating
parts — `hardware/CONNECTOR_FREEZE_REV_A.csv`.

Этот пакет не разрешает изготовление жгутов: неизвестные длины, точные MPN проводов,
внешние окончания и параметры утверждённого обжимного процесса сохранены как
блокеры, а не заполнены предположениями.

## 2. Состав контролируемой раскладки

| Жгут | Количество на станцию | Цепей | Контролируемые окончания | Открыто |
|---|---:|---:|---|---|
| H-MIC1…H-MIC4 | по 1 | 6 каждый | два 5040510601; контакты 5040520098 | длина, SI/AAD, strain relief |
| H-MAIN-PWR | 1 | 12 | два 430251200; силовые 430300038, сигнальные 430300001 | длина, падение, нагрев, I²C |
| H-BAT-PWR | 1 | 2 | сторона PCB-PWR 430250200/430300038 | RELiON RB40 M8 interface selected; exact ring terminal, предохранитель и длина открыты |

Пять внутренних жгутов имеют прямую распайку cavity-to-same-cavity. Перестановки,
скрутки контактов в корпусе, общие splice и разветвления не допускаются. Цвет,
калибр, маркировка конца и правило укладки заданы для каждого проводника в CSV.

## 3. Требования к изготовлению

1. Провод многожильный, не ниже 105 °C; точная серия и MPN утверждаются через BOM/AVL.
2. Зачистка, crimp height, pull-force и оснастка — только по актуальной инструкции
   производителя контакта и квалифицированному crimp-процессу сборщика.
3. Контакты должны быть полностью посажены и удерживаться secondary lock/latch
   конструкцией корпуса; повреждение изоляции, жил или защёлки запрещено.
4. На обоих концах ставится стойкая маркировка из столбца `End_Label`; MIC1…MIC4
   нельзя взаимозаменять после маркировки.
5. Длины H-MIC1…H-MIC4 замораживаются после трассы в корпусе. Электрическая
   симметрия и допустимый skew подтверждаются измерением, а не только равной
   нарезкой проводов.
6. H-MAIN-PWR прокладывается вдали от switch nodes и RF. Пары питание/возврат
   сохраняются рядом; I2C2_SCL/SDA остаются короткими и проверяются по ёмкости и
   времени нарастания на реальном жгуте.

## 4. Контроль 100 %

- point-to-point continuity каждой цепи по `Harness_ID` и `Conductor_ID`;
- отсутствие cross-short между любыми контактами и с экраном/корпусом, если он
  появится после механического freeze;
- полярность H-BAT-PWR и отсутствие перестановки силовых возвратов;
- визуальный контроль посадки, защёлок, маркировки, повреждения изоляции и обжима;
- запись номера партии провода, контактов, оператора, оснастки и результата теста;
- выборочный pull-test и сечение обжима по утверждённому плану процесса сборщика.

## 5. Внешние ветви вне текущего freeze

До выбора SKU/механики не выпущены: panel-to-MPPT, MPPT/BMS-to-battery,
cellular/GNSS/LoRa coax, tamper switch и внешние вводы. Их MPN, длины, экраны,
гермовводы, радиусы изгиба и климатические исполнения остаются блокерами
`DIM-005…DIM-010`, BOM QG-2 и supplier RFQ.

## 6. Запрос изготовителю

Пакет `hardware/reviews/HARNESS_SUPPLIER_CAPABILITY_REQUEST_REV_A.md` и пустой
16-строчный реестр ответов переводят выбор площадки, supplier assembly MPN,
температурный рейтинг, wire AVL и crimp-процесс в атрибутируемый внешний запрос.
На исходном состоянии принято `0/16` строк. Пакет не разрешает поставщику
подставлять численные длины вместо `TBD_DIM-*` и не является build authorization.

## 7. Release gate

Для QG-2 требуются замороженные cut lengths и допуски, точные wire MPN,
квалифицированные crimp tooling/height/pull limits, закрытые внешние окончания,
проверки падения напряжения/нагрева, PDM/AAD/I²C signal integrity, strain relief и
100 % continuity records на выбранном EVT-лоте. До этого состояние — `HOLD`.

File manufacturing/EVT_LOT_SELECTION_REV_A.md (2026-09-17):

# EVT lot selection control — Rev.A

`EVT-PRE-20` reserves traceable serial capacity through `DIO-EVT-020`. The
customer-selected procurement scenario is `EVT-20`: 20 stations using serials
`DIO-EVT-001` through `DIO-EVT-020`. The 4- and 10-station columns remain
controlled comparison and contingency calculations only.

The selected scenario controls the corresponding `Qty_N`, `Spares_N` and
`Procure_qty_N` columns in `hardware/EVT_PRE_20_BOM_REV_A.csv` and the matching
`Required_qty_N` column in `hardware/CHINA_PROCUREMENT_RFQ.csv`. Mixing columns
from different scenarios is prohibited.

All 20 reserved serials are assigned to the selected EVT lot and remain in
`AWAITING_BUILD` state until the hardware purchase gate passes. Every assembled
station receives 100 percent EOL and every applicable all-unit EVT test.

Vacuum casting is the primary housing process for every selected-lot station.
The equal-quantity 3D-print fallback remains zero in procurement until its
separate approval. Injection molding remains source-data and DFM only, with no
pilot tooling or molded-part quantity.

Selection is `SELECTED: EVT-20`. Comparable RFQs may still be collected for 4,
10 and 20 stations, but only `Procure_qty_20` and `Required_qty_20` are eligible
for the selected-lot purchase package. Selection does not authorize purchasing:
strict BOM QG-2, released PCB/mechanical data and supplier evidence remain
blocking.

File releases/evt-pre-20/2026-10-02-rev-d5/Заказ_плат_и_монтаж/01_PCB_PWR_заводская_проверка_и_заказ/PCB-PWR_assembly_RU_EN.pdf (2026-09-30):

# PCB-PWR Rev E - сборочный чертёж / Assembly drawing

Плата Rev A · EVT-PRE-20 · 29.09.2026 / Board Rev A · customer-authorized fab order with DFM checkout

### Условные обозначения / Legend

Синий - позиционное обозначение; красное зачёркивание - DNP; зелёный NT1-NT3 - медная перемычка; оранжевое кольцо - pad 1. / Blue - reference; red strike - DNP; green NT1-NT3 - copper net tie; orange ring - pad 1.

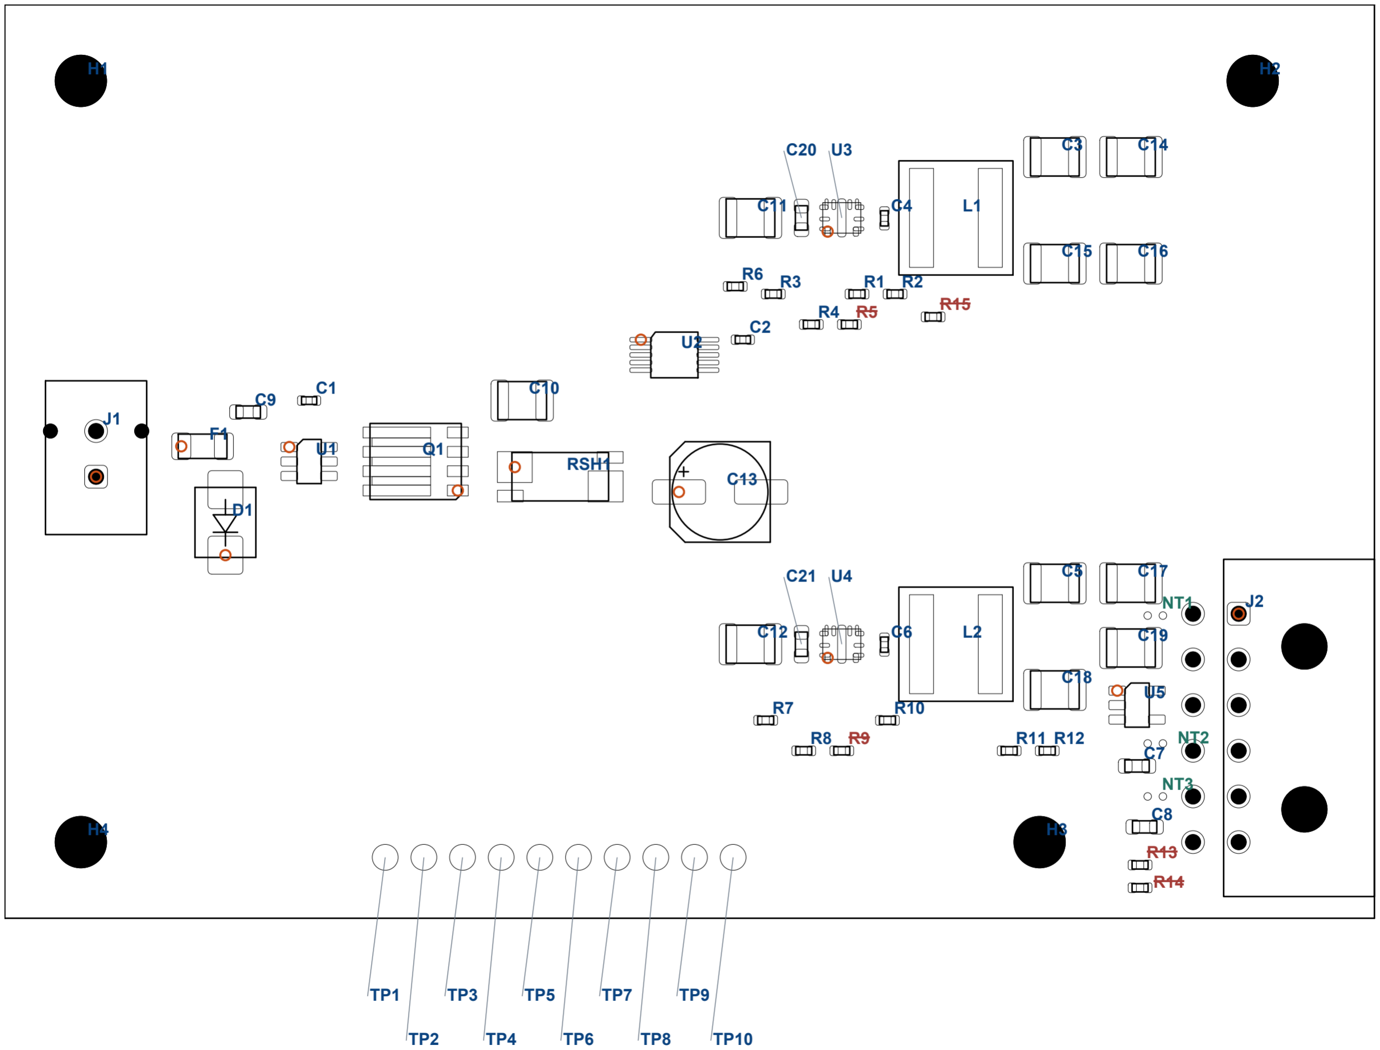
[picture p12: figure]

### Не устанавливать / Do not fit

R5, R9, R13, R14, R15. NT1-NT3 не являются отдельными компонентами. / NT1-NT3 are copper only, no separate parts.

### Полярность / Polarity

C13: плюс на pad 1 (VBAT_SYS). D1: катод на pad 1 (VBAT_FUSED). / C13 positive is pad 1; D1 cathode is pad 1.

### Разъёмы / Connectors

J1 сопряжение +Z; J2 сопряжение +X к восточному краю. / J1 mates +Z; J2 mates +X toward the east edge.

### Плата / Board

90 × 60 × 1,6 мм; четыре слоя, 4 × 35 мкм проектный номинал, ENIG. / 90 × 60 × 1.6 mm; four layers, 4 × 35 µm nominal design copper, ENIG.

### Заводская проверка / Fabricator review

ID стека, толщины, медь, сверловку и DFM подтвердить в заказе. / Confirm stack ID, dielectrics, copper, drilling and DFM in the order.

### Механика / Mechanics

DIM-003 Rev B и модели корпуса предварительные; проверить J1/J2 и примерку первого изделия. / DIM-003 Rev B and housing models are preliminary; verify J1/J2 and first-article fit.

### Решение заказчика / Customer decision

Заказ на фабрику разрешён с обработкой замечаний через ECO. Монтажная и функциональная приёмка остаются по первому образцу. / Fab order is authorized; process comments through ECO. Assembly and functional acceptance follow the first article.

Контрольная плата / Controlled board SHA-256: de2a723bbbc0d37b9f4fc5f55e24bfa287f892a081925daf4a24b8a7fa6c901d

Геометрия и обозначения взяты из исходного листа Rev E; текст статуса актуализирован для заказа. / Geometry and refs follow Rev E; order status is updated here.

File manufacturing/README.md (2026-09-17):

# EVT-PRE-20 - производство партии

Статус: `DRAFT / NOT RUN`

Каталог задаёт управляемый маршрут выпуска выбранного лота из 4, 10 или 20 предсерийных станций при резерве серийных номеров на 20. Он не подтверждает изготовление, программирование или испытания.

## Правило выпуска

Каждое изделие проходит четыре независимых уровня:

1. входной контроль компонентов, PCB, PCBA, батареи, MPPT, антенн и механики;
2. сборку по индивидуальному traveller с фиксацией исполнителя и evidence;
3. доверенное provisioning уникальных идентификаторов и ключей;
4. 100% EOL с привязкой результатов к серийному номеру.

После EOL партия переходит в EVT по `tests/EVT_MASTER_PLAN.md`. Наличие записи без первичного evidence не считается выполненной операцией.

## Серийные номера

Выбран сценарий `EVT-20`: диапазон `DIO-EVT-001` - `DIO-EVT-020` назначен партии полностью. Расчёты `EVT-4` и `EVT-10` остаются справочными и не могут использоваться для заказа без нового решения и пересборки release baseline. Печатные платы, корпусные детали, батарея, MPPT, SIM, антенны и firmware release связываются с назначенным серийным номером в `LOT_SERIAL_REGISTER.csv`. План технологии корпуса дублируется в `HOUSING_LOT_PLAN.csv` для отдельного контроля закупки.

Распределение LoRa зафиксировано заказчиком: каждое изделие выбранного лота использует профиль RU868 с окнами 864-865 и 868,7-869,2 МГц. Профиль EU868 остаётся отключённым шаблоном будущей совместимости и в пилот не прошивается.

Каждое изделие имеет два физических nano-SIM слота, но одновременно активна только одна SIM. В traveller и паспорте фиксируются обе ссылки ICCID, выбранный слот и APN mode. Замена или переключение карты без штатного выключения BG95 запрещены.

Для пилота разрешён только `PUBLIC` APN mode. Тариф не является критерием EVT. В паспорте фиксируются точный публичный APN и hash профиля каждой установленной SIM.

Все 20 серийных номеров резервируют возможность корпуса вакуумного литья, но закупается только выбранное количество 4, 10 или 20. Если вакуумное литьё невозможно по сроку или качеству, перевод выбранного лота на 3D-печать выполняется только через утверждённое изменение. ТПА входит в объём исходных данных и DFM, но не в физическое изготовление пилотной партии.

## Запрещено

- передавать контрактному производителю production root keys;
- хранить private keys, PIN/PUK, APN passwords и реальные provisioning bundles в Git;
- принимать замену MPN без ECN и повторной проверки;
- ставить статус PASS вручную без ссылки на измерение, лог, фото или отчёт;
- включать LoRa TX до утверждения регионального профиля и RF-проверки;
- отгружать батареи без транспортных документов, применимых к выбранному SKU и маршруту.

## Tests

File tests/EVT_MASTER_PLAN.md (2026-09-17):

# EVT master plan - партия 20 изделий

Статус: `DRAFT / NOT RUN`

## Цель

Подтвердить предсерийную конфигурацию `EVT-PRE-20` на фактически собранных изделиях. EVT не заменяет 100% EOL. Серверный replay, host build и тест макета EVT-MB не являются hardware evidence этой партии.

## Популяция

- все 20 изделий: идентификация, визуальный контроль, EOL, питание S0-S4, четыре аудиоканала, GNSS/PPS, BLE, LTE attach/TLS/store-and-forward и базовый LoRa test;
- все 20 изделий испытываются с заблокированным профилем RU868; EU868 в пилот не прошивается и остаётся будущим TX-disabled шаблоном;
- корпусные технологии имеют раздельные отчёты и не объединяются в один PASS;
- разрушительные и длительные тесты назначаются после freeze корпуса и customer usage profile;
- образец, использованный в разрушительном тесте, не возвращается в обычный полевой пул без disposition.

## Последовательность

1. Freeze requirements, schematic, PCB, BOM/AVL, firmware, protocols, mechanics and test limits.
2. QG-1 complete release bundle and independent hash verification.
3. Incoming inspection and build of golden/instrumented units.
4. Fixture MSA and pilot build review.
5. Build remaining units with 100% traveller and EOL.
6. Baseline functional EVT for every assembled station in the selected 4, 10 or 20-unit lot.
7. Environmental, ingress, RF, energy and field tests by approved allocation.
8. Repeat critical functional checks after every stress.
9. Close deviations, publish raw evidence manifest and review configuration consistency.

## Решения о результате

- `PASS`: все P0 requirements verified, no open blocker/critical deviation, primary evidence available and hashes match.
- `CONDITIONAL`: only customer-accepted non-safety deviations with owner and closure date.
- `FAIL`: any safety, power, sealing, secure update, identity, protocol integrity or required performance criterion fails.
- `NOT RUN`: no primary evidence or test not started.

## Открытые входы

Exact site, public APN and RAT values for the selected SIMs, station deployment spacing, acoustic target set and negative set, environmental ranges, mast/wind conditions, transport route and acceptance thresholds must be frozen before QG-2. Tariff is not an EVT input. The procurement/EVT lot is selected from 4, 10 or 20 before purchase release. Every selected-lot unit uses RU868 and a vacuum-cast housing; equal-quantity 3D printing is the controlled fallback and injection molding is source-data-only for the pilot.

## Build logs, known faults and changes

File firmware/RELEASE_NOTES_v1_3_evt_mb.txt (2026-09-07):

Дионея firmware core 1.2.0 EVT-MB

Принятая цель: WeAct STM32U585CIU6.
Аудио: 4 синхронных I2S-канала, SAI1_A master RX + SAI1_B synchronous slave RX,
32 кГц, 32-битные слоты, полезные 24 бита. PA8=BCLK, PA9=WS,
PA10=DATA_A (MIC1/2), PB5=DATA_B (MIC3/4).
Архив: microSD SPI, CS PA4. BG95: USART1 без RTS/CTS, AT+IFC=0.

Host core и encoder можно проверить CMake/CTest. Полная target-прошивка считается
собранной только после создания проекта STM32CubeIDE по инструкции ИНС-01 и привязки
HAL/DMA callback к API zs_audio_i2s. Готовый .bin в этот релиз не включён, потому что
физическая конфигурация CubeMX ещё не прошла аппаратный gate.

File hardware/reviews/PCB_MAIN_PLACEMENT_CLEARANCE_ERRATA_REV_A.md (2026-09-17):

# PCB-MAIN Rev.A placement-clearance errata

Status: `2D PLACEMENT CLEARANCE PASS / ROUTING AND 3D REVIEW PENDING / NOT FOR MANUFACTURE`

Discovery date: 2026-09-15
Inspected commit: `989ce217d44795ba2986453d1f37152af5a8e1fc`
PCB SHA-256: `aa35fe622b6a0761b9b25ae488e1a2c6e7160c285ab771b580f63513b83e4a22`
MAIN-AUTH-011 CSV SHA-256: `2ea8da3b8469f616c469eb342127afd2e75b3b0ad04f3ab75154560211f353c9`

This record preserves a defect discovered after the signed PCB-MAIN electrical
Review A and records its bounded 2D closure. It does not alter the signed
schematic conclusion. The limited mechanical ECO and full deterministic repack
were applied on 2026-09-15. The strict 2D clearance subgate now passes; routing,
3D/service review and Review B remain open.

## Independent method

`tools/audit_pcb_main_placement_clearance_rev_a.py` parses the committed native
board with `kiutils==1.4.8` and evaluates same-side assembly envelopes after the
footprint rotation and translation are applied.

- A controlled `F.CrtYd`/`B.CrtYd` rectangle is a confirmed assembly envelope.
- A footprint without a courtyard is screened with the union of its pad bounds
  expanded by 0.25 mm. These conservative findings are not represented as exact
  body/courtyard geometry.
- Positive overlap must exceed 0.02 mm on both axes to be reported.
- The MAIN-AUTH-011 10.0 mm component-exclusion diameter around H1-H4 is checked
  against the same envelopes.
- Each `TOOL_D8_Z15` U.FL rule is checked as a 4.0 mm-radius, 15.0 mm-high
  top-side service cylinder against every other fitted assembly envelope. The cylinder may open
  beyond a service edge, but it may not intersect a component courtyard/body.
- Bottom production pogo footprints are fixture contacts, not assembled bodies,
  and are excluded from component-collision counts.

The current board uses orthogonal footprint rotations and rectangular courtyard
boundaries, so each reported courtyard/courtyard overlap below is an exact
axis-aligned overlap after transformation. KiCad DRC and a final 3D/service-volume
inspection remain mandatory and are not replaced by this audit.

## Controlled pre-ECO result

| Item | Count | Disposition |
|---|---:|---|
| Fitted assembly footprints | 227 | Audited |
| Footprints with controlled courtyard | 58 | Exact rectangular-envelope check |
| Footprints using pad-envelope screening | 169 | Courtyard/body control still required |
| Confirmed component collisions | 17 | Placement blocker |
| Screening component collisions | 67 | Rework or exact courtyard required |
| Confirmed mounting-exclusion conflicts | 2 | Placement blocker |
| Screening mounting-exclusion conflicts | 1 | Rework or exact courtyard required |
| Confirmed U.FL tool-clearance conflicts | 2 | Locked service-volume blocker |
| Screening U.FL tool-clearance conflicts | 0 | None |

Confirmed courtyard/courtyard collisions:

| Pair | Overlap X, mm | Overlap Y, mm | Overlap area, mm² | Authority disposition |
|---|---:|---:|---:|---|
| C36 / J12 | 7.885 | 5.100 | 40.214 | Move unlocked placement |
| C36 / U24 | 1.900 | 3.000 | 5.700 | Move unlocked placement |
| C44 / J6 | 2.910 | 0.900 | 2.619 | Move unlocked placement |
| C44 / U14 | 3.100 | 2.200 | 6.820 | Move unlocked placement |
| D4 / U15 | 1.530 | 0.150 | 0.230 | Move unlocked placement |
| D4 / U21 | 1.330 | 0.750 | 0.998 | Move unlocked placement |
| D6 / U22 | 1.530 | 0.750 | 1.147 | Move unlocked placement |
| J12 / U23 | 1.900 | 3.000 | 5.700 | Move unlocked placement |
| J12 / U24 | 1.900 | 3.000 | 5.700 | Move unlocked placement |
| J8 / U8 | 4.100 | 2.050 | 8.405 | `MAIN-AUTH-011` conflict, limited ECO required |
| J_MIC1 / J_PWR | 7.620 | 9.560 | 72.847 | `MAIN-AUTH-011` conflict, limited ECO required |
| J_PWR / Q2 | 0.920 | 3.300 | 3.036 | Move unlocked placement |
| Q2 / Q3 | 0.200 | 3.300 | 0.660 | Move unlocked placement |
| U1 / U6 | 4.200 | 3.380 | 14.196 | Move unlocked placement |
| U1 / U7 | 3.500 | 4.750 | 16.625 | Move unlocked placement |
| U16 / U8 | 5.850 | 8.300 | 48.555 | Move unlocked placement |
| U18 / U7 | 2.660 | 0.200 | 0.532 | Move unlocked placement |

Confirmed mounting-hole conflicts:

| Hole / component | Required radius, mm | Nearest courtyard distance, mm | Deficit, mm | Authority disposition |
|---|---:|---:|---:|---|
| H1 / J_PWR | 5.000 | 3.920 | 1.080 | `MAIN-AUTH-011` conflict, limited ECO required |
| H2 / J13 | 5.000 | 3.909 | 1.091 | `MAIN-AUTH-011` conflict, limited ECO required |

The pad-envelope screening also finds H1/C1 with a 0.112 mm apparent deficit.
That finding is controlled as placement rework or courtyard completion, not as a
new authority conflict.

Confirmed U.FL D8 tool-cylinder conflicts:

| Tool / component | Required radius, mm | Nearest courtyard distance, mm | Deficit, mm | Authority disposition |
|---|---:|---:|---:|---|
| J8 / U8 | 4.000 | 0.200 | 3.800 | `MAIN-AUTH-011` conflict, limited ECO required |
| J10 / U10 | 4.000 | 2.750 | 1.250 | `MAIN-AUTH-011` conflict, limited ECO required |

## ECO application and post-ECO inventory

Reviewer `Скиф` accepted proposal `PCB-MAIN-MECH-ECO-001` on 2026-09-15 with
decision `ACCEPT_LIMITED_MECHANICAL_ECO`, bound to commit
`61cbe796de2f87560342a44b063ff6283a8ce1e8` and candidate SHA-256
`5ef7d0390da97796febbef6a69f0206a06efe00782e238bf7c8f32bf29d08fc1`.
The candidate remains immutable and its separate approval record is
`PCB_MAIN_MECHANICAL_ECO_APPROVAL_REV_A.json`.

The nine accepted MAIN-AUTH-011 record changes and six corresponding native-PCB
anchor translations were applied first. Their immutable application hashes are:

- PCB SHA-256: `8de8ac2eedc00775853a26641931ded8873cf5c1d9f61e7358d0546fea9dc379`
- MAIN-AUTH-011 CSV SHA-256: `6a28821413fb631d299574e0a86fd87be4fa2b20606b60947700fc6e37ab3e44`

The machine-readable application record is
`PCB_MAIN_MECHANICAL_ECO_APPLICATION_REV_A.json`.

GitHub App transport reproduced the reviewed local commit tree exactly as
remote commit `e265d1f1a0a74f94b9c887e12794a9b59fc2bfa0`. Both commits have tree
SHA `f1fd423bbcfedefa830677ce2d8b3c54b2294caa` and candidate blob SHA
`b3dede3b466676bbab4e3bd737160cacfc57ad28`. The machine-audited mapping is
`PCB_MAIN_MECHANICAL_ECO_REVIEW_COMMIT_MAPPING_REV_A.json`.

The immediate post-ECO audit reported no locked component, mounting or U.FL
tool-cylinder conflicts, but still recorded 15 confirmed component collisions,
67 pad-envelope screening collisions and one pad-envelope mounting-screening
finding in the unlocked placement scope. That inventory is retained in
`PCB_MAIN_MECHANICAL_ECO_APPLICATION_REV_A.json` as historical application
evidence.

## Controlled post-repack result

`hardware/PCB_MAIN_PLACEMENT_REPACK_REV_A.csv` fixes all 225 movable top-side
references on a 0.25 mm grid by functional group while leaving the 17
MAIN-AUTH-011 connector/module anchors unchanged. Non-owner movable footprints
are excluded from the locked CELL, GNSS, LoRa, BLE-body and audio allocations,
and every movable footprint stays outside the BLE all-layer antenna keepout.
The five generic passive packages receive the controlled rule in
`hardware/PCB_MAIN_PASSIVE_COURTYARD_RULE_REV_A.md`: 184 explicit courtyards,
including 169 fitted and 15 DNP footprints.

| Item | Count | Disposition |
|---|---:|---|
| Fitted assembly footprints | 227 | Audited |
| Footprints with controlled courtyard | 227 | Strict 2D check |
| Footprints using pad-envelope screening | 0 | Closed |
| Confirmed component collisions | 0 | PASS |
| Screening component collisions | 0 | PASS |
| Confirmed/screening mounting conflicts | 0 / 0 | PASS |
| Confirmed/screening U.FL tool conflicts | 0 / 0 | PASS |

Controlled hashes:

- native PCB SHA-256: `855fb727cdddddedeec4fcb630fbe30321900e2108648710be696070742c111d`
- placement manifest SHA-256: `0fe702d03af4457a3d44aae93ea6ddc539040f38546d4b09f200612627890e35`
- MAIN-AUTH-011 CSV SHA-256: `6a28821413fb631d299574e0a86fd87be4fa2b20606b60947700fc6e37ab3e44`

The two independent controls now pass on the same source state:

1. `python tools/audit_pcb_main_layout_candidate_rev_a.py`
2. `python tools/audit_pcb_main_placement_clearance_rev_a.py --strict`

## Remaining release boundary

The 2D placement-clearance subgate is closed. The board still has no routing or
copper zones, and the 2D envelope method cannot approve component height,
connector mates, cards, coax access or harness sweeps. The following remain
mandatory:

1. electrically and RF-constrained routing, return planes, stitching and stackup;
2. KiCad 9 DRC with zero blocker/critical violations and zero unrouted items;
3. native STEP plus enclosure, connector-mate, card, coax-tool and harness review;
4. CAM comparison, factory/assembler DFM and independent PCB-MAIN Review B.

The overall disposition remains `HOLD`; Gerber, placement release, production
BOM release and any `FOR_MANUFACTURE` claim remain prohibited.

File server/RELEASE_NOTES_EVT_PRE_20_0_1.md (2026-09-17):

# Мухоед EVT-PRE-20 source baseline 0.1

Статус: `CI PASS / NOT DEPLOYED`

- Сохранена фактическая база Мухоед 1.2.0, interface release 1.4.
- Runtime-идентификатор ветки: `1.2.0-evt-pre-20.1`; маркировка EVT-MB исключена.
- В CI добавлены полный pytest и compileall.
- Устранён collection blocker: `router.py` и `online_type_service.py` импортировали отсутствующие `FeatureUpdateMessage` и `OnlineTypeStatusMessage`.
- Добавлены Pydantic schemas для 43-feature update и fail-safe online type status.
- Добавлены regression tests точной длины features и безопасных значений UNKNOWN/false.
- Иерархическое решение переведено на bounded consensus последних 4-8 уникальных
  окон; повтор одного `boot_id/seq_no` не увеличивает evidence.
- В portable firmware добавлен тот же rolling-consensus 4-8 окон с порогом 5/8
  и явным отображением flat-классов в семейства; конкретный тип не назначается.
- Добавлены отдельные ветви неизвестного типа внутри известных семейств:
  `UNKNOWN_PROP_PISTON_UAV`, `UNKNOWN_TURBINE_JET_UAV`,
  `UNKNOWN_ROTOR_ELECTRIC_UAV`; конкретный тип по-прежнему не фиксируется без
  dataset-readiness gate.
- Temporal type model пересобрана для горизонтов 4/6/8 с и fail-closed отклоняет
  модель с несовместимым набором горизонтов.
- В `TargetEstimate` восстановлены поля `localization_mode` и `geometry_quality`, которые уже формировал solver.
- Full CI восстанавливает `dataset/features.csv` из версионированного `features.csv.gz` штатным скриптом до pytest.
- MQTT bridge переведён в fail-closed TLS mode: без CA, client certificate и key запуск отклоняется.
- Plaintext MQTT оставлен только для изолированного стенда с явным `--insecure-bench`; добавлены отрицательные тесты конфигурации.
- Станционный HTTP transport переведён в fail-closed mode: ingestion,
  command polling/ACK и audio upload включаются только точным стендовым
  `ZS_STATION_HTTP_INSECURE_BENCH=1`; полные IMSI/ICCID по HTTP по-прежнему
  запрещены.
- Добавлены universal Python 3.12 lockfiles с SHA-256 каждого допустимого
  distribution artifact; Docker и CI используют `pip --require-hashes`.
- Добавлен воспроизводимый CycloneDX 1.6 server SBOM, byte-exact привязанный к
  runtime lock, а также независимые QG-1/QG-2 проверки состава и хешей.
- Реализована серверная половина MQTT command downstream/ACK: canonical CBOR,
  Ed25519, 15-минутный TTL, QoS 1 retry до application ACK, station ownership и
  идемпотентная обработка повторов.
- Production bridge не публикует unsigned-команды и требует owner-only signing
  key; Docker build context исключает TLS private keys. Broker ACL разделён для
  20 station credentials и разрешает каждой станции только собственные topics.
- В portable firmware реализованы fixed-memory canonical CBOR parser команд и
  encoder ACK: station/time/TTL binding, точное восстановление подписанных байтов,
  обязательные callback проверки Ed25519 и durable dedup. Межъязыковой
  server-generated Ed25519 vector проверяется Python и C тестами.
- Portable atomic journal записывает `ACCEPTED` до идемпотентного действия и
  `COMPLETED` до разрешения ACK; fault-injection проверяет потерю питания между
  body/commit marker, повтор и заполнение ограниченного журнала.
- Bounded trust adapter проверяет SHA-256-derived key ID, дубликаты, disabled
  rotation entries и неизвестные ключи до вызова обязательного crypto backend;
  production public keys в portable source отсутствуют.
- Portable application channel связывает decode/trust/dedup, atomic journal и
  idempotent executor; ACK появляется только после read-back `COMPLETED`, а
  transient execution/storage failure оставляет команду для безопасного retry.
- Portable binary MQTT boundary принимает topic и CBOR только с точными длинами,
  проверяет canonical tenant/station topic, QoS 1 и `retain=false`, затем выдаёт
  ACK topic/payload только после durable completion.
- Portable BG95 command binding подписывается на exact `down` с QoS 1,
  разбирает length-delimited binary `QMTRECV` и публикует journal-backed ACK
  через fixed-length `QMTPUB`. При UART failure server retry восстанавливает ACK
  без повторного выполнения; внешний server-only/non-retained ACL contract
  остаётся обязательным.
- Portable bounded raw-UART session собирает fragmented line/prompt/QMTRECV,
  последовательно выполняет обе subscription и даёт единственного TX owner для
  event publish или command ACK. Один command ожидает занятого TX в RAM, а
  дальнейшие доставки требуют штатного server application-ACK retry.
- Portable command-journal NOR adapter выделяет отдельный erase block каждому
  accepted/completed record и проходит restart, torn commit, range и neighbour
  isolation host tests. Shared layout/bind также доказывает непересечение с
  archive и outbox. Production slot count/OCTOSPI/endurance не объявлены готовыми.
- Portable event outbox атомарно сохраняет полный schema-4 CBOR с metadata CRC32
  и SHA-256, выбирает priority/FIFO, не вытесняет pending events и при torn ACK
  обеспечивает безопасную at-least-once повторную доставку.
- Server/portable-firmware application receipt использует canonical CBOR,
  station/boot/sequence/event binding и SHA-256 точных detection bytes. Сервер
  сохраняет processing state до receipt, exact retry не повторяет fusion, а
  firmware освобождает outbox slot только после строгой проверки receipt.
- Portable event MQTT adapter выдаёт только exact binary `up` publication после
  durable retry accounting, оставляет PUBACK без влияния на outbox и применяет
  queued receipt после рестарта через поиск durable event identity.
- Portable BG95 uplink формирует fixed-length QoS-1/non-retained `QMTPUB`, после
  prompt передаёт exact binary CBOR и fail-closed обрабатывает partial UART,
  timeout/offline и mismatched result; `+QMTPUB` success не освобождает outbox.
- Portable BG95 transport до `QMTOPEN` включает payload length в direct
  `QMTRECV`; receipt path после connect требует успех этого шага, подписывается
  на exact station receipt topic с QoS 1 и разбирает binary frame
  по byte count. Отсутствующий в URC retain-флаг компенсируется только явным
  внешним station ACL/server-only/non-retained contract; его target-проверка
  остаётся blocker.
- Portable W25Q-class outbox adapter использует один полный erase block на slot,
  проверяет alignment/capacity и сохраняет соседний pending slot при reclaim;
  общий bind сначала проверяет exact W25Q512JV JEDEC `EF 40 20`, SFDP/BFPT
  64 MiB density, 4-byte geometry и QE с restore/read-back, иначе не выдаёт ни
  один storage interface;
  portable planner размещает audio archive в выровненном префиксе NOR, command
  journal следующим разделом, outbox в хвосте и QG-проверяет непересечение всех
  трёх; shared bind API создаёт три adapter-а из одного layout и обрезает archive
  storage на границе journal. Production command/outbox slot counts, target
  memory-map/OCTOSPI/sample/endurance остаются blockers.
- Открыты target USART/DMA/ISR/cache integration, modem/broker-policy evidence и reviewed Ed25519 backend,
  provisioning public key, command-journal/outbox slot-count и OCTOSPI/endurance binding, command ACK
  target integration и аппаратный end-to-end;
  они не объявлены PASS до сборки станций.

Изменение не закрывает security/deployment blockers из `EVT_PRE_20_RELEASE_AUDIT.md` и не является разрешением на internet-facing deployment.

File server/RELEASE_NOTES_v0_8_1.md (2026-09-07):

# Мухоед server v0.8.1

Дата приемки: 2026-09-04

## Основание

Версия выпущена после повторного анализа четырех новых полевых видеозаписей: `IMG_8704`, `IMG_8705`, `IMG_8707`, `IMG_8721`.

## Изменения

1. Добавлена узкополосная фильтрация стационарных гармоник сети 50 и 60 Гц до поиска гребенки двигателя. Это закрывает сценарий, в котором сеть 50/100/200 Гц могла быть принята за гармоники БПЛА через субгармоники 12.5, 16.7 или 25 Гц.
2. Добавлен адаптивный порог RMS для окон признаков. Он сохраняет тихие полезные окна, если одиночный короткий импульс завышает пиковую нормализацию записи.
3. Доверие к акустическому семейству теперь учитывает не только относительный отрыв победителя, но и абсолютное соответствие модели.
4. Результат семейства помечается как условный относительно независимого AIR gate. Без подтверждения воздушной цели эти четыре записи дают `UNKNOWN`.
5. Экспертные подсказки FP-1 и GR2 больше не могут автоматически стать рабочим типом. Они доступны только как исследовательская метаинформация.
6. В зависимости добавлен `httpx2`, а фикстуры БД сделаны повторяемыми для полного API-прогона.

## Приемка

- все четыре записи обнаружены в первом окне 0-2 с;
- положительны 94 из 96 двухсекундных окон;
- итоговый тип для всех записей: `UNKNOWN`;
- условное семейство для всех записей: `PROP_PISTON`, статус `provisional_family`;
- без AIR gate семейство для всех записей: `UNKNOWN`;
- полный регрессионный набор: 68 PASS, 0 FAIL;
- прежние шесть целевых записей не потеряли детекцию после сетевой фильтрации;
- природные фоновые записи остались отрицательными.

## Ограничения

- `PROP_PISTON` является исследовательской условной оценкой, а не подтвержденным типом;
- глобальный F0 на записях `IMG_8704` и `IMG_8705` неоднозначен из-за выбора порядка гармоники, поэтому его нельзя напрямую переводить в обороты;
- оценки числа роторов, лопастей и типа силовой установки остаются исследовательскими и не должны использоваться как рабочее решение;
- `TURBINE_JET` все еще не обеспечен достаточным обучающим материалом;
- новые записи нельзя включать в обучение до подтверждения типа, условий пролета и независимого источника метки.

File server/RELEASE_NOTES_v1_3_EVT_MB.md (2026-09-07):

# Мухоед 1.2.0 EVT-MB

- Protocol 1.4 decoder and `/api/v1/health` protocol report are synchronized.
- Windows 11 Docker Desktop and Ubuntu 24.04 Docker Engine compose paths are included.
- Four-station simulation, compact-CBOR compatibility, localization modes and
  time-quality rules remain part of the test suite.
- This source release does not claim a container/runtime PASS until images are
  built and the supplied health and station simulation checks pass on the target host.

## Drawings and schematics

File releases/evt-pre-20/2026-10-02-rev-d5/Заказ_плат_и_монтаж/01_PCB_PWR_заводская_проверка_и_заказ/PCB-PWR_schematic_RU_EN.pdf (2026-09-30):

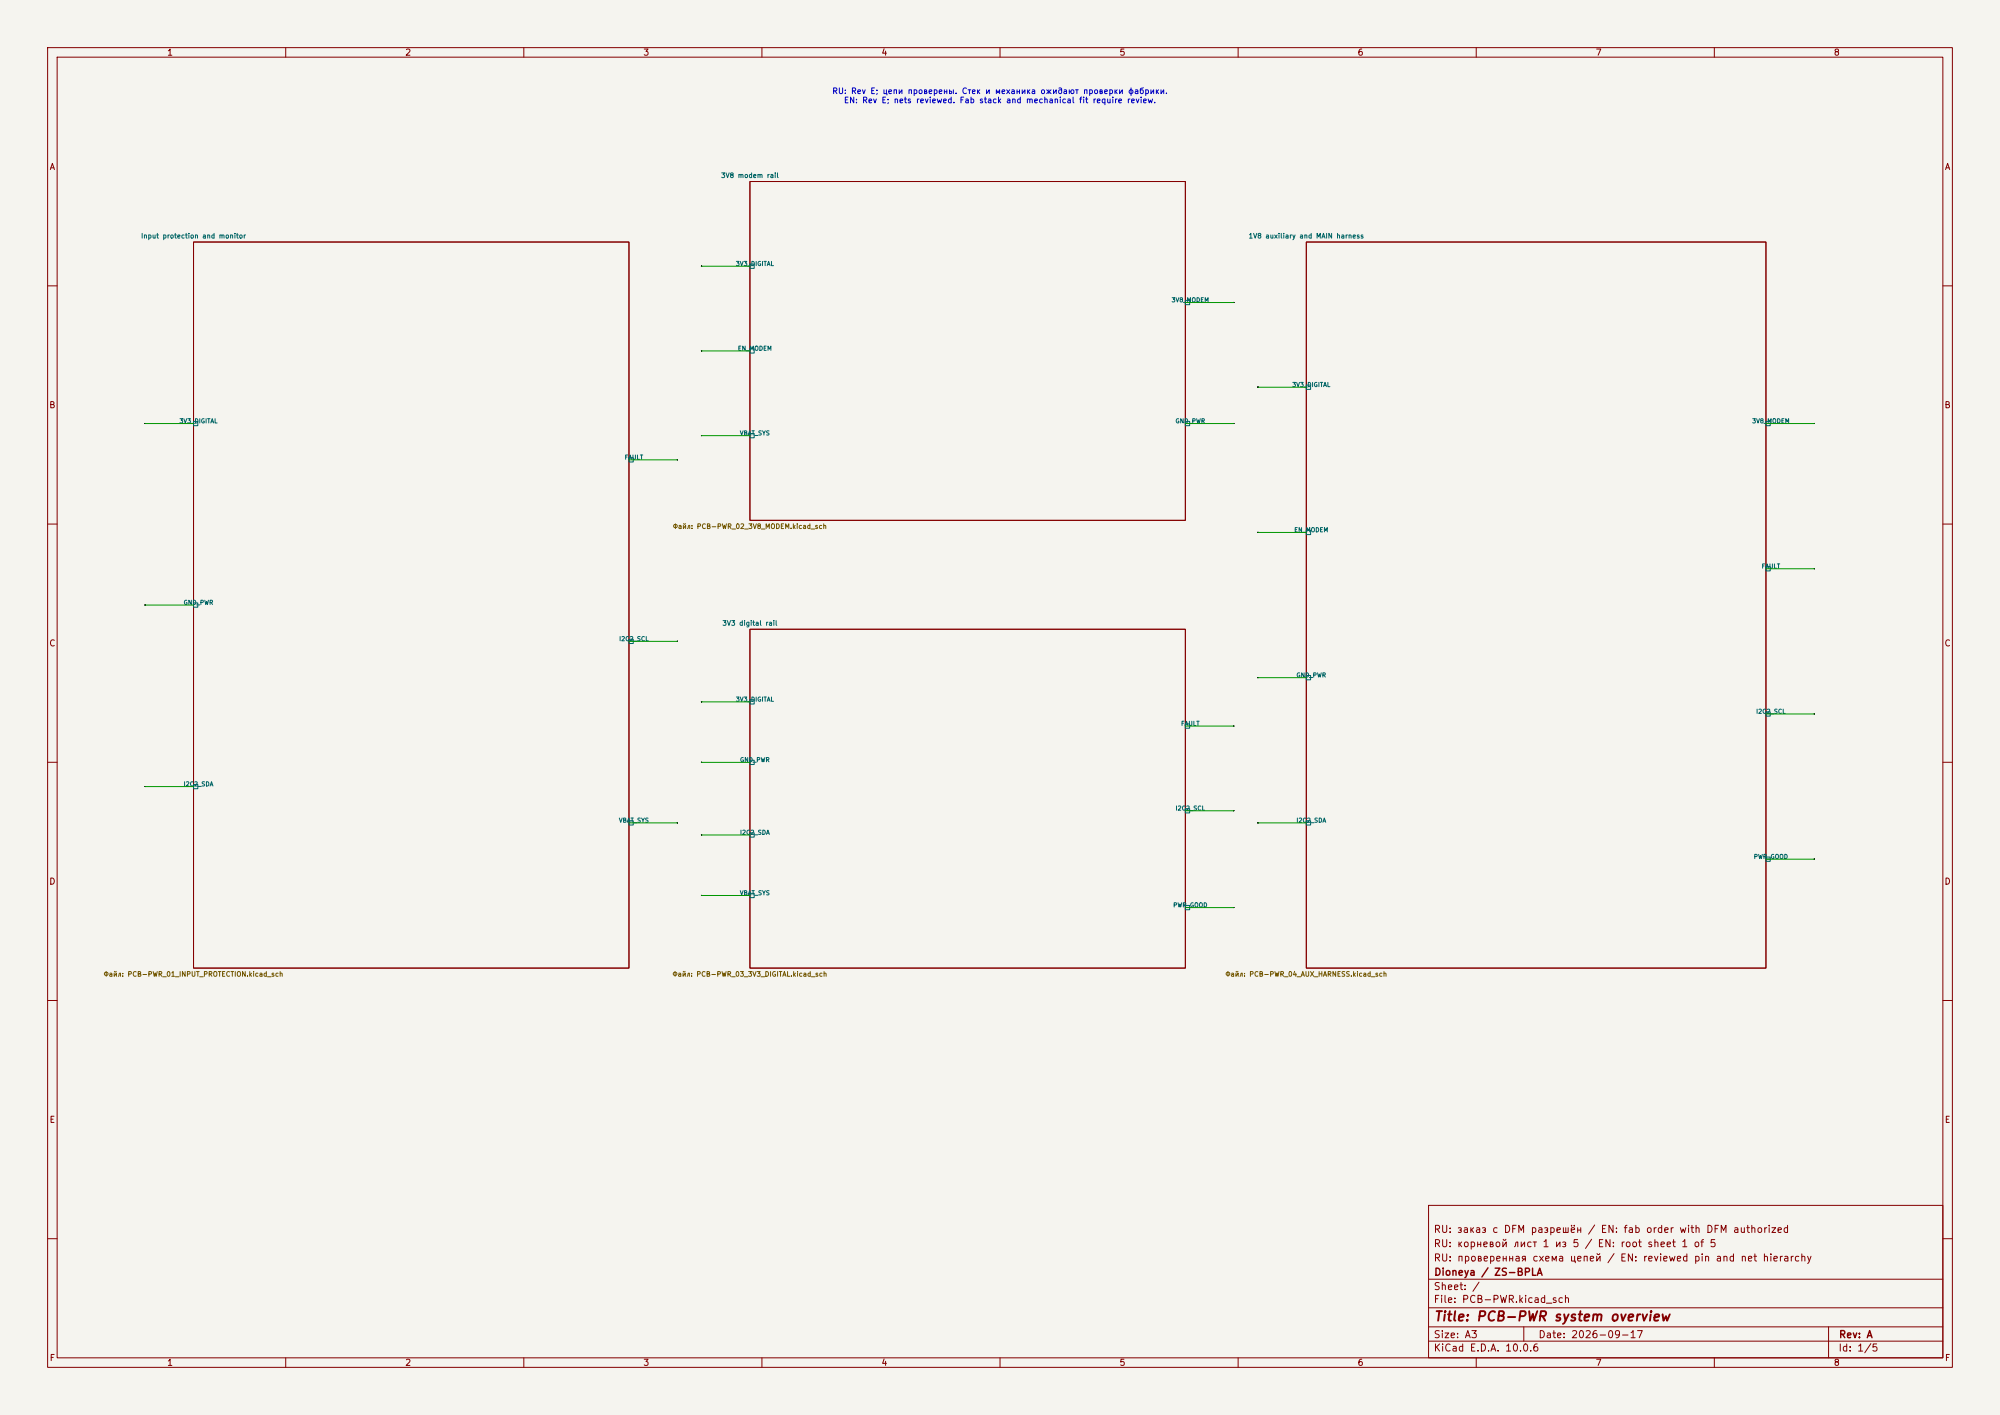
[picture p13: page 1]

RU: Rev E; цепи проверены. Стек и механика ожидают проверки фабрики. EN: Rev E; nets reviewed. Fab stack and mechanical fit require review.

GND_PWR 3V8 modem rail Файл: PCB-PWR_02_3V8_MODEM.kicad_sch

Input protection and monitor

1V8 auxiliary and MAIN harness

I2C2_SCL PWR_GOOD 3V3 digital rail Файл: PCB-PWR_03_3V3_DIGITAL.kicad_sch
I2C2_SCL VBAT_SYS

RU: заказ с DFM разрешён / EN: fab order with DFM authorized
RU: корневой лист 1 из 5 / EN: root sheet 1 of 5
RU: проверенная схема цепей / EN: reviewed pin and net hierarchy
Dioneya / ZS-BPLA
Sheet: /
File: PCB-PWR.kicad_sch
Title: PCB-PWR system overview

Size: A3 | Rev: A | F Date: 2026-09-17
KiCad E.D.A. 10.0.6 | Id: 1/5

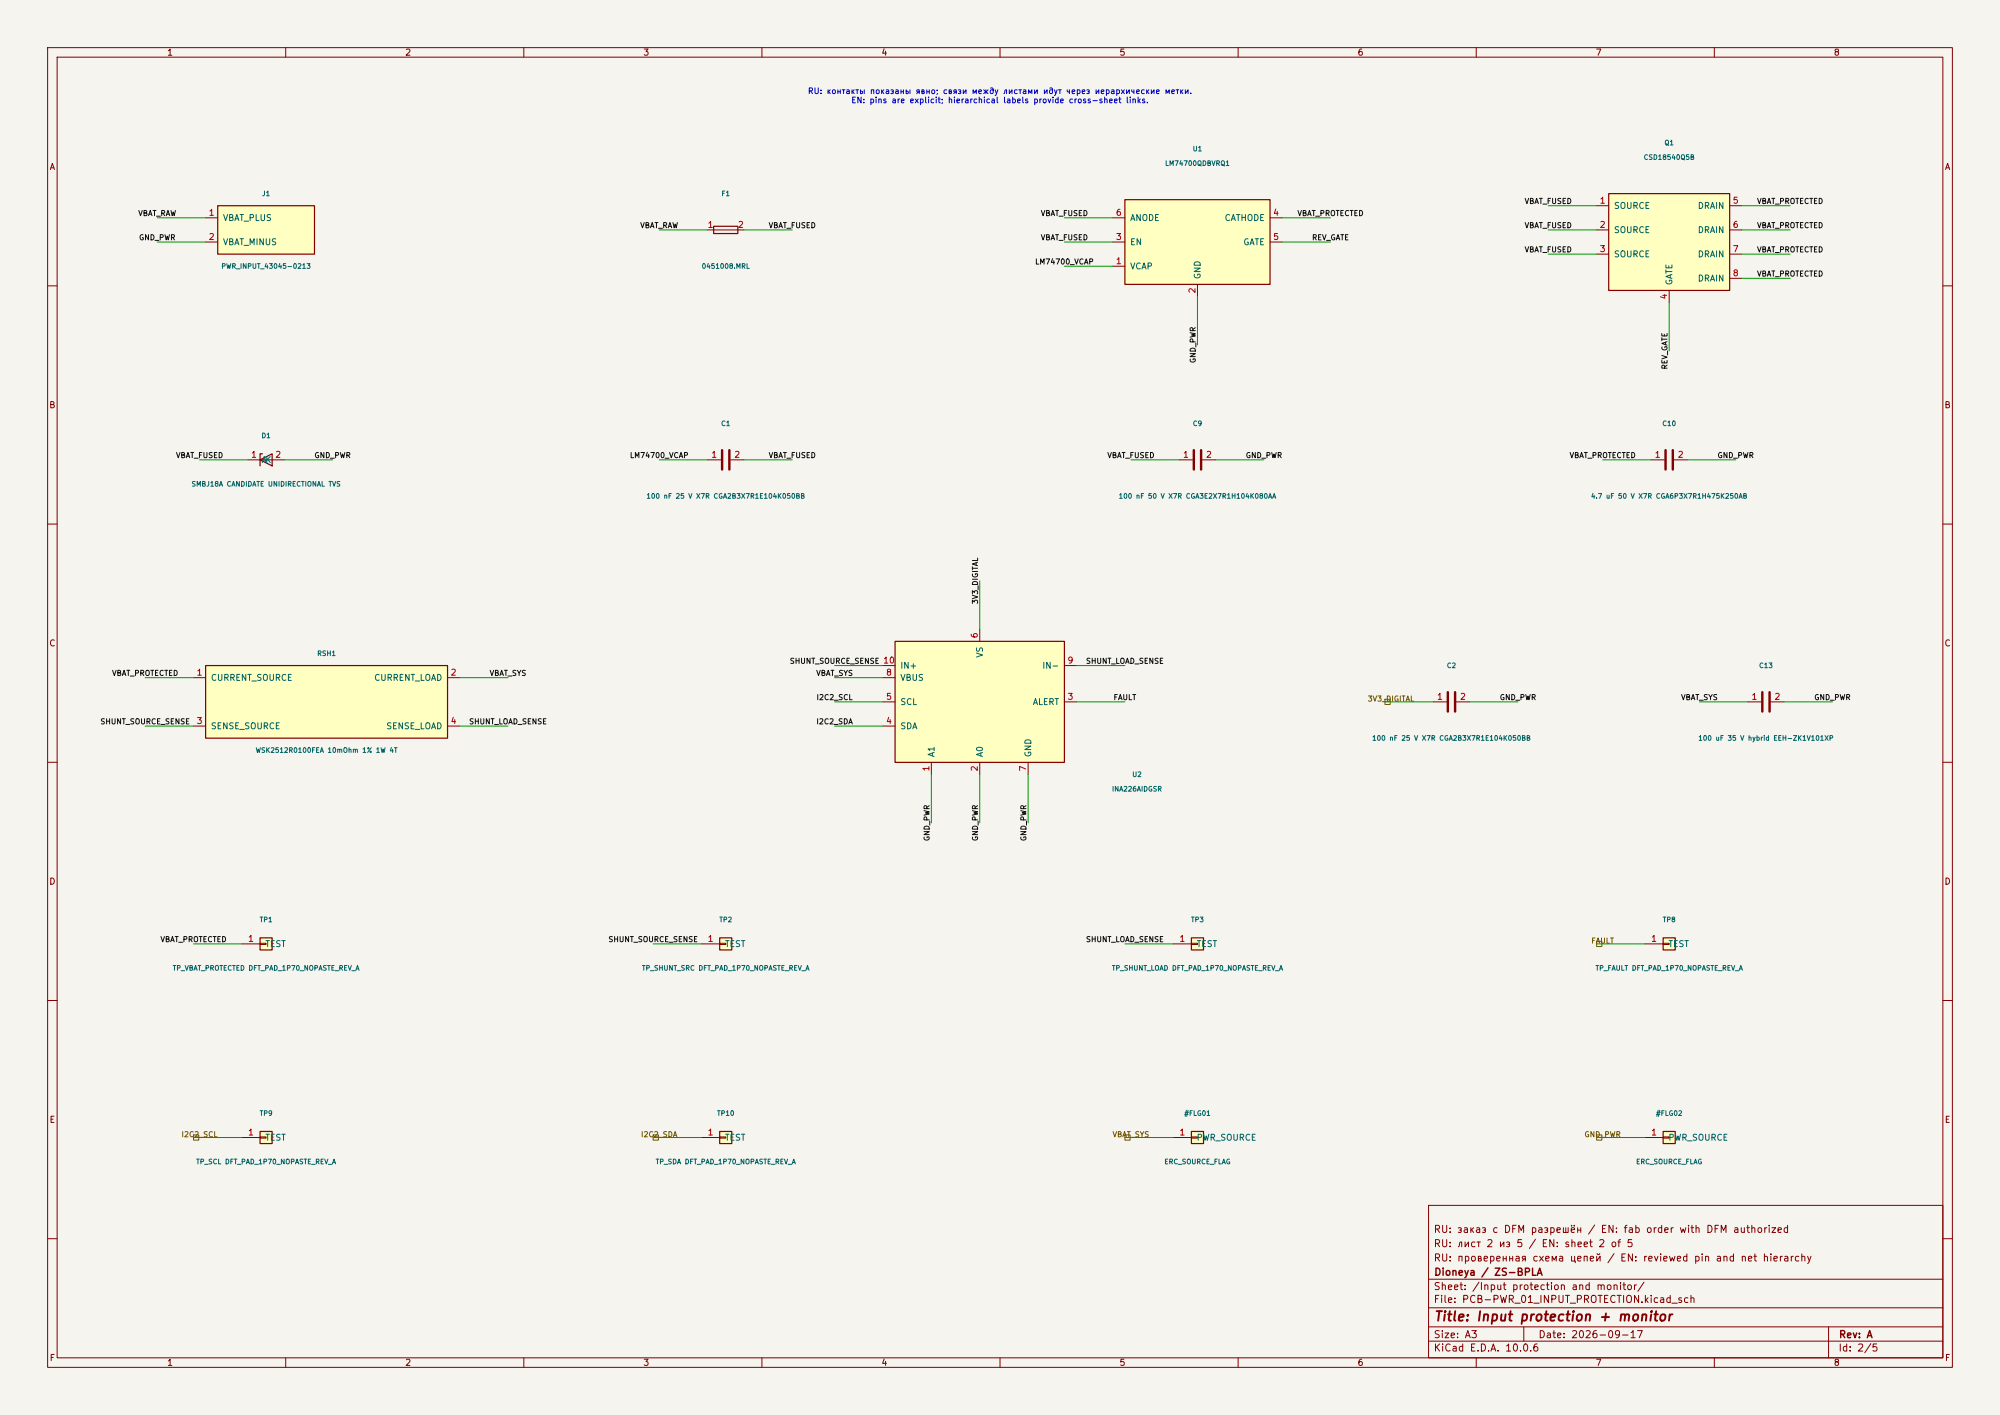
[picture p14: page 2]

RSH1 WSK2512R0100FEA 10mOhm 1% 1W 4T K
SMBJ18A CANDIDATE UNIDIRECTIONAL TVS TEST 1

RU: заказ с DFM разрешён / EN: fab order with DFM authorized
RU: лист 2 из 5 / EN: sheet 2 of 5
RU: проверенная схема цепей / EN: reviewed pin and net hierarchy
Dioneya / ZS-BPLA
Sheet: /Input protection and monitor/
File: PCB-PWR_01_INPUT_PROTECTION.kicad_sch
Title: Input protection + monitor

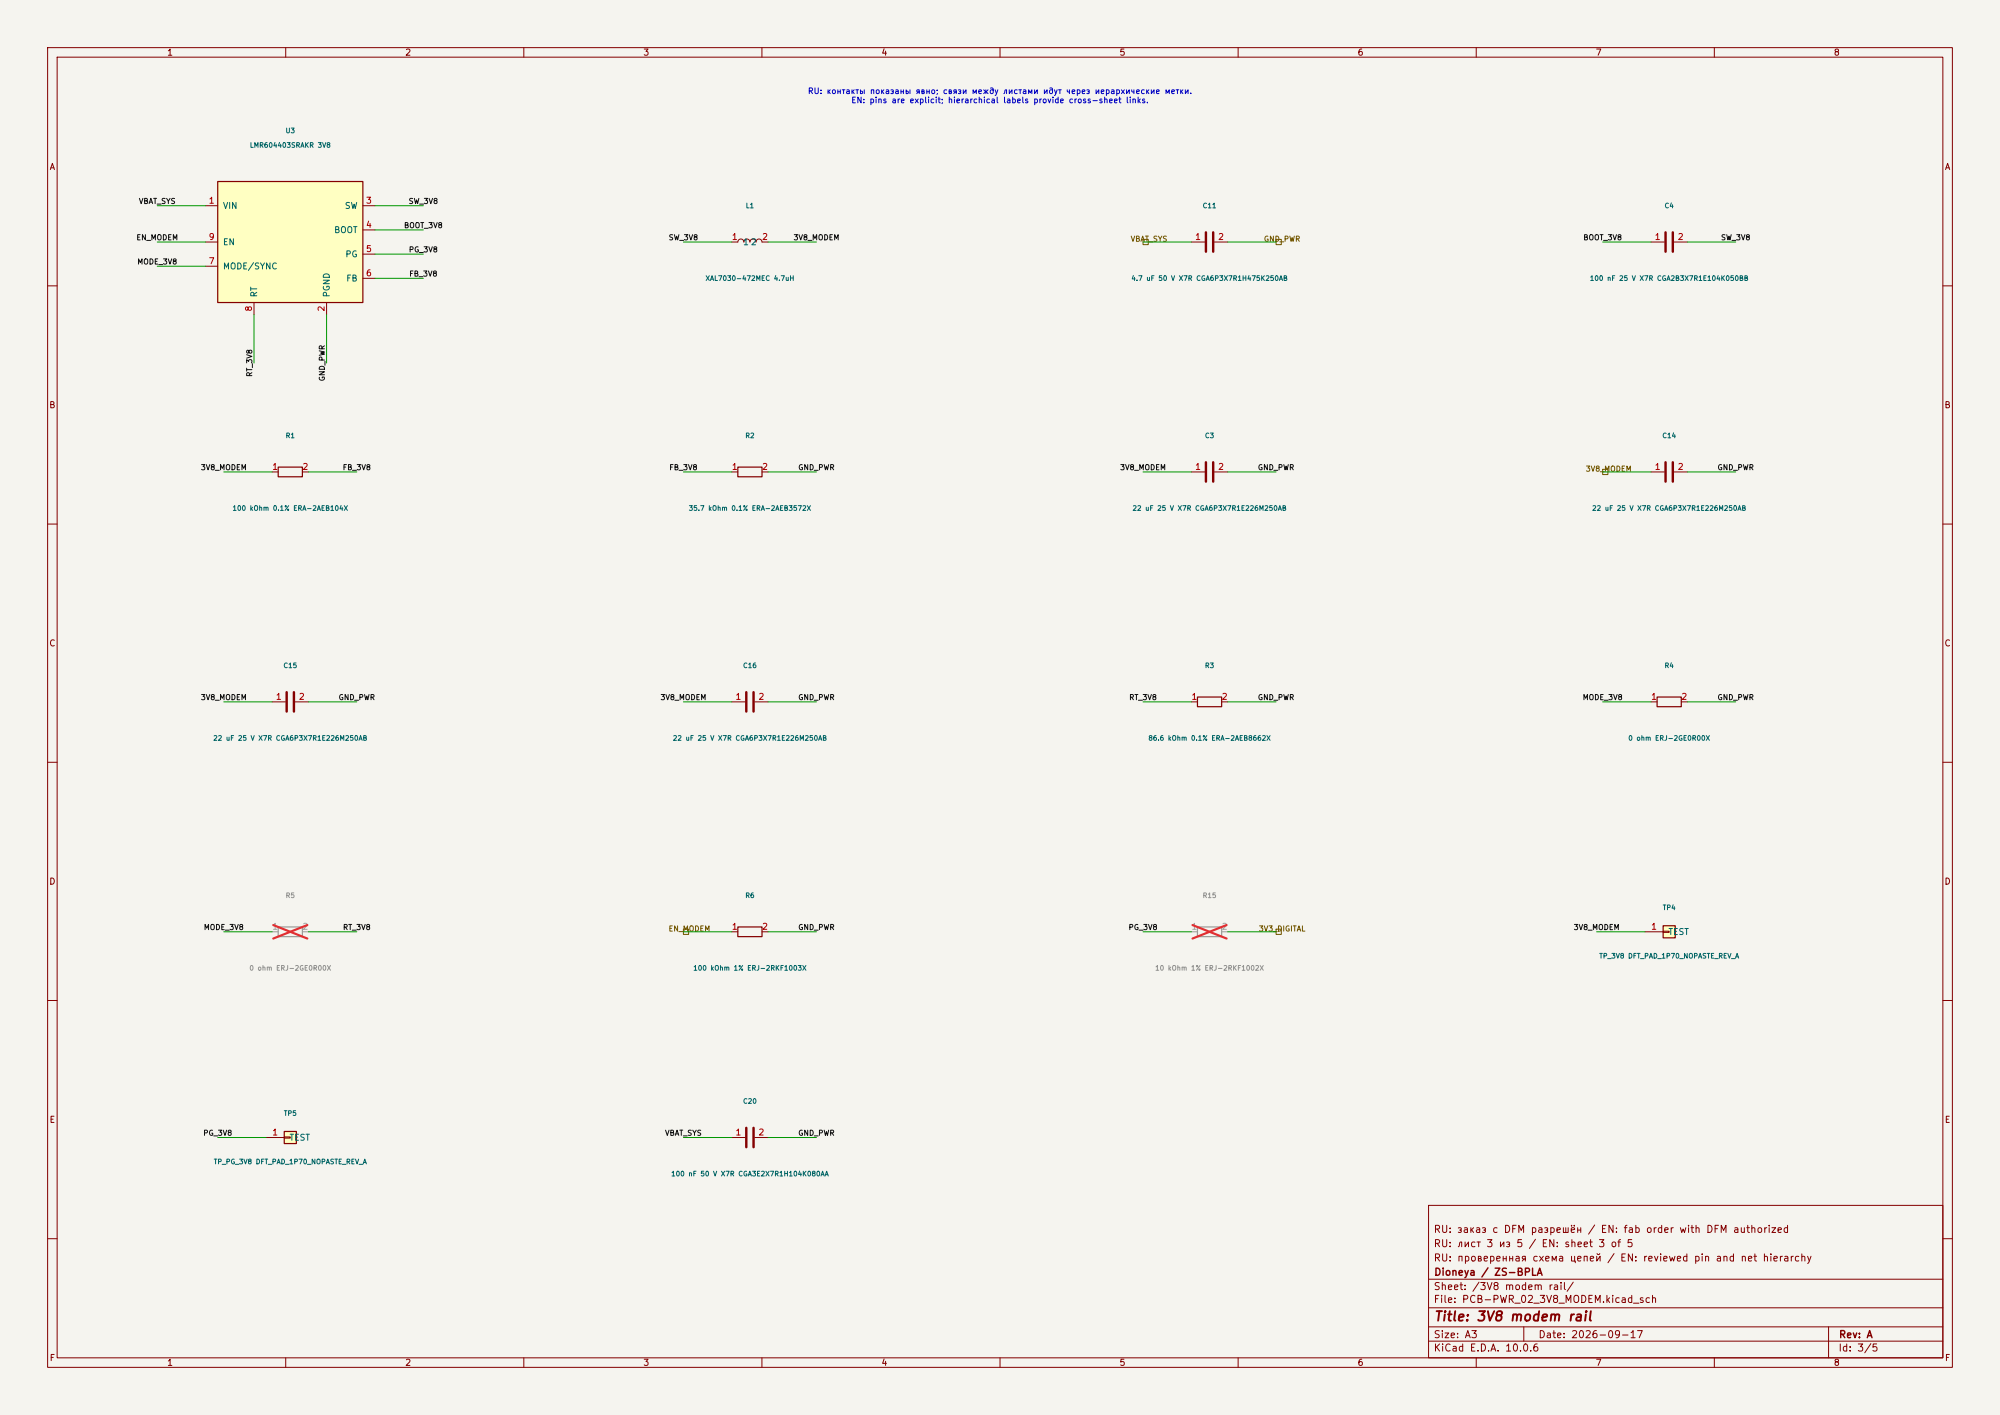
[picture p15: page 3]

RU: заказ с DFM разрешён / EN: fab order with DFM authorized
RU: лист 3 из 5 / EN: sheet 3 of 5
RU: проверенная схема цепей / EN: reviewed pin and net hierarchy
Dioneya / ZS-BPLA
Sheet: /3V8 modem rail/
File: PCB-PWR_02_3V8_MODEM.kicad_sch
Title: 3V8 modem rail

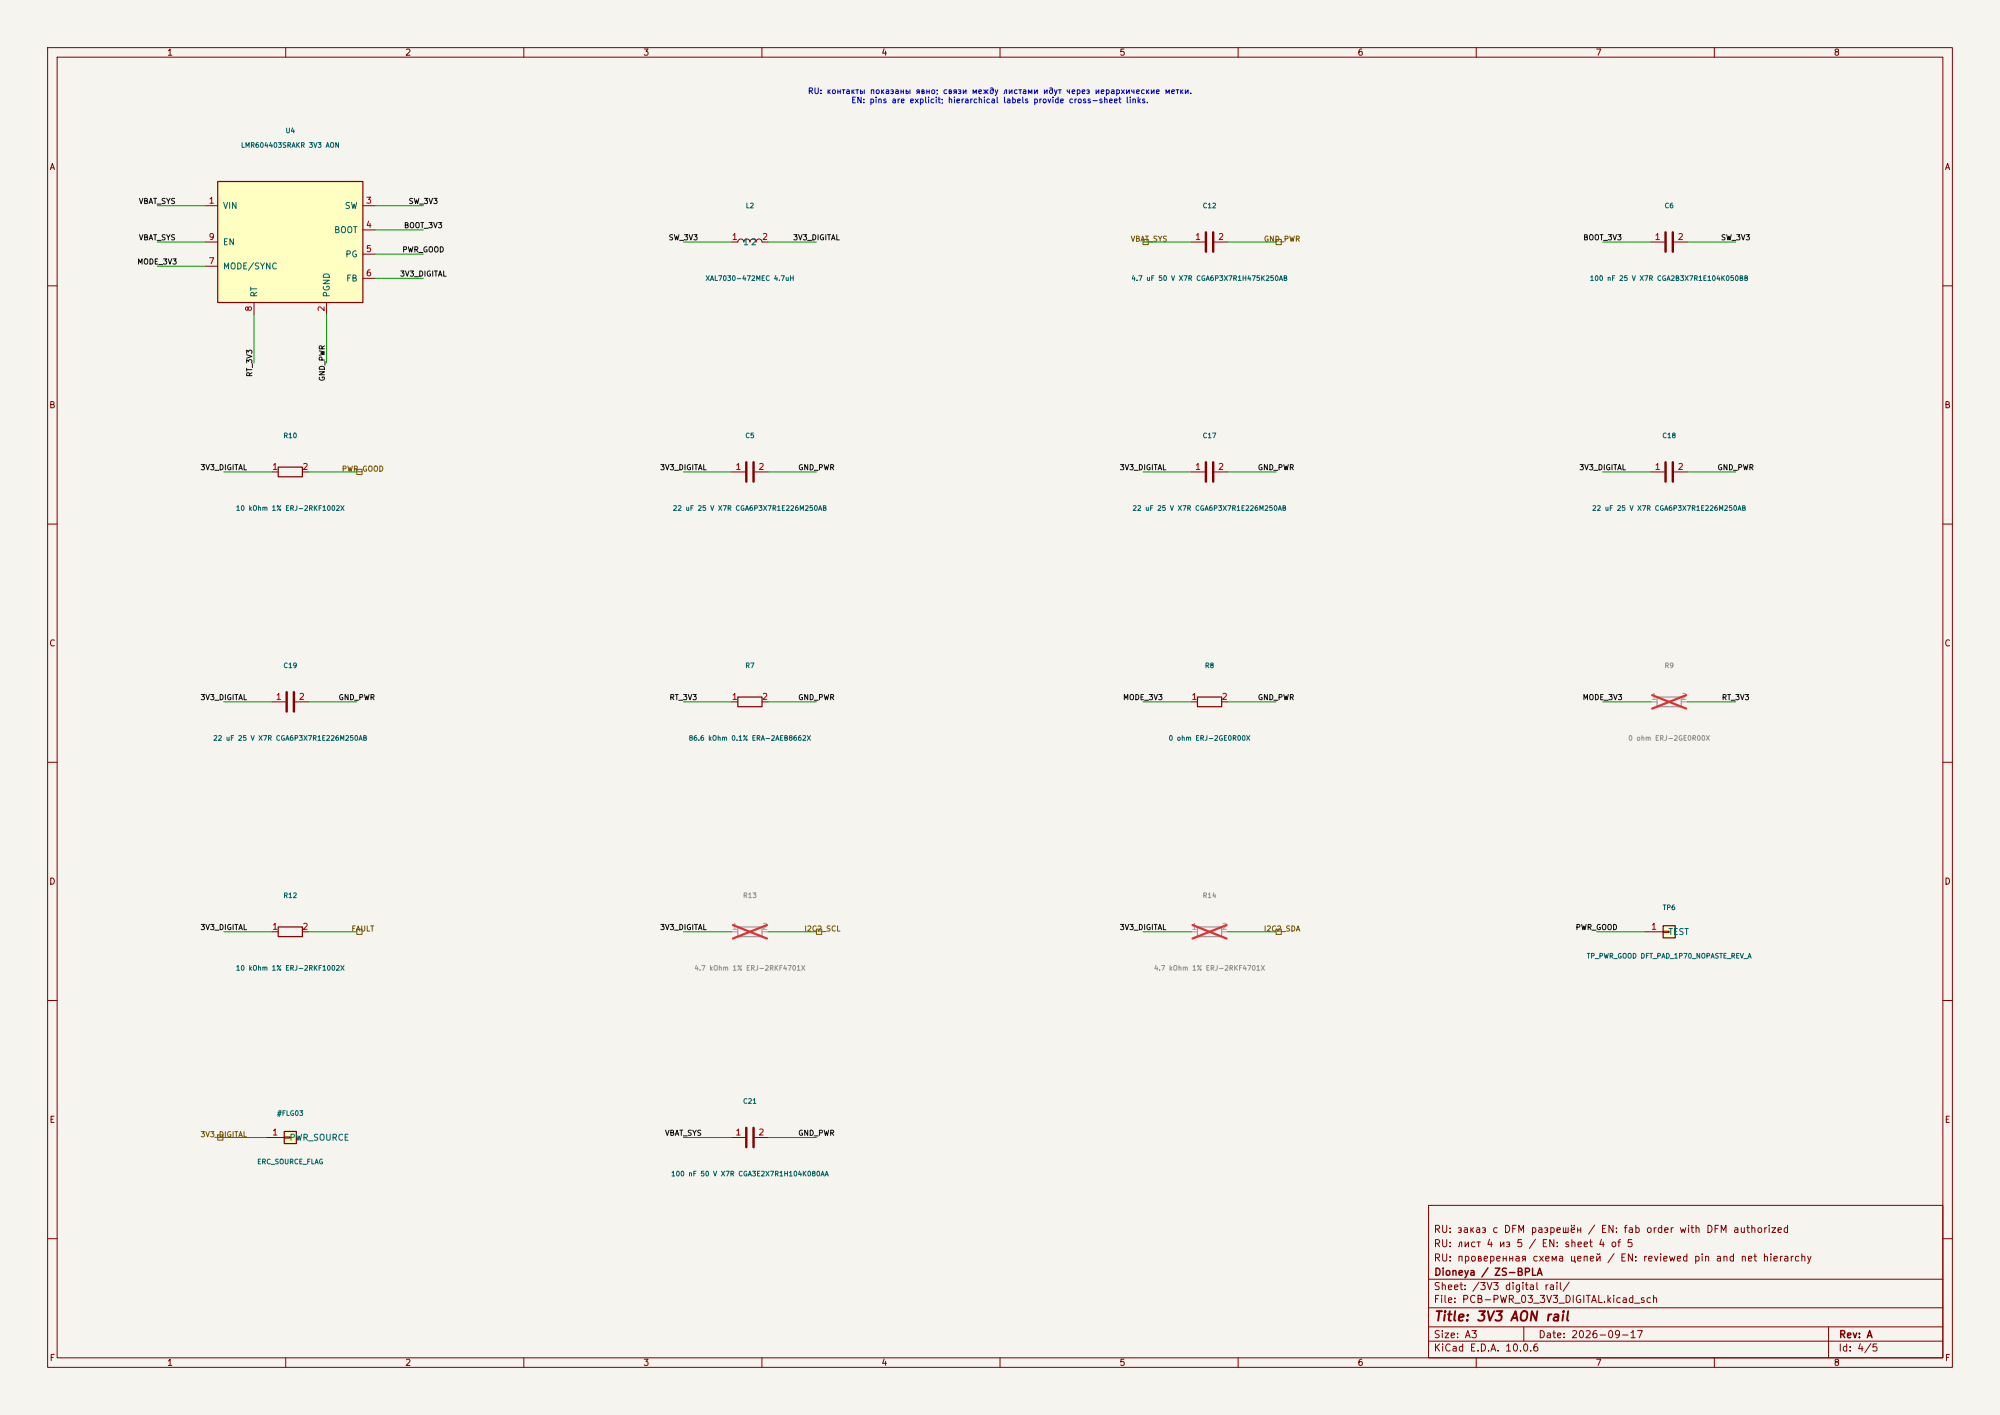
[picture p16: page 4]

RU: заказ с DFM разрешён / EN: fab order with DFM authorized
RU: лист 4 из 5 / EN: sheet 4 of 5
RU: проверенная схема цепей / EN: reviewed pin and net hierarchy
Dioneya / ZS-BPLA
Sheet: /3V3 digital rail/
File: PCB-PWR_03_3V3_DIGITAL.kicad_sch
Title: 3V3 AON rail

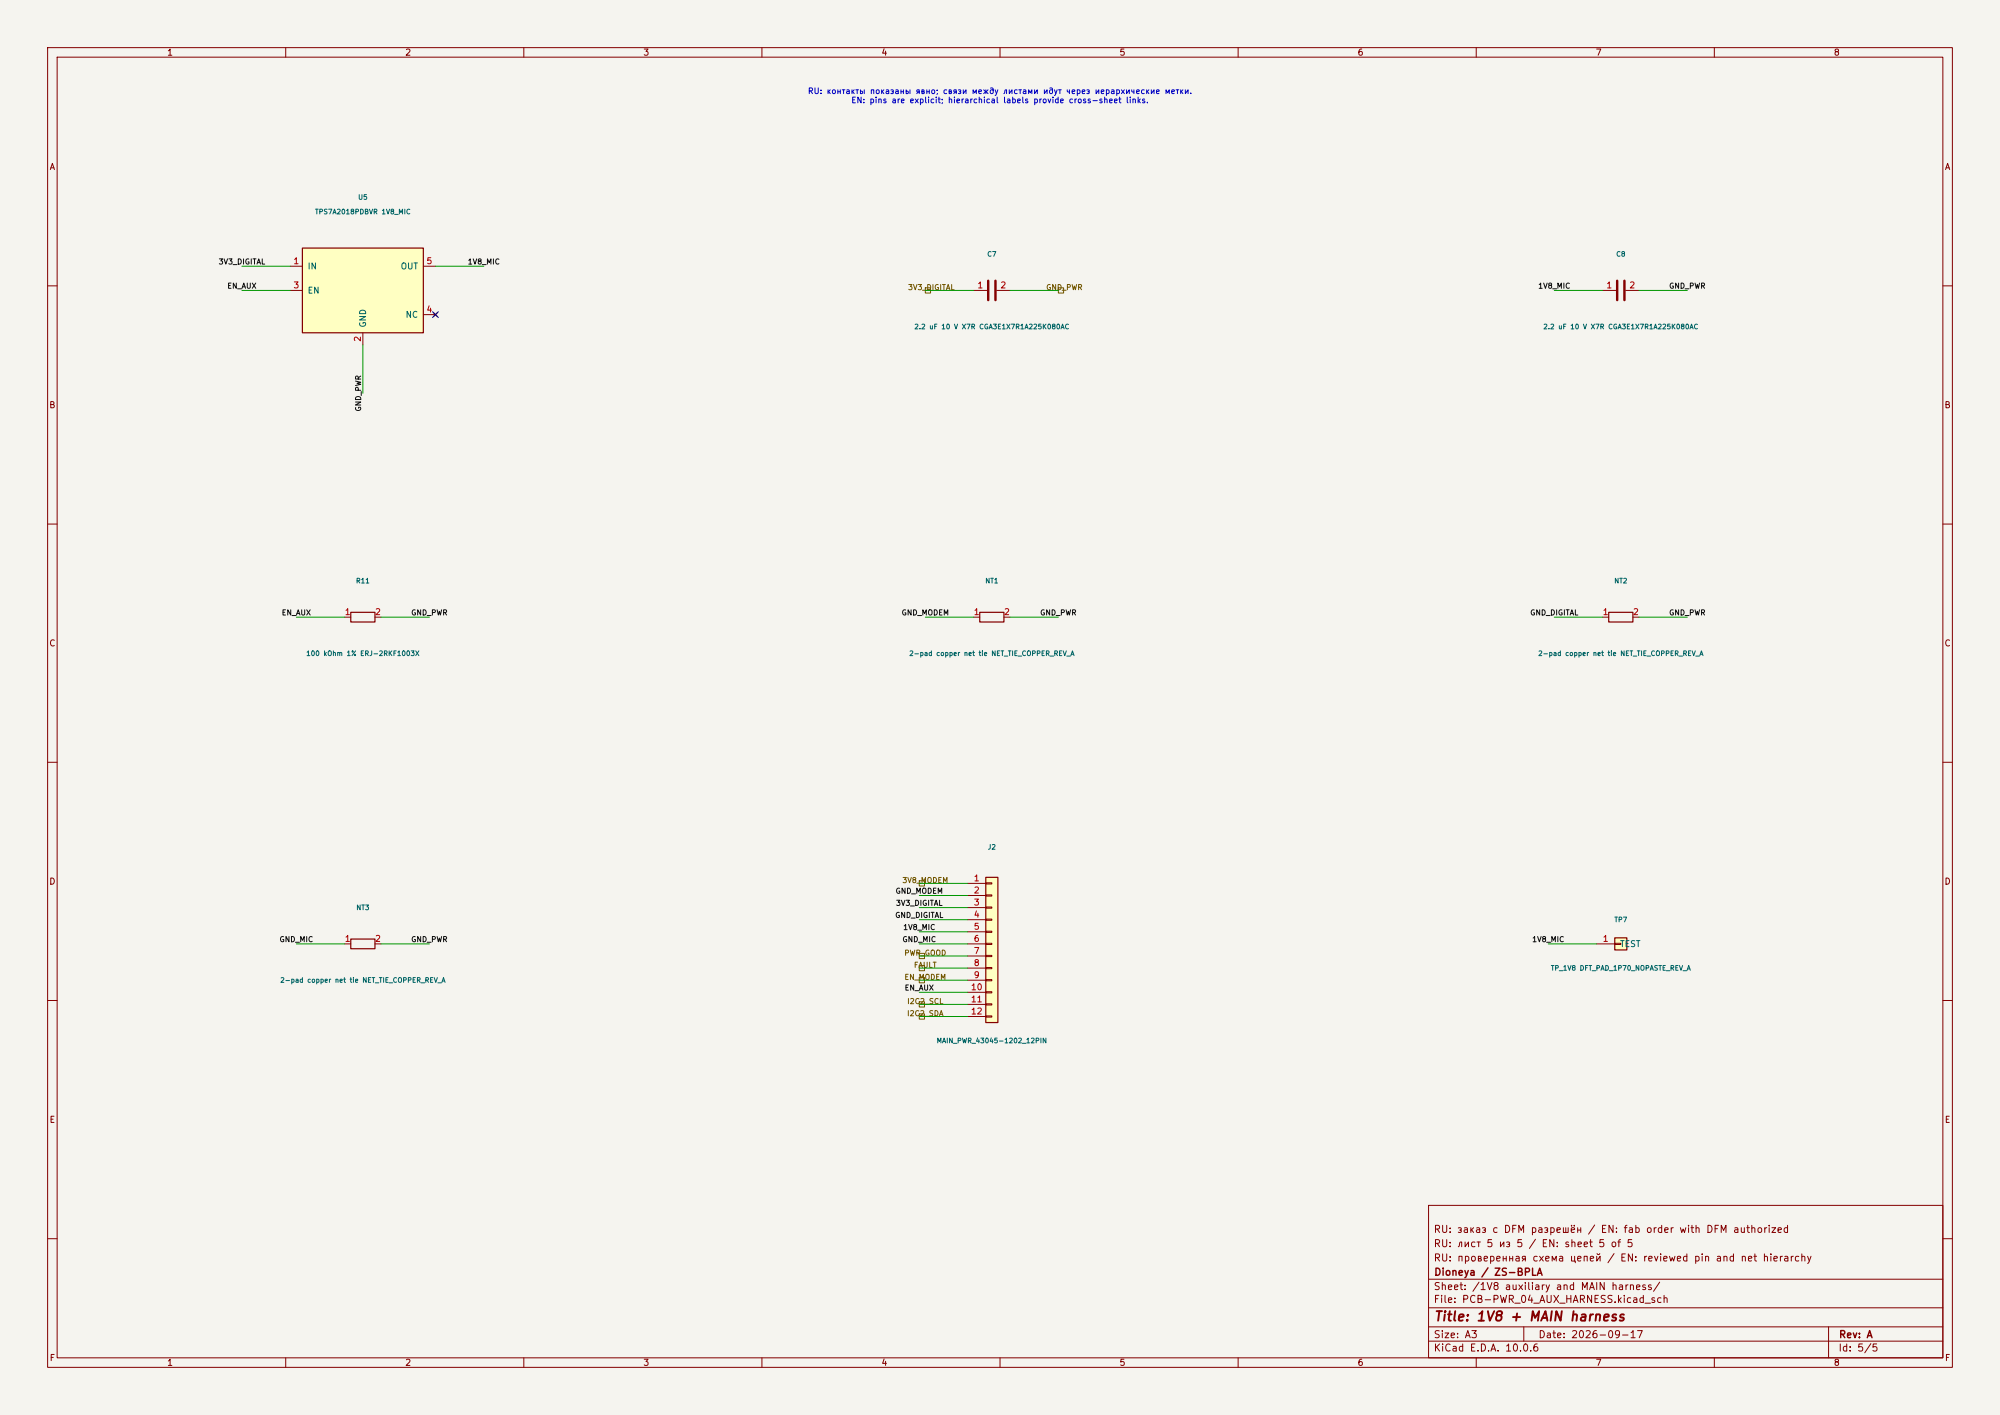
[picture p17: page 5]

GND_PWR RU: контакты показаны явно; связи между листами идут через иерархические метки. EN: pins are explicit; hierarchical labels provide cross-sheet links.
3V3_DIGITAL

RU: заказ с DFM разрешён / EN: fab order with DFM authorized
RU: лист 5 из 5 / EN: sheet 5 of 5
RU: проверенная схема цепей / EN: reviewed pin and net hierarchy
Dioneya / ZS-BPLA
Sheet: /1V8 auxiliary and MAIN harness/
File: PCB-PWR_04_AUX_HARNESS.kicad_sch
Title: 1V8 + MAIN harness

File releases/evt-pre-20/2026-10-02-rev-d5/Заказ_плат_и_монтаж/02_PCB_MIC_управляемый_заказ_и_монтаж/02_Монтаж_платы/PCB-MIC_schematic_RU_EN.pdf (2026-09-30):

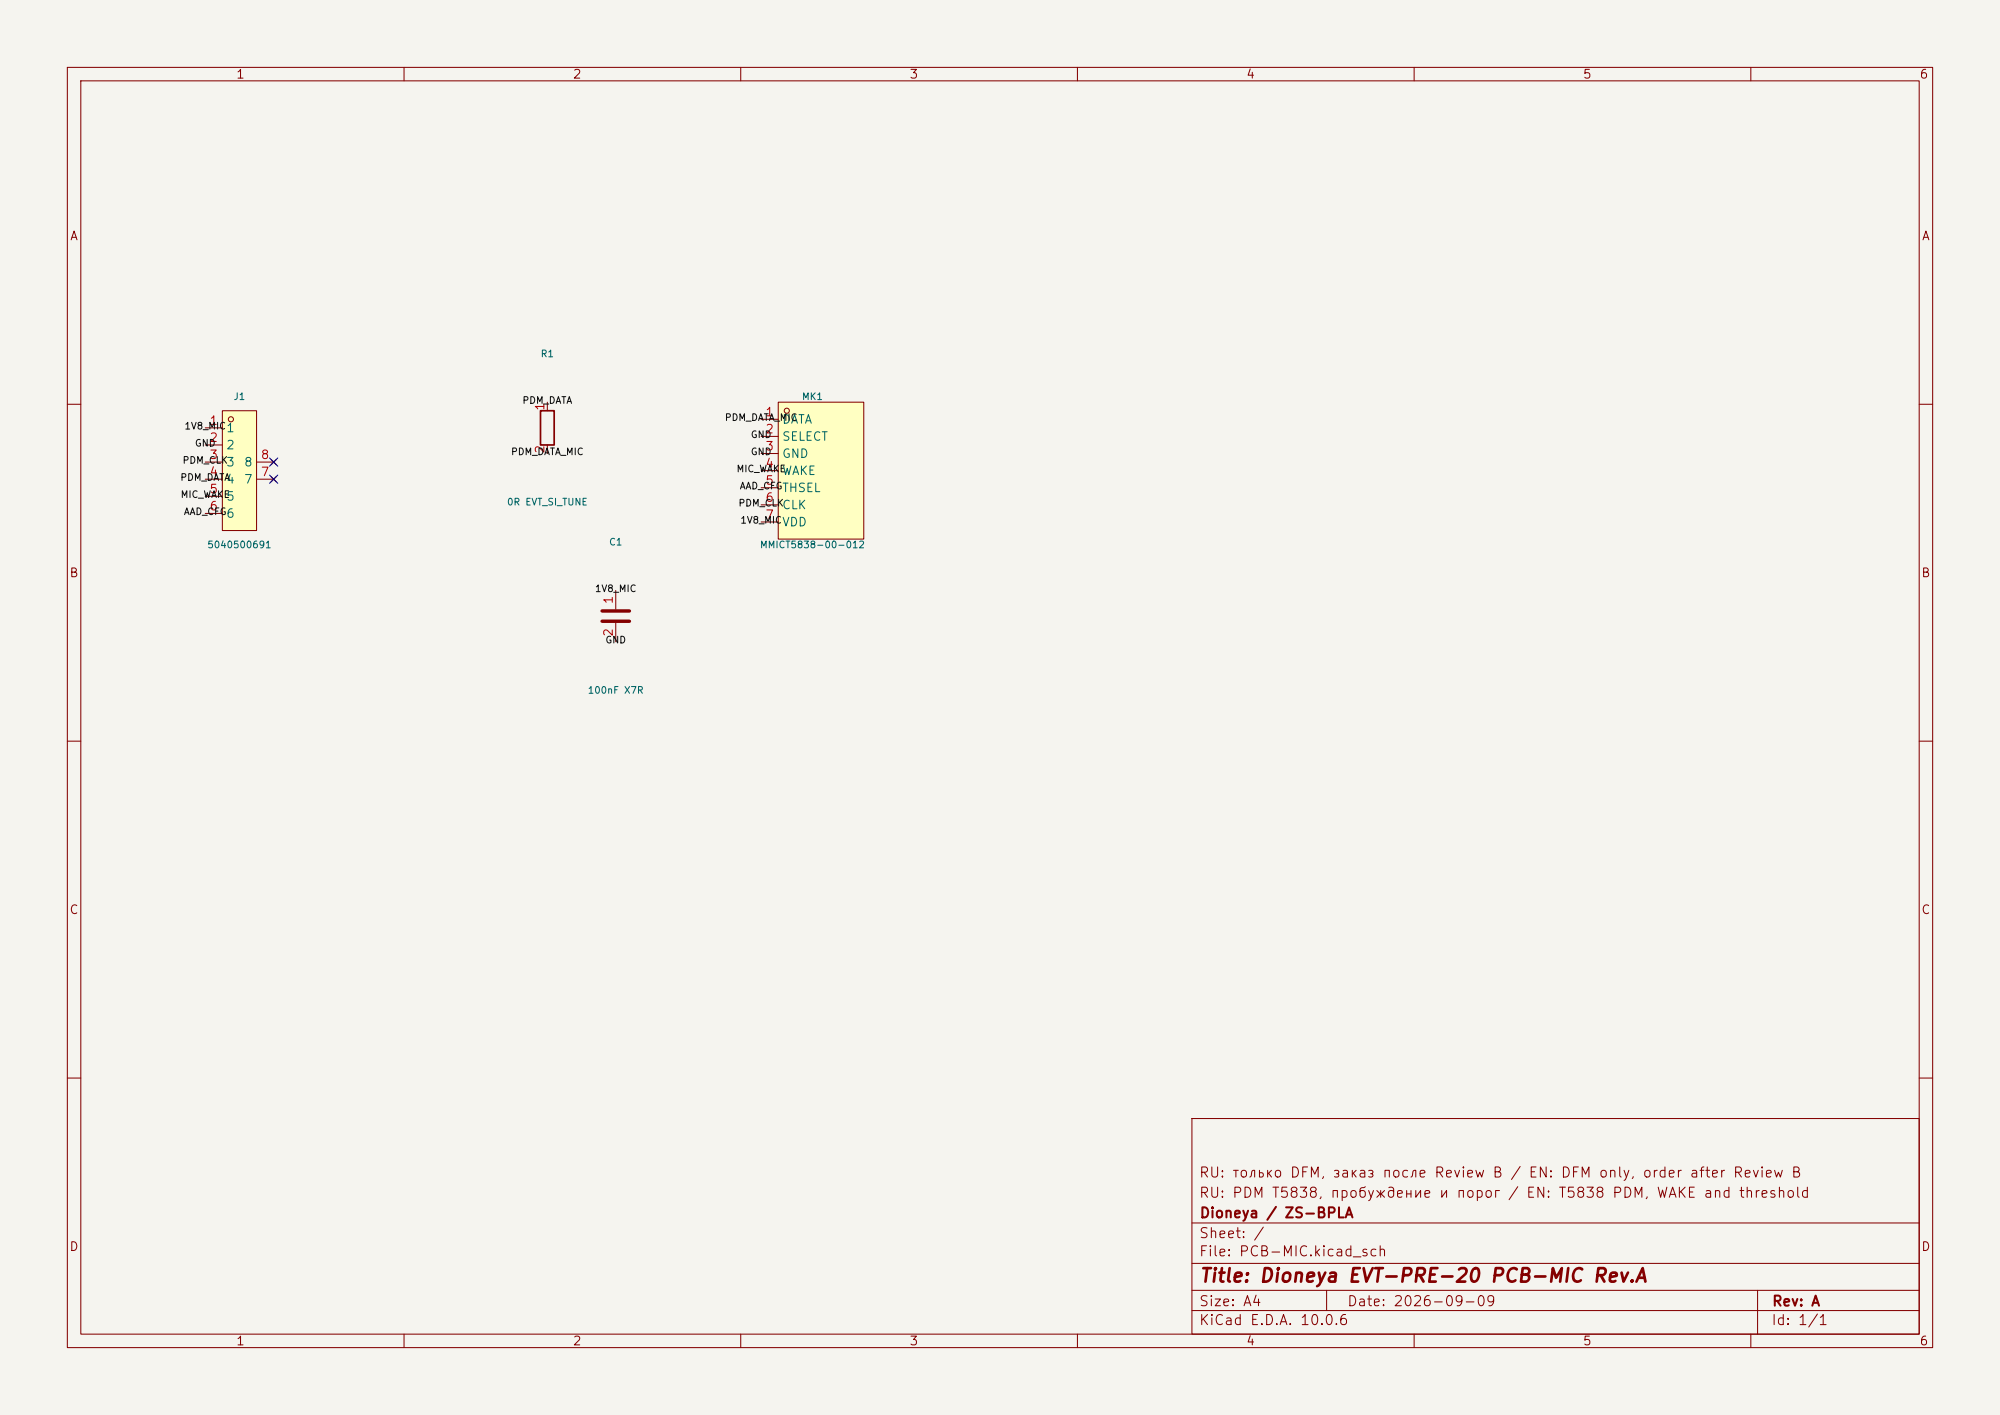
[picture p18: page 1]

RU: только DFM, заказ после Review B / EN: DFM only, order after Review B
RU: PDM T5838, пробуждение и порог / EN: T5838 PDM, WAKE and threshold
Dioneya / ZS-BPLA
Sheet: /
File: PCB-MIC.kicad_sch
Title: Dioneya EVT-PRE-20 PCB-MIC Rev.A

Size: A4 | Rev: A
KiCad E.D.A. 10.0.6 | Id: 1/1

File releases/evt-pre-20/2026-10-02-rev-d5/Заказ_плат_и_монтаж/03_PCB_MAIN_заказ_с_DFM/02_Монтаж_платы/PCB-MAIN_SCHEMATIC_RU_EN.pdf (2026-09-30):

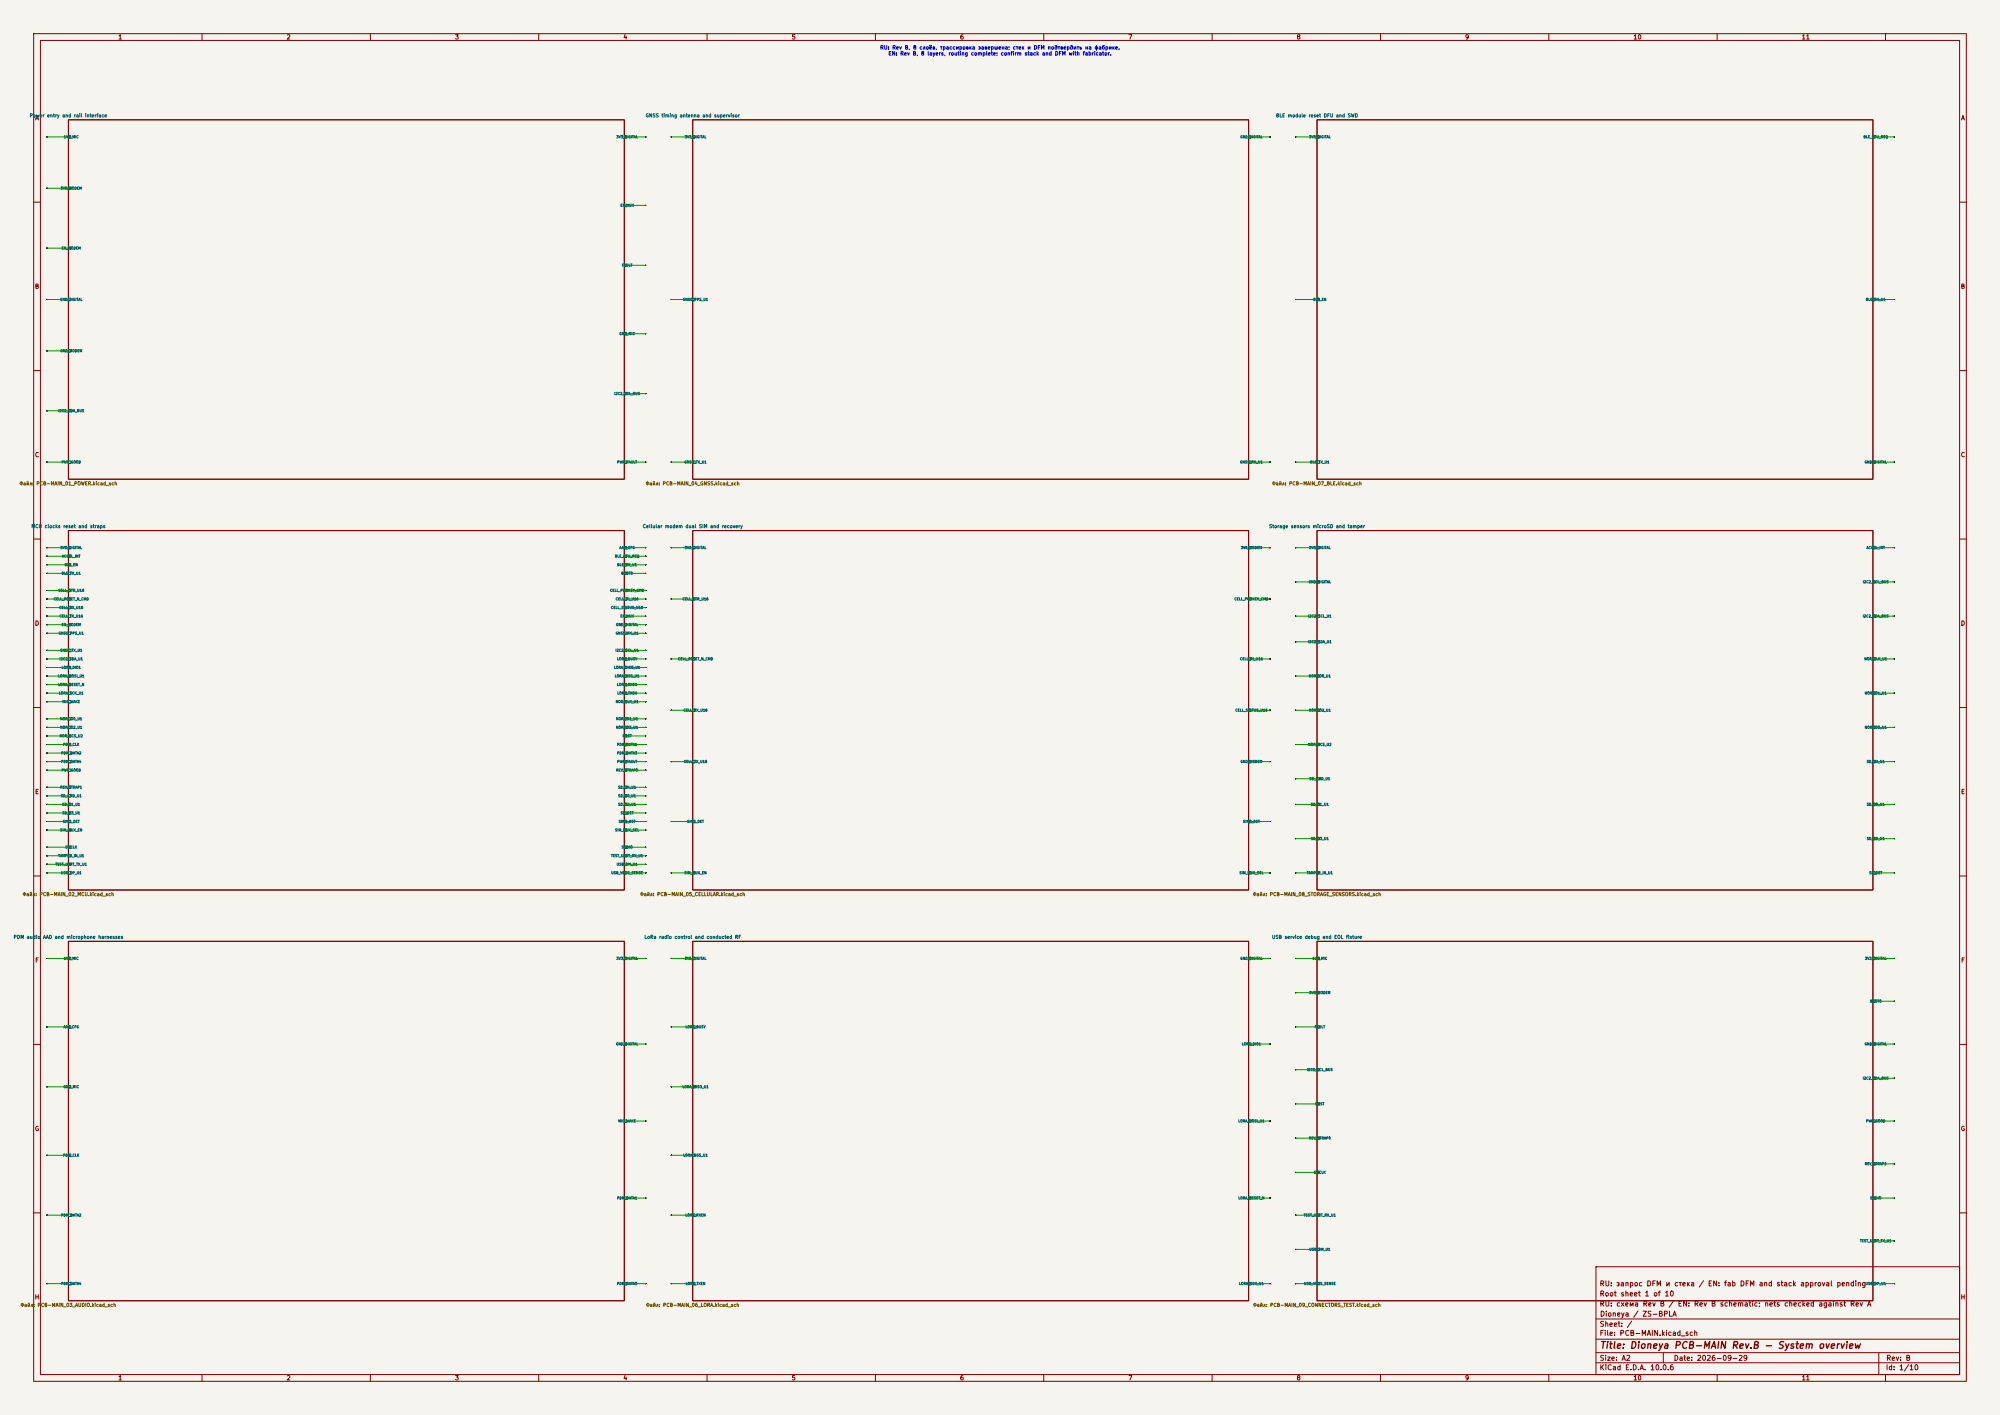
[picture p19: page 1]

RU: Rev B, 8 слоёв, трассировка завершена; стек и DFM подтвердить на фабрике. EN: Rev B, 8 layers, routing complete; confirm stack and DFM with fabricator.

Power entry and rail interface

GNSS timing antenna and supervisor
3V3_DIGITAL EN_AUX

BLE module reset DFU and SWD
3V3_DIGITAL BLE_EN

MCU clocks reset and straps

Cellular modem dual SIM and recovery

Storage sensors microSD and tamper

PDM audio AAD and microphone harnesses

LoRa radio control and conducted RF
3V3_DIGITAL GND_DIGITAL MIC_WAKE PDM_DATA1 PDM_DATA3

USB service debug and EOL fixture

RU: запрос DFM и стека / EN: fab DFM and stack approval pending
Root sheet 1 of 10
RU: схема Rev B / EN: Rev B schematic; nets checked against Rev A
Dioneya / ZS-BPLA
Sheet: /
File: PCB-MAIN.kicad_sch
Title: Dioneya PCB-MAIN Rev.B - System overview

Size: A2 | Rev: B
KiCad E.D.A. 10.0.6 | Id: 1/10

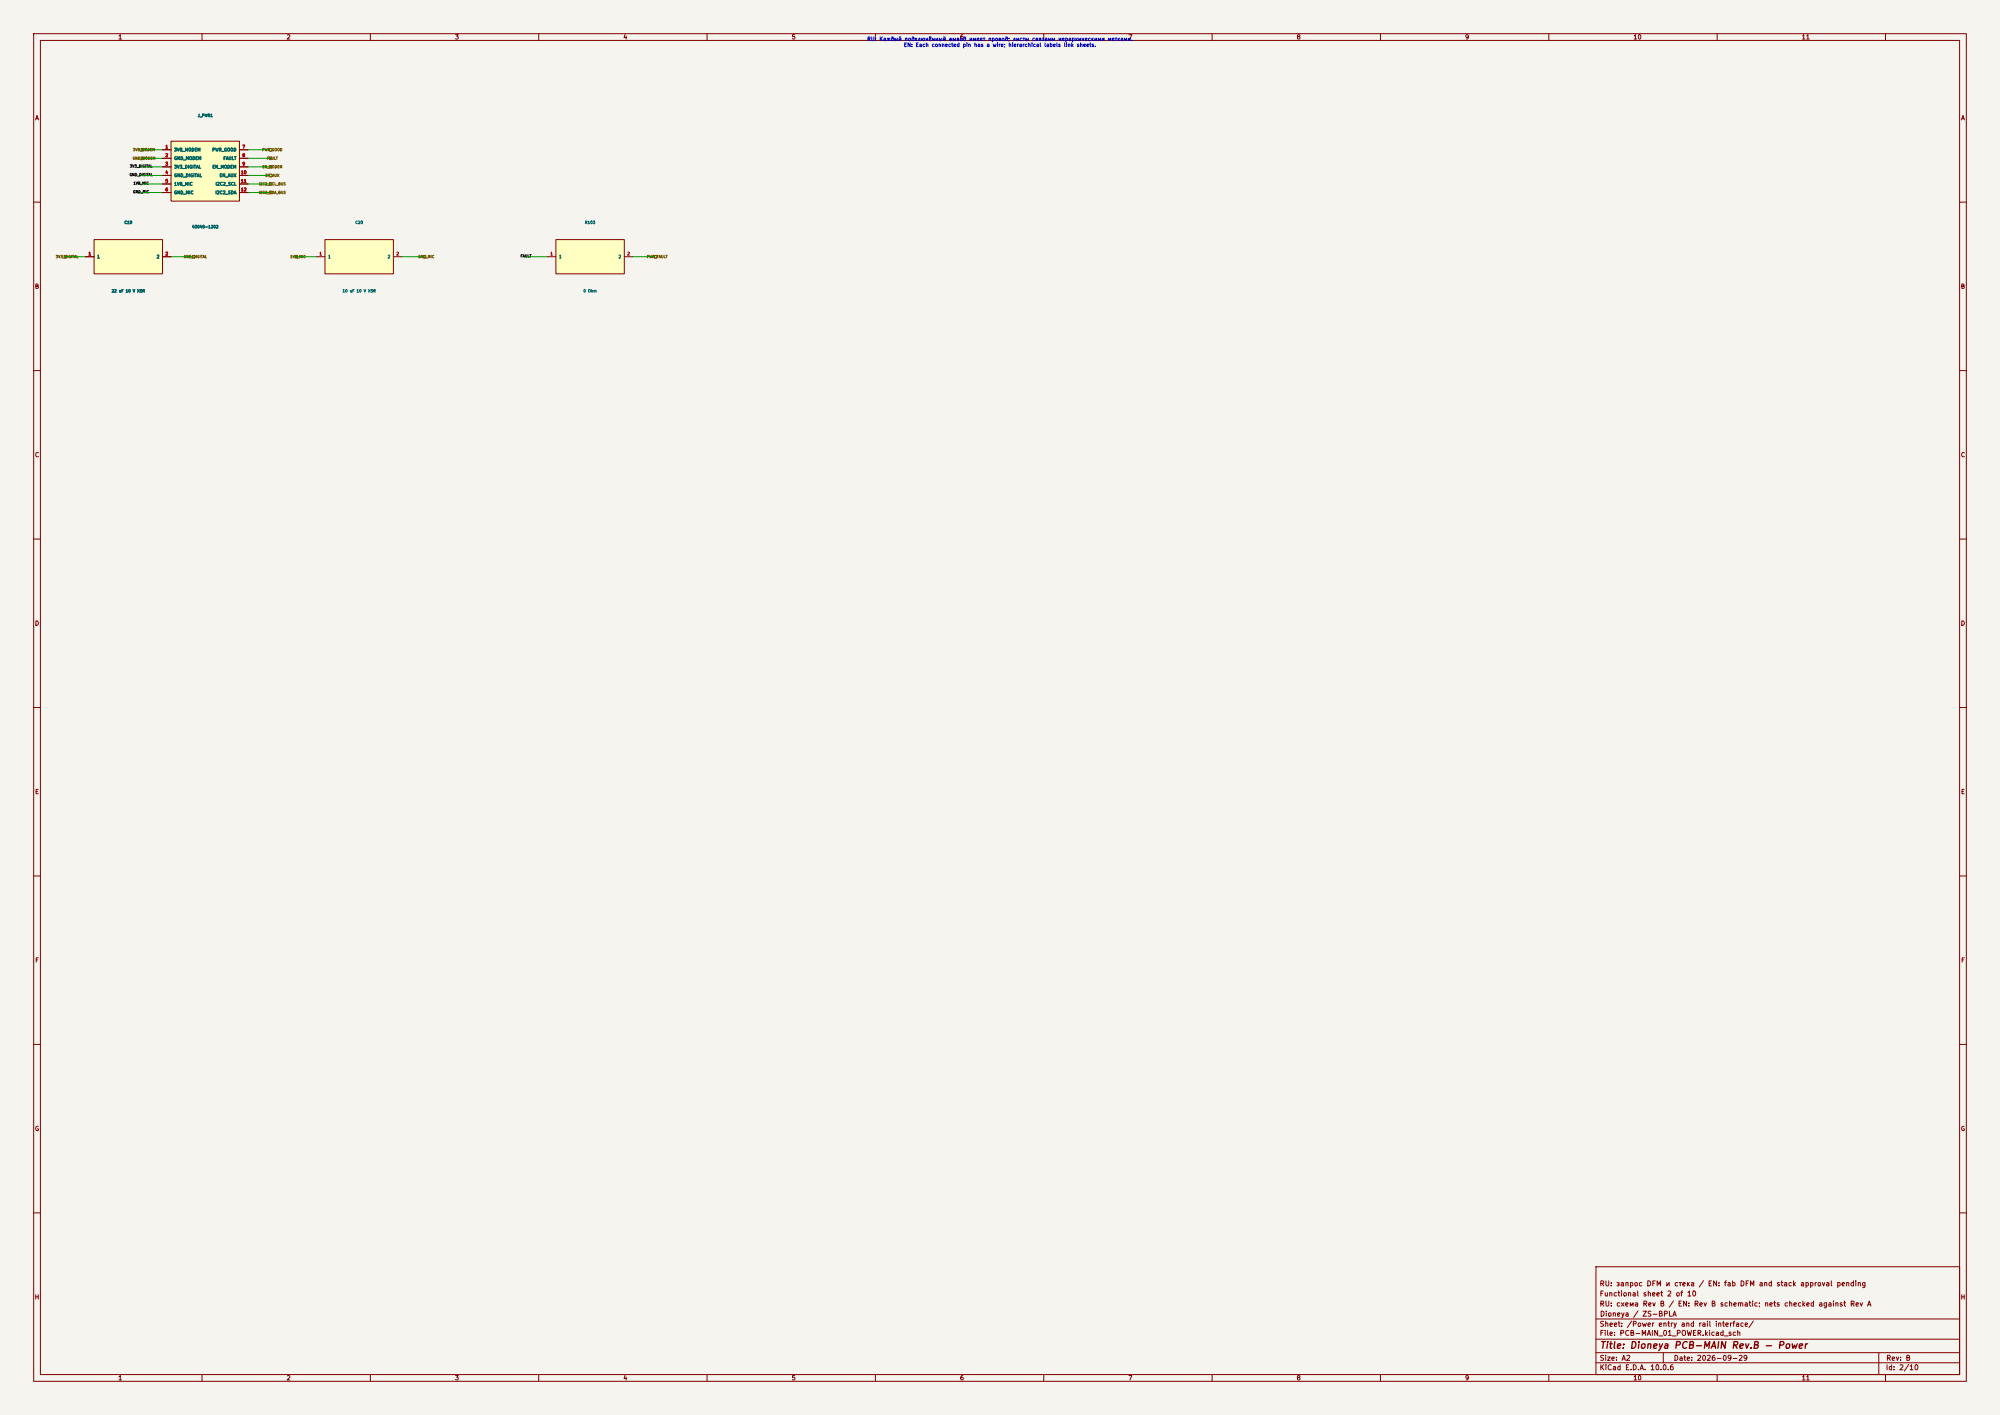
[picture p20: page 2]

RU: запрос DFM и стека / EN: fab DFM and stack approval pending
Functional sheet 2 of 10

Sheet: /Power entry and rail interface/
File: PCB-MAIN_01_POWER.kicad_sch
Title: Dioneya PCB-MAIN Rev.B - Power

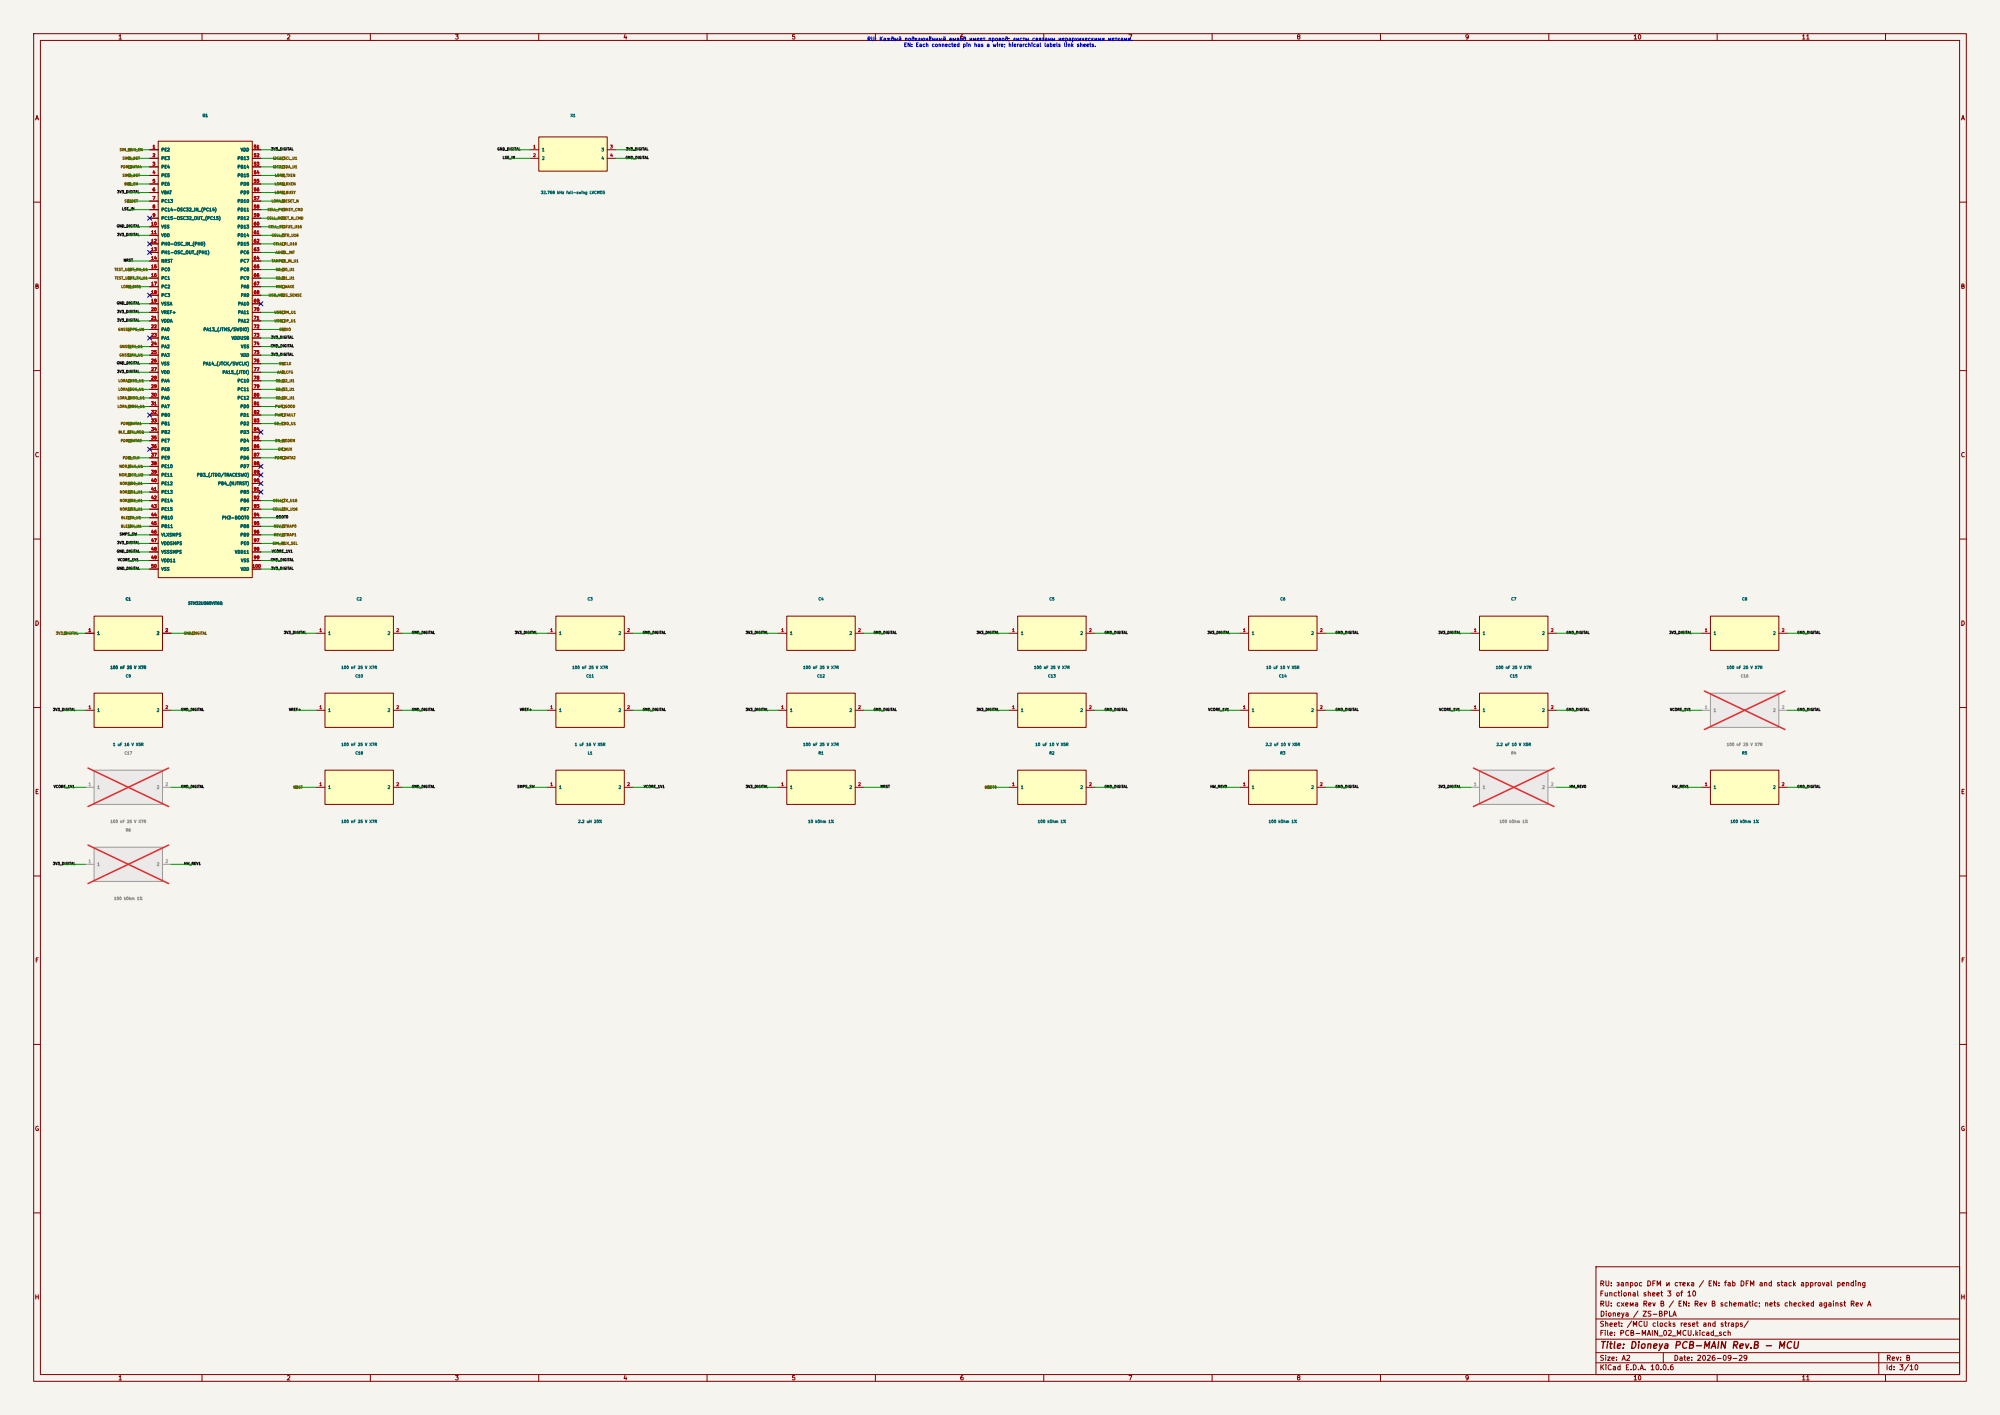
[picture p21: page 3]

RU: Каждый подключённый вывод имеет провод; листы связаны иерархическими метками. EN: Each connected pin has a wire; hierarchical labels link sheets.

32.768 kHz full-swing LVCMOS

RU: запрос DFM и стека / EN: fab DFM and stack approval pending

Sheet: /MCU clocks reset and straps/
File: PCB-MAIN_02_MCU.kicad_sch
Title: Dioneya PCB-MAIN Rev.B - MCU

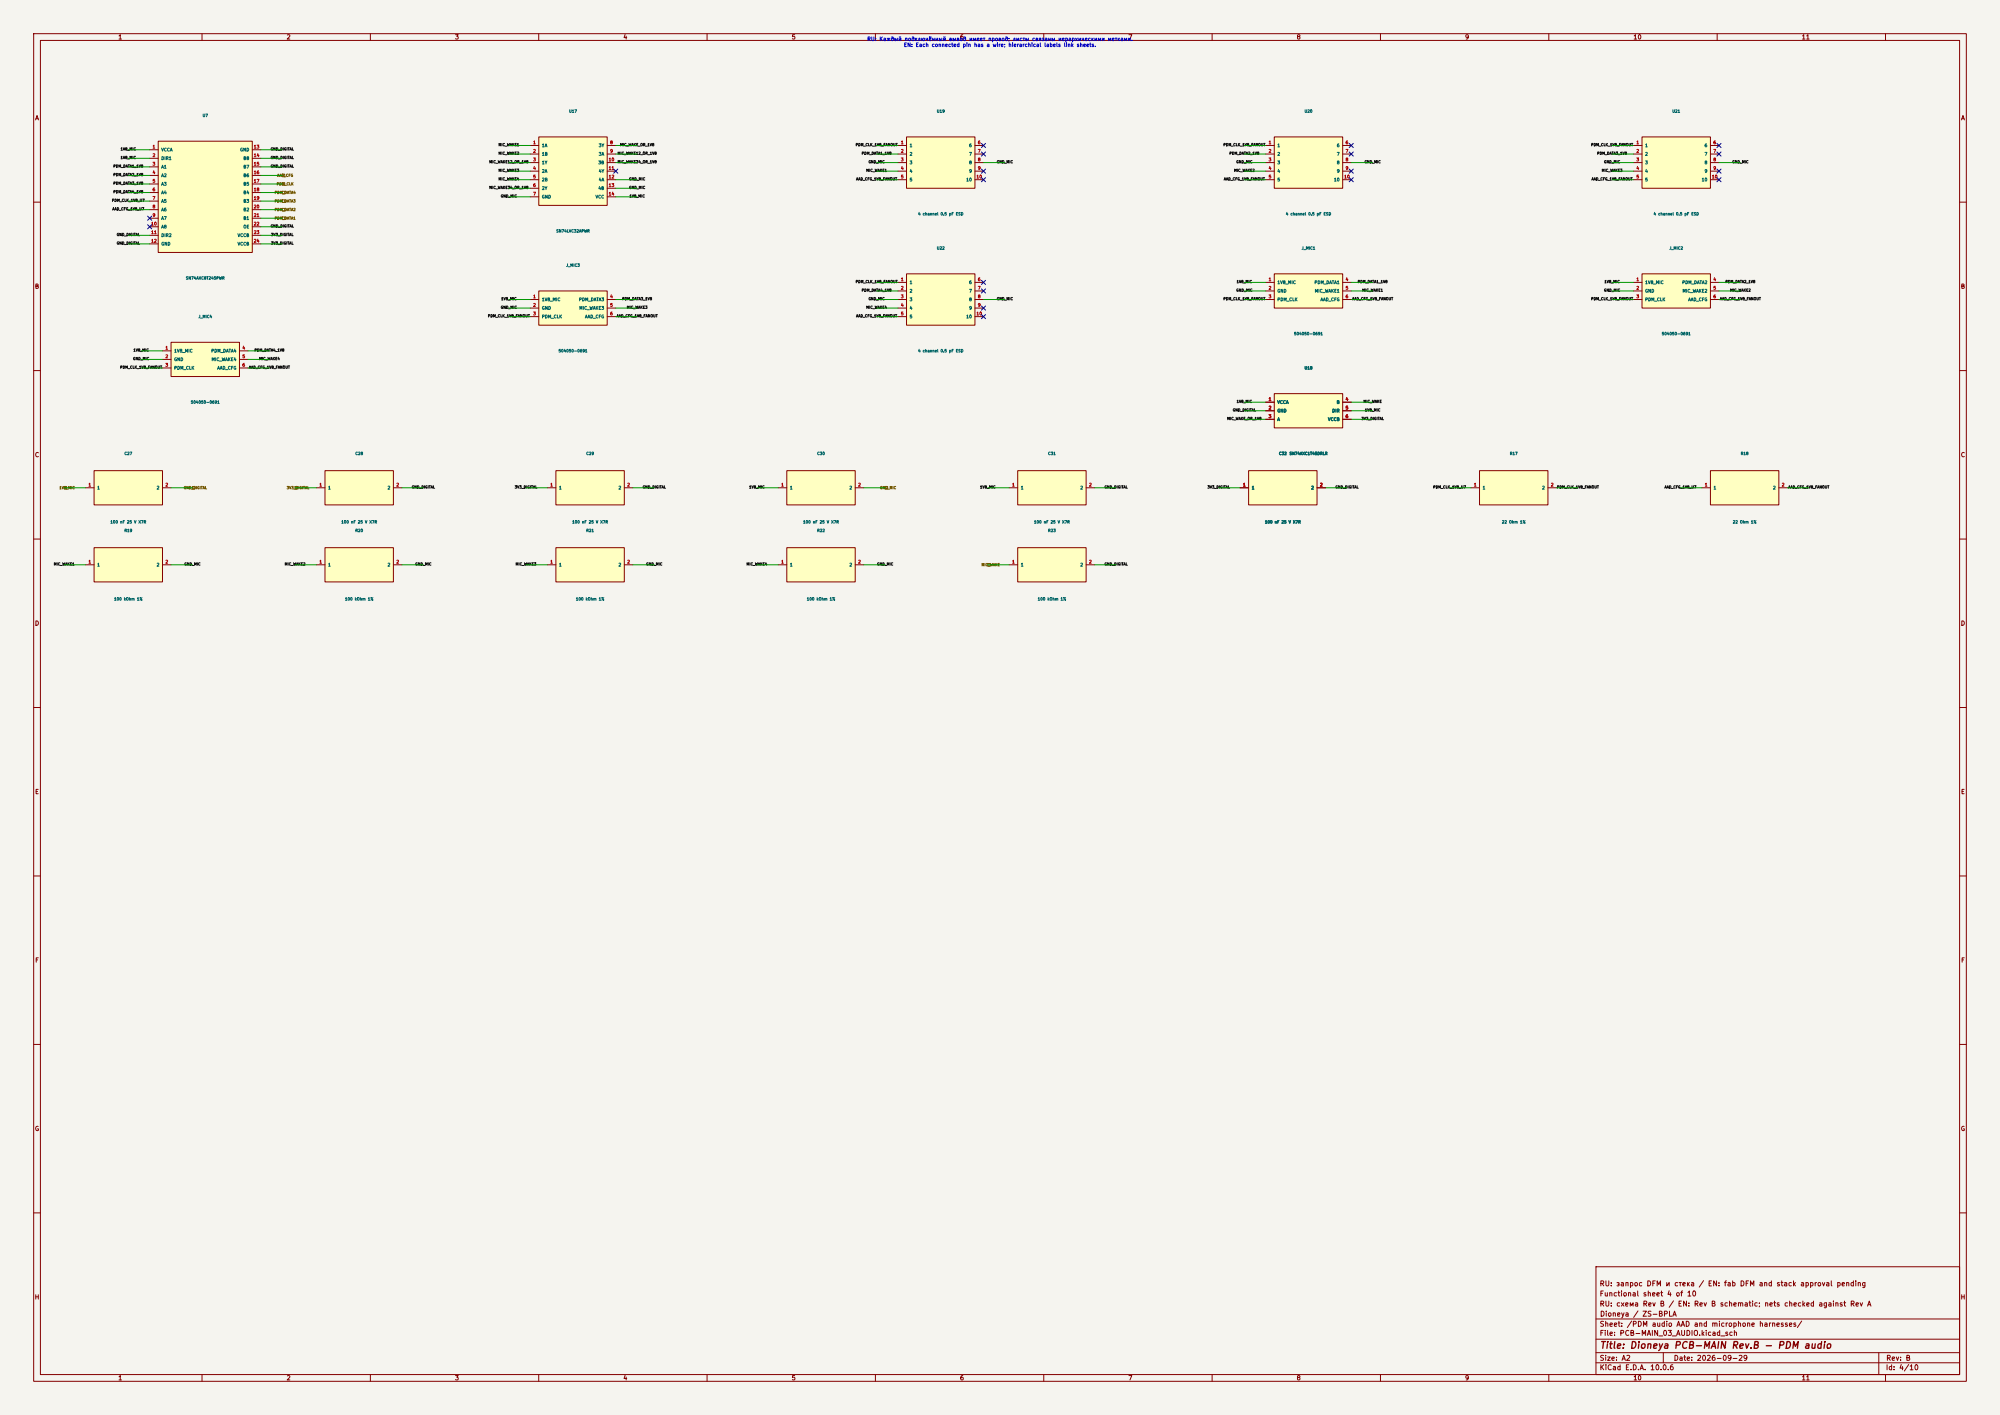
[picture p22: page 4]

PDM_CLK_1V8_FANOUT PDM_DATA3_1V8 GND_MIC MIC_WAKE3 RU: Каждый подключённый вывод имеет провод; листы связаны иерархическими метками. EN: Each connected pin has a wire; hierarchical labels link sheets.

RU: запрос DFM и стека / EN: fab DFM and stack approval pending

Sheet: /PDM audio AAD and microphone harnesses/
File: PCB-MAIN_03_AUDIO.kicad_sch
Title: Dioneya PCB-MAIN Rev.B - PDM audio

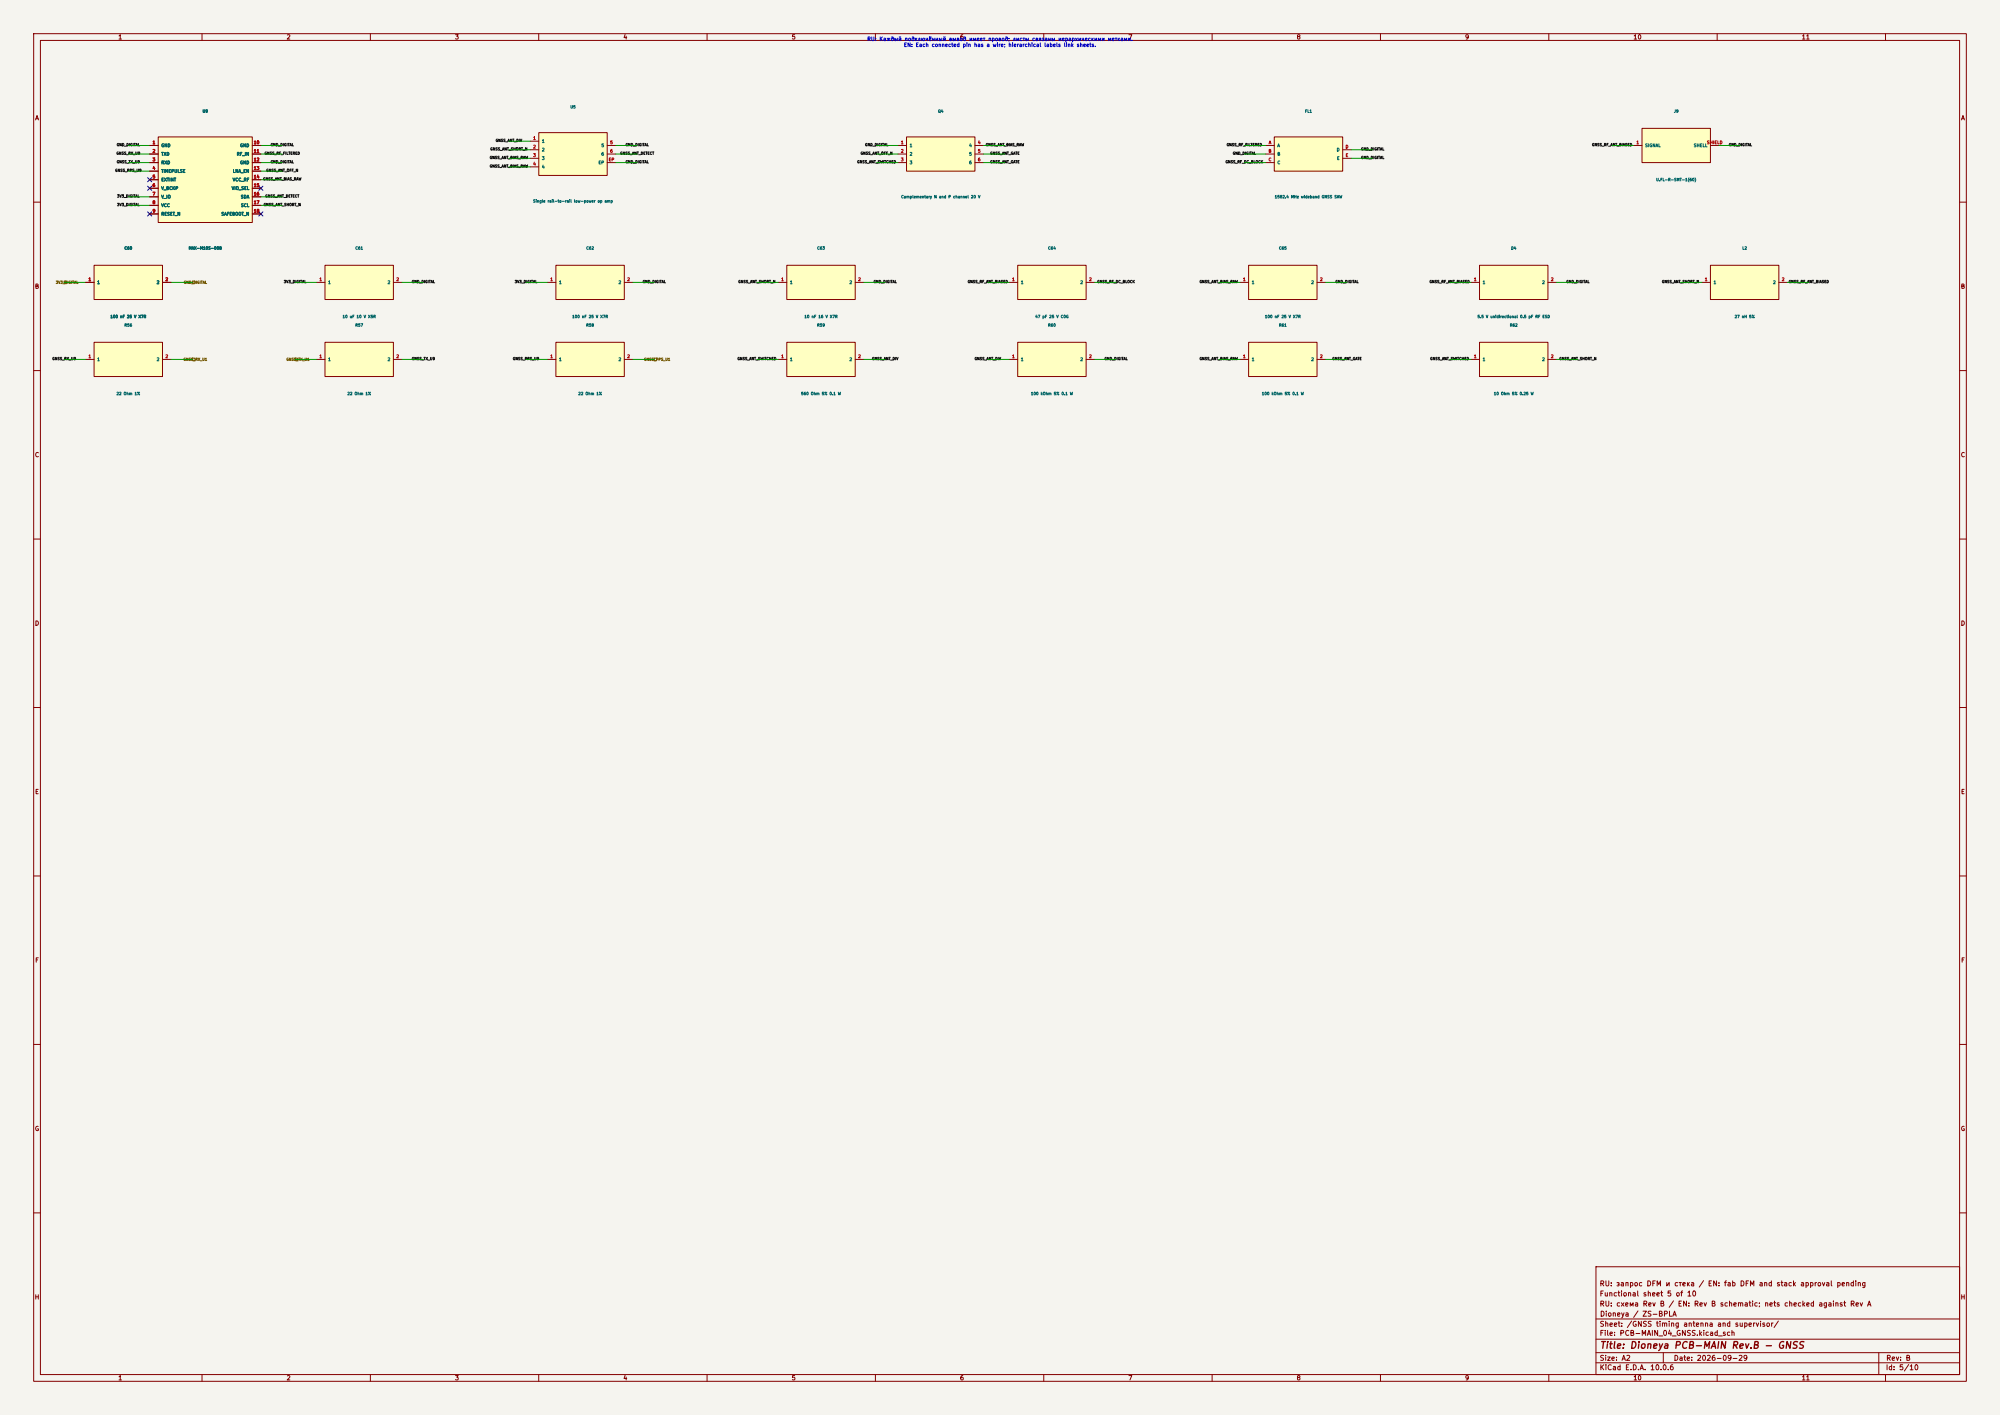
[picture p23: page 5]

1582.4 MHz wideband GNSS SAW

5.5 V unidirectional 0.5 pF RF ESD 1

RU: запрос DFM и стека / EN: fab DFM and stack approval pending

Sheet: /GNSS timing antenna and supervisor/
File: PCB-MAIN_04_GNSS.kicad_sch
Title: Dioneya PCB-MAIN Rev.B - GNSS

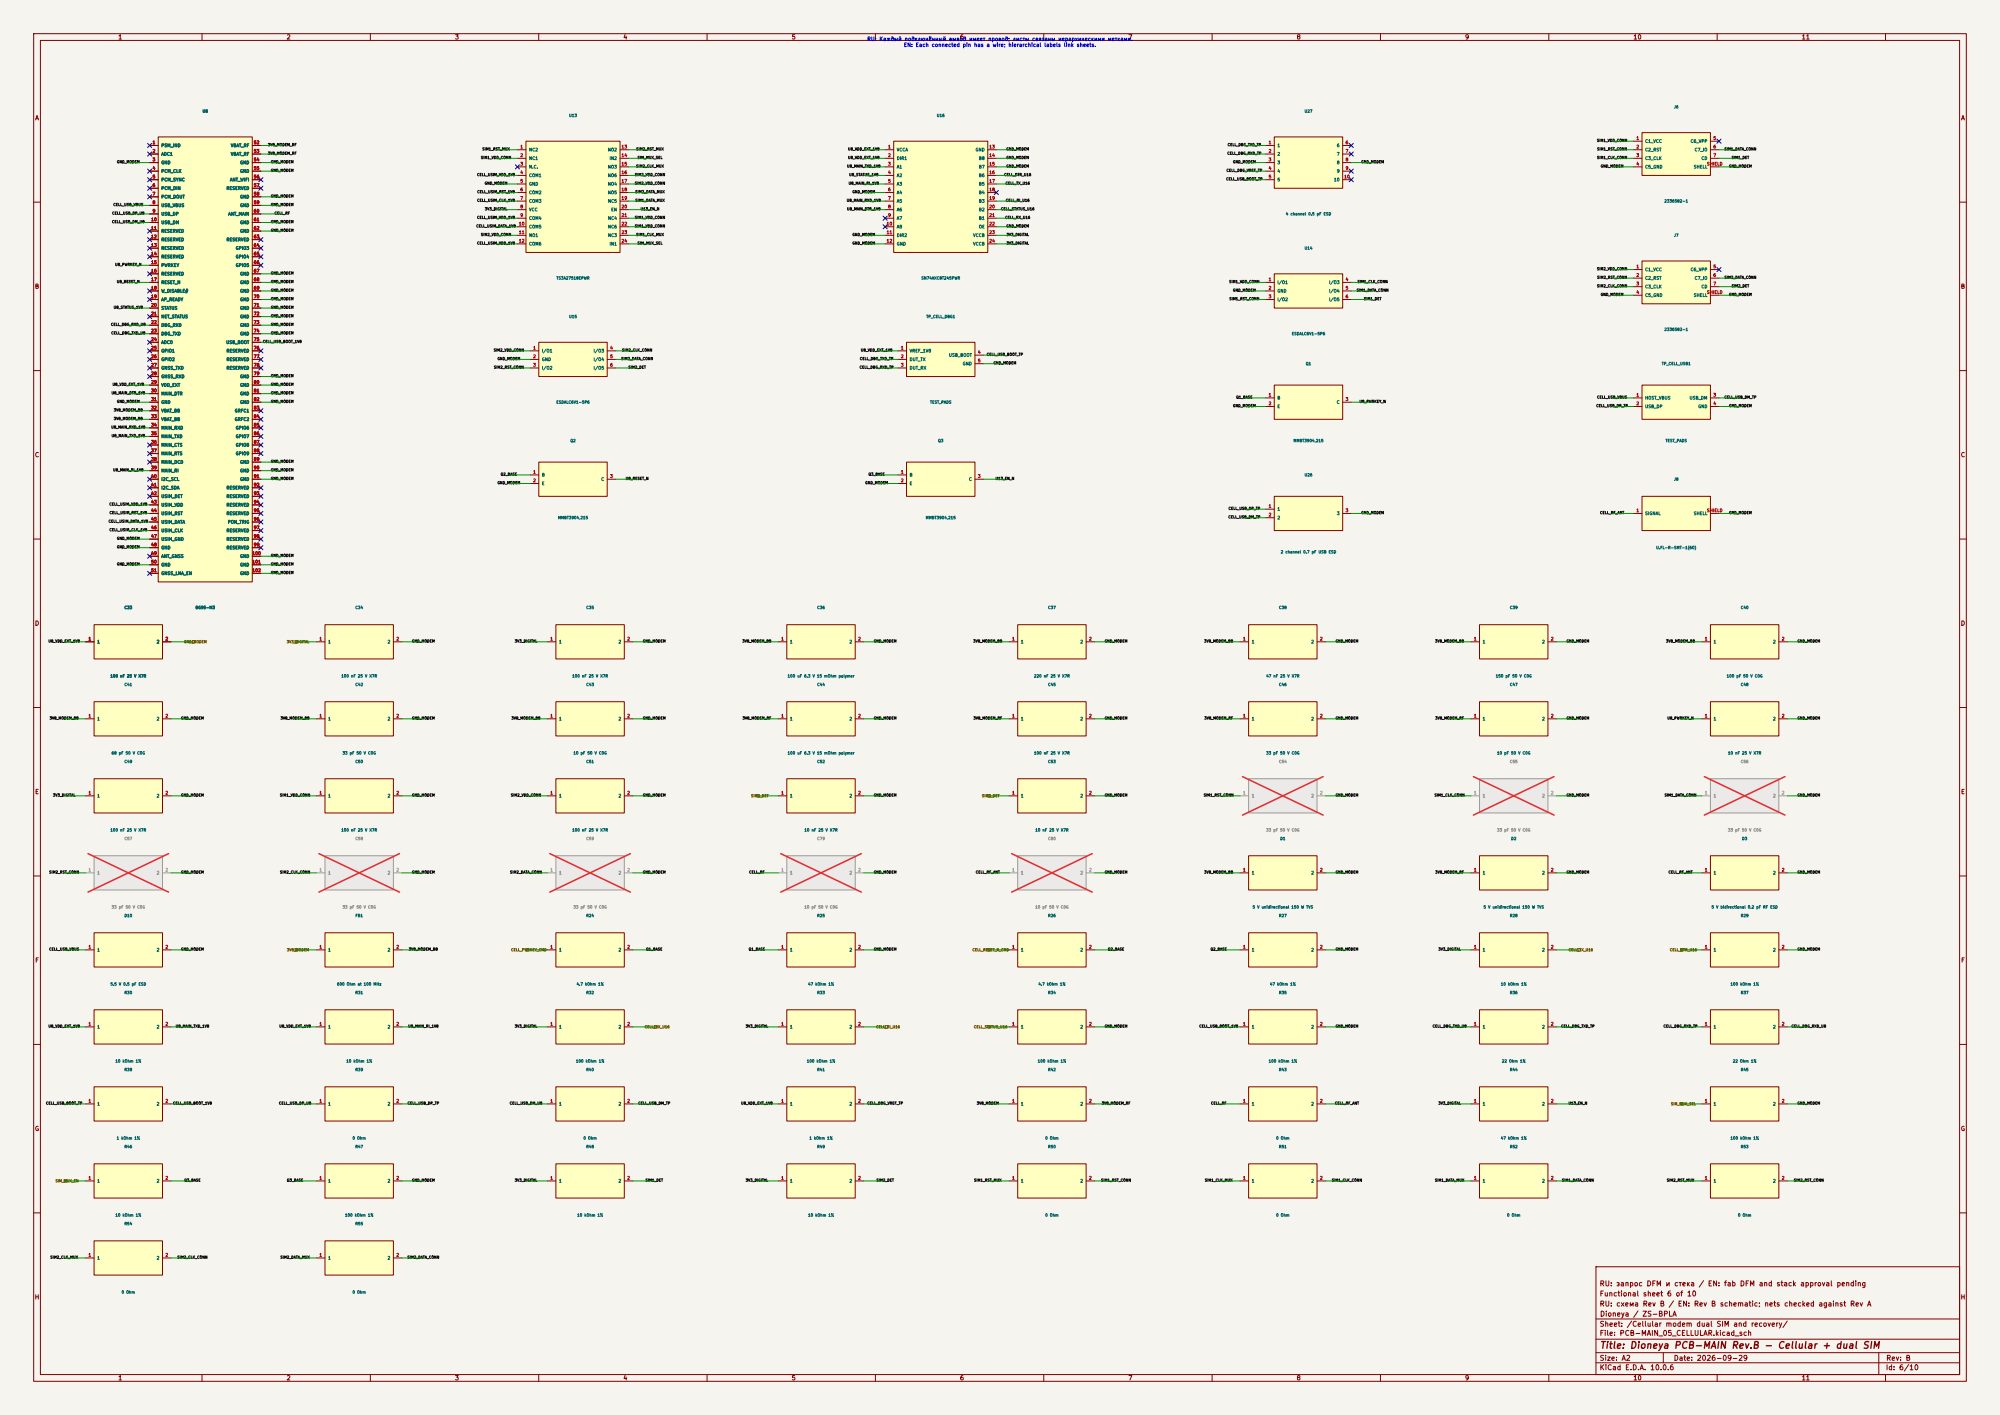
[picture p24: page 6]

RU: Каждый подключённый вывод имеет провод; листы связаны иерархическими метками. EN: Each connected pin has a wire; hierarchical labels link sheets. U8

2 channel 0.7 pF USB ESD

5 V bidirectional 0.2 pF RF ESD 1

RU: запрос DFM и стека / EN: fab DFM and stack approval pending

Sheet: /Cellular modem dual SIM and recovery/
File: PCB-MAIN_05_CELLULAR.kicad_sch
Title: Dioneya PCB-MAIN Rev.B - Cellular + dual SIM


RU: Каждый подключённый вывод имеет провод; листы связаны иерархическими метками. EN: Each connected pin has a wire; hierarchical labels link sheets. U10

5 V bidirectional 0.2 pF RF ESD 1

RU: запрос DFM и стека / EN: fab DFM and stack approval pending

Sheet: /LoRa radio control and conducted RF/
File: PCB-MAIN_06_LORA.kicad_sch
Title: Dioneya PCB-MAIN Rev.B - LoRa


Single non-inverting open-drain buffer 1

RU: запрос DFM и стека / EN: fab DFM and stack approval pending

Sheet: /BLE module reset DFU and SWD/
File: PCB-MAIN_07_BLE.kicad_sch
Title: Dioneya PCB-MAIN Rev.B - BLE


RU: запрос DFM и стека / EN: fab DFM and stack approval pending

Sheet: /Storage sensors microSD and tamper/
File: PCB-MAIN_08_STORAGE_SENSORS.kicad_sch
Title: Dioneya PCB-MAIN Rev.B - Storage + sensors


2 channel 0.7 pF USB ESD 1

RU: запрос DFM и стека / EN: fab DFM and stack approval pending

Sheet: /USB service debug and EOL fixture/
File: PCB-MAIN_09_CONNECTORS_TEST.kicad_sch
Title: Dioneya PCB-MAIN Rev.B - USB + debug





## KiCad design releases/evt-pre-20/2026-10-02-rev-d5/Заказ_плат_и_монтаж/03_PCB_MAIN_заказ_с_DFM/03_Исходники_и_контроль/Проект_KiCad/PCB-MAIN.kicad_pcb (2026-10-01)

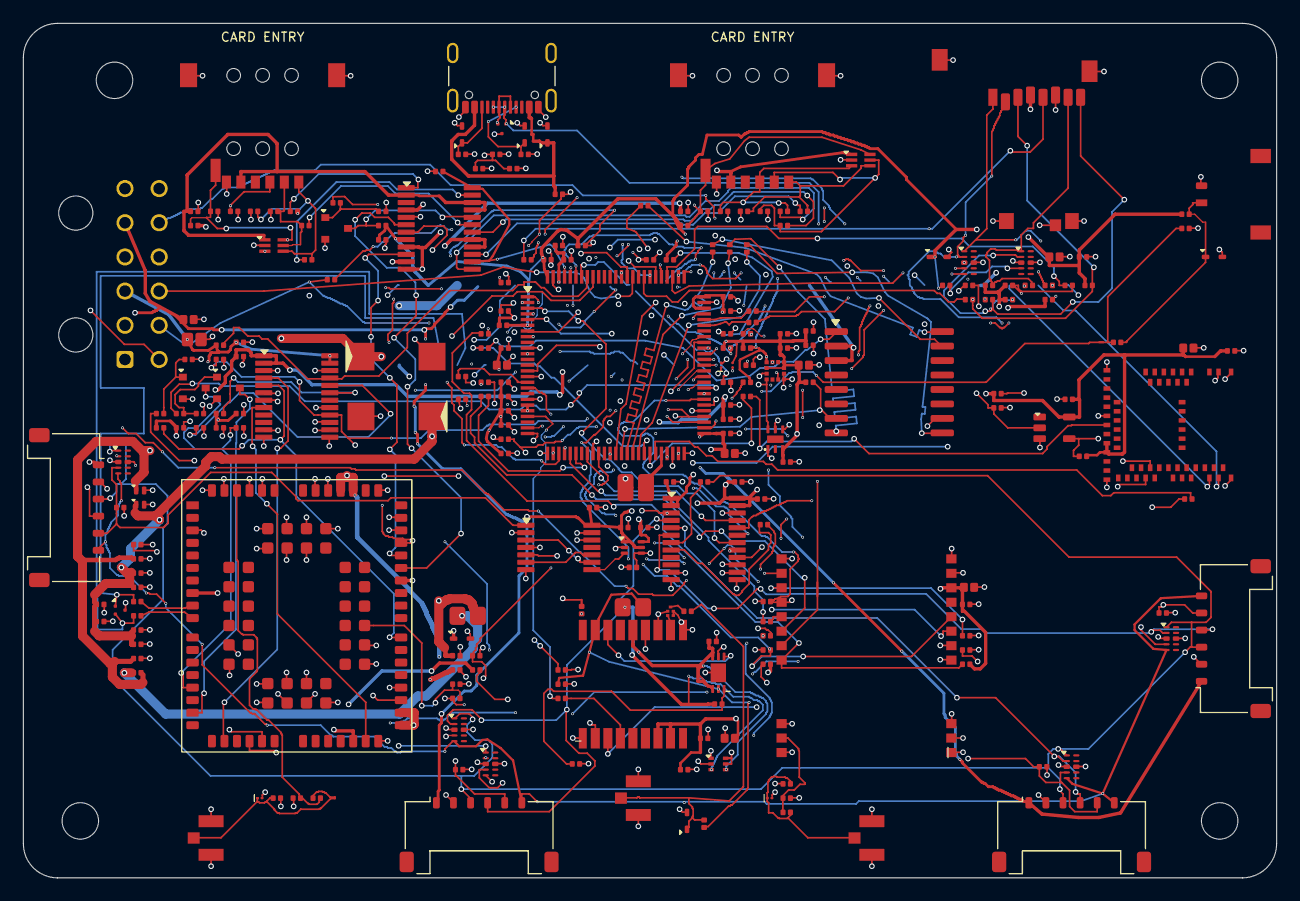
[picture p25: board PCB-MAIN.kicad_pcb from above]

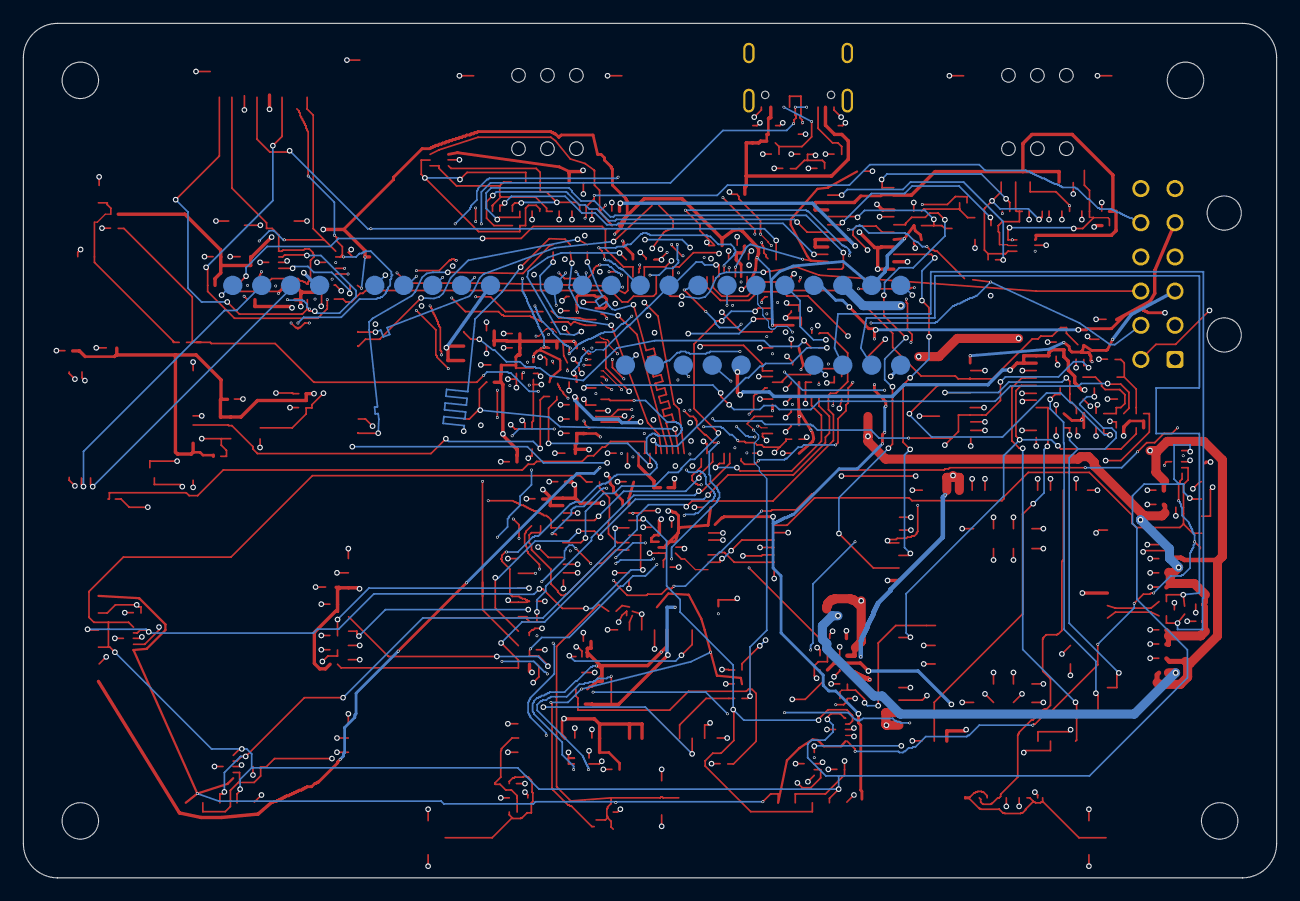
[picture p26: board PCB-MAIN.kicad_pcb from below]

Board: 8 copper layers, 110.0 x 75.0 mm, 251 parts (5 on the bottom side), 185 nets.

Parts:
C1, C2, C3, C4, C5, C7, C8, C10, C12, C16, C17, C18, C21, C23, C25, C26, C27, C28, C29, C30, C31, C32, C33, C34, C35, C45, C49, C50, C51, C60, C62, C65, C66, C68, C71, C73, C74: GRM155R71E104KE14D
C6, C13, C20, C24, C61, C67, C72, C75: GRM188R61A106KE69D
C9, C11, C22: GRM155R61C105KA12D
C14, C15: GRM155R61A225KE15D
C19: GRM21BR61A226ME44L
C36, C44: T520D107M006ATE015; KEMET_T52X_D_7343-31_DensityB
C37: GRM155R71E224KE14D
C38: GRM155R71E473KA01D
C39: GRM1555C1H151JA01D
C40: GRM1555C1H101JA01D
C41: GRM1555C1H680JA01D
C42, C46, C54, C55, C56, C57, C58, C59: GRM1555C1H330JA01D
C43, C47, C69, C70, C79, C80: GRM1555C1H100JA01D
C48, C52, C53, C76, C78: GRM155R71E103KA01D
C63: GRM155R71C103KA01D
C64: GRM1555C1E470JA01D
C77: GRM155R72A472KA01D
D1, D2: PESD5V0S1UL; Nexperia_PESD5V0S1UL_SOD882
D3, D5: PESD5V0C1BSF; PESD5V0C1BSF_SOD962-2
D4, D6, D7, D8, D9, D10, D11: TPD1E05U06DYAR; TI_DYA0002A_SOD523
FB1: BLM31KN601SN1L
FL1: ABSES5AF-L100KM; Abracon_ABSES5AF_1109-5
H1, H2, H3, H4: M3_NPTH
J6, J7: 2336582-1; TE_2336582-1_NanoSIM
J8, J9, J10: U.FL-R-SMT-1(60); Hirose_U.FL-R-SMT-1
J11: USB4105-GF-A-120; USB_C_Receptacle_GCT_USB4105-xx-A_16P_TopMnt_Horizontal
J12: MEM2052-00-195-00-A; GCT_MEM2052-00-195-00-A
J13: 504050-0291; Molex_504050-0291_PicoLock-2
J_MIC1, J_MIC2, J_MIC3, J_MIC4: 504050-0691; Molex_Pico-Lock_504050-0691_1x06-1MP_P1.50mm_Horizontal
J_PWR1: 43045-1202; Molex_43045-1202_MicroFit-12_RA
L1: LQH32PN2R2NN0L
L2: LQW15AN27NJ00D
Q1, Q2, Q3: MMBT3904,215; Nexperia_MMBT3904_SOT23
Q4: Si1016X-T1-GE3; Vishay_Si1016X_SC-89
R1, R7, R28, R30, R31, R46, R48, R49, R67, R68, R76, R78, R85, R86, R87, R88, R89, R90, R99: ERJ-2RKF1002X
R2, R3, R4, R5, R6, R19, R20, R21, R22, R23, R29, R32, R33, R34, R35, R45, R47, R63, R64, R65, R66, R77, R96: ERJ-2RKF1003X
R8, R9, R10, R11, R12, R15, R16, R17, R18, R36, R37, R56, R57, R58, R69, R70, R71, R72, R74, R75, R79, R80, R81, R82, R83, R84, R91, R92, R101: ERJ-2RKF22R0X
R13, R14: ERJ-2RKF2201X
R24, R26: ERJ-2RKF4701X
R25, R27, R44: ERJ-2RKF4702X
R38, R41, R95, R100, R102: ERJ-2RKF1001X
R39, R40, R42, R43, R50, R51, R52, R53, R54, R55, R73, R98, R103: ERJ-2GE0R00X
R59: ERJ-2GEJ561X
R60, R61: ERJ-2GEJ104X
R62: ERJ-8GEYJ100V
R93, R94: ERJ-2RKF5101X
R97: ERJ-2RKF1004X
TP_BLE_SWD1: TEST_PADS
TP_CELL_DBG1: TEST_PADS
TP_CELL_USB1: TEST_PADS
TP_EOL1: TEST_PADS
TP_MCU_SWD1: TEST_PADS
U1: STM32U585VIT6Q; ST_STM32U585_LQFP100_1L
U2: W25Q512JVFIQ; Winbond_W25Q512JV_PackageF_IPC_Candidate
U3: LIS2DW12TR; ST_LIS2DW12_LGA-12L
U4: STTS22HTR; STTS22H_UDFN-6L
U5: LT6000IDCB#TRMPBF; LT6000_DCB-7
U6: SN74LVC1G07DBVR; TI_DBV0005A_SOT23-5
U7, U16: SN74AXC8T245PWR; TI_PW0024A_TSSOP24
U8: BG95-M3; Quectel_BG95-M3_LGA-102
U9: MAX-M10S-00B; u-blox_MAX-M10S_LCC-18
U10: E22-900M22S; Ebyte_E22-M22S_Castellated-22
U11: MDBT50Q-P1MV2; Raytac_MDBT50Q-P1MV2
U13: TS3A27518EPWR; TI_PW0024A_TSSOP24
U14, U15: ESDALC6V1-5P6; ST_ESDALC6V1-5P6_SOT666
U17: SN74LVC32APWR; TI_PW0014A_TSSOP14
U18: SN74AXC1T45DRLR; TI_DRL0006A_SOT6
U19, U20, U21, U22, U23, U24, U27: TPD4E05U06DQAR; TI_DQA0010A_USON10
U25, U26: TPD2EUSB30DRTR; TI_DRT0003A_IPC_Candidate
X1: SiT1552AI-JE-DCC-32.768D; SiT1552_JE_CSP-4

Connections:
1V8_MIC: C20.1, C27.1, C30.1, C31.1, J_MIC1.1, J_MIC2.1, J_MIC3.1, J_MIC4.1, J_PWR1.5, TP_EOL1.4, U7.1, U7.2, U17.14, U18.1, U18.5
3V3_DIGITAL: C1.1, C2.1, C3.1, C4.1, C5.1, C6.1, C7.1, C8.1, C9.1, C10.1, C11.1, C12.1, C13.1, C19.1, C21.1, C22.1, C23.1, C24.1, C25.1, C26.1, C28.1, C29.1, C32.1, C34.1, C35.1, C49.1, C60.1, C61.1, C62.1, C66.1, C67.1, C71.1, C72.1, C73.1, C74.1, C75.1, D11.1, J12.4, J_PWR1.3, R1.1, R4.1, R6.1, R7.1, R13.1, R14.1, R28.1, R32.1, R33.1, R44.1, R48.1, R49.1, R67.1, R68.1, R76.1, R78.1, R85.1, R86.1, R87.1, R88.1, R89.1, R90.1, R99.1, TP_BLE_SWD1.1, TP_EOL1.2, TP_MCU_SWD1.1, U1.6, U1.11, U1.20, U1.21, U1.27, U1.47, U1.51, U1.73, U1.75, U1.100, U2.2, U2.3, U3.2, U3.9, U3.10, U4.3, U6.5, U7.23, U7.24, U9.7, U9.8, U10.9, U11.28, U11.30, U13.8, U16.23, U16.24, U18.6, X1.3
3V8_MODEM: FB1.1, J_PWR1.1, R42.1, TP_EOL1.3
3V8_MODEM_BB: C36.1, C37.1, C38.1, C39.1, C40.1, C41.1, C42.1, C43.1, D1.1, FB1.2, U8.32, U8.33
3V8_MODEM_RF: C44.1, C45.1, C46.1, C47.1, D2.1, R42.2, U8.52, U8.53
AAD_CFG: U1.77, U7.16
AAD_CFG_1V8_FANOUT: J_MIC1.6, J_MIC2.6, J_MIC3.6, J_MIC4.6, R18.2, U19.5, U20.5, U21.5, U22.5
AAD_CFG_1V8_U7: R18.1, U7.8
ACCEL_INT: U1.63, U3.12
BLE_DFU_REQ: R76.2, U1.34, U11.39
BLE_EN: R77.1, U1.5, U6.2
BLE_RX_U1: R74.2, U1.45
BLE_RX_U11: R74.1, U11.22
BLE_TX_U1: R75.1, U1.44
BLE_TX_U11: R75.2, U11.24
BOOT0: R2.1, TP_EOL1.9, U1.94
CELL_DBG_RXD_TP: R37.1, TP_CELL_DBG1.3, U27.2
CELL_DBG_RXD_U8: R37.2, U8.22
CELL_DBG_TXD_TP: R36.2, TP_CELL_DBG1.2, U27.1
CELL_DBG_TXD_U8: R36.1, U8.23
CELL_DBG_VREF_TP: R41.2, U27.4
CELL_DTR_U16: R29.1, U1.61, U16.16
CELL_PWRKEY_CMD: R24.1, U1.58
CELL_RESET_N_CMD: R26.1, U1.59
CELL_RF: C79.1, R43.1, U8.60
CELL_RF_ANT: C80.1, D3.1, J8.1, R43.2
CELL_RI_U16: R33.2, U1.62, U16.19
CELL_RX_U16: R32.2, U1.93, U16.21
CELL_STATUS_U16: R34.1, U1.60, U16.20
CELL_TX_U16: R28.2, U1.92, U16.17
CELL_USB_BOOT_1V8: R35.1, R38.2, U8.75
CELL_USB_BOOT_TP: R38.1, TP_CELL_DBG1.4, U27.5
CELL_USB_DM_TP: R40.2, TP_CELL_USB1.3, U26.2
CELL_USB_DM_U8: R40.1, U8.10
CELL_USB_DP_TP: R39.2, TP_CELL_USB1.2, U26.1
CELL_USB_DP_U8: R39.1, U8.9
CELL_USB_VBUS: D10.1, TP_CELL_USB1.1, U8.8
CELL_USIM_CLK_1V8: U8.46, U13.7
CELL_USIM_DATA_1V8: U8.45, U13.10
CELL_USIM_RST_1V8: U8.44, U13.6
CELL_USIM_VDD_1V8: U8.43, U13.4, U13.9, U13.12
EN_AUX: J_PWR1.10, U1.86
EN_MODEM: J_PWR1.9, U1.85
FAULT: J_PWR1.8, R103.1, TP_EOL1.8
GND_DIGITAL: C1.2, C2.2, C3.2, C4.2, C5.2, C6.2, C7.2, C8.2, C9.2, C10.2, C11.2, C12.2, C13.2, C14.2, C15.2, C16.2, C17.2, C18.2, C19.2, C21.2, C22.2, C23.2, C24.2, C25.2, C26.2, C27.2, C28.2, C29.2, C31.2, C32.2, C60.2, C61.2, C62.2, C63.2, C65.2, C66.2, C67.2, C68.2, C69.2, C70.2, C71.2, C72.2, C73.2, C74.2, C75.2, C76.2, C77.2, C78.2, D4.2, D5.2, D6.2, D7.2, D8.2, D9.2, D11.2, FL1.B, FL1.D, FL1.E, J9.SHIELD, J10.SHIELD, J11.A1, J11.A12, J11.B1, J11.B12, J12.6, J12.SHIELD, J13.2, J_PWR1.4, Q4.1, R2.2, R3.2, R5.2, R23.2, R60.2, R63.2, R64.2, R65.2, R66.2, R77.2, R93.2, R94.2, R96.2, R97.2, R98.2, TP_BLE_SWD1.4, TP_EOL1.1, TP_MCU_SWD1.5, U1.10, U1.19, U1.26, U1.48, U1.50, U1.74, U1.99, U2.10, U3.3, U3.6, U3.7, U3.8, U4.4, U4.5, U5.5, U5.EP, U6.3, U7.11, U7.12, U7.13, U7.14, U7.15, U7.22, U9.1, U9.10, U9.12, U10.1, U10.2, U10.3, U10.4, U10.5, U10.10, U10.11, U10.12, U10.20, U10.22, U11.1, U11.2, U11.15, U11.33, U11.55, U18.2, U23.3, U23.8, U24.3, U24.8, U25.3, X1.1, X1.4
GND_MIC: C20.2, C30.2, J_MIC1.2, J_MIC2.2, J_MIC3.2, J_MIC4.2, J_PWR1.6, R19.2, R20.2, R21.2, R22.2, U17.7, U17.12, U17.13, U19.3, U19.8, U20.3, U20.8, U21.3, U21.8, U22.3, U22.8
GND_MODEM: C33.2, C34.2, C35.2, C36.2, C37.2, C38.2, C39.2, C40.2, C41.2, C42.2, C43.2, C44.2, C45.2, C46.2, C47.2, C48.2, C49.2, C50.2, C51.2, C52.2, C53.2, C54.2, C55.2, C56.2, C57.2, C58.2, C59.2, C79.2, C80.2, D1.2, D2.2, D3.2, D10.2, J6.4, J6.SHIELD, J7.4, J7.SHIELD, J8.SHIELD, J_PWR1.2, Q1.2, Q2.2, Q3.2, R25.2, R27.2, R29.2, R34.2, R35.2, R45.2, R47.2, TP_CELL_DBG1.5, TP_CELL_USB1.4, U8.3, U8.31, U8.47, U8.48, U8.50, U8.54, U8.55, U8.58, U8.59, U8.61, U8.62, U8.67, U8.68, U8.69, U8.70, U8.71, U8.72, U8.73, U8.74, U8.79, U8.80, U8.81, U8.82, U8.89, U8.90, U8.91, U8.100, U8.101, U8.102, U13.5, U14.2, U15.2, U16.6, U16.11, U16.12, U16.13, U16.14, U16.15, U16.22, U26.3, U27.3, U27.8
GNSS_ANT_BIAS_RAW: C65.1, Q4.4, R61.1, U5.3, U5.4, U9.14
GNSS_ANT_DETECT: U5.6, U9.16
GNSS_ANT_DIV: R59.2, R60.1, U5.1
GNSS_ANT_GATE: Q4.5, Q4.6, R61.2
GNSS_ANT_OFF_N: Q4.2, U9.13
GNSS_ANT_SHORT_N: C63.1, L2.1, R62.2, U5.2, U9.17
GNSS_ANT_SWITCHED: Q4.3, R59.1, R62.1
GNSS_PPS_U1: R58.2, U1.22
GNSS_PPS_U9: R58.1, U9.4
GNSS_RF_ANT_BIASED: C64.1, D4.1, J9.1, L2.2
GNSS_RF_DC_BLOCK: C64.2, FL1.C
GNSS_RF_FILTERED: FL1.A, U9.11
GNSS_RX_U1: R56.2, U1.25
GNSS_RX_U9: R56.1, U9.2
GNSS_TX_U1: R57.1, U1.24
GNSS_TX_U9: R57.2, U9.3
HW_REV0: R3.1, R4.2
HW_REV1: R5.1, R6.2
I2C2_SCL_BUS: J_PWR1.11, R13.2, R15.2, TP_EOL1.12, U3.1, U4.1
I2C2_SCL_U1: R15.1, U1.52
I2C2_SDA_BUS: J_PWR1.12, R14.2, R16.2, TP_EOL1.13, U3.4, U4.6
I2C2_SDA_U1: R16.1, U1.53
LORA_BUSY: R66.1, U1.56, U10.14
LORA_DIO1: R65.1, U1.17, U10.13
LORA_MISO_U1: R72.2, U1.30
LORA_MISO_U10: R72.1, U10.16
LORA_MOSI_U1: R71.1, U1.31
LORA_MOSI_U10: R71.2, U10.17
LORA_NSS_U1: R69.1, U1.28
LORA_NSS_U10: R68.2, R69.2, U10.19
LORA_RESET_N: C68.1, R67.2, U1.57, U10.15
LORA_RF_ANT: C70.1, D5.1, J10.1, R73.2
LORA_RF_MODULE: C69.1, R73.1, U10.21
LORA_RXEN: R64.1, U1.55, U10.6
LORA_SCK_U1: R70.1, U1.29
LORA_SCK_U10: R70.2, U10.18
LORA_TXEN: R63.1, U1.54, U10.7
LSE_IN: U1.8, X1.2
MIC_WAKE: R23.1, U1.67, U18.4
MIC_WAKE1: J_MIC1.5, R19.1, U17.1, U19.4
MIC_WAKE2: J_MIC2.5, R20.1, U17.2, U20.4
MIC_WAKE3: J_MIC3.5, R21.1, U17.4, U21.4
MIC_WAKE4: J_MIC4.5, R22.1, U17.5, U22.4
MIC_WAKE12_OR_1V8: U17.3, U17.9
MIC_WAKE34_OR_1V8: U17.6, U17.10
MIC_WAKE_OR_1V8: U17.8, U18.3
NOR_CLK_U1: R8.1, U1.38
NOR_CLK_U2: R8.2, U2.16
NOR_IO0_U1: R9.1, U1.40
NOR_IO0_U2: R9.2, U2.15
NOR_IO1_U1: R10.1, U1.41
NOR_IO1_U2: R10.2, U2.8
NOR_IO2_U1: R11.1, U1.42
NOR_IO2_U2: R11.2, U2.9
NOR_IO3_U1: R12.1, U1.43
NOR_IO3_U2: R12.2, U2.1
NOR_NCS_U2: R7.2, U1.39, U2.7
NRF_RESET_N: R78.2, U6.4, U11.40
NRF_SWCLK: TP_BLE_SWD1.3, U11.53
NRF_SWDIO: TP_BLE_SWD1.2, U11.51
NRST: C18.1, R1.2, TP_MCU_SWD1.4, U1.14
PDM_CLK: U1.37, U7.17
PDM_CLK_1V8_FANOUT: J_MIC1.3, J_MIC2.3, J_MIC3.3, J_MIC4.3, R17.2, U19.1, U20.1, U21.1, U22.1
PDM_CLK_1V8_U7: R17.1, U7.7
PDM_DATA1: U1.33, U7.21
PDM_DATA1_1V8: J_MIC1.4, U7.3, U19.2
PDM_DATA2: U1.87, U7.20
PDM_DATA2_1V8: J_MIC2.4, U7.4, U20.2
PDM_DATA3: U1.35, U7.19
PDM_DATA3_1V8: J_MIC3.4, U7.5, U21.2
PDM_DATA4: U1.3, U7.18
PDM_DATA4_1V8: J_MIC4.4, U7.6, U22.2
PWR_FAULT: R103.2, U1.82
PWR_GOOD: J_PWR1.7, TP_EOL1.7, U1.81
Q1_BASE: Q1.1, R24.2, R25.1
Q2_BASE: Q2.1, R26.2, R27.1
Q3_BASE: Q3.1, R46.2, R47.1
REV_STRAP0: TP_EOL1.10, U1.95
REV_STRAP1: TP_EOL1.11, U1.96
SD_CK_CARD: J12.5, R79.2, U23.5
SD_CK_U1: R79.1, U1.80
SD_CMD_CARD: J12.3, R80.2, R85.2, U23.4
SD_CMD_U1: R80.1, U1.83
SD_D0_CARD: J12.7, R81.2, R86.2, U24.1
SD_D0_U1: R81.1, U1.65
SD_D1_CARD: J12.8, R82.2, R87.2, U24.2
SD_D1_U1: R82.1, U1.66
SD_D2_CARD: J12.1, R83.2, R88.2, U23.1
SD_D2_U1: R83.1, U1.78
SD_D3_CARD: J12.2, R84.2, R89.2, U23.2
SD_D3_U1: R84.1, U1.79
SD_DET: C76.1, J12.CD, R90.2, U1.7, U24.4
SIM1_CLK_CONN: C55.1, J6.3, R51.2, U14.4
SIM1_CLK_MUX: R51.1, U13.23
SIM1_DATA_CONN: C56.1, J6.6, R52.2, U14.5
SIM1_DATA_MUX: R52.1, U13.19
SIM1_DET: C52.1, J6.7, R48.2, U1.2, U14.6
SIM1_RST_CONN: C54.1, J6.2, R50.2, U14.3
SIM1_RST_MUX: R50.1, U13.1
SIM1_VDD_CONN: C50.1, J6.1, U13.2, U13.21, U13.22, U14.1
SIM2_CLK_CONN: C58.1, J7.3, R54.2, U15.4
SIM2_CLK_MUX: R54.1, U13.15
SIM2_DATA_CONN: C59.1, J7.6, R55.2, U15.5
SIM2_DATA_MUX: R55.1, U13.18
SIM2_DET: C53.1, J7.7, R49.2, U1.4, U15.6
SIM2_RST_CONN: C57.1, J7.2, R53.2, U15.3
SIM2_RST_MUX: R53.1, U13.13
SIM2_VDD_CONN: C51.1, J7.1, U13.11, U13.16, U13.17, U15.1
SIM_MUX_EN: R46.1, U1.1
SIM_MUX_SEL: R45.1, U1.97, U13.14, U13.24
SMPS_SW: L1.1, U1.46
SWCLK: TP_MCU_SWD1.3, U1.76
SWDIO: TP_MCU_SWD1.2, U1.72
TAMPER_IN_CONN: D9.1, J13.1, R99.2, R100.1
TAMPER_IN_U1: C78.1, R100.2, U1.64
TEST_UART_RX_TP: R102.1, TP_EOL1.6
TEST_UART_RX_U1: R102.2, U1.15
TEST_UART_TX_TP: R101.2, TP_EOL1.5
TEST_UART_TX_U1: R101.1, U1.16
U8_MAIN_DTR_1V8: U8.30, U16.8
U8_MAIN_RI_1V8: R31.2, U8.39, U16.5
U8_MAIN_RXD_1V8: U8.34, U16.7
U8_MAIN_TXD_1V8: R30.2, U8.35, U16.3
U8_PWRKEY_N: C48.1, Q1.3, U8.15
U8_RESET_N: Q2.3, U8.17
U8_STATUS_1V8: U8.20, U16.4
U8_VDD_EXT_1V8: C33.1, R30.1, R31.1, R41.1, TP_CELL_DBG1.1, U8.29, U16.1, U16.2
U13_EN_N: Q3.3, R44.2, U13.20
USB_CC1: D7.1, J11.A5, R93.1
USB_CC2: D8.1, J11.B5, R94.1
USB_DM_CONN: J11.A7, J11.B7, R92.2, U25.2
USB_DM_U1: R92.1, U1.70
USB_DP_CONN: J11.A6, J11.B6, R91.2, U25.1
USB_DP_U1: R91.1, U1.71
USB_SHIELD: C77.1, J11.SHIELD, R97.1, R98.1
USB_VBUS_CONN: D6.1, J11.A4, J11.A9, J11.B4, J11.B9, R95.1
USB_VBUS_SENSE: R95.2, R96.1, U1.68
VCORE_1V1: C14.1, C15.1, C16.1, C17.1, L1.2, U1.49, U1.98

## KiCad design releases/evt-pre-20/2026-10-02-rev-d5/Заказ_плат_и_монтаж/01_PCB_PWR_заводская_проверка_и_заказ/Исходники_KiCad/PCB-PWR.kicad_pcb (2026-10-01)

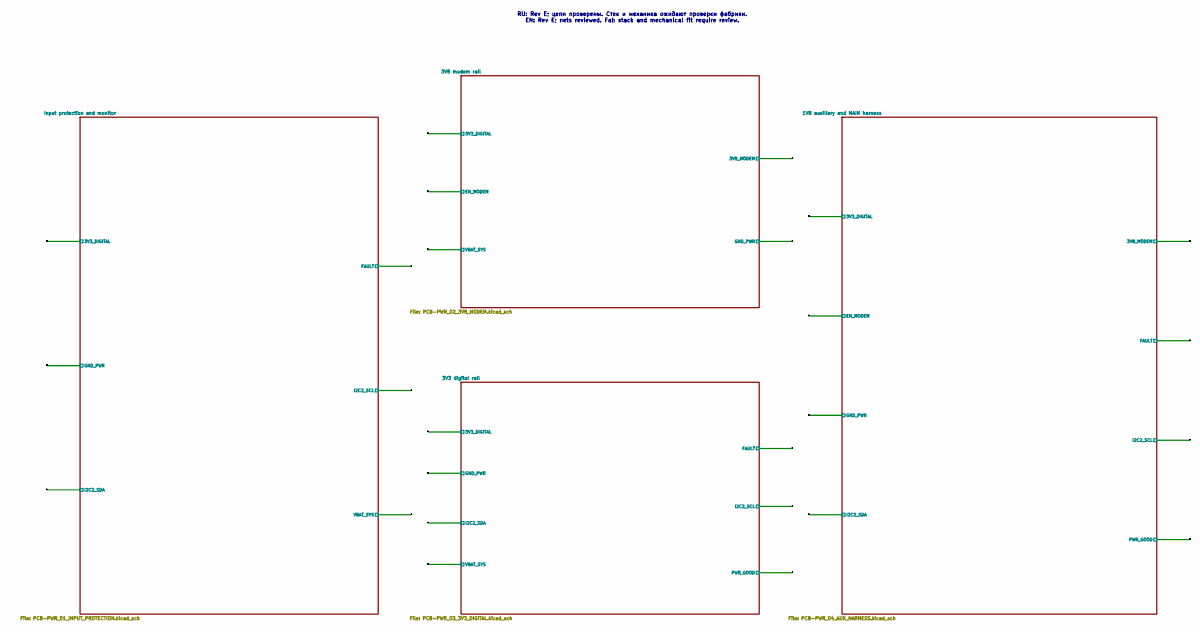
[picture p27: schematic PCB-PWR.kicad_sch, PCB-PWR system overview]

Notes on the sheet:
RU: Rev E; цепи проверены. Стек и механика ожидают проверки фабрики. EN: Rev E; nets reviewed. Fab stack and mechanical fit require review.

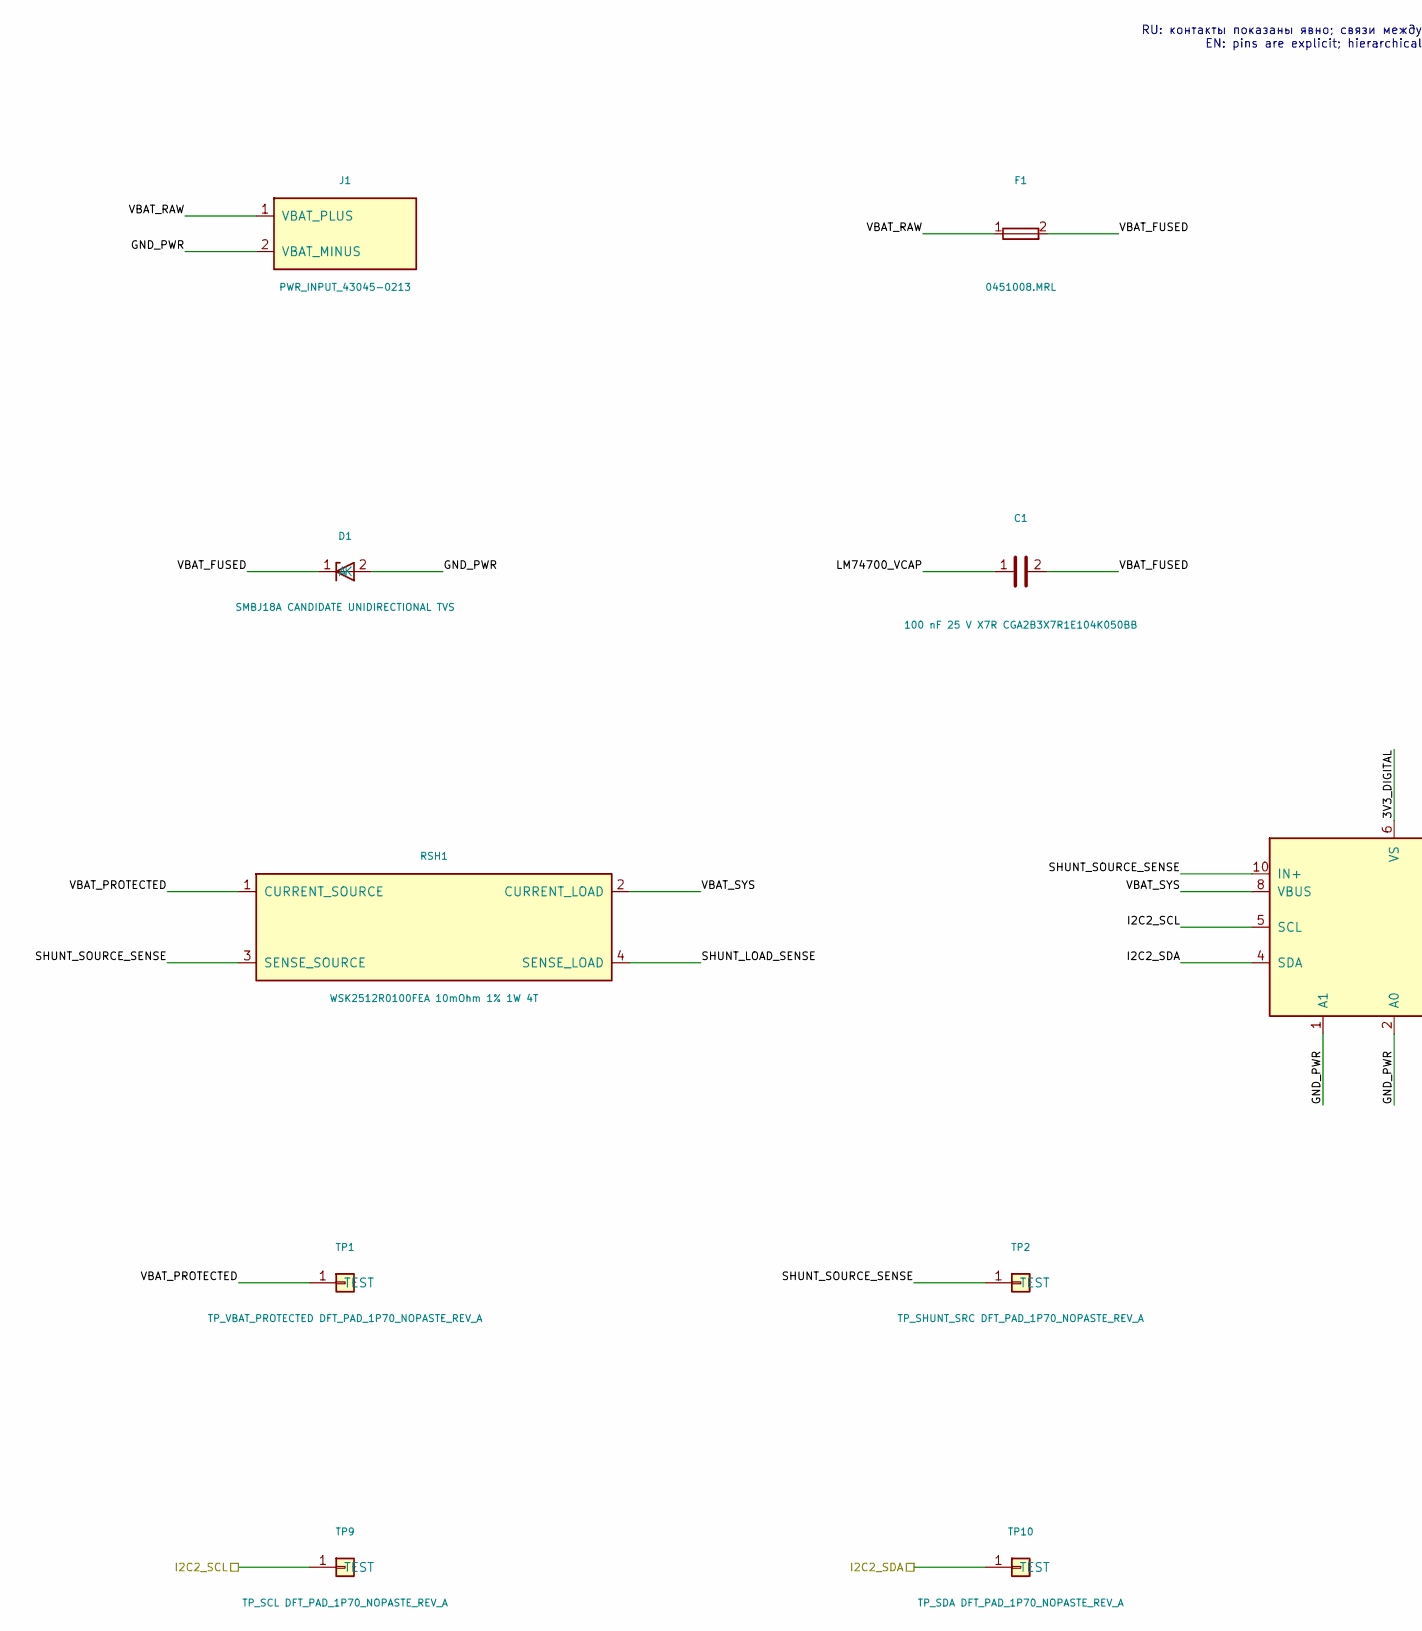
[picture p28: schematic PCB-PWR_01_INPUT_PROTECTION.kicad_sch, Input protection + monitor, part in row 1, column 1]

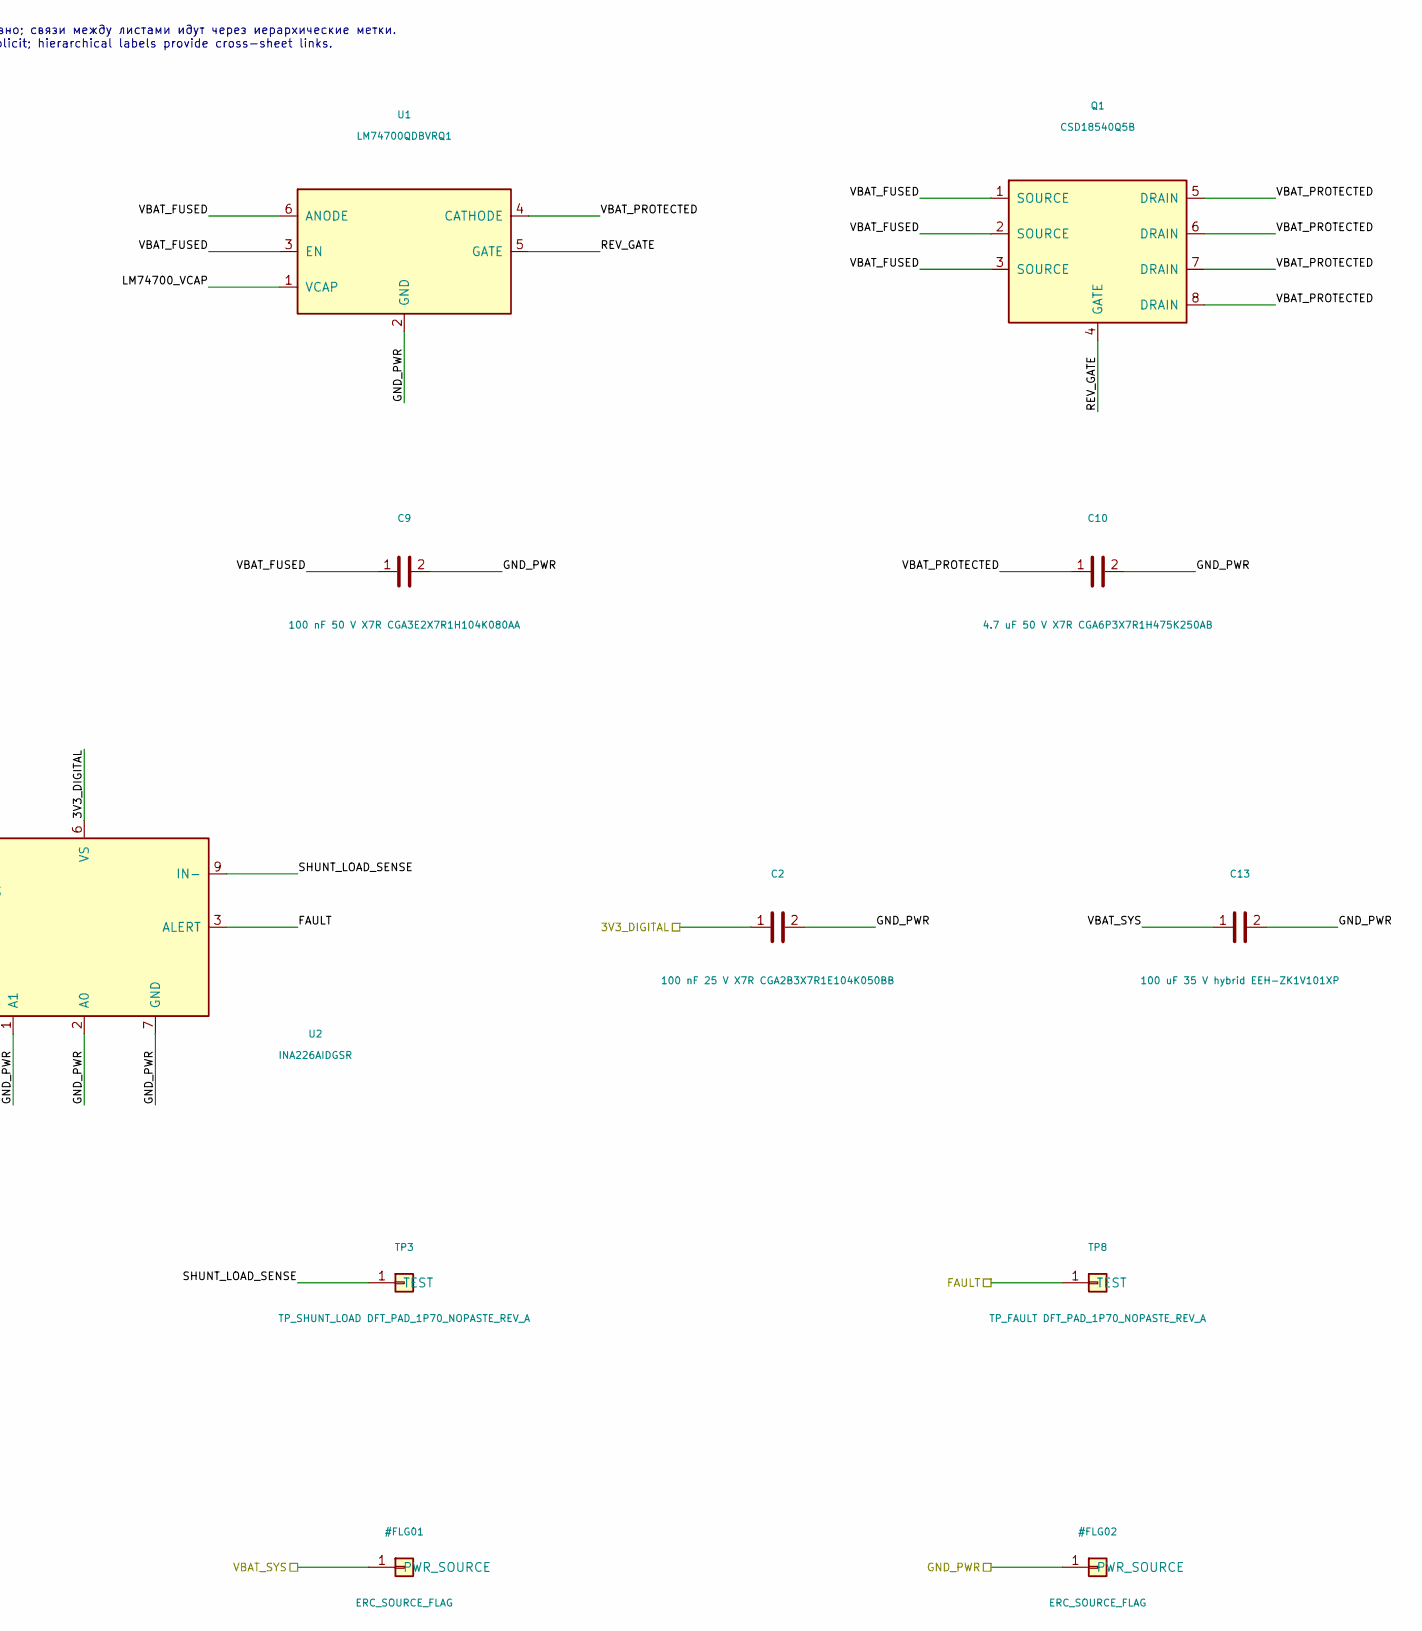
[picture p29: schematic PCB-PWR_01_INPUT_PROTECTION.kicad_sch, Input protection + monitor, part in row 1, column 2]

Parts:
C1, C2: 100 nF 25 V X7R CGA2B3X7R1E104K050BB; C_0402_1005Metric
C9: 100 nF 50 V X7R CGA3E2X7R1H104K080AA; C_0603_1608Metric
C10: 4.7 uF 50 V X7R CGA6P3X7R1H475K250AB; C_1210_3225Metric
C13: 100 uF 35 V hybrid EEH-ZK1V101XP; CP_Elec_6.3x7.7
D1: SMBJ18A CANDIDATE UNIDIRECTIONAL TVS; D_SMB
F1: 0451008.MRL; Fuse_1206_3216Metric
J1: PWR_INPUT_43045-0213; Molex_43045-0213_MicroFit-2_Vertical
Q1: CSD18540Q5B; CSD18540Q5B_DNK
RSH1: WSK2512R0100FEA 10mOhm 1% 1W 4T; Vishay_WSK2512_4T_T1.19mm
TP1: TP_VBAT_PROTECTED DFT_PAD_1P70_NOPASTE_REV_A; TestPoint_DFT_1.7mm_NoPaste
TP2: TP_SHUNT_SRC DFT_PAD_1P70_NOPASTE_REV_A; TestPoint_DFT_1.7mm_NoPaste
TP3: TP_SHUNT_LOAD DFT_PAD_1P70_NOPASTE_REV_A; TestPoint_DFT_1.7mm_NoPaste
TP8: TP_FAULT DFT_PAD_1P70_NOPASTE_REV_A; TestPoint_DFT_1.7mm_NoPaste
TP9: TP_SCL DFT_PAD_1P70_NOPASTE_REV_A; TestPoint_DFT_1.7mm_NoPaste
TP10: TP_SDA DFT_PAD_1P70_NOPASTE_REV_A; TestPoint_DFT_1.7mm_NoPaste
U1: LM74700QDBVRQ1; TI_DBV0006A_SOT23-6
U2: INA226AIDGSR; TI_DGS0010A_VSSOP10

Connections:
3V3_DIGITAL: C2.1, U2.6 (VS); also elsewhere on the board
FAULT: TP8.1, U2.3 (ALERT); also elsewhere on the board
GND_PWR: C2.2, C9.2, C10.2, C13.2, D1.2 (A), J1.2 (VBAT_MINUS), U1.2 (GND), U2.1 (A1), U2.2 (A0), U2.7 (GND); also elsewhere on the board
I2C2_SCL: TP9.1, U2.5 (SCL); also elsewhere on the board
I2C2_SDA: TP10.1, U2.4 (SDA); also elsewhere on the board
LM74700_VCAP: C1.1, U1.1 (VCAP)
REV_GATE: Q1.4 (GATE), U1.5 (GATE)
SHUNT_LOAD_SENSE: RSH1.4 (SENSE_LOAD), TP3.1, U2.9 (IN-)
SHUNT_SOURCE_SENSE: RSH1.3 (SENSE_SOURCE), TP2.1, U2.10 (IN+)
VBAT_FUSED: C1.2, C9.1, D1.1 (K), F1.2, Q1.1 (SOURCE), Q1.2 (SOURCE), Q1.3 (SOURCE), U1.3 (EN), U1.6 (ANODE)
VBAT_PROTECTED: C10.1, Q1.5 (DRAIN), Q1.6 (DRAIN), Q1.7 (DRAIN), Q1.8 (DRAIN), RSH1.1 (CURRENT_SOURCE), TP1.1, U1.4 (CATHODE)
VBAT_RAW: F1.1, J1.1 (VBAT_PLUS)
VBAT_SYS: C13.1, RSH1.2 (CURRENT_LOAD), U2.8 (VBUS); also elsewhere on the board

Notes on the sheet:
RU: контакты показаны явно; связи между листами идут через иерархические метки. EN: pins are explicit; hierarchical labels provide cross-sheet links.

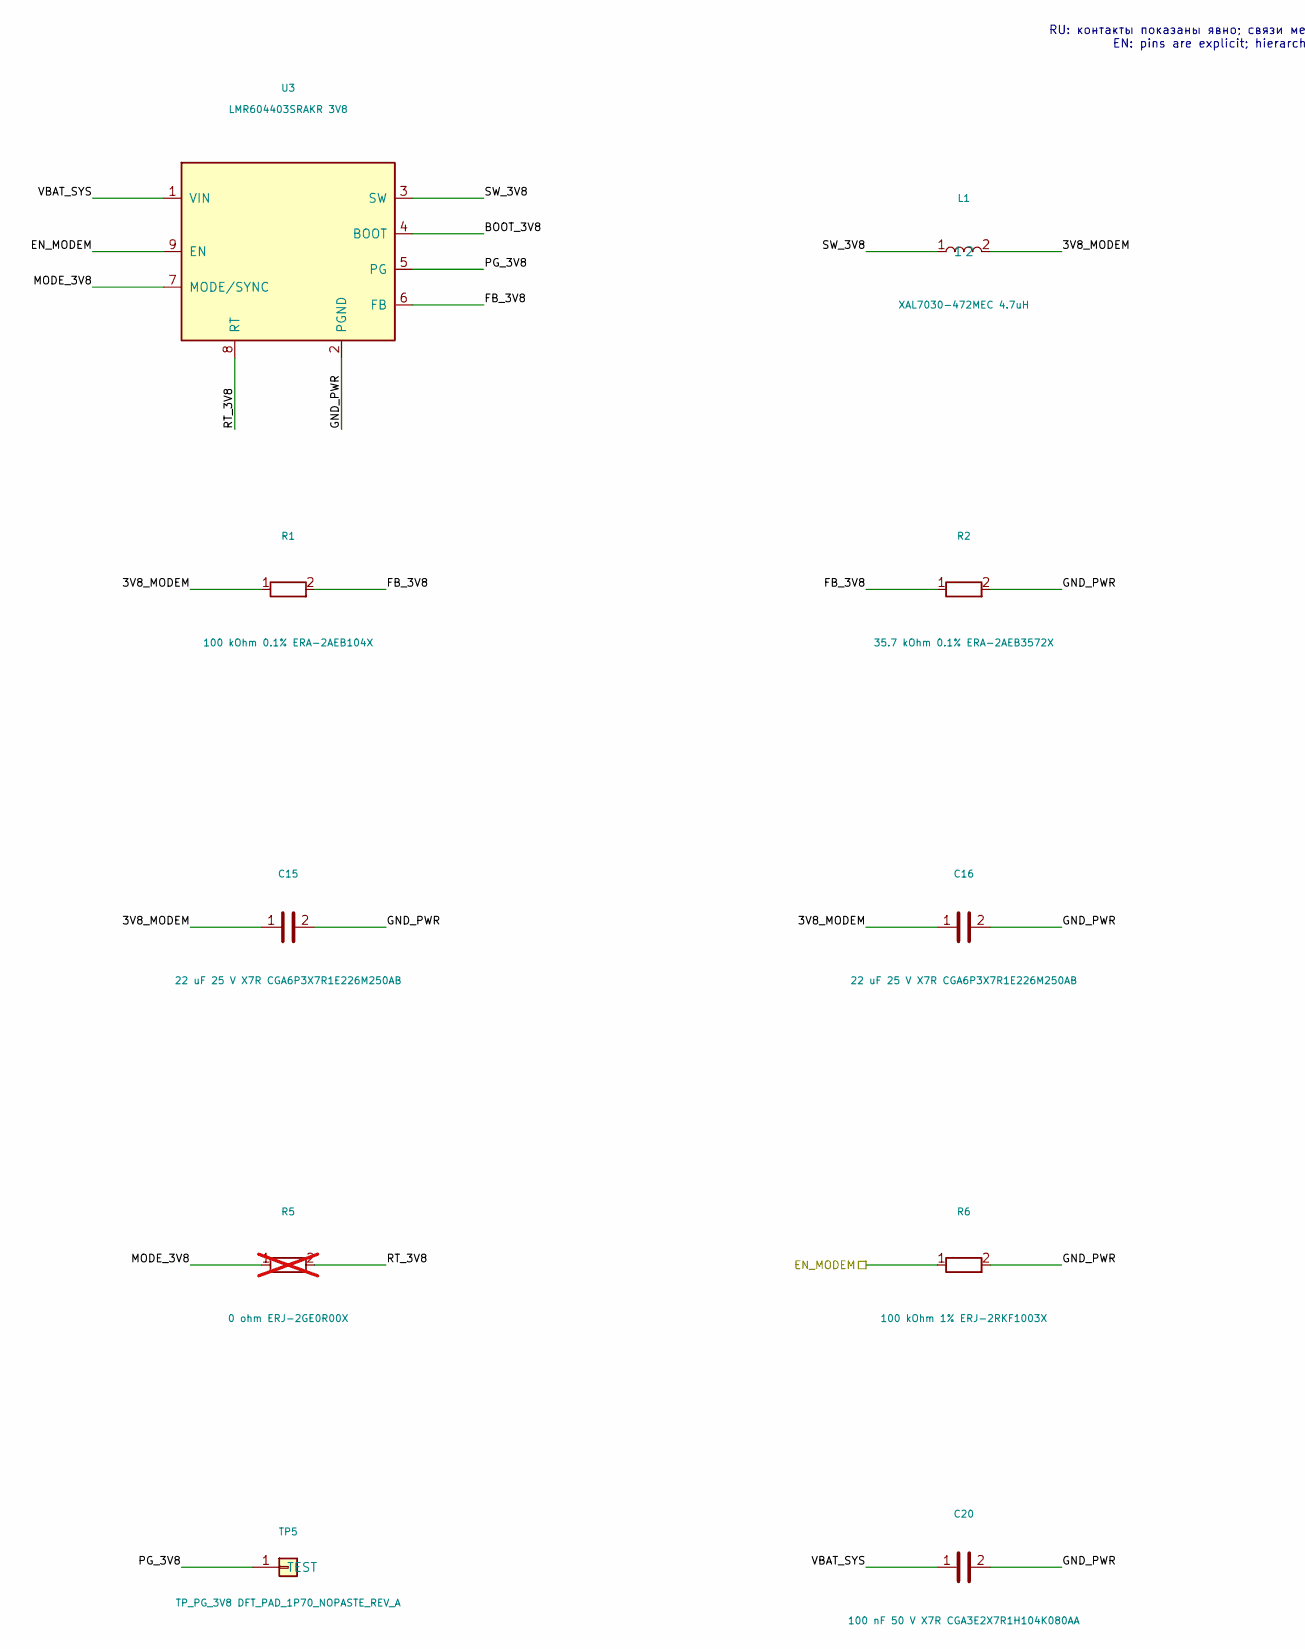
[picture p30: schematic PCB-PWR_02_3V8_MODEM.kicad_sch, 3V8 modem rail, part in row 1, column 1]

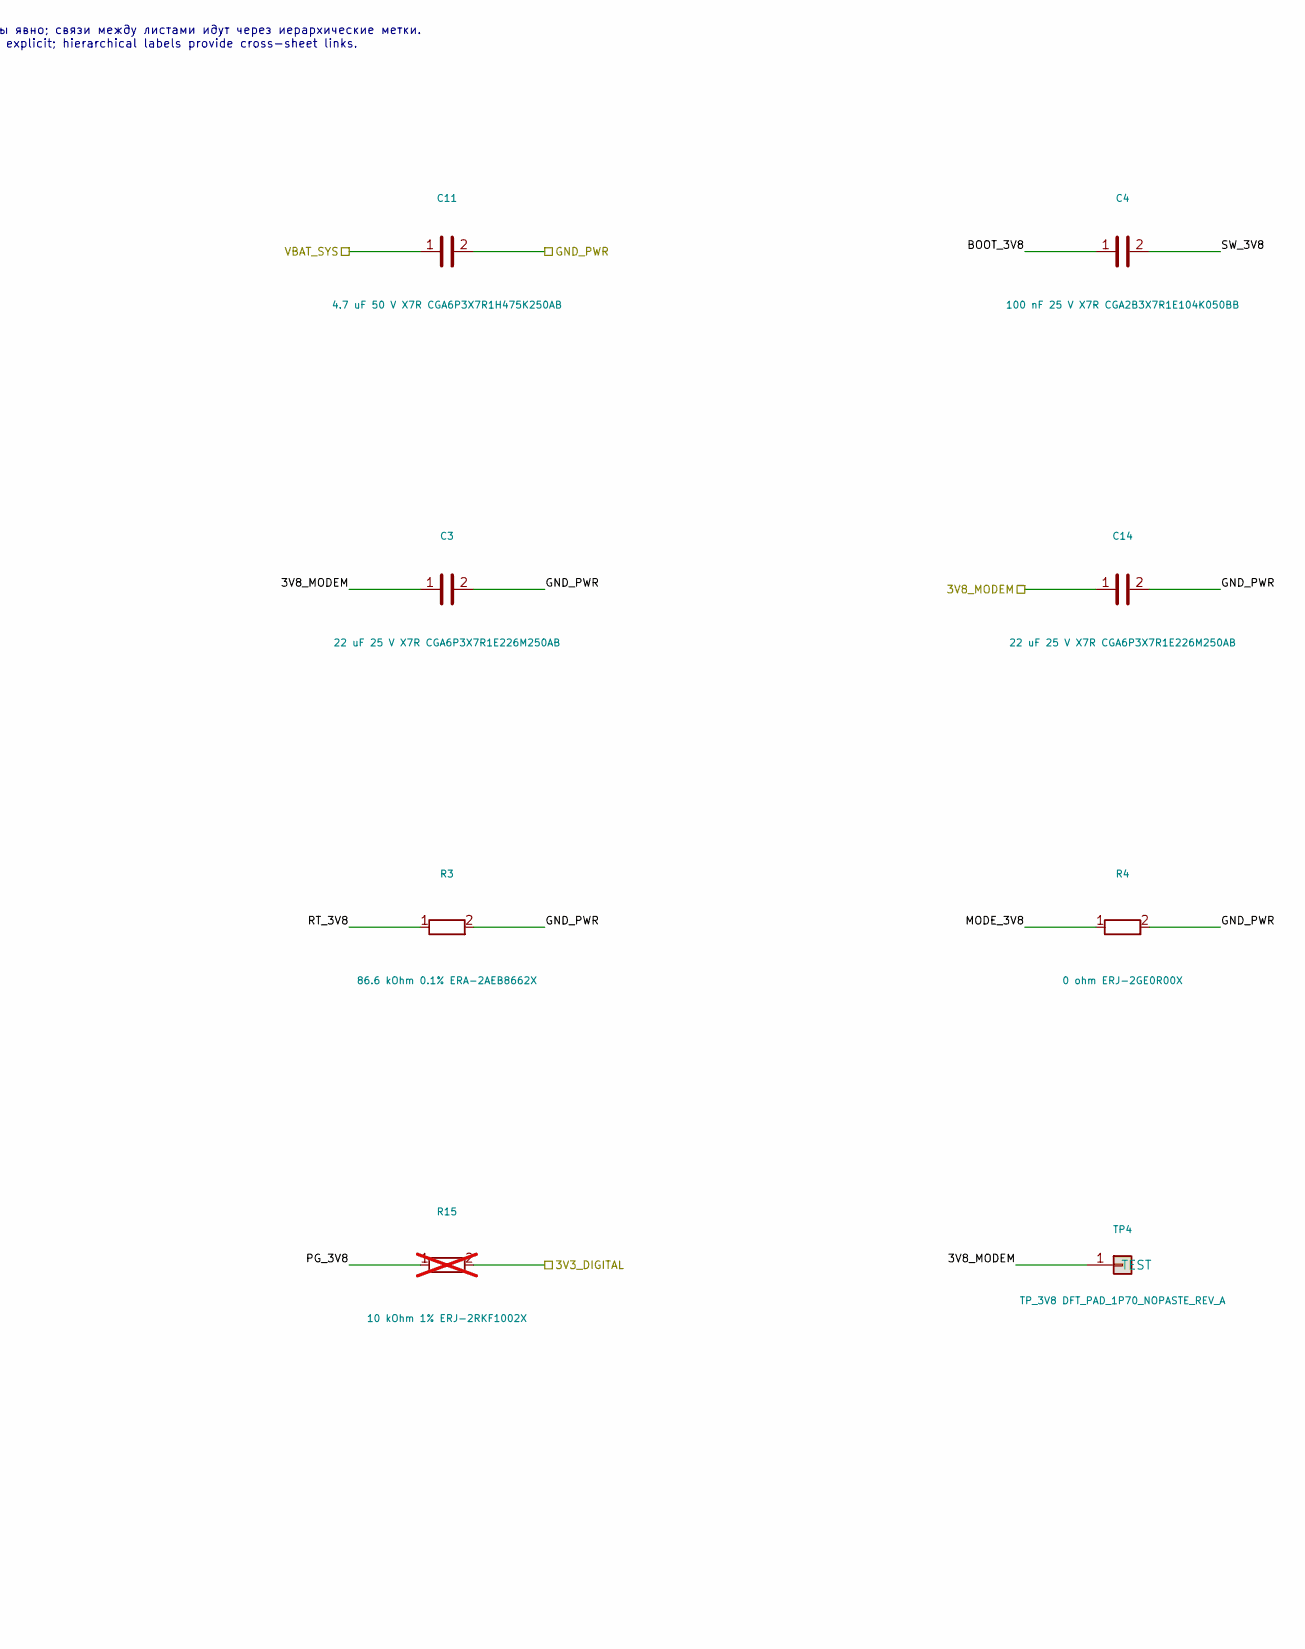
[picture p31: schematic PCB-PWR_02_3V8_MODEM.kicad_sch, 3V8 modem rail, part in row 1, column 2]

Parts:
C3, C14, C15, C16: 22 uF 25 V X7R CGA6P3X7R1E226M250AB; C_1210_3225Metric
C4: 100 nF 25 V X7R CGA2B3X7R1E104K050BB; C_0402_1005Metric
C11: 4.7 uF 50 V X7R CGA6P3X7R1H475K250AB; C_1210_3225Metric
C20: 100 nF 50 V X7R CGA3E2X7R1H104K080AA; C_0603_1608Metric
L1: XAL7030-472MEC 4.7uH; Coilcraft_XAL7030_472
R1: 100 kOhm 0.1% ERA-2AEB104X; R_0402_1005Metric
R2: 35.7 kOhm 0.1% ERA-2AEB3572X; R_0402_1005Metric
R3: 86.6 kOhm 0.1% ERA-2AEB8662X; R_0402_1005Metric
R4: 0 ohm ERJ-2GE0R00X; R_0402_1005Metric
R5: 0 ohm ERJ-2GE0R00X; R_0402_1005Metric; not fitted
R6: 100 kOhm 1% ERJ-2RKF1003X; R_0402_1005Metric
R15: 10 kOhm 1% ERJ-2RKF1002X; R_0402_1005Metric; not fitted
TP4: TP_3V8 DFT_PAD_1P70_NOPASTE_REV_A; TestPoint_DFT_1.7mm_NoPaste
TP5: TP_PG_3V8 DFT_PAD_1P70_NOPASTE_REV_A; TestPoint_DFT_1.7mm_NoPaste
U3: LMR604403SRAKR 3V8; LMR60440_RAK0009A

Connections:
3V3_DIGITAL: R15.2; also elsewhere on the board
3V8_MODEM: C3.1, C14.1, C15.1, C16.1, L1.2, R1.1, TP4.1; also elsewhere on the board
BOOT_3V8: C4.1, U3.4 (BOOT)
EN_MODEM: R6.1, U3.9 (EN); also elsewhere on the board
FB_3V8: R1.2, R2.1, U3.6 (FB)
GND_PWR: C3.2, C11.2, C14.2, C15.2, C16.2, C20.2, R2.2, R3.2, R4.2, R6.2, U3.2 (PGND); also elsewhere on the board
MODE_3V8: R4.1, R5.1, U3.7 (MODE/SYNC)
PG_3V8: R15.1, TP5.1, U3.5 (PG)
RT_3V8: R3.1, R5.2, U3.8 (RT)
SW_3V8: C4.2, L1.1, U3.3 (SW)
VBAT_SYS: C11.1, C20.1, U3.1 (VIN); also elsewhere on the board

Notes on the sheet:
RU: контакты показаны явно; связи между листами идут через иерархические метки. EN: pins are explicit; hierarchical labels provide cross-sheet links.

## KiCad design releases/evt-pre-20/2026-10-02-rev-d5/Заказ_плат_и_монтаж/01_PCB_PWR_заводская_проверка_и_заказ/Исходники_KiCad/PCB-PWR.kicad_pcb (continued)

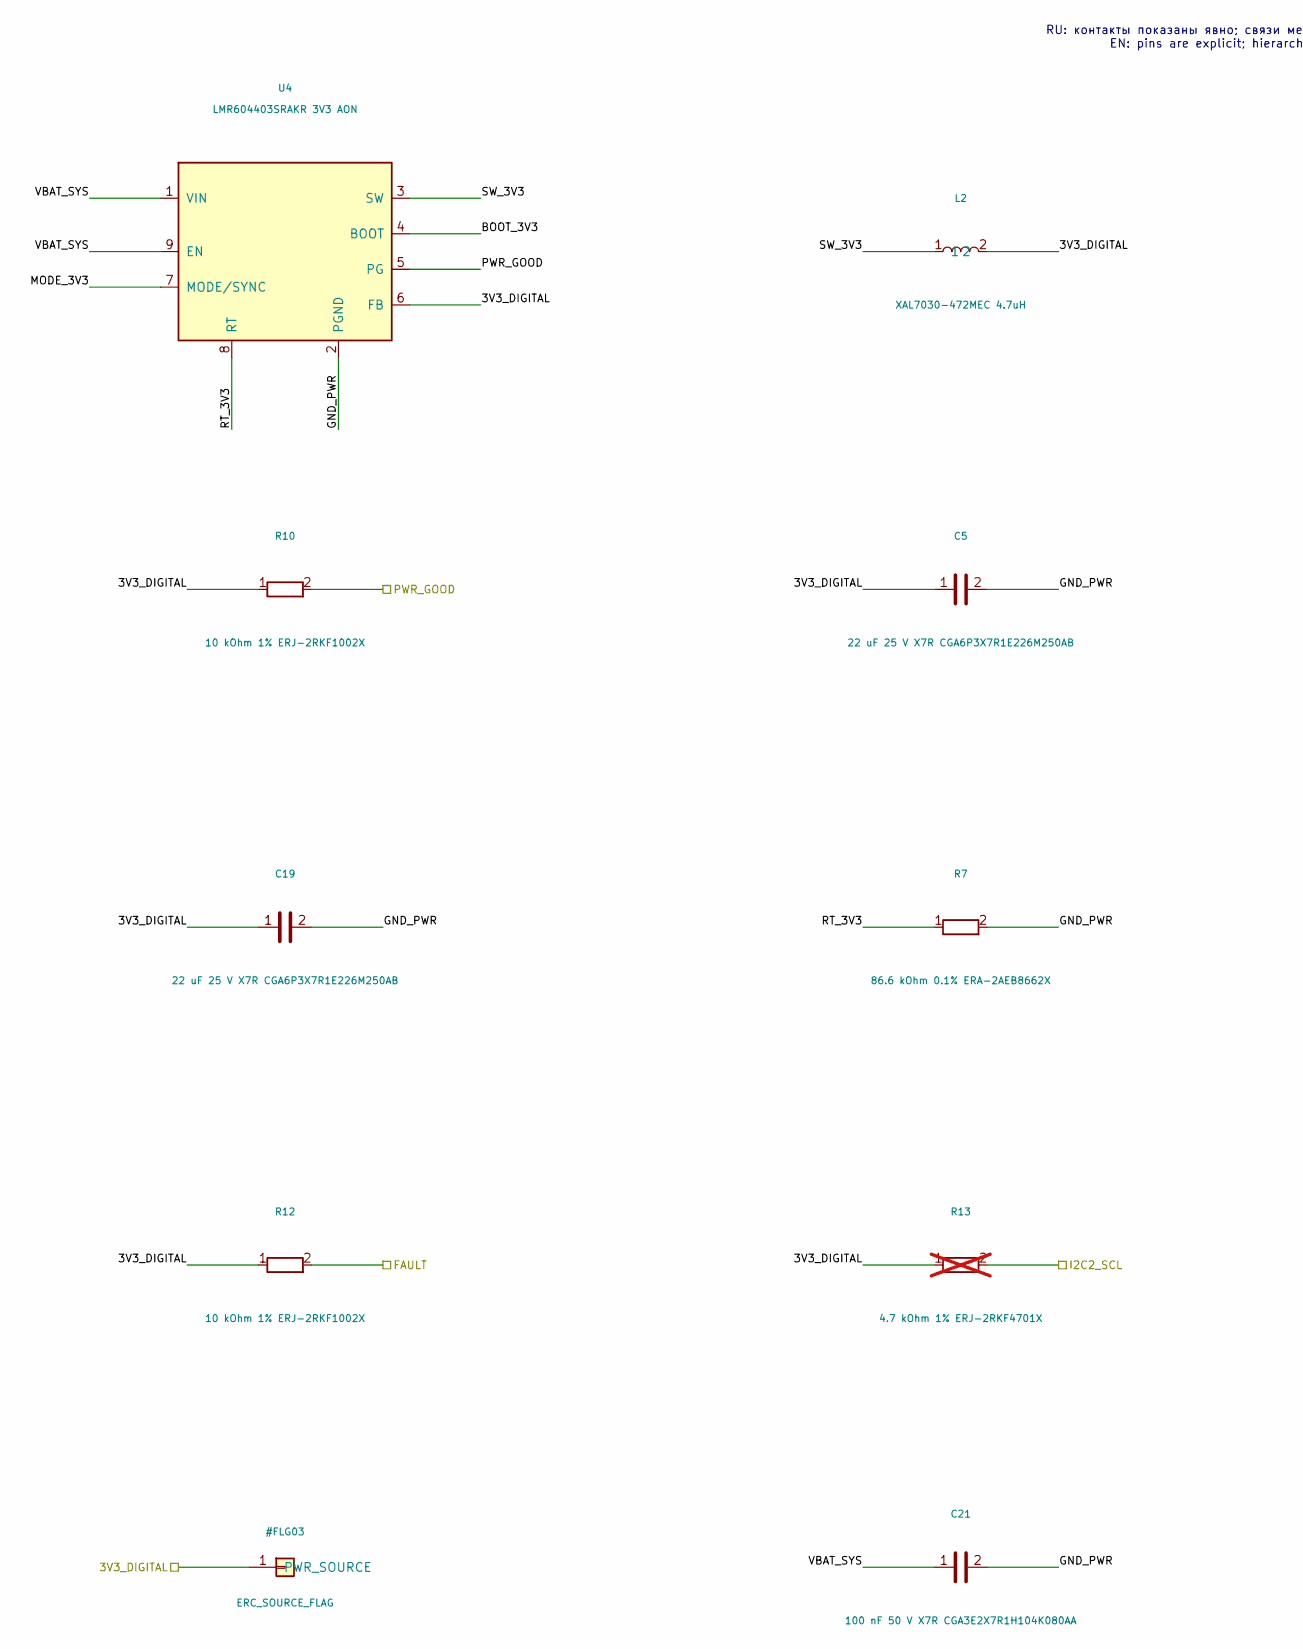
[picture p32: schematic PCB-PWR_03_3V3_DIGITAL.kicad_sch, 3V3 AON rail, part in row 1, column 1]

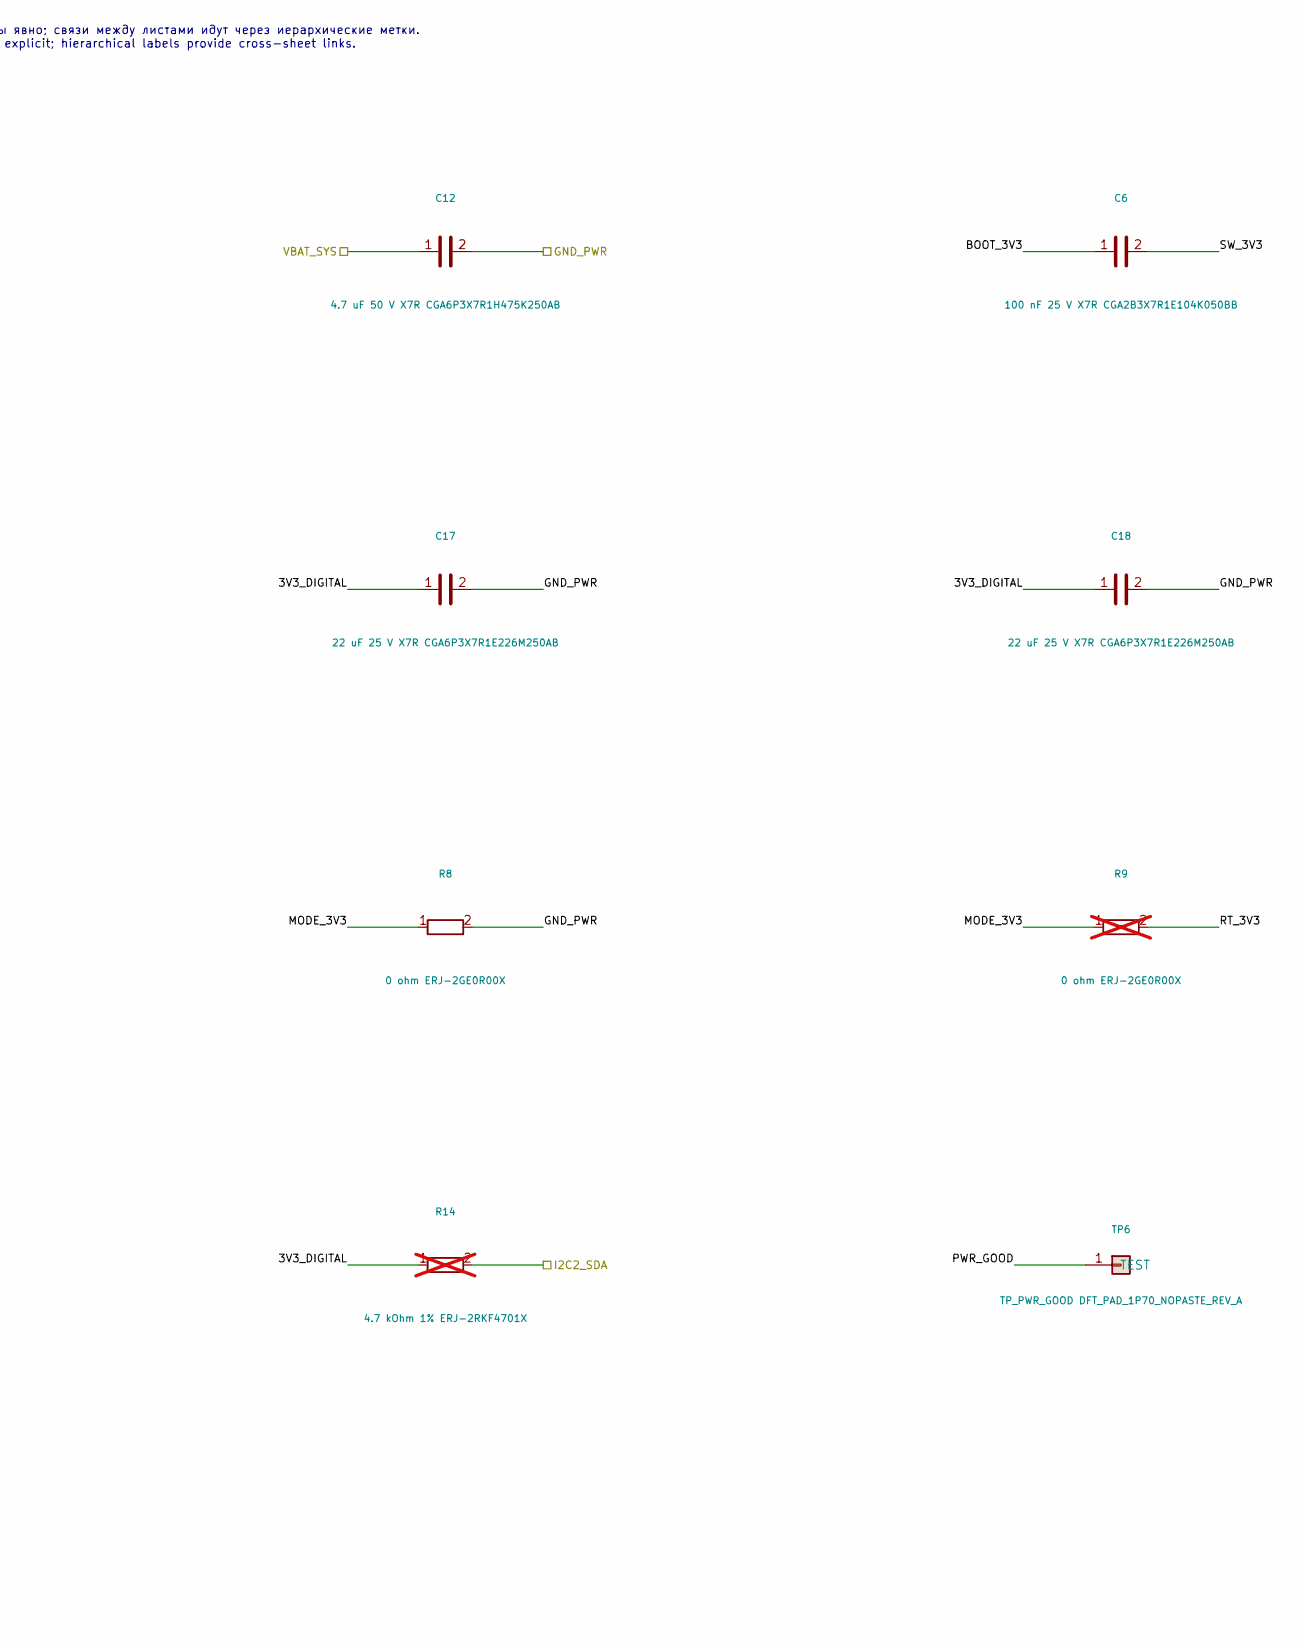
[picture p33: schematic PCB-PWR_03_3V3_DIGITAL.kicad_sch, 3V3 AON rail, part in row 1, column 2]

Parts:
C5, C17, C18, C19: 22 uF 25 V X7R CGA6P3X7R1E226M250AB; C_1210_3225Metric
C6: 100 nF 25 V X7R CGA2B3X7R1E104K050BB; C_0402_1005Metric
C12: 4.7 uF 50 V X7R CGA6P3X7R1H475K250AB; C_1210_3225Metric
C21: 100 nF 50 V X7R CGA3E2X7R1H104K080AA; C_0603_1608Metric
L2: XAL7030-472MEC 4.7uH; Coilcraft_XAL7030_472
R7: 86.6 kOhm 0.1% ERA-2AEB8662X; R_0402_1005Metric
R8: 0 ohm ERJ-2GE0R00X; R_0402_1005Metric
R9: 0 ohm ERJ-2GE0R00X; R_0402_1005Metric; not fitted
R10, R12: 10 kOhm 1% ERJ-2RKF1002X; R_0402_1005Metric
R13, R14: 4.7 kOhm 1% ERJ-2RKF4701X; R_0402_1005Metric; not fitted
TP6: TP_PWR_GOOD DFT_PAD_1P70_NOPASTE_REV_A; TestPoint_DFT_1.7mm_NoPaste
U4: LMR604403SRAKR 3V3 AON; LMR60440_RAK0009A

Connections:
3V3_DIGITAL: C5.1, C17.1, C18.1, C19.1, L2.2, R10.1, R12.1, R13.1, R14.1, U4.6 (FB); also elsewhere on the board
BOOT_3V3: C6.1, U4.4 (BOOT)
FAULT: R12.2; also elsewhere on the board
GND_PWR: C5.2, C12.2, C17.2, C18.2, C19.2, C21.2, R7.2, R8.2, U4.2 (PGND); also elsewhere on the board
I2C2_SCL: R13.2; also elsewhere on the board
I2C2_SDA: R14.2; also elsewhere on the board
MODE_3V3: R8.1, R9.1, U4.7 (MODE/SYNC)
PWR_GOOD: R10.2, TP6.1, U4.5 (PG); also elsewhere on the board
RT_3V3: R7.1, R9.2, U4.8 (RT)
SW_3V3: C6.2, L2.1, U4.3 (SW)
VBAT_SYS: C12.1, C21.1, U4.1 (VIN), U4.9 (EN); also elsewhere on the board

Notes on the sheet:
RU: контакты показаны явно; связи между листами идут через иерархические метки. EN: pins are explicit; hierarchical labels provide cross-sheet links.

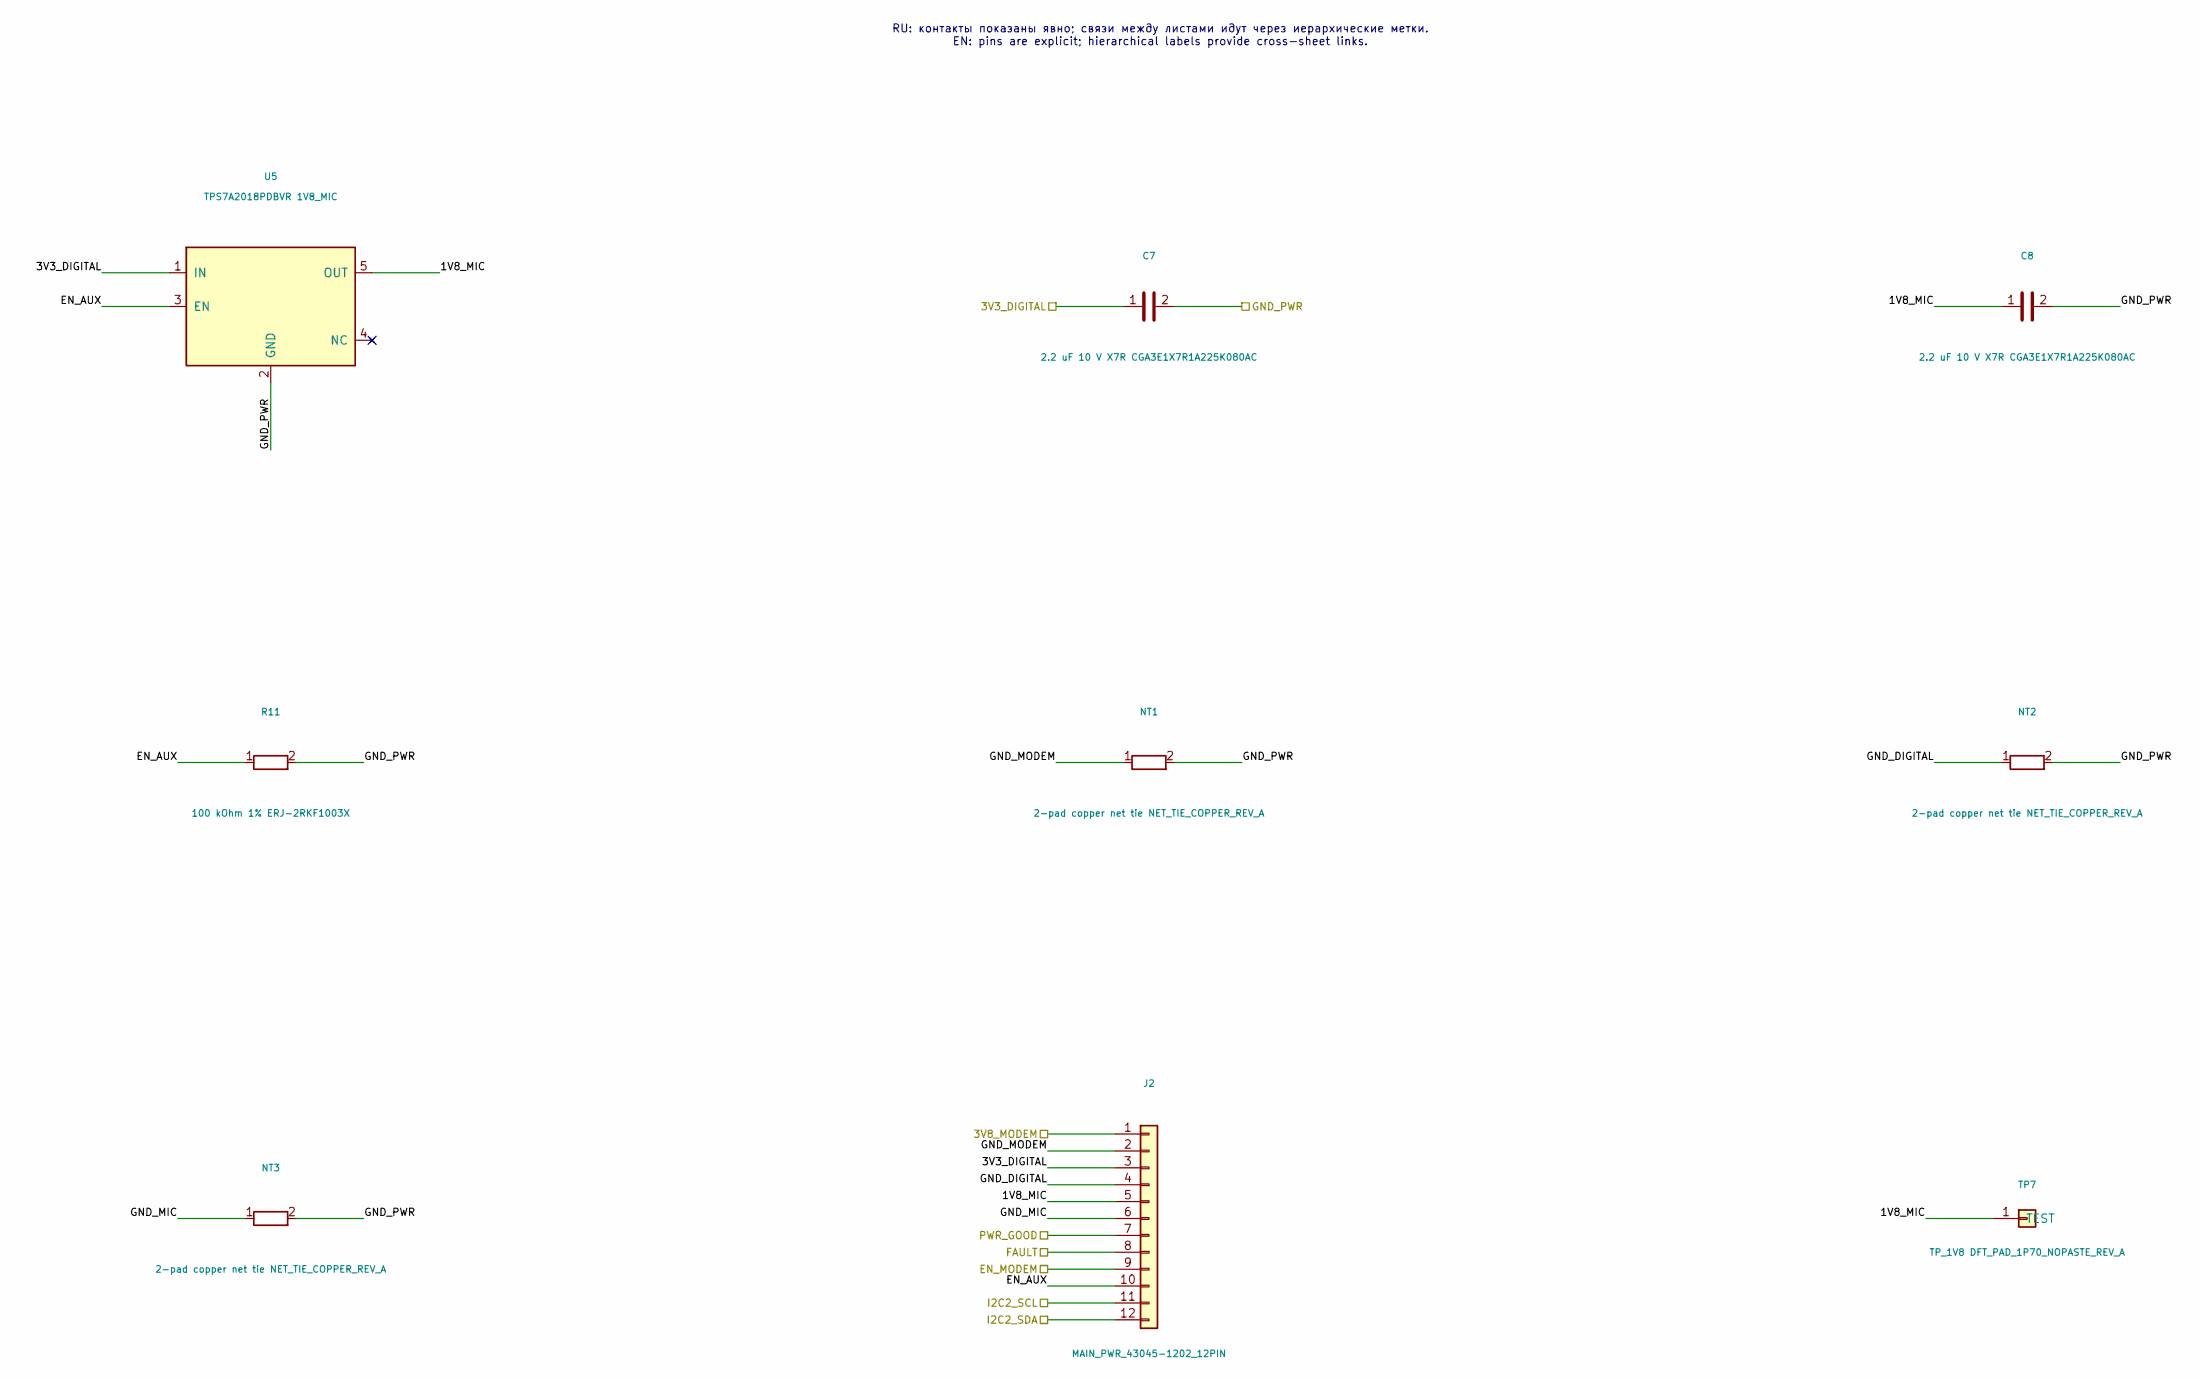
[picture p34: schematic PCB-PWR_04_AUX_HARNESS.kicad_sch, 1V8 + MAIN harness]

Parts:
C7, C8: 2.2 uF 10 V X7R CGA3E1X7R1A225K080AC; C_0603_1608Metric
J2: MAIN_PWR_43045-1202_12PIN; Molex_43045-1202_MicroFit-12_RA
NT1, NT2, NT3: 2-pad copper net tie NET_TIE_COPPER_REV_A; NetTie-2_SMD_Pad0.5mm
R11: 100 kOhm 1% ERJ-2RKF1003X; R_0402_1005Metric
TP7: TP_1V8 DFT_PAD_1P70_NOPASTE_REV_A; TestPoint_DFT_1.7mm_NoPaste
U5: TPS7A2018PDBVR 1V8_MIC; TI_DBV0005A_SOT23-5

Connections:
1V8_MIC: C8.1, J2.5 (1V8_MIC), TP7.1, U5.5 (OUT)
3V3_DIGITAL: C7.1, J2.3 (3V3_DIGITAL), U5.1 (IN); also elsewhere on the board
3V8_MODEM: J2.1 (3V8_MODEM); also elsewhere on the board
EN_AUX: J2.10 (EN_AUX), R11.1, U5.3 (EN)
EN_MODEM: J2.9 (EN_MODEM); also elsewhere on the board
FAULT: J2.8 (FAULT); also elsewhere on the board
GND_DIGITAL: J2.4 (GND_DIGITAL), NT2.1
GND_MIC: J2.6 (GND_MIC), NT3.1
GND_MODEM: J2.2 (GND_MODEM), NT1.1
GND_PWR: C7.2, C8.2, NT1.2, NT2.2, NT3.2, R11.2, U5.2 (GND); also elsewhere on the board
I2C2_SCL: J2.11 (I2C2_SCL); also elsewhere on the board
I2C2_SDA: J2.12 (I2C2_SDA); also elsewhere on the board
PWR_GOOD: J2.7 (PWR_GOOD); also elsewhere on the board

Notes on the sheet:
RU: контакты показаны явно; связи между листами идут через иерархические метки. EN: pins are explicit; hierarchical labels provide cross-sheet links.

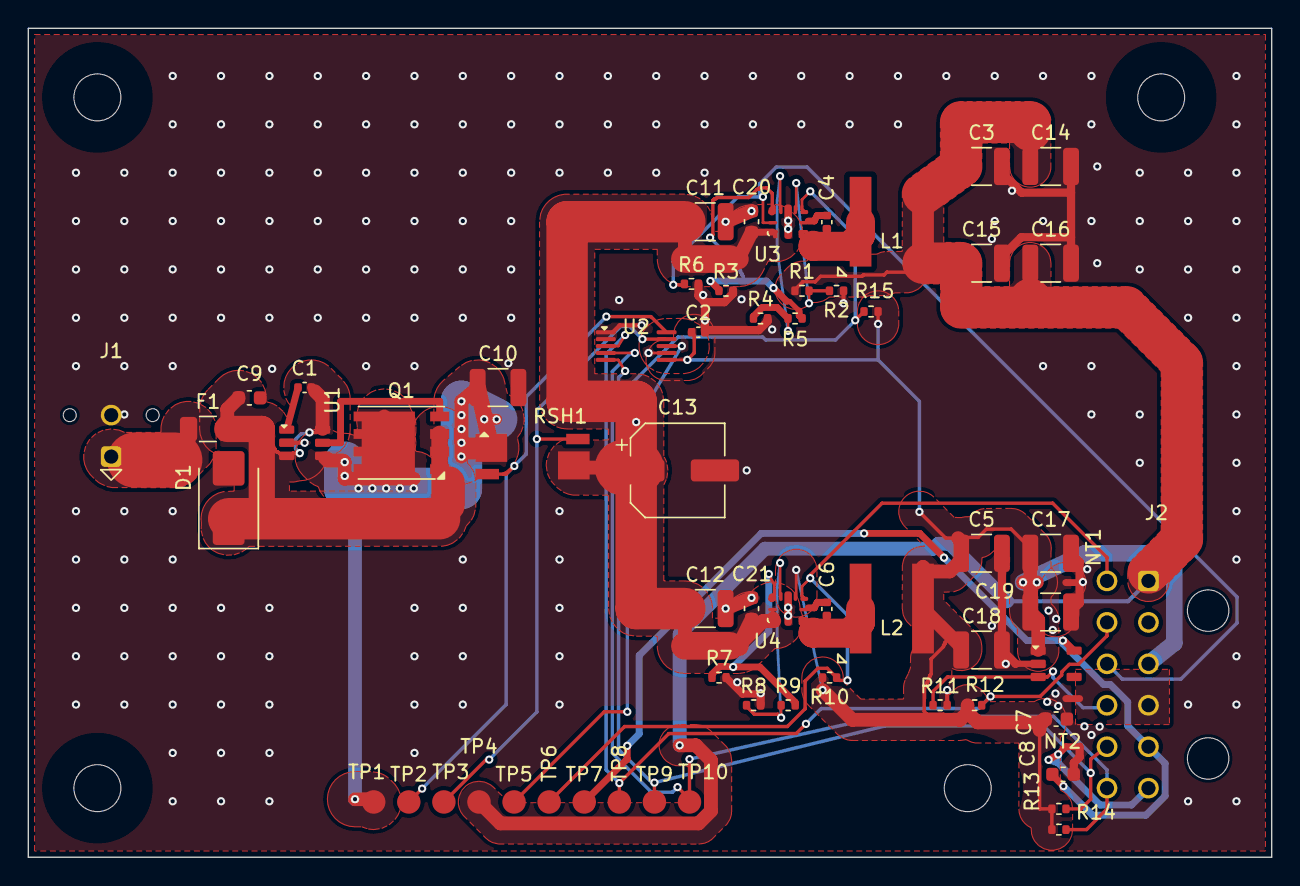
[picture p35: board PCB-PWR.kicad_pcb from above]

Board: 4 copper layers, 90.0 x 60.0 mm, 66 parts (0 on the bottom side), 31 nets.

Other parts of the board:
H1, H2, H3, H4: M3_CLEARANCE_NPTH_3.4; MountingHole_M3_3.4_EVT

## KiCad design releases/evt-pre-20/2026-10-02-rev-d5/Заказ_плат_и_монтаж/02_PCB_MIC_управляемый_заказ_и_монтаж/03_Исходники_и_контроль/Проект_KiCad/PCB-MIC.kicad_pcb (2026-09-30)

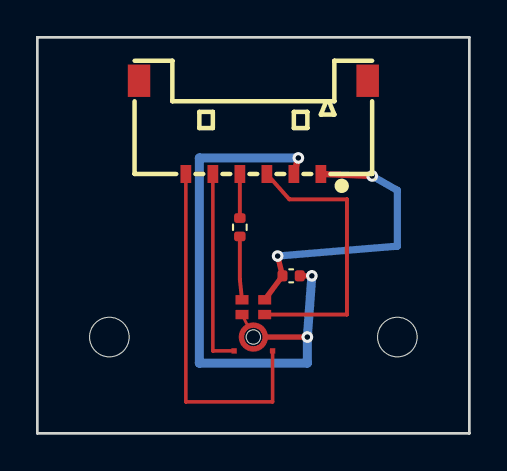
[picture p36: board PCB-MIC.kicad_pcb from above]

Board: 2 copper layers, 24.0 x 22.0 mm, 6 parts (0 on the bottom side), 7 nets.

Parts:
C1: 100nF X7R; C_0402_1005Metric
H1, H2: M2_CLEARANCE_NPTH_2.2
J1: 5040500691; Molex_5040500691
MK1: T5838; T5838_RevA
R1: 0R EVT_SI_TUNE; R_0402_1005Metric

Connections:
1V8_MIC: C1.1, J1.1, MK1.7
AAD_CFG: J1.6, MK1.5
GND: C1.2, J1.2, MK1.2, MK1.3
MIC_WAKE: J1.5, MK1.4
PDM_CLK: J1.3, MK1.6
PDM_DATA: J1.4, R1.1
PDM_DATA_MIC: MK1.1, R1.2

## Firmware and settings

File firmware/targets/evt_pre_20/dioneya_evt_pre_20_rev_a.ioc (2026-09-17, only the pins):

Mcu.UserName=STM32U585VITxQ
PE2.GPIO_Label=SIM_MUX_EN
PE2.Signal=GPIO_Output
PE3.GPIO_Label=SIM1_DET
PE3.Signal=GPIO_Input
PE4.GPIO_Label=PDM_DATA4
PE4.Signal=MDF1_SDI3
PE5.GPIO_Label=SIM2_DET
PE5.Signal=GPIO_Input
PE6.GPIO_Label=BLE_EN
PE6.Signal=GPIO_Output
PC13.GPIO_Label=SD_DET
PC13.Signal=GPIO_Input
PC0.GPIO_Label=TEST_UART_RX
PC0.Signal=LPUART1_RX
PC1.GPIO_Label=TEST_UART_TX
PC1.Signal=LPUART1_TX
PC2.GPIO_Label=LORA_DIO1
PC2.Signal=GPXTI2
PA0.GPIO_Label=GNSS_PPS
PA0.Signal=S_TIM2_CH1
PA2.GPIO_Label=GNSS_TX
PA2.Signal=USART2_TX
PA3.GPIO_Label=GNSS_RX
PA3.Signal=USART2_RX
PA4.GPIO_Label=LORA_NSS
PA4.Signal=SPI1_NSS
PA5.GPIO_Label=LORA_SCK
PA5.Signal=SPI1_SCK
PA6.GPIO_Label=LORA_MISO
PA6.Signal=SPI1_MISO
PA7.GPIO_Label=LORA_MOSI
PA7.Signal=SPI1_MOSI
PB1.GPIO_Label=PDM_DATA1
PB1.Signal=MDF1_SDI0
PB2.GPIO_Label=BLE_DFU_REQ
PB2.Signal=GPIO_Output
PE7.GPIO_Label=PDM_DATA3
PE7.Signal=MDF1_SDI2
PE9.GPIO_Label=PDM_CLK
PE9.Signal=MDF1_CCK0
PE10.GPIO_Label=NOR_CLK
PE10.Signal=OCTOSPIM_P1_CLK
PE11.GPIO_Label=NOR_NCS
PE11.Signal=OCTOSPIM_P1_NCS
PE12.GPIO_Label=NOR_IO0
PE12.Signal=OCTOSPIM_P1_IO0
PE13.GPIO_Label=NOR_IO1
PE13.Signal=OCTOSPIM_P1_IO1
PE14.GPIO_Label=NOR_IO2
PE14.Signal=OCTOSPIM_P1_IO2
PE15.GPIO_Label=NOR_IO3
PE15.Signal=OCTOSPIM_P1_IO3
PB10.GPIO_Label=BLE_TX
PB10.Signal=USART3_TX
PB11.GPIO_Label=BLE_RX
PB11.Signal=USART3_RX
PB13.GPIO_Label=I2C2_SCL
PB13.Signal=I2C2_SCL
PB14.GPIO_Label=I2C2_SDA
PB14.Signal=I2C2_SDA
PB15.GPIO_Label=LORA_TXEN
PB15.Signal=GPIO_Output
PD8.GPIO_Label=LORA_RXEN
PD8.Signal=GPIO_Output
PD9.GPIO_Label=LORA_BUSY
PD9.Signal=GPIO_Input
PD10.GPIO_Label=LORA_RESET_N
PD10.Signal=GPIO_Output
PD11.GPIO_Label=CELL_PWRKEY_CMD
PD11.Signal=GPIO_Output
PD12.GPIO_Label=CELL_RESET_N_CMD
PD12.Signal=GPIO_Output
PD13.GPIO_Label=CELL_STATUS
PD13.Signal=GPIO_Input
PD14.GPIO_Label=CELL_DTR
PD14.Signal=GPIO_Output
PD15.GPIO_Label=CELL_RI
PD15.Signal=GPIO_Input
PC6.GPIO_Label=ACCEL_INT
PC6.Signal=GPXTI6
PC7.GPIO_Label=TAMPER_IN
PC7.Signal=GPXTI7
PC8.GPIO_Label=SD_D0
PC8.Signal=SDMMC1_D0
PC9.GPIO_Label=SD_D1
PC9.Signal=SDMMC1_D1
PA8.GPIO_Label=MIC_WAKE
PA8.Signal=GPXTI8
PA9.GPIO_Label=USB_VBUS
PA9.Signal=USB_OTG_FS_VBUS
PA11.GPIO_Label=USB_DM
PA11.Signal=USB_OTG_FS_DM
PA12.GPIO_Label=USB_DP
PA12.Signal=USB_OTG_FS_DP
PC10.GPIO_Label=SD_D2
PC10.Signal=SDMMC1_D2
PC11.GPIO_Label=SD_D3
PC11.Signal=SDMMC1_D3
PC12.GPIO_Label=SD_CK
PC12.Signal=SDMMC1_CK
PD0.GPIO_Label=PWR_GOOD
PD0.Signal=GPIO_Input
PD1.GPIO_Label=PWR_FAULT
PD1.Signal=GPIO_Input
PD2.GPIO_Label=SD_CMD
PD2.Signal=SDMMC1_CMD
PD4.GPIO_Label=EN_MODEM
PD4.Signal=GPIO_Output
PD5.GPIO_Label=EN_AUX
PD5.Signal=GPIO_Output
PD6.GPIO_Label=PDM_DATA2
PD6.Signal=MDF1_SDI1
PB6.GPIO_Label=CELL_TX
PB6.Signal=USART1_TX
PB7.GPIO_Label=CELL_RX
PB7.Signal=USART1_RX
PH3-BOOT0.GPIO_Label=BOOT0
PH3-BOOT0.Signal=GPIO_Input
PB8.GPIO_Label=REV_STRAP0
PB8.Signal=GPIO_Input
PB9.GPIO_Label=REV_STRAP1
PB9.Signal=GPIO_Input
PE0.GPIO_Label=SIM_MUX_SEL
PE0.Signal=GPIO_Output

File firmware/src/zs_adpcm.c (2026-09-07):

#include "zs_adpcm.h"

#include <limits.h>
#include <string.h>

static const int8_t k_index_delta[16] = {
    -1, -1, -1, -1, 2, 4, 6, 8,
    -1, -1, -1, -1, 2, 4, 6, 8,
};

static const int16_t k_step_table[89] = {
    7, 8, 9, 10, 11, 12, 13, 14, 16, 17, 19, 21, 23, 25, 28, 31,
    34, 37, 41, 45, 50, 55, 60, 66, 73, 80, 88, 97, 107, 118, 130, 143,
    157, 173, 190, 209, 230, 253, 279, 307, 337, 371, 408, 449, 494, 544,
    598, 658, 724, 796, 876, 963, 1060, 1166, 1282, 1411, 1552, 1707,
    1878, 2066, 2272, 2499, 2749, 3024, 3327, 3660, 4026, 4428, 4871,
    5358, 5894, 6484, 7132, 7845, 8630, 9493, 10442, 11487, 12635, 13899,
    15289, 16818, 18500, 20350, 22385, 24623, 27086, 29794, 32767,
};

static int16_t clamp_i16(int32_t value) {
  if (value > INT16_MAX) return INT16_MAX;
  if (value < INT16_MIN) return INT16_MIN;
  return (int16_t)value;
}

static uint8_t encode_nibble(zs_ima_adpcm_encoder_t *encoder, int16_t sample) {
  int32_t predictor = encoder->predictor;
  int32_t diff = (int32_t)sample - predictor;
  uint8_t code = 0u;
  if (diff < 0) {
    code = 8u;
    diff = -diff;
  }

  const int32_t step = k_step_table[encoder->step_index];
  int32_t delta = step >> 3;
  if (diff >= step) {
    code |= 4u;
    diff -= step;
    delta += step;
  }
  if (diff >= (step >> 1)) {
    code |= 2u;
    diff -= step >> 1;
    delta += step >> 1;
  }
  if (diff >= (step >> 2)) {
    code |= 1u;
    delta += step >> 2;
  }

  predictor += (code & 8u) ? -delta : delta;
  encoder->predictor = clamp_i16(predictor);

  int32_t index = (int32_t)encoder->step_index + k_index_delta[code & 0x0fu];
  if (index < 0) index = 0;
  if (index > 88) index = 88;
  encoder->step_index = (uint8_t)index;
  return code;
}

void zs_ima_adpcm_encoder_reset(zs_ima_adpcm_encoder_t *encoder) {
  if (encoder) memset(encoder, 0, sizeof(*encoder));
}

bool zs_ima_adpcm_encoder_begin(zs_ima_adpcm_encoder_t *encoder,
                                int16_t first_sample,
                                uint8_t header[ZS_IMA_ADPCM_BLOCK_HEADER_BYTES]) {
  if (!encoder || !header) return false;
  zs_ima_adpcm_encoder_reset(encoder);
  encoder->predictor = first_sample;
  encoder->step_index = 0u;
  encoder->initialized = true;
  encoder->samples_encoded = 1u;
  const uint16_t raw = (uint16_t)first_sample;
  header[0] = (uint8_t)(raw & 0xffu);
  header[1] = (uint8_t)(raw >> 8);
  header[2] = encoder->step_index;
  header[3] = 0u;
  return true;
}

bool zs_ima_adpcm_encoder_push(zs_ima_adpcm_encoder_t *encoder,
                               int16_t sample,
                               uint8_t *out_byte,
                               bool *byte_ready) {
  if (!encoder || !encoder->initialized || !out_byte || !byte_ready) return false;
  const uint8_t nibble = encode_nibble(encoder, sample);
  encoder->samples_encoded++;
  if (!encoder->low_nibble_pending) {
    encoder->pending_byte = nibble;
    encoder->low_nibble_pending = true;
    *byte_ready = false;
  } else {
    *out_byte = (uint8_t)(encoder->pending_byte | (uint8_t)(nibble << 4));
    encoder->pending_byte = 0u;
    encoder->low_nibble_pending = false;
    *byte_ready = true;
  }
  return true;
}

bool zs_ima_adpcm_encoder_finish(zs_ima_adpcm_encoder_t *encoder,
                                 uint8_t *out_byte,
                                 bool *byte_ready) {
  if (!encoder || !encoder->initialized || !out_byte || !byte_ready) return false;
  if (encoder->low_nibble_pending) {
    *out_byte = encoder->pending_byte;
    *byte_ready = true;
    encoder->pending_byte = 0u;
    encoder->low_nibble_pending = false;
  } else {
    *byte_ready = false;
  }
  encoder->initialized = false;
  return true;
}

size_t zs_ima_adpcm_block_bytes_for_samples(uint32_t sample_count) {
  if (sample_count == 0u) return 0u;
  const uint64_t nibble_count = (uint64_t)sample_count - 1u;
  const uint64_t payload = (nibble_count + 1u) / 2u;
  const uint64_t total = ZS_IMA_ADPCM_BLOCK_HEADER_BYTES + payload;
  return total > SIZE_MAX ? 0u : (size_t)total;
}

bool zs_ima_adpcm_encode_block(const int16_t *samples,
                               uint32_t sample_count,
                               uint8_t *out,
                               size_t out_capacity,
                               size_t *out_bytes) {
  if (!samples || sample_count == 0u || !out || !out_bytes) return false;
  const size_t required = zs_ima_adpcm_block_bytes_for_samples(sample_count);
  if (required == 0u || out_capacity < required) return false;

  zs_ima_adpcm_encoder_t encoder;
  if (!zs_ima_adpcm_encoder_begin(&encoder, samples[0], out)) return false;
  size_t pos = ZS_IMA_ADPCM_BLOCK_HEADER_BYTES;
  for (uint32_t i = 1u; i < sample_count; ++i) {
    uint8_t b = 0u;
    bool ready = false;
    if (!zs_ima_adpcm_encoder_push(&encoder, samples[i], &b, &ready)) return false;
    if (ready) out[pos++] = b;
  }
  uint8_t tail = 0u;
  bool tail_ready = false;
  if (!zs_ima_adpcm_encoder_finish(&encoder, &tail, &tail_ready)) return false;
  if (tail_ready) out[pos++] = tail;
  if (pos != required) return false;
  *out_bytes = pos;
  return true;
}

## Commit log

2026-09-03 chore: publish v0.3 repository skeleton and hardware baseline
    [01_POWER.csv, 02_MCU.csv, 03_AUDIO.csv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]
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2026-09-03 archive: implement fixed-slot external storage event archive
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2026-09-07 Reconcile wire schema 3 with time-quality policy
    Use the approved compact spatial payload from protocol document v1.4, retain compatibility with optional in-memory time_status, and align full-server regression fixtures.
2026-09-07 Create isolated full EVT branch
    [EVT_MB_CONNECTOR_SCHEDULE_v1_2.csv, EVT_MB_HARNESS_SCHEDULE_v1_2.csv, EVT_MB_INTERCONNECT_v1_2.csv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]
2026-09-07 Release presentation v0.3 and EVT-MB v1.3 materials
    [EVT_MB_CONNECTOR_PINOUT_v1_3.csv, EVT_MB_CONNECTOR_SCHEDULE_v1_3.csv, EVT_MB_HARNESS_SCHEDULE_v1_3.csv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]
2026-09-08 Start EVT-PRE-20 configuration baseline
    [DELIVERABLE_REGISTER_EVT_PRE_20.csv]
2026-09-08 Define EVT-PRE-20 hardware and procurement baseline
    [CHINA_PROCUREMENT_RFQ.csv, DELIVERABLE_REGISTER_EVT_PRE_20.csv, EVT_PRE_20_BOM_DRAFT.csv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]
2026-09-08 Define EVT-PRE-20 software interfaces and release gates
    [DELIVERABLE_REGISTER_EVT_PRE_20.csv]
2026-09-08 Add Android commissioning baseline and fix full server tests
    [ACCEPTANCE_TESTS_v0_1.csv, DELIVERABLE_REGISTER_EVT_PRE_20.csv]
2026-09-08 Define pre-series enclosure architecture
    [ACOUSTIC_GEOMETRY.csv, OPEN_DIMENSIONS.csv, acoustic_geometry_reference.scad]
2026-09-08 Add 20-unit manufacturing and EVT control plan
    [ASSEMBLY_ROUTE.csv, DECISION_LOG.csv, DELIVERABLE_REGISTER_EVT_PRE_20.csv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]
2026-09-08 Add pre-series interconnect and PCB release controls
    [CONNECTOR_REGISTER_DRAFT.csv, DELIVERABLE_REGISTER_EVT_PRE_20.csv, EVT_PRE_20_INTERCONNECT_DRAFT.csv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]
2026-09-08 Record customer inputs required for release freeze
    [OPEN_INPUTS_FOR_FREEZE.csv]
2026-09-08 Lock RU868 pilot and add dual-SIM APN failover baseline
    [ACCEPTANCE_TESTS_v0_1.csv, ASSEMBLY_ROUTE.csv, CHINA_PROCUREMENT_RFQ.csv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]
2026-09-08 Lock public APN pilot and 20 housing allocation
    [ACCEPTANCE_TESTS_v0_1.csv, ASSEMBLY_ROUTE.csv, CHINA_PROCUREMENT_RFQ.csv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]
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2026-09-08 Supersede conflicting early pin-budget candidate with exact Rev.A map
    [EVT_PRE_20_PIN_BUDGET_CANDIDATE.csv]
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2026-09-08 Replace ESP32-C3 with nRF52840 BLE module in EVT-PRE-20 BOM
    [EVT_PRE_20_BOM_DRAFT.csv]
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2026-09-08 Lock configured installation coordinates for fixed station positioning
    [DECISION_LOG.csv]
2026-09-08 Replace ESP BLE pin contract with nRF52840 module contract
    [EVT_PRE_20_PIN_MAP_REV_A.csv]
2026-09-08 Add EVT matrix for configured position and GNSS spoof drift behavior
    [EVT_POSITION_TIME_TRUST_MATRIX.csv]
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2026-09-08 Freeze Rev.A power component candidates for schematic capture
    [POWER_COMPONENT_FREEZE_REV_A.csv]
2026-09-08 Freeze Rev.A connector families and exact provisional MPNs
    [CONNECTOR_FREEZE_REV_A.csv]
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2026-09-08 Preserve T5838 AAD WAKE with 5-pin microphone harness
    [CONNECTOR_FREEZE_REV_A.csv]
2026-09-08 Add T5838 AAD WAKE to all microphone harnesses
    [HARNESS_LOGICAL_PINOUT_REV_A.csv]
2026-09-08 Add T5838 AAD wake aggregation and correct exact MCU temperature limit
    [MAIN_COMPONENT_FREEZE_REV_A.csv]
2026-09-08 Synchronize interconnect with 5-wire T5838 AAD wake architecture
    [EVT_PRE_20_INTERCONNECT_DRAFT.csv]
2026-09-08 Reserve PA8 pin 67 for aggregated T5838 AAD wake
    [EVT_PRE_20_PIN_MAP_REV_A.csv]
2026-09-08 Keep legacy PDM validator while adding explicit AAD WAKE subinterfaces
    [HARNESS_LOGICAL_PINOUT_REV_A.csv]
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2026-09-08 Resolve EVT-PRE-20 operating temperature input
    [OPEN_INPUTS_FOR_FREEZE.csv]
2026-09-08 Replace MIC JST GH with -40C Molex Pico-Lock
    [CONNECTOR_FREEZE_REV_A.csv]
2026-09-08 Resolve Rev.A component environment blockers for -40..+70 C
    [MAIN_COMPONENT_FREEZE_REV_A.csv]
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2026-09-08 Expose T5838 THSEL AAD configuration on 6-pin MIC harness
    [HARNESS_LOGICAL_PINOUT_REV_A.csv]
2026-09-08 Assign STM32 PA15 to T5838 THSEL AAD configuration
    [AAD_CFG_PIN_ADDENDUM_REV_A.csv]
2026-09-08 Expand MIC connector to 6 pins for T5838 THSEL AAD configuration
    [CONNECTOR_FREEZE_REV_A.csv]
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2026-09-08 Lock T5838 WAKE and THSEL AAD interface for Rev.A
    [DECISION_LOG.csv]
2026-09-08 Bind U7 translator to PDM clock plus T5838 THSEL AAD_CFG
    [MAIN_COMPONENT_FREEZE_REV_A.csv]
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2026-09-08 Add dedicated T5838 AAD configuration and wake EVT
    [EVT_MATRIX.csv]
2026-09-08 Fix MIC reference CAD import path and probe KiCad 7 verification commands
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2026-09-08 Add PCB-MIC Rev.A legacy schematic seed for KiCad native upgrade
    [PCB-MIC.sch]
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2026-09-08 Align PCB-MIC schematic with data SI tuning footprint
    [PCB-MIC.sch]
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2026-09-08 Fix PCB-MIC generator for KiCad 9 pcbnew text API
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2026-09-09 Collect KiCad ERC and DRC evidence before failing native gate
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2026-09-09 Fix T5838 custom ring generation for KiCad 9 API
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2026-09-09 Bypass crashing Python zone filler in PCB-MIC materialization
2026-09-09 Skip crashing Python zone fill during PCB-MIC generation
2026-09-09 Fix PCB-MIC schematic pin transform and grid alignment
2026-09-09 Fix PCB-MIC GND routing and add explicit return backbone
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2026-09-09 Resolve PCB-MIC symbols and footprints through project-local libraries
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2026-09-09 Replace stale PCB-PWR pre-schematic sheet with Rev.A power baseline
    [01_POWER.csv]
2026-09-09 Add independent PCB-PWR pre-schematic drift audit
2026-09-09 Require PCB-PWR pre-schematic drift audit before native capture
2026-09-09 Align Rev.A interconnect with DEC-020 and frozen Micro-Fit wiring
    [EVT_PRE_20_INTERCONNECT_DRAFT.csv]
2026-09-09 Align PWR harness wire gauges with frozen Micro-Fit terminals
    [HARNESS_LOGICAL_PINOUT_REV_A.csv]
2026-09-09 Freeze Rev.A 12-pin PWR interface with INA226 I2C
    [CONNECTOR_FREEZE_REV_A.csv, CONNECTOR_REGISTER_DRAFT.csv, EVT_PRE_20_INTERCONNECT_DRAFT.csv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]
2026-09-09 Align Rev.A BOM and capture baseline with 12-pin INA226 interface
    [EVT_PRE_20_BOM_DRAFT.csv]
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2026-09-09 Fix PCB-MIC KiCad 9 SWIG mechanical finalizer
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2026-09-09 Replace stale PCB-PWR 10-pin capture sheet with 12-pin INA226 contract
    [01_POWER.csv]
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2026-09-09 Add PCB-PWR Rev.A pin authority for native capture
    [PCB_PWR_PIN_AUTHORITY_REV_A.csv]
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2026-09-09 Review A: fix PCB-PWR startup enable authority
    [PCB_PWR_PIN_AUTHORITY_REV_A.csv]
2026-09-09 Review A: lock startup-safe nets and explicit ground net-ties
    [PCB_PWR_CAPTURE_NETS_REV_A.csv]
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2026-09-09 Strengthen PCB-PWR ERC with real pin electrical types
2026-09-09 Model PCB-PWR external power correctly for ERC
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2026-09-09 Fix PCB-PWR ERC power-source modeling
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2026-09-09 Fix PCB-PWR KiCad symbol integrity and ERC
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2026-09-09 Fix BOM spare policy for DNP and PCB features
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2026-09-09 Correct BOM orderables, packages, and ratings
    [08_STORAGE_SENSORS.csv, CONNECTOR_FREEZE_REV_A.csv, EVT_PRE_20_BOM_DRAFT.csv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]
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2026-09-10 hardware: close PCB-MAIN connector fixture authority
    [05_CELLULAR.csv, 08_STORAGE_SENSORS.csv, 09_CONNECTORS_TEST.csv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]
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2026-09-30 Promote verified EVT-PRE-20 Rev D production release
    Copy the audited release subtree exactly from feature/pcb-main-completion at 7bf91108d3c23ae94de85defe34e988642baebf6. Preserve main history; broader engineering integration remains separate.
    [ASSEMBLY_ROUTE.csv, BOM_EVT_PRE_20_оценочные_цены.xlsx, BOM_закупка_EVT_PRE_20_первый_лот_3D.csv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]
2026-09-30 Promote EVT-PRE-20 Rev D1 test program to release branches
    [EVT_MATRIX.csv, EVT_матрица_и_отчеты.xlsx, REQUIREMENTS_TRACEABILITY.csv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]
2026-10-01 Rev D2: approved appearance acoustic head and assembly package
    [ASSEMBLY_ROUTE.csv, BOM_EVT_PRE_20_оценочные_цены.xlsx, BOM_закупка_EVT_PRE_20_первый_лот_3D.csv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]
2026-10-01 Supersede Rev D handoff with controlled Rev D2 release
    [ASSEMBLY_ROUTE.csv, BOM_EVT_PRE_20_оценочные_цены.xlsx, BOM_закупка_EVT_PRE_20_первый_лот_3D.csv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]
2026-10-01 Correct acoustic CAD report hashes in Rev D2
    [МАНИФЕСТ_SHA256.csv]
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2026-10-02 Add finished acoustic foam appearance view to D4 packet
    [МАНИФЕСТ_SHA256.csv]
2026-10-02 Release EVT-PRE-20 D5 faceted PCB-MAIN case and approved logo
    [ASSEMBLY_ROUTE.csv, BOM_EVT_PRE_20_оценочные_цены.xlsx, BOM_закупка_EVT_PRE_20_первый_лот_3D.csv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]
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
